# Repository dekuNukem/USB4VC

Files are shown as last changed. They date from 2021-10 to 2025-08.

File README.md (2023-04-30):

# USB4VC: USB Inputs on Retro Computers!

[Get USB4VC!](https://www.tindie.com/products/dekuNukem/usb4vc-usb-inputs-on-retro-computers/) | [Official Discord](https://discord.gg/HAuuh3pAmB) | [Getting Started](getting_started.md) | [Table of Contents](#table-of-contents)

-----

USB4VC is an **active protocol converter** that let you use **USB keyboard, mouse, and gamepads** on many different retro computers.



With a **modular design**, different platforms are supported by swapping out **Protocol Cards**:



USB4VC is [now available on Tindie](https://www.tindie.com/products/dekuNukem/usb4vc-usb-inputs-on-retro-computers/), with two Protocol Cards:

#### IBM PC Compatible

* PS/2 Keyboard (Scancode set 1, 2 and 3)
* PS/2 Mouse
* AT Keyboard
* XT Keyboard
* Microsoft Serial Mouse
* Mouse Systems Serial Mouse
* 15-pin Gameport Gamepad
* Mapping USB Gamepad to PC Mouse/Keyboard

From the very first IBM PC in 1981 until the end of PS/2 ports in early 2000s, this Protocol Card covers it all!

#### Apple Lisa, Early Macintosh, and Apple Desktop Bus (ADB)

* Apple Lisa Keyboard (A6MB101)
* Apple Lisa Mouse (A9M0050)
* Macintosh Keyboard (M0110A)
* Macintosh Mouse (M0100)
* ADB Keyboard
* ADB Mouse
* Mapping USB gamepad to all above

From Apple Lisa in 1983 to PowerMac G3 in 1999, and everything in-between!

#### More to Come!

Of course, more Protocol Cards are planned, and you can try [make your own](technical_notes.md) too!

## I Want One! / Get in Touch

USB4VC is now available [on my Tindie store](https://www.tindie.com/products/dekuNukem/usb4vc-usb-inputs-on-retro-computers/) after being successfully funded [on Kickstarter!](https://www.kickstarter.com/projects/dekunukem/usb4vc-usb-inputs-on-retro-computers)!

**Questions or comments?** Ask in [official Discord](https://discord.gg/HAuuh3pAmB), raise a [Github issue](https://github.com/dekuNukem/USB4VC/issues), [Twitter DM](https://twitter.com/dekuNukem_), or email `dekunukem` `gmail.com`!

## Videos

* [LGR Review](https://www.youtube.com/watch?v=tbHr7ULpusM)

* [Michael MJD Review](https://www.youtube.com/watch?v=Hv4A9p7Cn2s)

* [1Bit Fever Dreams review of Lisa/Mac/ADB card](https://youtu.be/ALm5LWS0fqU)

## Highlights

* USB Keyboard/Mouse/Gamepads on Vintage Computers!

* Modular & Swappable Protocol Cards

* Wireless / Bluetooth

* Ultra Low Latency (0.5ms)

* Fully Open-source

* Make-your-own Protocol Card [Instruction Provided](technical_notes.md)

## How it Works

USB4VC consists of two halves: **Baseboard** and swappable **Protocol Cards**.

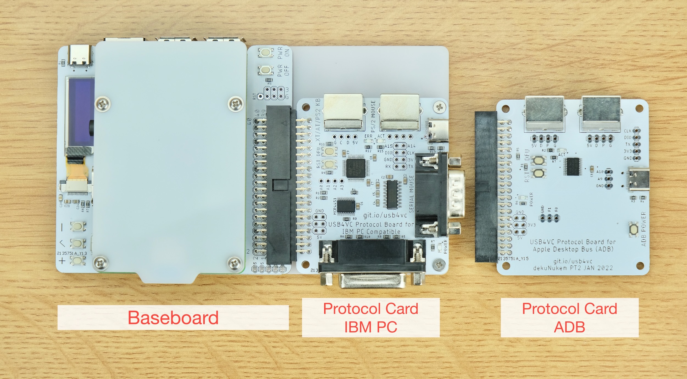
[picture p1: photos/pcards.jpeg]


Baseboard contains user buttons, OLED screen, and a Raspberry Pi. It processes USB input events, which are sent to Protocol Card.

Each Protocol Card has a dedicated microcontroller and connectors for a specific platform.

By splitting duties, RPi can focus on input parsing, and Protocol Card handles timing critical signal generation, resulting in a flexible architecture and reliable performance.

USB peripherals can be connected via cables, wireless dongles, or Bluetooth.

## Getting Started

[Click me](getting_started.md)

## Technical Details / Make Your Own Protocol Cards

[Click me](technical_notes.md)

## Why / Project Goals

Before the homogeneity of USB peripherals today, computer input devices were a wild west of proprietary peripherals, as different platforms used their own connectors and protocols for keyboards, mice, and gamepads.

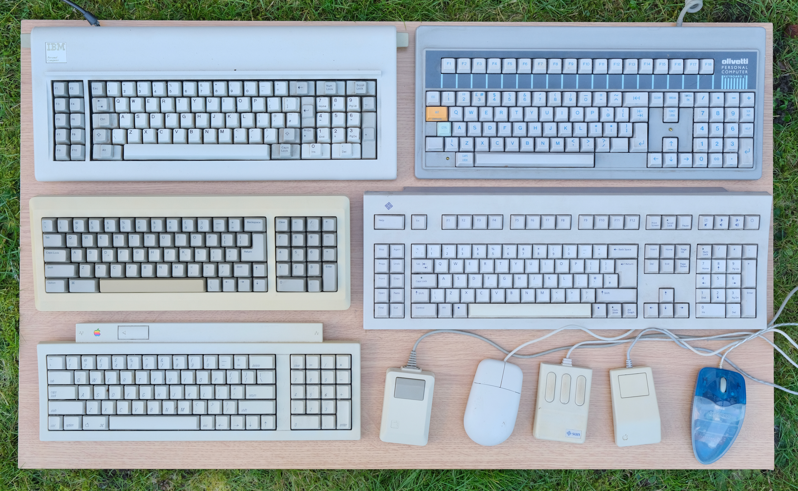
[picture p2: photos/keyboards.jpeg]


With the popularity of retro computing today, it poses several issues:

* Many of those peripherals are simply **hard to find**, commanding a premium on online marketplaces. They are only getting rarer, and without them, the computer itself is useless.

* After decades of service, many can be **degraded and unreliable** (e.g. foam & foil keyboards), requiring extensive restoration.

* Many early peripherals simply **does not feel that great**. Mushy membrane keyboards, sticky ball mice, plasticky gamepads, etc. And of course, the good ones gets [*very expensive*](https://www.ebay.com/sch/i.html?_nkw=ibm+model+f&_sacat=0&rt=nc&LH_Sold=1&LH_Complete=1).

* On the other hand, good quality USB peripherals can be had for a very reasonable price today with vastly **superior tactility, precision, and ergonomics**.

* Thus, this project aims to make retro computers simply **more enjoyable to use**.

* I also hope it can **lower the barrier of entry** for certain machines, put more computers **back in action**, help **preserving** existing peripherals, and generally **help more people** get into this hobby!

But of course, one can argue that using period-correct peripherals is simply part of the hobby, but just like HDMI upscalers or floppy emus, it's nice to have the option to enhance the experience.

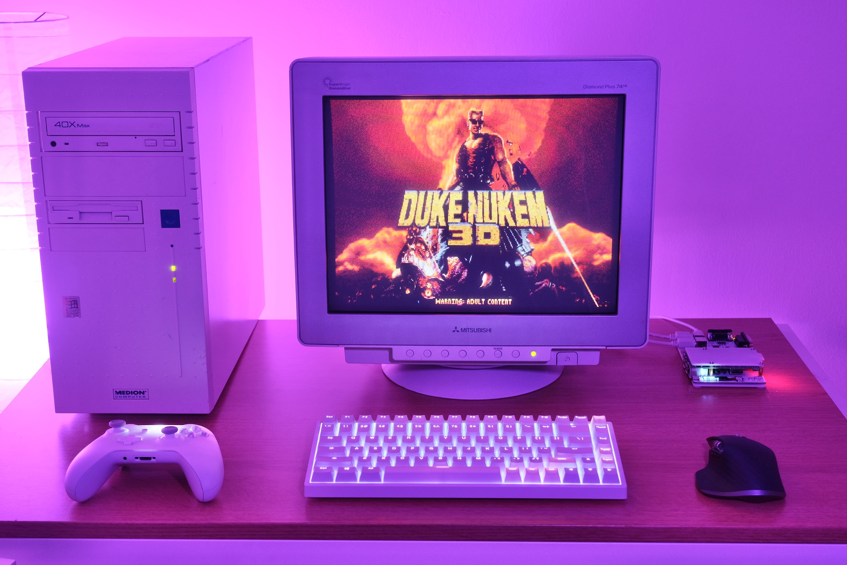
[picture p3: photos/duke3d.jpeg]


## Q&A

### Where can I get one?

This project have been successly funded [via Kickstarter!](https://www.kickstarter.com/projects/dekunukem/usb4vc-usb-inputs-on-retro-computers), now it is available [on my Tindie store!](https://www.tindie.com/products/dekuNukem/usb4vc-usb-inputs-on-retro-computers/)

### Which Raspberry Pi can I use?

Any RPi with a **40-pin header** *should* work, although **Model B/B+** is preferred. See [this table](https://en.wikipedia.org/wiki/Raspberry_Pi#Model_comparison) for details, sort by **GPIO** column.

USB4VC has been officially tested on **Raspberry Pi 2/3/4 Model B**.

Raspberry Pi Zeros should work too, but would need a USB hub.

No need to get the latest and greatest. An older RPi is plenty fast enough!

### What about latency?

0.5ms to 1ms depending on the Raspberry Pi generation.

1ms is *one thousandth* of a second. [More info here](technical_notes.md#latency-information).

### Can you develop a Protocol Card for ___ ?

I'd love to! But I would need a working machine with working peripherals.

So if you're in UK and is happy to lend me one for a while, [let me know!](#i-want-one--get-in-touch)

Also, as I can only work on so many at once, I'll probably focus on the more popular machines at first, but still, do let me know!

### Can I make my own Protocol Cards?

Of course! See [this document](technical_notes.md).

### What does USB4VC stand for?

USB for Vintage Computers. Although come to think of it, it's perfect for vintage consoles too! 🤔

## Questions or Comments?

Feel free to ask in official [Discord Chatroom](https://discord.gg/HAuuh3pAmB), raise a [Github issue](https://github.com/dekuNukem/USB4VC/issues), [DM on Twitter](https://twitter.com/dekuNukem_), or email `dekunukem` `gmail.com`!

## Table of Contents

[Main page](README.md)

[(Youtube Video) USB4VC in Action](https://www.youtube.com/watch?v=54sdPELuu4g)

[Getting Started Guide](getting_started.md)

[Kit Assembly Guide](kit_assembly.md)

[Tinkering Guide / Make Your Own Protocol Card / Technical Notes](technical_notes.md)

[Kickstarter Acknowledgements](kickstarter_info.md)

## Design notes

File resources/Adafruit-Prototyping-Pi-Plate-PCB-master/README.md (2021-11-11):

# Adafruit Prototyping Pi Plate

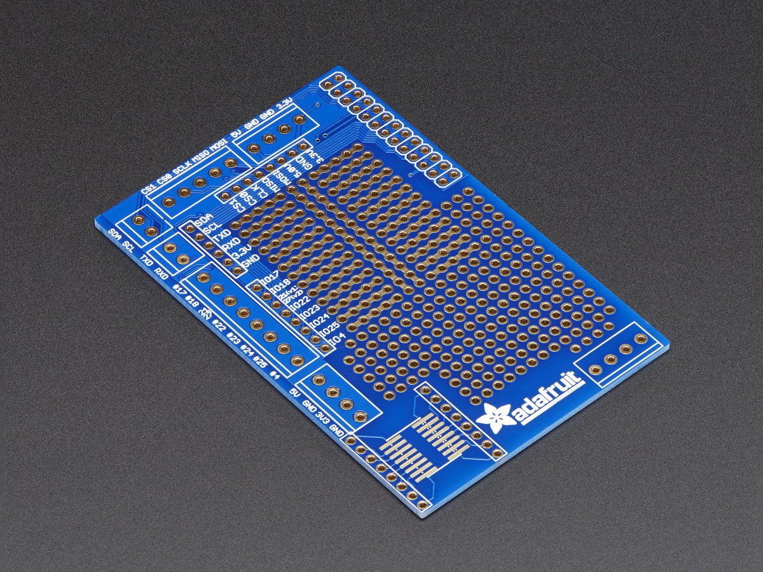
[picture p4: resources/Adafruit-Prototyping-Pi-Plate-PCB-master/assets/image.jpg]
<a href="http://www.adafruit.com/products/801"><br/>Click here to purchase one from the Adafruit shop</a>

These are the Eagle CAD files for the Adafruit Prototyping Pi Plate.

Now that you've finally got your hands on a [Raspberry Pi®](http://www.raspberrypi.org/) , you're probably itching to make some fun embedded computer projects with it. What you need is an add on prototyping Pi Plate from Adafruit, which can snap onto the Pi PCB (and is removable later if you wish) and gives you all sorts of prototyping goodness to make building on top of the Pi super easy.

__Note: This kit is best used for the Raspberry Pi Model A or Model B.__ You can use it with any "2x20 GPIO type" Pi  (A+, B+, Zero, Pi 2, Pi 3) but only the 'top 26 pins' will be broken out for use

We added lots of basic but essential goodies. First up, there's a big prototyping area, half of which is 'breadboard' style and half of which is 'perfboard' style so you can wire up DIP chips, sensors, and the like. Along the edges of the proto area, all the GPIO/I2C/SPI and power pins are broken out to 0.1" stips so you can easily connect to them. On the edges of the prototyping area, (almost all of) the breakout pins are also connected to labeled 3.5mm screw-terminal blocks. This makes it easy to semi-permanently wire in sensors, LEDs, etc. There's also a 4-block terminal block broken out to 0.1" pads for general non-GPIO wiring. Finally, we had a little space remaining over the metal connectors so we put in an SOIC surface mount chip breakout area, for those chips that dont come in DIP format.

__This kit comes as a set of parts, a little soldering is required to put it together but its really easy, even a beginner can do it in 15-20 minutes or so.__ The Pi (and our kits) are meant to help us all learn skills, soldering is fun! [Check out our tutorial for how to assemble](http://learn.adafruit.com/adafruit-prototyping-pi-plate).

The nice thing about this plate is we're getting custom header breakouts that are taller than usual, so that the proto plate sits above the metal connectors, out of the way and allows for plenty of workspace. It fits in our Pi Box enclosure with access to the terminal blocks so you can keep the Pi safe while prototyping. We'll have stackable header kits as well for those who want to put multiple plates on top.

For more information, including some usage ideas [check out our Proto Pi Plate tutorial](http://learn.adafruit.com/adafruit-prototyping-pi-plate).

Note: The terminal blocks included with your product may be blue or black.

### License

Adafruit invests time and resources providing this open source design, please support Adafruit and open-source hardware by purchasing products from Adafruit!

Designed by Limor Fried/Ladyada for Adafruit Industries.
CERN OPEN HARDWARE LICENSE v1.1 
http://www.ohwr.org/

All text above must be included in any redistribution

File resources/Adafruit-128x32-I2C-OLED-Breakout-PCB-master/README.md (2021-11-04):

# PCB for the Adafruit 128x32 I2C OLED breakout board

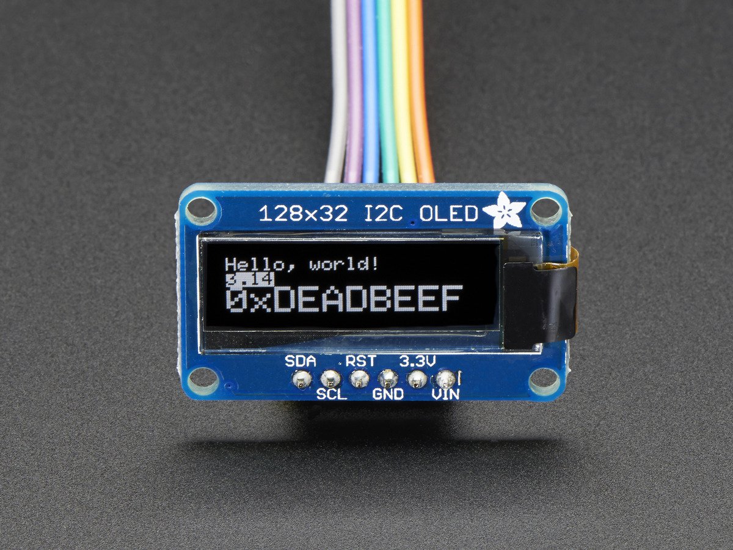
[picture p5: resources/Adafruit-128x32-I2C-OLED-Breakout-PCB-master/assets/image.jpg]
<a href="http://www.adafruit.com/products/931"><br/>Click here to purchase one from the Adafruit shop</a>

__Format is EagleCAD schematic and board layout__

These displays are small, only about 1" diagonal, but very readable due to the high contrast of an OLED display. This display is made of 128x32 individual white OLED pixels, each one is turned on or off by the controller chip. Because the display makes its own light, no backlight is required. This reduces the power required to run the OLED and is why the display has such high contrast; we really like this miniature display for its crispness!

The driver chip SSD1306, __communicates via I2C only.__ 3 pins are required to communicate with the chip in the OLED display, two of which are I2C data/clock pins.

The OLED and driver require a 3.3V power supply and 3.3V logic levels for communication. To make it easier for our customers to use, we've added a 3.3v regulator and level shifter on board! This makes it compatible with any 5V microcontroller, such as the Arduino.

The power requirements depend a little on how much of the display is lit but on average the display uses about 20mA from the 3.3V supply. Built into the OLED driver is a simple switch-cap charge pump that turns 3.3v-5v into a high voltage drive for the OLEDs, making it one of the easiest ways to get an OLED into your project!

Of course, we wouldn't leave you with a datasheet and a "good luck": [We have a detailed tutorial](http://learn.adafruit.com/monochrome-oled-breakouts) and [example code in the form of an Arduino library](https://github.com/adafruit/Adafruit_SSD1306) for text and graphics. You'll need a microcontroller with more than 512 bytes of RAM since the display must be buffered.

You can download our SSD1306 OLED display Arduino library from github which comes with example code. The library can print text, bitmaps, pixels, rectangles, circles and lines. It uses 512 bytes of RAM since it needs to buffer the entire display but its very fast! The code is simple to adapt to any other microcontroller.

## License
Adafruit invests time and resources providing this open source design,
please support Adafruit and open-source hardware by purchasing
products from Adafruit!

Designed by Limor Fried/Ladyada for Adafruit Industries.
Creative Commons Attribution, Share-Alike license, check license.txt for more information
All text above must be included in any redistribution

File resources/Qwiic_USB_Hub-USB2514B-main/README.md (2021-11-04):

SparkFun Qwiic USB Hub - USB2514B
========================================

SparkX USB Hub - USB2514B (Qwiic) (https://www.sparkfun.com/products/18014)

[*SparkX USB Hub - USB2514B (Qwiic) (SPX-18014)*](https://www.sparkfun.com/products/18014)

There are times when you have multiple USB devices in your prototype or device and you just want to plug in one cable. You need a built in USB hub! 

The [Qwiic USB Hub](https://www.sparkfun.com/products/18014) is a simple breakout board for the USB2514B USB hub IC. What gives it extra flair is the ability to configure the device over I2C. Out of the box, the board will appear as a standard USB 2.0 Hub; no configuration necessary. Closing the I2C jumper will put the device into configuration mode. We've got an Arduino Library to help you set the various parameters of the hub including VID/PID, downstream max current, even language ID and product names. 

Note: Once the configuration bytes are set and the USB2514B is told to 'attach' it will enumerate as a HUB and the configuration cannot be changed until the IC is reset. 

The USB2514 is a 4-port 2.0 USB hub. Who cares about USB 2.0 these days? The vast majority of projects we work on have a simple USB-to-Serial IC on it that do not require gigabit datarates. The USB251xB is a simple hub IC allowing multiple USB things to live under one USB connection; this is especially useful when prototyping a new product where you want the user to plug in just one cable.

SparkFun labored with love to create this code. Feel like supporting open source hardware? 
Buy a [board](https://www.sparkfun.com/products/18014) from SparkFun!

Repository Contents
-------------------

* **/hardware** - Eagle files
* **/documents** - Datasheets and other source documents

Documentation
--------------

* **[Arduino Library](https://github.com/sparkfun/SparkFun_USB251x_Arduino_Library)** - Main repository (including hardware files)
* **[Installing an Arduino Library Guide](https://learn.sparkfun.com/tutorials/installing-an-arduino-library)** - Basic information on how to install an Arduino library.

Products that use this Repository
--------------

* [SPX-18014](https://www.sparkfun.com/products/18014)

License Information
-------------------

This product is _**open source**_! 

Please review the LICENSE.md file for license information. 

If you have any questions or concerns on licensing, please contact technical support on our [SparkFun forums](https://forum.sparkfun.com/viewforum.php?f=152).

Distributed as-is; no warranty is given.

- Your friends at SparkFun.

_<COLLABORATION CREDIT>_

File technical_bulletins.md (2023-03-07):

# USB4VC Protocol Card Stability Upgrade

[Get USB4VC](https://www.tindie.com/products/dekuNukem/usb4vc-usb-inputs-on-retro-computers/) | [Official Discord](https://discord.gg/HAuuh3pAmB) | [Getting Started](getting_started.md) | [Table of Contents](#table-of-contents)

-----

This document covers a solution that might improve the stability of USB4VC.

## Overview

A `BUSY` signal is added, to prevent Raspberry Pi from sending data when Protocol Card is talking to the computer.

This, along with a firmware update, should improve stability and reduce stuck keys or glitches.

## Instructions

### Solder a New Wire

Solder a wire between the pins at **`F1` and `second row of right most column`**. See photo:

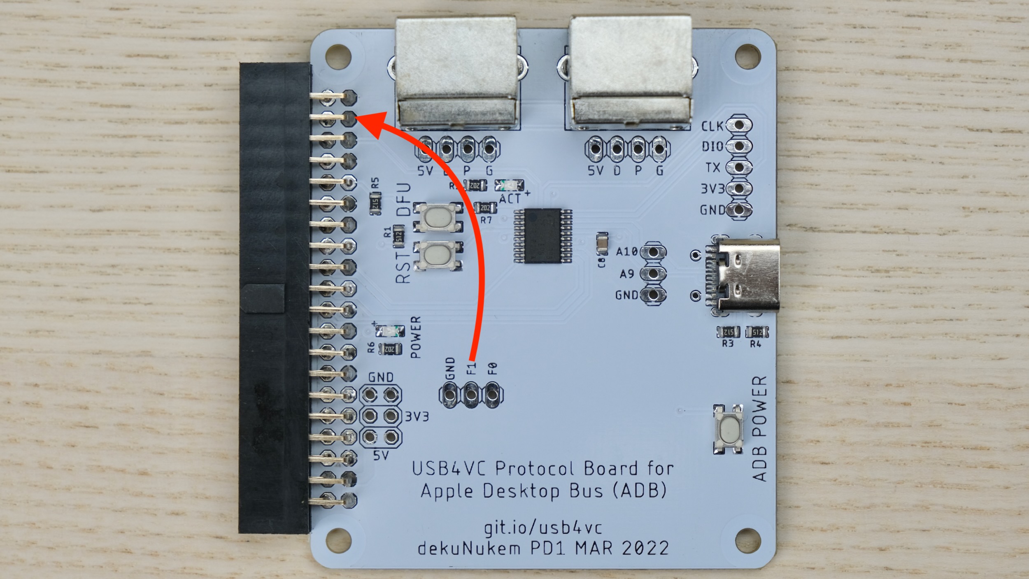
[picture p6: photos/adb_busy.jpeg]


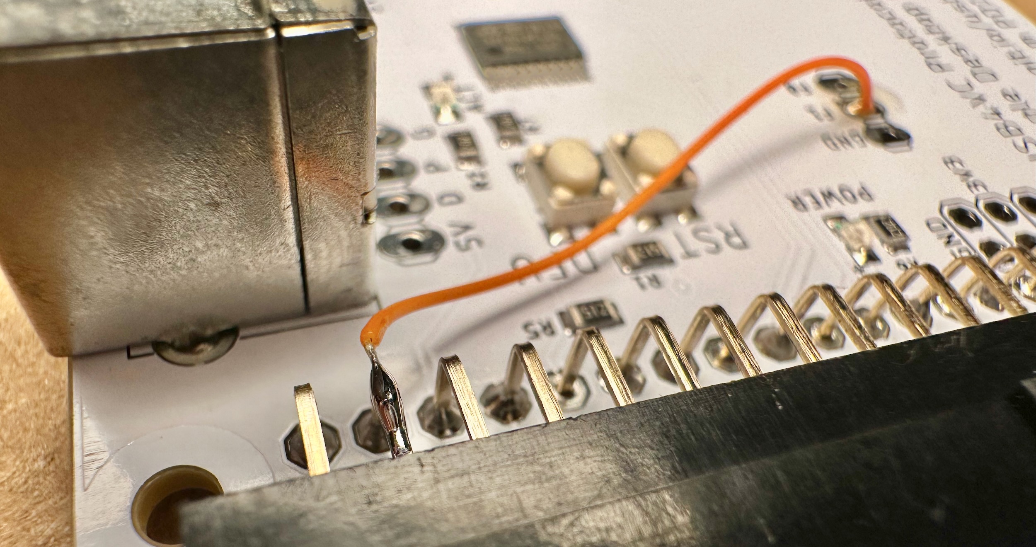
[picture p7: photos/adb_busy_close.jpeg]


Make sure **there are no short circuits**.

### Software Update

Connect RPi to internet. You can [set up WiFi](https://github.com/dekuNukem/USB4VC/blob/master/getting_started.md#optional-set-up-wifi), or plug in an Ethernet cable.

Then simply select Internet Update in main menu. It will update RPi code and P-Card firmware to latest version.

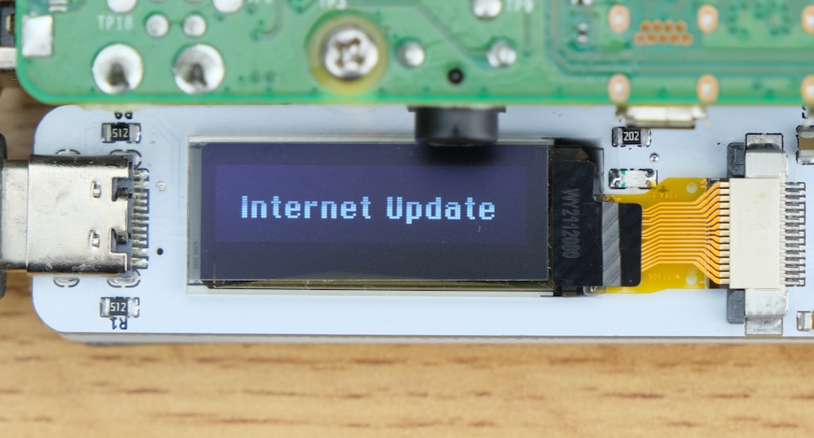
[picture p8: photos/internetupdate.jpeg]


Confirm on the second screen that both PB and RPi version are **above 0.3.0**.

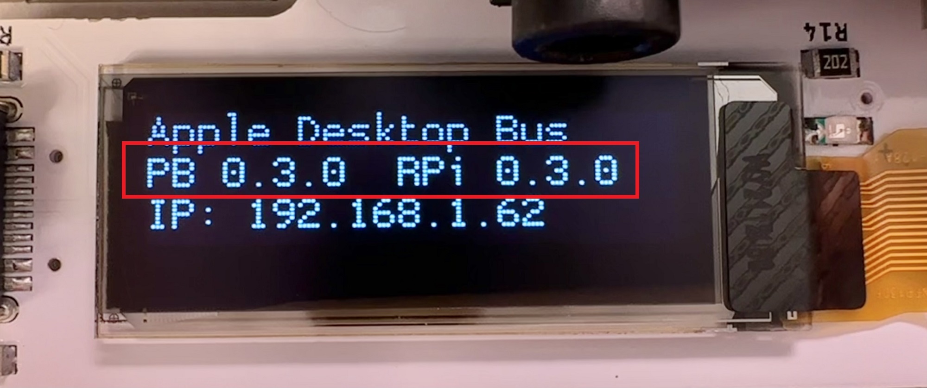
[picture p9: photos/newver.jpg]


### Try it Out!

Let me know how it goes!

## Questions or Comments?

Feel free to ask in official [Discord Chatroom](https://discord.gg/HAuuh3pAmB), raise a [Github issue](https://github.com/dekuNukem/USB4VC/issues), [DM on Twitter](https://twitter.com/dekuNukem_), or email `dekunukem` `gmail.com`!

## Table of Contents

[Main page](README.md)

[(Youtube Video) USB4VC in Action](https://www.youtube.com/watch?v=54sdPELuu4g)

[Getting Started Guide](getting_started.md)

[Kit Assembly Guide](kit_assembly.md)

[Tinkering Guide / Make Your Own Protocol Card / Technical Notes](technical_notes.md)

[Kickstarter Acknowledgements](kickstarter_info.md)

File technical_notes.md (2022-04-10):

# USB4VC Technical Notes / Make Your Own Protocol Card / Tinkering Guide

[Get USB4VC](https://www.tindie.com/products/dekuNukem/usb4vc-usb-inputs-on-retro-computers/) | [Official Discord](https://discord.gg/HAuuh3pAmB) | [Getting Started](getting_started.md) | [Table of Contents](#table-of-contents)

-----

This document contains technical information about how USB4VC works. Please **read the whole article** if you're planning to make your own Protocol Cards.

## Tinkering Guide

Working on USB4VC is very straightforward. It's just some python scripts running on official RaspberryPi OS Lite.

To SSH into it, [set up WiFi](getting_started.md#optional-set-up-wifi) or plug in an Ethernet cable. The IP address should show up on the second page of main menu:

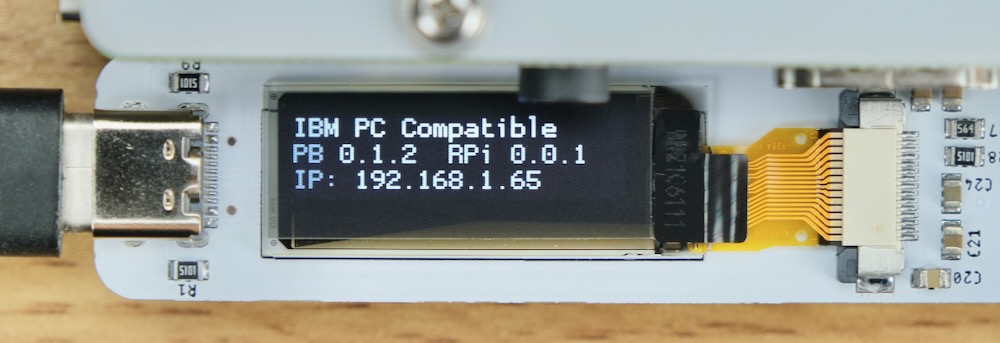
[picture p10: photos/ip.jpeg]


Simply do (change the IP to your own) `ssh pi@192.168.1.65`.

Username and password is `pi` and `usb4vc`, all lower case. 

All files are inside `~/usb4vc`.

## Linux Input Event Codes

Now, how does USB4VC read from USB inputs in the first place?

The answer is Linux **Input Event Codes**. Here's a very simplified description:

* Input devices show up in `/dev/input` as files:

```
$ ls /dev/input/
event0  event1  event2  mice  mouse0  mouse1
```

* Reading from one of those files returns input events. Try `cat /dev/input/mice`!

* On RPi, **16 Bytes** are returned each time there is an event. They are arranged as follows:

| Byte  | Name |
|---|---|
| 0-7 | Timestamp |
| 8-9 | Event Type  |
| 10-11 | Event Code  |
| 12-15 | Event Value |

* A list of all Event Type, Code and Values [can be found here](https://github.com/torvalds/linux/blob/master/include/uapi/linux/input-event-codes.h), set a bookmark if you're making your own P-Card!

* Keyboard keys and mouse/gamepad buttons are **EV_KEY** type, mouse movements are **EV_REL** (relative) type, and joystick movements are **EV_ABS** (absolute) type.

* Once you know the Event Type, you can look up Event Code to see which key/button/axes is being updated.

* Event Value will be 1 (pressed) or 0 (released) for buttons, and a signed value for relative or absolute axes.

* [Here's a good article](https://thehackerdiary.wordpress.com/2017/04/21/exploring-devinput-1/) that goes into a bit more details.

* USB4VC reads those events from all input devices, processes them, and send them out to the Protocol Card.

* To see it in action, you can select `Show Event Codes` from the main menu:

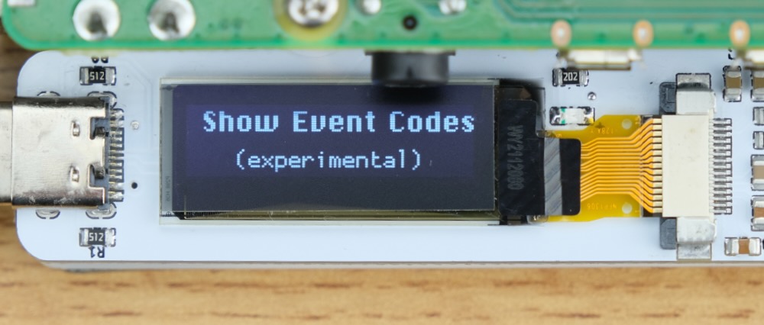
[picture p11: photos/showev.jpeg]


* It will show a summary of latest input events, including device name, USB vendor and product ID, and event code name and value.

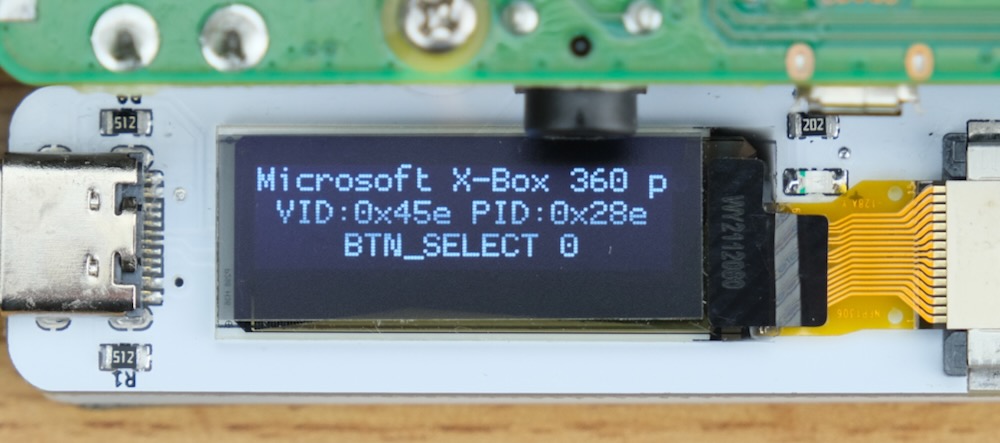
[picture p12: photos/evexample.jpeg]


* To exit, **HOLD DOWN** `+` button during an input event.

* You can also `ssh` into it and use `evtest` to see more detailed reports.

## Hardware Pinout

The Protocol Card connector directly maps to the Raspberry Pi Header, although the pins are flipped around.

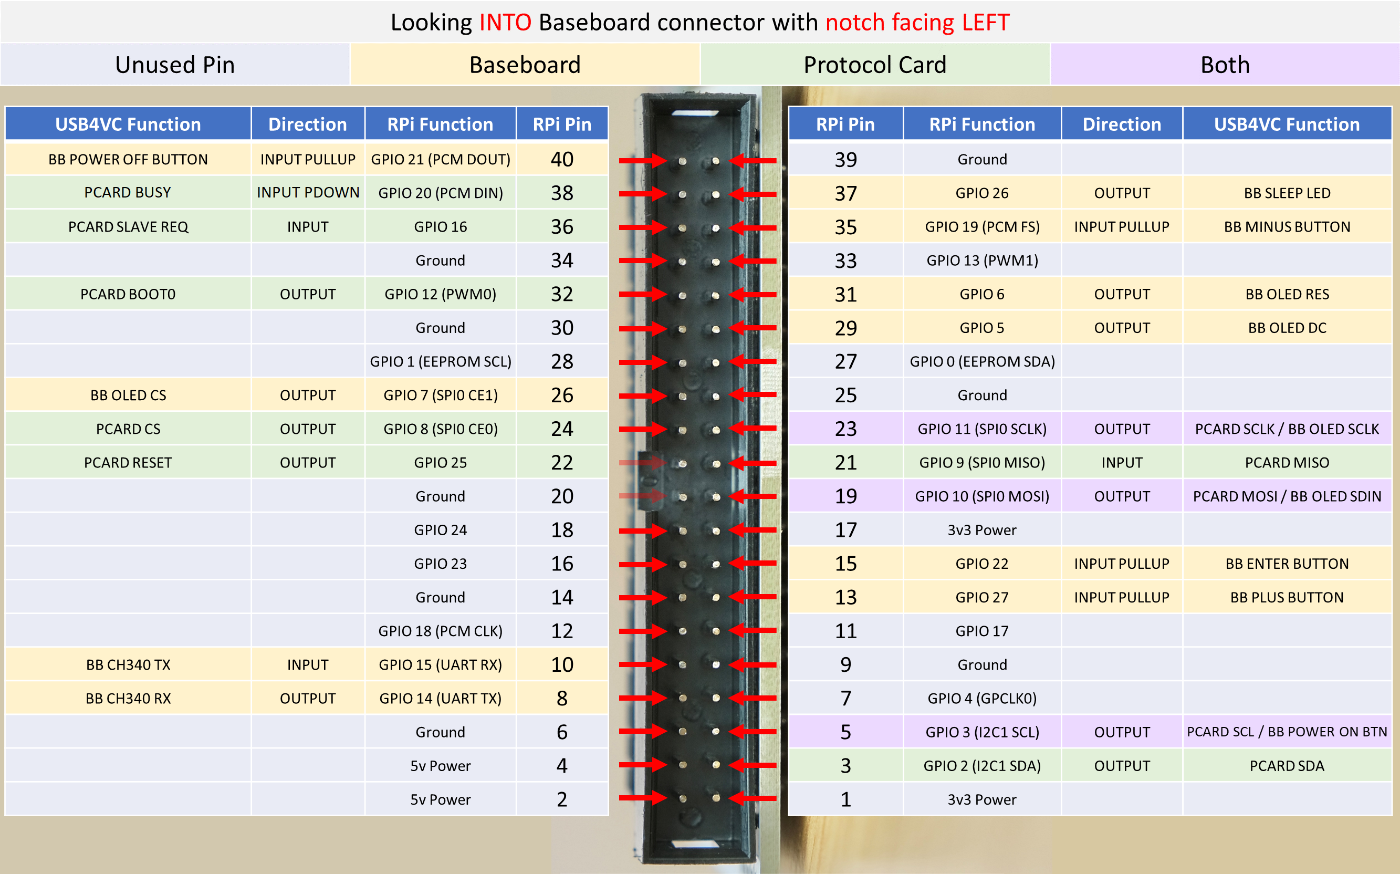
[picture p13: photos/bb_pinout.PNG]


* Protocol Card and OLED screen shares the same SPI bus, with different CS of course.

* Pin 22 is used to reset the P-Card, pin 32 for putting the microcontroller in bootloader mode for firmware updates.

* Pin 3 and 5 are connected to microcontroller I2C lines for firmware updates.

* A CH340 TTL-Serial-to-USB chip converts RPi serial (Pin 8 and 10) to USB-C on the Baseboard, currently unused.

* Pin 36 is PCard-to-Baseboard interrupt pin, details in next section.

* 5V current should not exceed 2A.

* 3.3V current should not exceed 600mA.

## SPI Communication Protocol

Raspberri Pi communicates with Protocol Card through SPI. [Here's a quick introduction](https://www.circuitbasics.com/basics-of-the-spi-communication-protocol/) if you're unfamiliar.

RPi is master, P-card is slave. **SCLK is 2MHz**.

**Mode 0** is used. CPOL=0 (CLK idle low), CPHA=0 (data valid on CLK rising edge).

RPi and P-Card communicates via **fixed-length 32-byte packets**.

Detailed description of messaging protocol [can be found in this document](https://docs.google.com/spreadsheets/d/e/2PACX-1vTDylIwis3GZrhakGK0uXJGc_SAZ_QwySmlMfZXpSdFDH6zoIXs1kHX7-4wUTeShZth_n6tJH8l3dJ3/pubhtml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), note that there are **multiple pages**.

Here is a sample capture of pressing `U` on the keyboard:

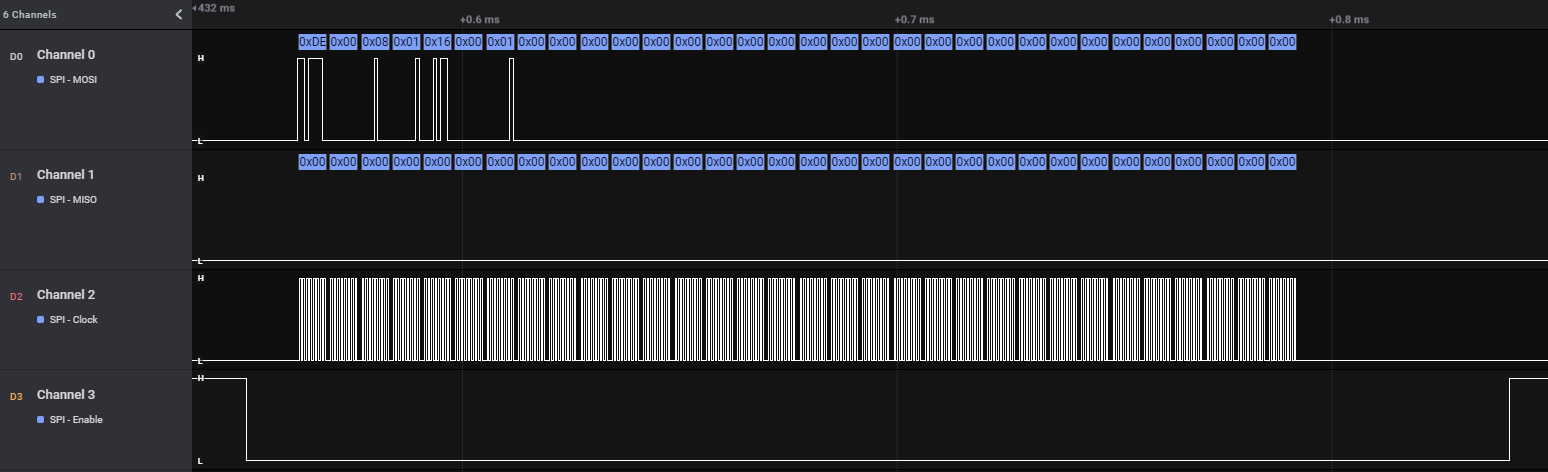
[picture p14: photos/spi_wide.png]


* 32 Bytes are sent in a single CS activation.

* SCLK is 2MHz, the entire transmission take around 290uS.

Here is a close-up of the first few bytes:

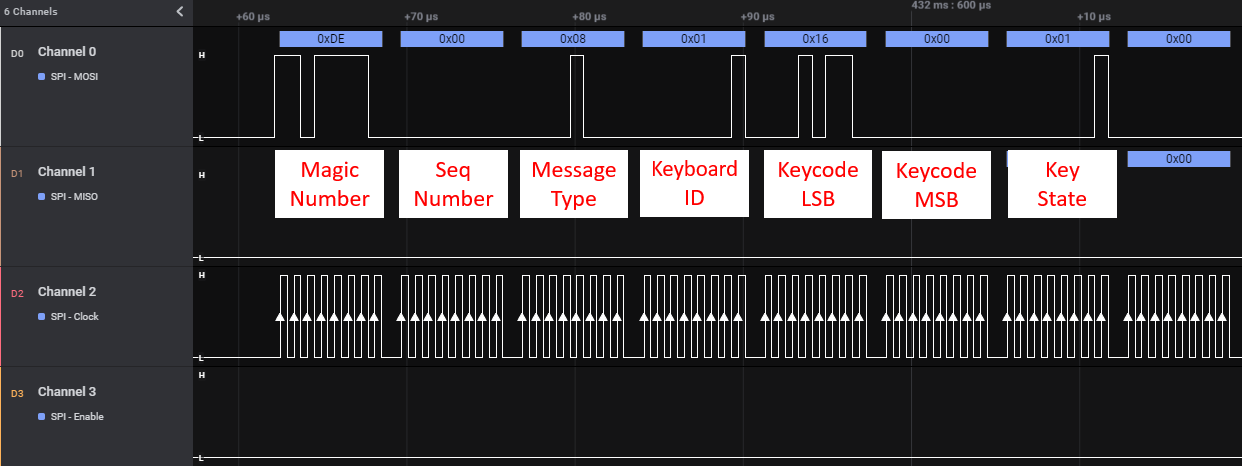
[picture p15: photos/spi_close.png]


Compare to the [keyboard tab in the document](https://docs.google.com/spreadsheets/d/e/2PACX-1vTDylIwis3GZrhakGK0uXJGc_SAZ_QwySmlMfZXpSdFDH6zoIXs1kHX7-4wUTeShZth_n6tJH8l3dJ3/pubhtml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):

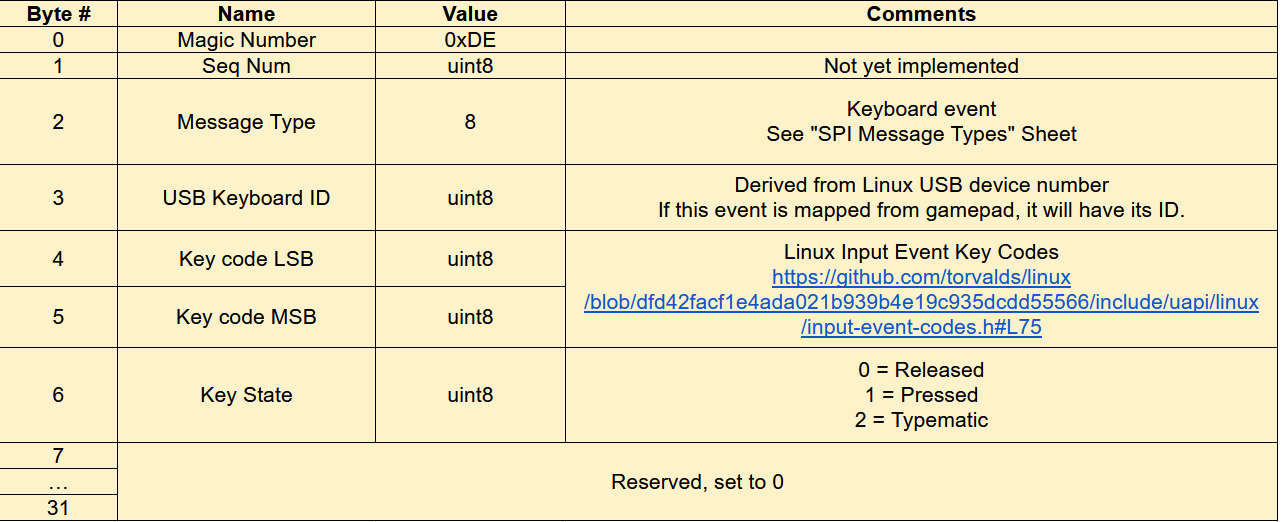
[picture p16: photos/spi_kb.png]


## P-Card Interrupt Handling

When Protocol Card has data for RPi, it should prepare the SPI buffer, and switch its interrupt pin to HIGH ([Pin 36](#hardware-pinout)).

Upon detecting this change, RPi will send out an ACK message. Upon receiving, the P-Card switches the interrupt pin to LOW.

RPi will then send out another ACK (or NOP) message to shift the data from P-Card to itself.

Here is a sample capture:

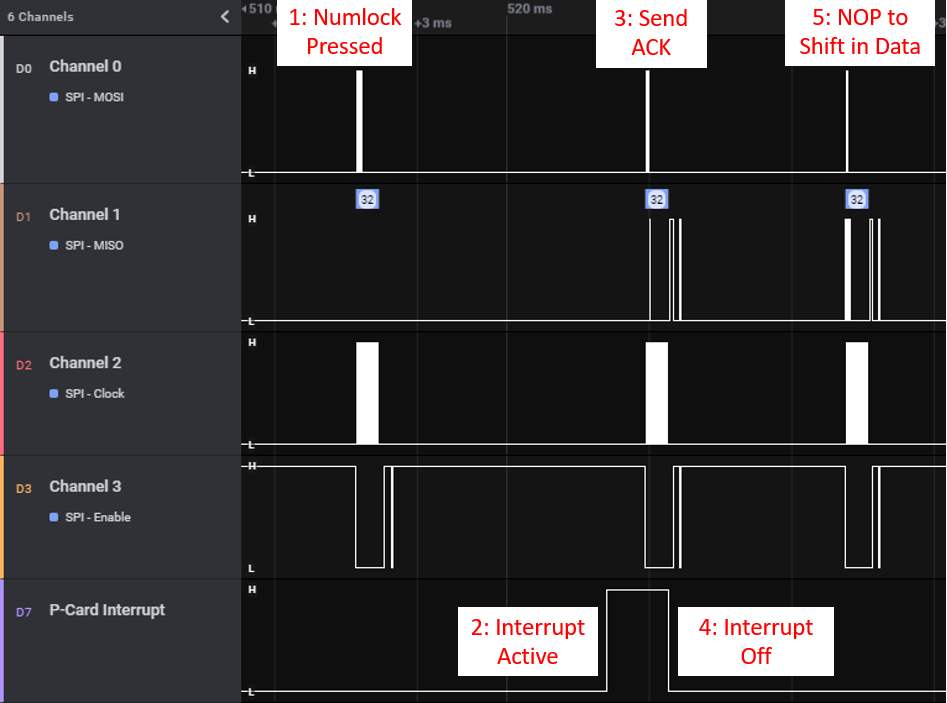
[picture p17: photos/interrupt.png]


Currently this feature is only used for changing keyboard LEDs.

## Sample SPI Message Captures

More **sample captures** [can be found here](https://github.com/dekuNukem/USB4VC/tree/master/captures/diy_samples).

Click one and press `Download`.

Open with [Saleae Logic app](https://www.saleae.com/downloads/).

## Latency Information

Input latency can be introduced during all stages of input chain. Using keyboard as example, we have:

* Step 1: Switch physically depressed

* Step 2: Keyboard sends out event on USB/Bluetooth

* Step 3: Raspberry Pi processes the event and informs Protocol Card

* Step 4: Protocol Card sends out the keystroke to retro computer

* Step 5: Retro computer responds to the keystroke.

The part we're interested in is **Step 3 and 4**, as any time spent here is the additional delay from USB4VC.

To accurately measure the delay, I used a logic analyzer connecting to keyboard USB lines and PS/2 output on the IBM PC Protocol Card. Here is the delay in action:

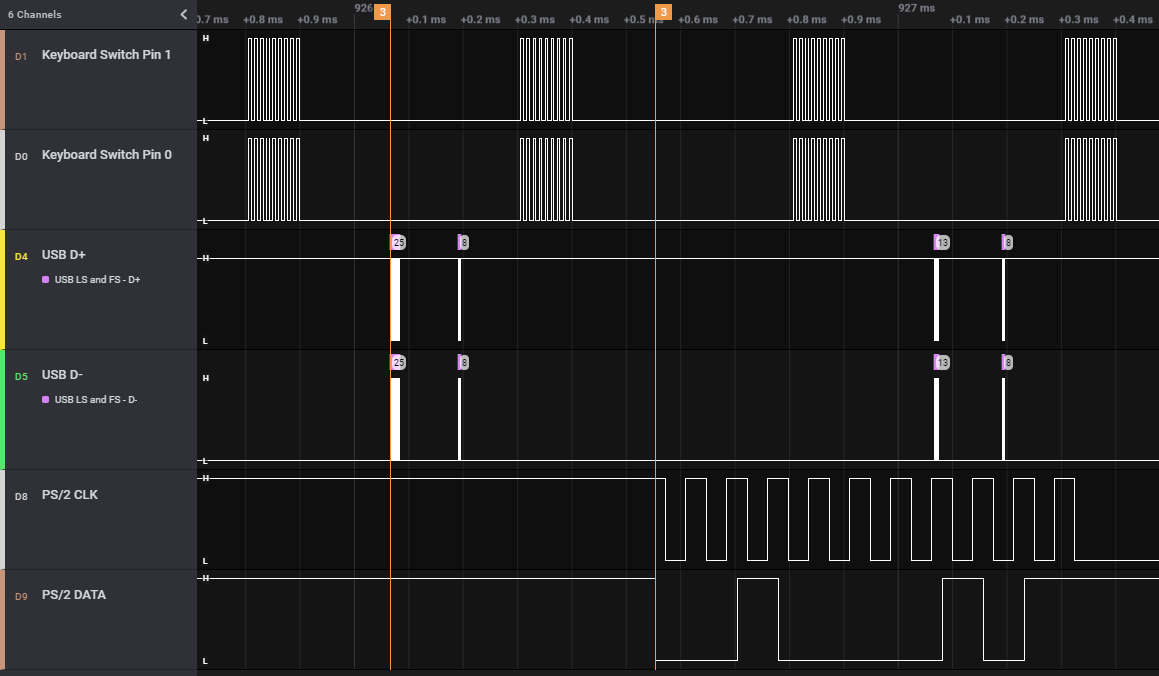
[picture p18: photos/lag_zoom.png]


From the keystroke appearing on USB, to keystroke appearing on PS/2, it took 487 *microseconds*.

Zoomed out capture with multiple keypresses:

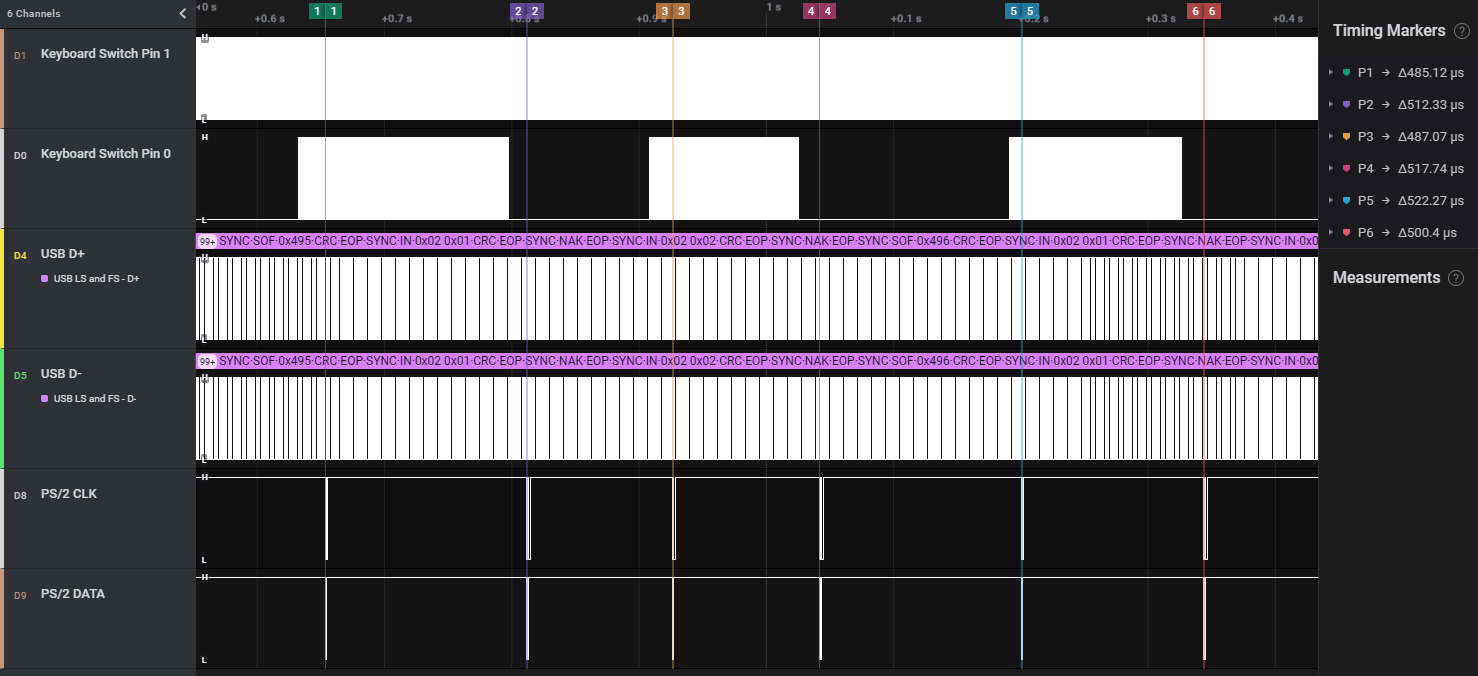
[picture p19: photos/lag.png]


I tested out different generations of Raspberry Pis, and here is the result:

| RPi Generation | Avg. Latency |
|---|---|
| 2 | 1ms |
| 3 | 0.63ms  |
| 4 | 0.5ms |

You can find the [capture files here](captures/latency), open with [saleae app](https://www.saleae.com/downloads/), search `PID ACK` for USB input events, more info [in this video](https://www.youtube.com/watch?v=wdgULBpRoXk)

## Making your own Protocol Card

By now you should have a general idea of how USB4VC works on a hardware level. So here are more information on how to get started on making your own Protocol Card!

### Any Restrictions?

Not really! USB4VC is under MIT license, so basically anything goes apart from liability and warranty.

Feel free to develop your own Protocol Cards, write about them, sell them, anything you want really.

[Do let me know](https://github.com/dekuNukem/USB4VC/blob/master/technical_notes.md#questions-or-comments) if you make one though! I'd be interested in checking it out!

### Recommended Equipment

* A **Logic Analyzer** is strongly recommended. You can use it to capture and decode digital signals, making troubleshooting much easier.

* I use a [Saleae Logic Pro 16](https://www.saleae.com/), it's a bit pricey but works very well. There are also cheaper ones available at the usual online marketplaces.

* An oscilloscope would work too, but the user interface might be more convoluted.

### Microcontroller Selection

The heart of a Protocol Card is the microcontroller. Picking one requires some considerations:

* It has to be **fast enough** to reliably read the 32-byte message at 2MHz SCLK **as SPI slave**, **AND** generate timing-critical signal to the retro computer.

* Able to tolerate 5V inputs, as is common for many retro computers.

* Economical and available for the quantity you're planning to make.

Here is a quick run-down of a few popular microcontrollers:

### Arduino, 8-bit ATmega-based. (UNO, Nano, Micro, Leonardo, etc)

#### PROs

* The obvious choice

* Lots of tutorials

* Cheap & available

* 5V tolerant

#### CONs

* Most runs at 16MHz, not sure if fast enough for 2MHz SPI signals.

* Not many resources on how to use them as SPI slaves. You might need to get cozy with configuration registers.

* Limited peripherals (timers, external interrupts, etc) and RAM and Flash memory.

* Overall just a bit underpowered, but I'm sure Atmel wizards can squeeze every bit of juice out of it :)

### ARM-Based Development Boards (Teensy, ESP32, RP2040, etc)

#### PROs

* Can be very fast (hundreds of MHz), and you can probably just brute force through any timing issues.

* Very popular too, so many resources are available.

#### CONs

* Can be expensive, especially for volume production.

* Might not be 5V tolerant

* Availability concerns

### Bare ARM Chip (STM32, NXP LPC, etc)

Finally, you can just program a bare 32-bit ARM microcontroller yourself.

#### PROs

* Complete control and flexibility in programming.

* Able to integrate into your own Protocol Card on a single PCB.

* Lowest cost, many parts to choose from at different price points and performance levels.

#### CONs

* Learning curve

* Not as many resources online

---

In conclusion, my suggestion would be:

* For **one-off designs**: A well-supported **high-powered ARM dev board** such as [Teensy](https://www.pjrc.com/store/). Lots of resources online to get you started, and the fast speed gives you more wiggle room for timing sensitive situations. 

* For **volume production**: Bare **ARM MCUs** such as STM32. Prototype with a cheap board such as [blue/black pill](https://hackaday.com/2021/01/20/blue-pill-vs-black-pill-transitioning-from-stm32f103-to-stm32f411/), and design your own circuit board.

* I have written a [tutorial on STM32 development](https://github.com/dekuNukem/STM32_tutorials), which should be helpful.

### Typical Development Steps

With your microcontroller chosen, here is how I would approach making a new Protocol Card:

#### Research the protocol!

First of all, look up the protocol and get as much details as you can!

* Can your MCU handle the **voltage level**? (5V/12V?)

* Does it involve a particular MCU peripheral? (UART, timers, external interrupts, etc)

* Does it need a **special driver**? (RS232, RS485?)

* How tight is the **timing**?

* Does the host poll at regular interval (ADB) or can you send an event at any time (PS/2)?

#### Reference waveform

If possible, use a logic analyzer or oscilloscope to **capture a sample waveform** with a **real retro peripheral**.

You might need to make a pass-through cable that exposes the signal lines.

No matter how good the documentation, nothing beats a reference capture from the real deal. This way you can verify the documentation is correct, and have something to compare to down the line.

#### SPI wire-up

Baseboard will send Keyboard/Mouse/Gamepad events over SPI even if nothing is connected, so no need to worry about that.

Take a look at the [pinout section](#hardware-pinout), connect your dev board to appropriate power, ground, and SPI pins.

SPI pins are 23, 21, 19, and 24. Also make sure everything is on the same ground.

#### Get SPI working

Use your logic analyzer or oscilloscope to confirm the SPI waveform is correct, and making sure the MCU can reliably receive SPI messages without data corruption and dropouts. See [SPI protocol section](#spi-communication-protocol) for details.

This is important as any SPI message corruption might result in missed inputs or wrong inputs being sent to retro computer.

Try start simple and sending single keyboard key strokes. Print the received message out, and compare with [this document](https://docs.google.com/spreadsheets/d/e/2PACX-1vTDylIwis3GZrhakGK0uXJGc_SAZ_QwySmlMfZXpSdFDH6zoIXs1kHX7-4wUTeShZth_n6tJH8l3dJ3/pubhtml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).

----

For ARM-based MCUs, you can usually receive messages as SPI slave in interrupt mode. Tell it you want 32 Bytes, and an interrupt callback will fire once the message has been received. [See my tutorial](https://github.com/dekuNukem/STM32_tutorials) for more information, see also the [code for existing P-Cards](https://github.com/dekuNukem/USB4VC/blob/master/firmware/ibmpc/Src/main.c).

For STM32, set up SPI as follows:

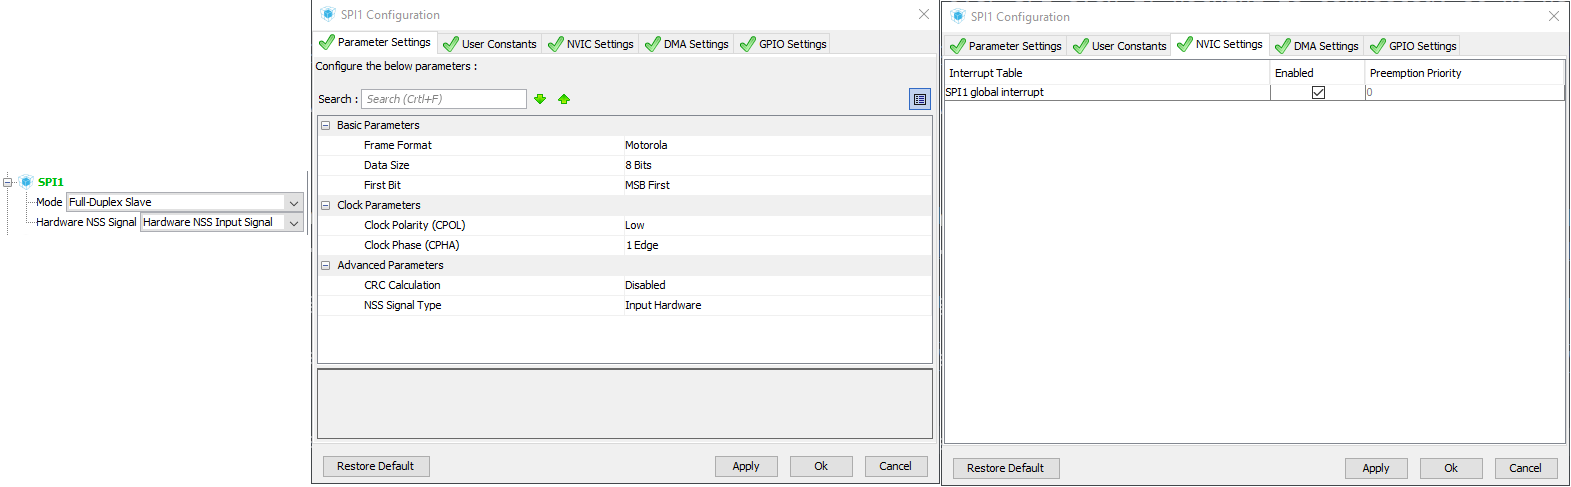
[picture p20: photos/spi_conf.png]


Then use `HAL_SPI_TransmitReceive_IT()` to start listening, and `HAL_SPI_TxRxCpltCallback()` will fire when message is received.

#### Work on protocols

Once SPI is working, you can move on to implementing the protocol itself. A few general tips:

* Popular protocols tends to have Arduino libraries already written, and you can modify/convert them to suit your needs. Double check the license though!

* Use the logic analyzer or oscilloscope to compare your output with the reference and make sure the timing is spot-on.

* Once working, try rapid inputs (mashing keyboard, moving mouse fast), simultaneous inputs (mashing keyboard/mouse/gamepad at same time) and see if any issue arises. And use it for a few hours to verify stability.

#### Tips and tricks

* If using interrupts to read SPI messages, keep the ISR short! 

* For example just copy everything into a buffer in ISR, and process it in the main loop.

* If designing your own PCB, you can refer to a lot of open-source vendors such as Sparkfun and Adafruit.

* Just find a relevant product and download the schematics and PCB files, they are often production tested, so a great starting point to make your own!

### Protocol Card PCB Design Notes

If you want to design a Protocol Card for volume production, here are some helpful information.

* Protocol Cards has the same dimension as a Raspberry Pi Model A:

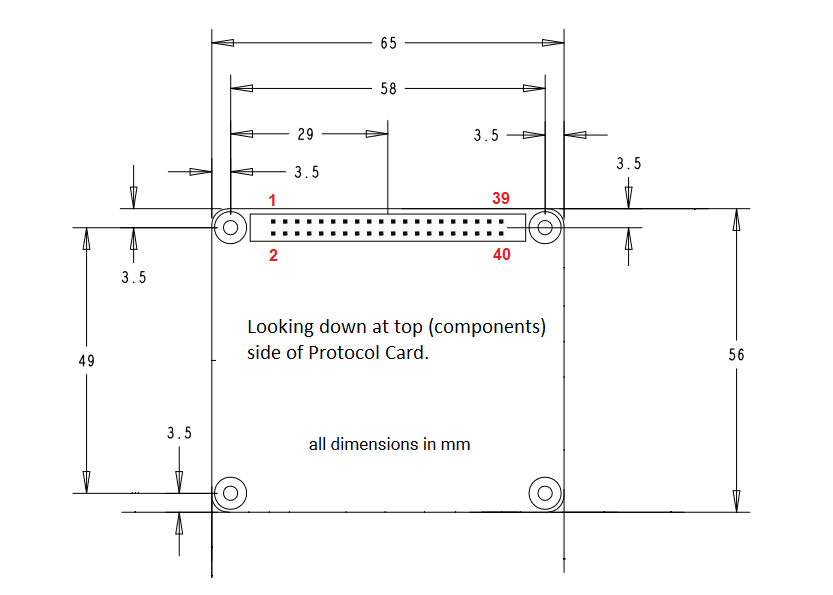
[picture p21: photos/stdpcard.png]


* Protocol Card pins are mapped to Raspberry Pi headers. See the red number for RPi pin number, and [click me for pinout details](#hardware-pinout).

* Connectors can come out from all 3 sides.

* Make sure to have a way for user to **update the firmware!** You can put a USB connector for manual updates, or hook up reset and DFU lines to do it from Raspberry Pi.

* No need to have a 5V to 3.3V regulator on the P-Card, it is provided by the Baseboard.

### Unique Protocol Card ID

Once your own P-Card has been tried and tested, it can be given a unique ID so the Baseboard can properly recognise it and display its protocol in the menus.

I'm still fleshing out how this will work, expect an update soon!

## Questions or Comments?

Feel free to ask in official [Discord Chatroom](https://discord.gg/HAuuh3pAmB), raise a [Github issue](https://github.com/dekuNukem/USB4VC/issues), [DM on Twitter](https://twitter.com/dekuNukem_), or email `dekunukem` `gmail.com`!

## Table of Contents

[Main page](README.md)

[(Youtube Video) USB4VC in Action](https://www.youtube.com/watch?v=54sdPELuu4g)

[Getting Started Guide](getting_started.md)

[Kit Assembly Guide](kit_assembly.md)

[Tinkering Guide / Make Your Own Protocol Card / Technical Notes](technical_notes.md)

[Kickstarter Acknowledgements](kickstarter_info.md)

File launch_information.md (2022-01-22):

## Launch Timeline

Current launch timeline is:

#### Feb - March 2022

* Public Beta Testing

* Gather Feedback, Fix Bugs, Finishing Touches.

#### March - April 2022

* Kickstarter

* Arrange Production Run

#### April 2022 Onwards

* Public Release

* Work on Improvements, More Protocols and Protocol Cards

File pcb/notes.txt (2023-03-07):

Protocol card checklist:

100 ohm resistor on power detect line
hook up BUSY signal
VDDA needs connection even if no analog is used

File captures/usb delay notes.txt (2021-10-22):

very useful video:
https://youtu.be/wdgULBpRoXk

search for PID ACK for data packet

from keypress to PID ACK on USB line: 10 to 20ms

catting /dev/input/event0 in bash: 490us
printing via python3: 1ms

script below:

fff = open("/dev/input/event0", "rb" )
while 1:
  data = fff.read(24)
  print(data)

using queue to despatch SPI on raspberry 3: 700 to 800us
on lichee 3.5ms 

hand parse raw dev/input: 470us on pi3, 1ms on lichee

32 byte fixed

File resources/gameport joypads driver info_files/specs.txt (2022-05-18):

  Intorduction
  ~~~~~~~~~~~~
  This file contains various interesting bits of information I have
  gathered in time, as a reference for writing the linux joystick driver.
  You may find it useful, or not ...

  Game port pinout
  ~~~~~~~~~~~~~~~~

		  .------------------------.
		  \ 8  7  6  5  4  3  2  1 /
		   \ 15 14 13 12 11 10  9 /
		     ~~~~~~~~~~~~~~~~~~~~

	  Pin	Function	Pin	Function
	   1	+5V (A0+A1)	 9	+5V (A2+A3)/MIDI
	   2	Button 0	10	Button 2
	   3	Axis 0		11	Axis 2
	   4	Gnd (B0)	12	Gnd (B2+B3)/MIDI TX
	   5	Gnd (B1)	13	Axis 3
	   6	Axis 1		14	Button 3
	   7	Button 1	15	+5V (A3)/NC/MIDI RX
	   8	+5V (A1)/NC

  Each button grounds the respective pin. Axes are wired via variable
  resistors to +5V. Switches connect to GND.

  Special game ports
  ~~~~~~~~~~~~~~~~~~
  TecnoPlus:	PowerCard TP-164
  Gravis:	UltraSound		- SW setup
		Eliminator
  ThrustMaster:	ACM			- HW setup
		ACM Pro
  CH Products:	GameCard 3 Automatic	- SW setup
  QuickShot:	QS-163 Smart		- SW setup
  PDPI:		L4			- full DAC
  Aureal:	Vortex AU8820, Vortex2	- full DAC, PCI
  S3:		SonicVibes		- PCI
  Ensoniq:	ES1370, ES1371		- PCI
  nVidia:	NV1			- Sega port

  nVidia NV1 comments
  ~~~~~~~~~~~~~~~~~~~
  On the Diamond Edge 3D videocard with the NV1 chipset, there
  seems to be a special Sega gameport used in games distributed
  with the videocard.

  Aureal Vortex comments
  ~~~~~~~~~~~~~~~~~~~~~~
  PCI audio chip used in
	Turtle Beach Montego A3DXstream
	Diamond Monster Sound MX200
	Aztech PCI 338-A3D
  Contains full joystick DACs - no need for timing
  Contact: info@aureal.com, webmaster@aureal.com

  Gravis UltraSound gameport setup
  ~~~~~~~~~~~~~~~~~~~~~~~~~~~~~~~~
  Outb to 0x103+GUS base, value 0x4b  - joystick register index
  Outb to 0x105+GUS base, value 0..31 - joystick output voltage
					(0.59V-4.52V or 0.389V-2.98V)

  QuickShot QS-163 setup
  ~~~~~~~~~~~~~~~~~~~~~~
  Outb to 0x200, speed 0..15

	Bits		Meaning
	7654....	Unknown - 0
	....3210	Gameport speed (negated & M/LSB reversed)

  CH GC 3 Automatic setup
  ~~~~~~~~~~~~~~~~~~~~~~~
  Outb to 0x200, speed 0..31

	Bits		Meaning
	76......	Unknown - 0
	..54321.	Gameport speed
	.......0	Gameport enable (1 enabled, 0 disabled)

  The MCA version uses 0x202 instead.

  TecnoPlus Power Card TP-164
  ~~~~~~~~~~~~~~~~~~~~~~~~~~~
  Though the manual says it autodetects speed of the machine, it does not.
  Though the manual says it supports two 4-axis joysticks it supports only
  one. It's a simple, one-port at 0x201, unconfigurable card, except for that
  it is about twice faster than standard, making it incompatible with most
  digitally communicating joysticks.

  ThtustMaster ACM
  ~~~~~~~~~~~~~~~~
  Normal one-port gamecard, configurable at 0x201, 0x203, 0x207, 0x209, 0x20B.
  Speed can be tuned by a knob connected to the card.

  Yamaha OPL3-SA2
  ~~~~~~~~~~~~~~~
  A PnP Soundcard. The gameport is simple one-port, and can be configured via
  ISAPnP to 0x201, 0x202, 0x203 and 0x204.

  Standard game port
  ~~~~~~~~~~~~~~~~~~
  Outb to 0x201 to start axis timing
  Read 0x201 to get info

  Bits		Meaning
  ....3210	Axes 3, 2, 1, 0
  3210....	Buttons 3, 2, 1, 0

  Button bits are inverted - 1 means released, 0 pressed
  Axis bits - 0 means timing finished, 1 - timing in progress

  Time to change from 1 to 0 from the trigger is linear to axis resistance.
  Standard joysticks use resistance 0-100 kOhm (some up to 200 kOhm), and for
  standard gameports the time is approximately 10 us/kOhm.

  To detect, out to 0x201, then read, expecting 0xff. Then wait, then
  read again, expecting 0xfx ...

  Joystick extensions
  ~~~~~~~~~~~~~~~~~~~

  Additional buttons and hats ala CH Flightstick Pro
  ~~~~~~~~~~~~~~~~~~~~~~~~~~~~~~~~~~~~~~~~~~~~~~~~~~
  Button state	Meaning
	 0	Nothing pressed
	 1	Button 1
	 2	Button 2
	 3	Hat 1 left
	 4	Button 3
	 5	Button 5
	 6	Hat 2 down
	 7	Hat 1 down
	 8	Button 4
	 9	Button 6
	10	Hat 2 right
	11	Hat 1 right
	12	Hat 2 left
	13	Undefined
	14	Hat 2 up
	15	Hat 1 up

  If more than one button is pressed they are either ORed together, or the
  lowest one is signalled, depending on joystick model.

  Hat switch ala TM FCS
  ~~~~~~~~~~~~~~~~~~~~~
    Axis 3 resistance	Meaning
	 0.2 kOhm	Up
	20.0 kOhm	Left
	40.0 kOhm	Down
	60.0 kOhm	Right
	82.0 kOhm	Center

  Digital mode of MS SideWinder joysticks
  ~~~~~~~~~~~~~~~~~~~~~~~~~~~~~~~~~~~~~~~
  SideWinders send data through buttons. The transmission starts on a normal
  measure trigger (out to port 0x201).  Button 0 is used as clock (100 kHz),
  other three buttons carry data. Data is valid at clock 0->1 transition,
  LSB is transmitted first.

  SideWinder 3D Pro packet
  ~~~~~~~~~~~~~~~~~~~~~~~~
  The SW 3DP sends three packets, each 22 triplets long (64 + 2 bits). The
  packets have all the same contents. The packet layout seems to originate
  from the Mac version of SW3DP. Transmit speed is 300 kbit/sec, first packet
  takes 320 us to transmit, all three take 760 us.

  Byte 0:
	7....... - Always 1
	.6...... - Hat bit 3
	..543... - Axis 0 (X) bits 7-9
	.....210 - Axis 1 (Y) bits 7-9

  Byte 1:
	7....... - Always 0
	.6543210 - Buttons bits 0-6

  Byte 2:
	7....... - Always 0
	.6543210 - Axis 0 (X) bits 0-6

  Byte 3:
	7....... - Always 0
	.6543210 - Axis 1 (Y) bits 0-6

  Byte 4:
	7....... - Always 0
	.6...... - Buttons bit 7
	..5..... - CHF (0) / TM (1) switch
	...43... - Axis 2 (Twist) bits 7-8
	.....210 - Axis 3 (Throttle) bits 7-9

  Byte 5:
	7....... - Always 0
	.6543210 - Axis 2 (Twist) bits 0-6

  Byte 6:
	7....... - Always 0
	.6543210 - Axis 3 (Throttle) bits 0-6

  Byte 7:
	7....... - Always 0
	.654.... - Hat bits 0-2
	....3210 - Checksum bits 0-3

  The last two bits are zeroes.

  Sidewinder Force Feedback Pro packet
  ~~~~~~~~~~~~~~~~~~~~~~~~~~~~~~~~~~~~
  SW FFP sends 16 triplets (48 bits).

	  Bits     Meaning

	 0 ..  8 - Buttons		( 9 bits)
	 9 .. 18 - Axis 0 (X)		(10 bits)
	19 .. 28 - Axis 1 (Y)		(10 bits)
	29 .. 35 - Axis 2 (Twist)	( 7 bits)
	36 .. 41 - Axis 3 (Throttle)	( 6 bits)
	42 .. 45 - Hat			( 4 bits)
	      46 - Always 1
	      47 - Parity

  Sidewinder Precision Pro packet
  ~~~~~~~~~~~~~~~~~~~~~~~~~~~~~~~
  SW PP probably sends the same packet layout as the FFP version. This wasn't
  tested yet, though.

  Sidewinder hat data (for SW 3DP, FFP and PP)
  ~~~~~~~~~~~~~~~~~~~~~~~~~~~~~~~~~~~~~~~~~~~~
      Value	Direction
	0	Center
	1	Up
	2	Up-Left
	3	Left
	4	Down-Left
	5	Down
	6	Down-Right
	7	Right
	8	Up-Right

  Sidewinder GamePad packet
  ~~~~~~~~~~~~~~~~~~~~~~~~~
	Bit    Button
	 0	Axis 1 Up	(y)
	 1	Axis 1 Down	(y)
	 2	Axis 0 Right	(x)
	 3	Axis 0 Left	(x)
	 4	Button 0	(A)
	 5	Button 1	(B)
	 6	Button 2	(C)
	 7	Button 3	(X)
	 8	Button 4	(Y)
	 9	Button 5	(Z)
	10	Button 6	(L1)
	11	Button 7	(R1)
	12	Button 8	(Start)
	13	Button 9	(M)
	14	Parity

  Can be either organized as 15 triplets carrying data in bit 0 only, or can
  be five triplets (15 bits) using all three bits. The type of packet the SW
  GP sends seems to be random? Because there can be more than one SW GP
  chained, the data stream can be 15*n or 5*n bits long.  The 15-triplet mode
  allows connecting the SW GP only to a half of the joystick port.
  Transmission speed is 100 or 300 kbit/sec, packet takes 250 us or 150 us
  to transmit, depending on mode.

  Digital mode of Gravis GamePad Pro
  ~~~~~~~~~~~~~~~~~~~~~~~~~~~~~~~~~~
  As well as SW joysticks the Gravis GPP uses digital transfer through
  buttons, which is very similar to the Mode A of SW GP pad. Button 0 is used
  for timing, button 1 for data. LSB goes first.

  Gravis GamePad Pro packet
  ~~~~~~~~~~~~~~~~~~~~~~~~~
	Bit    Button
	 0	0
	 1	1
	 2	1
	 3	1
	 4	1
	 5	1
	 6	0
	 7	Button 0	(Select)
	 8	Button 1	(Start)
	 9	Button 2	(R2)
	10	Button 3	(Blue)
	11	0
	12	Button 4	(L2)
	13	Button 5	(Green)
	14	Button 6	(Yellow)
	15	Button 7	(Red)
	16	0
	17	Button 8	(L1)
	18	Button 9	(R1)
	19	Axis 1 Down	(Y)
	20	Axis 1 Up	(Y)
	21	0
	22	Axis 0 Left	(X)
	23	Axis 0 Right	(X)

  The GPP doesn't use axis trigger as a start of packet, but provides the
  five consecutive 1's for synchronization, while the packet is repeated all
  the time. The clock is 20 kHz, data is valid on 1->0 clock transition.
  Transmission speed is 20 kbit/sec, packet takes 1.2 ms to transmit.

  Digital mode of Gravis GrIP MultiPort, Gravis Xterminator
  ~~~~~~~~~~~~~~~~~~~~~~~~~~~~~~~~~~~~~~~~~~~~~~~~~~~~~~~~~
  These devices probably use the same digital protocol as the GPP, but the
  packet layout is still unknown to me.

  Digital mode of Logitech WingMan Extreme Digital
  ~~~~~~~~~~~~~~~~~~~~~~~~~~~~~~~~~~~~~~~~~~~~~~~~
  The LTWMED uses an interesting technique for timing the data stream. It
  doesn't use a clock bit, but rather uses two bits per data 'channel'.
  Because there are four buttons available, there are two data channels.
  Buttons 0 and 1 carry the upper 21 bits of the data packet, buttons 2 and 3
  carry the lower 21 bits, making it 42 bits total. It seems that Logitech
  joysticks are capable of switching into a mode where they only use two
  of the four buttons.
  Unlike the other joysticks, LTWMED sends the packet MSB first, except for
  the buttons, which are sent LSB first ...
  The two bits are used as follows: When 1 is transmitted, the upper bit
  changes state, and when 0 is transmitted, the lower bit changes state.
  Transmission speed is 100 kHz (200 kbit/sec), packet takes 320 us to
  transmit.

  Logitech WingMan Extreme Digital packet
  ~~~~~~~~~~~~~~~~~~~~~~~~~~~~~~~~~~~~~~~

	  Bits     Meaning
	 0 ..  3 - Hat			(4 bits)
	 4 ..  9 - Buttons		(6 bits)
	10 .. 17 - Axis 2 (Twist)	(8 bits)
	18 .. 25 - Axis 1 (Y)		(8 bits)
	26 .. 33 - Axis 0 (X)		(8 bits)
	34 .. 41 - 0x00			(8 bits)

  Digital mode of Logitech CyberMan2
  ~~~~~~~~~~~~~~~~~~~~~~~~~~~~~~~~~~
  The LTCM2 uses the same protocol as LTMWED, except that the packet has 64
  bits.

  Logitech CyberMan2 packet
  ~~~~~~~~~~~~~~~~~~~~~~~~~

       Byte Meaning
	0 - Buttons
	1 - Axis 5 (Roll)
	2 - Axis 4 (Pitch)
	3 - Axis 3 (Yaw)
	4 - Axis 2 (Z)
	5 - Axis 1 (Y)
	6 - Axis 0 (X)
	7 - 0x30

  Digital mode of Logitech ThunderPad Digital
  ~~~~~~~~~~~~~~~~~~~~~~~~~~~~~~~~~~~~~~~~~~~
  The LTTPD uses the same protocol as LTMWED, except that the packet has 20
  bits.

  Logitech ThunderPad Digital packet
  ~~~~~~~~~~~~~~~~~~~~~~~~~~~~~~~~~~

	Bits	   Meaning
	 0       - Button 7	(:)
	 1	 - Button 6	(.)
	 2	 - Button 5	(R)
	 3	 - Button 4	(L)
	 4	 - Axis 0 Left	(X)
	 5	 - Axis 1 Down	(Y)
	 6	 - Axis 0 Right	(X)
	 7	 - Axis 1 Up	(Y)
	 8	 - Button 3	(D)
	 9	 - Button 2	(C)
	10	 - Button 1	(B)
	11	 - Button 0	(A)
	12 .. 20 - 0x10		(8 bits)

This file (c) 1998 Vojtech Pavlik

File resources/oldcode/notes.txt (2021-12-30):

very useful video:
https://youtu.be/wdgULBpRoXk

search for PID ACK for data packet

from keypress to PID ACK on USB line: 10 to 20ms

catting /dev/input/event0 in bash: 490us
printing via python3: 1ms

script below:

fff = open("/dev/input/event0", "rb" )
while 1:
  data = fff.read(24)
  print(data)

using queue to despatch SPI on raspberry 3: 700 to 800us
on lichee 3.5ms 

libevdev is SUPER SLOW! 20ms delay in parsing keyboard events. might write about it or do some more testing.

hand parse raw dev/input: 470us on pi3, 1ms on lichee

black PS2 extension cable both male:

purple clk
black data
brown GND

ps2 driver based on https://github.com/Harvie/ps2dev
no parity check for speed

raspberry pi gpio linux pin numbers is BCM pin number, check use `gpio readall`

in allwinner chips, linux gpio number = (position of letter in alphabet - 1) * 32 + pin number

PA3 = (1-1) * 32 + 3 = gpio3

PE3 = (5-1) * 32 + 3 = 128+3 = gpio131

echo 131 > /sys/class/gpio/export

echo in > /sys/class/gpio/gpio131/direction

cat /sys/class/gpio/gpio131/value

to see list of all interrupts
cat /proc/interrupts

change keyboard LED
sudo bash -c 'echo 1 > /sys/class/leds/input5\:\:capslock/brightness'

run script on launch:

https://raspberrypi-guide.github.io/programming/run-script-on-boot

sudo nano /etc/rc.local

cd /home/pi/usb4vc; sudo python3 usb4vc_main.py &

kill -SIGINT pid

ps2 mouse todo:

add remote mode data report
add scale/resolution change
test remote/wrap mode

supported protocols:

PS/2 Keyboard:
Scancode set 2

PS/2 Mouse:
generic id0
MS intellimouse id3

Serial Mouse:
Microsoft serial mouse (3 byte 1200bps 7n1)

rfkill returns nothing with no bluetooth on rpi 2

bluetoothctrl gets stuck if no bluetooth

check rfkill first, then put a timeout on first btctl command

bluetoothctl --agent NoInputNoOutput
scan on
trust <MAC-Address>
connect <MAC-Address>

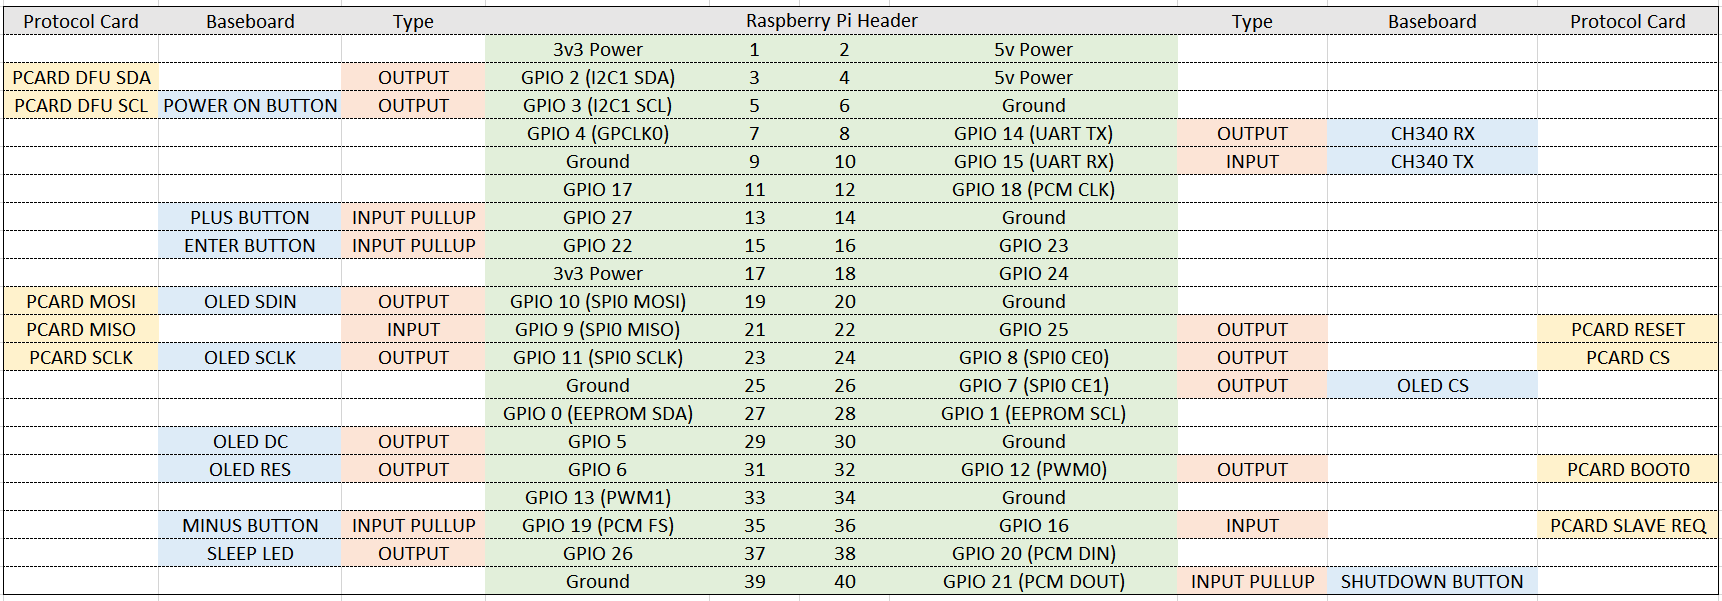
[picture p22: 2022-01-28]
photos/rpi_pinout.png

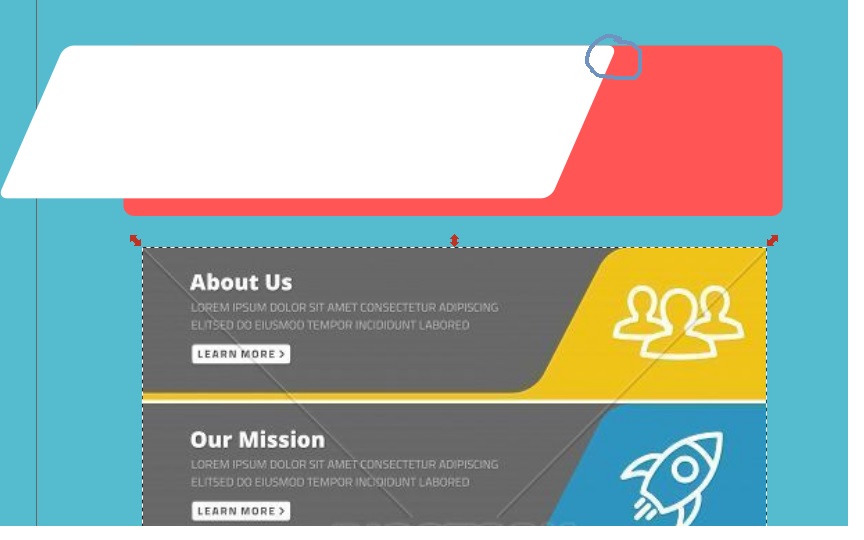
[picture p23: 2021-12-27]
resources/bezier curve - Inverse round corners with Inkscape - Graphic Design Stack Exchange_files/skP27.jpg

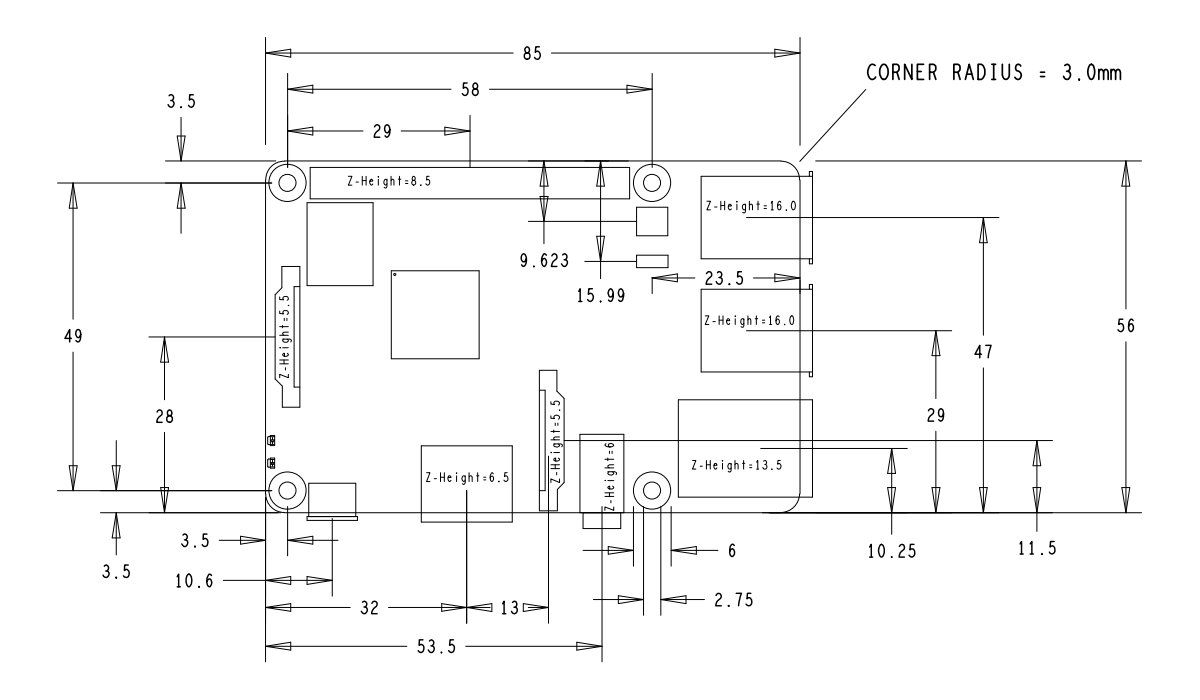
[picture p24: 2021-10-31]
resources/raspberry_pi_3_b_plus_mechanical.png

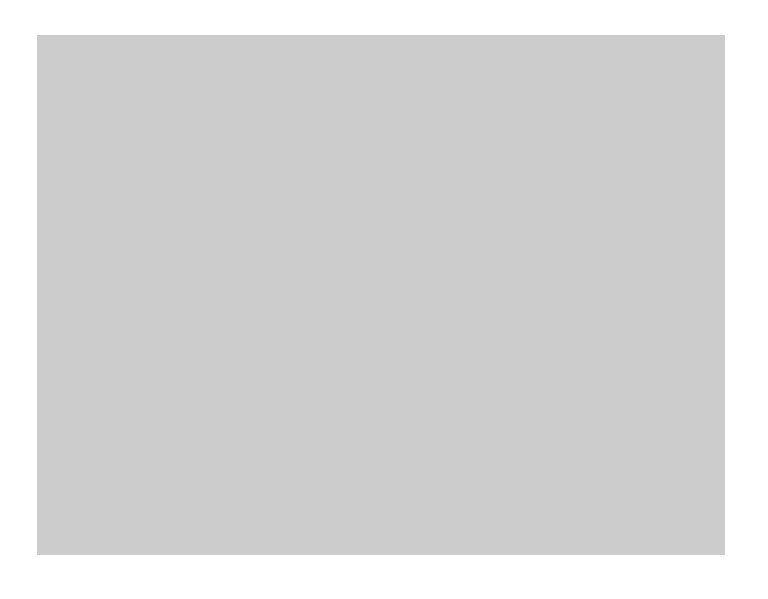
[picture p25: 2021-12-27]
resources/bezier curve - Inverse round corners with Inkscape - Graphic Design Stack Exchange_files/IgYdP.gif

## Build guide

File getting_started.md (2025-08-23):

# Getting Started with USB4VC

[Get USB4VC](https://www.tindie.com/products/dekuNukem/usb4vc-usb-inputs-on-retro-computers/) | [Official Discord](https://discord.gg/HAuuh3pAmB) | [Table of Contents](#table-of-contents)

------

Thank you very much for getting USB4VC! Here is a short guide on getting started.

## Pick a Raspberry Pi

* USB4VC is designed for **Raspberry Pi 1/2/3/4 Model B**.

* Any RPi with a **40-pin header** *should* work, although **Model B/B+** is preferred.

* No need to get the latest model, even the earliest RPi B+ is plenty fast enough.

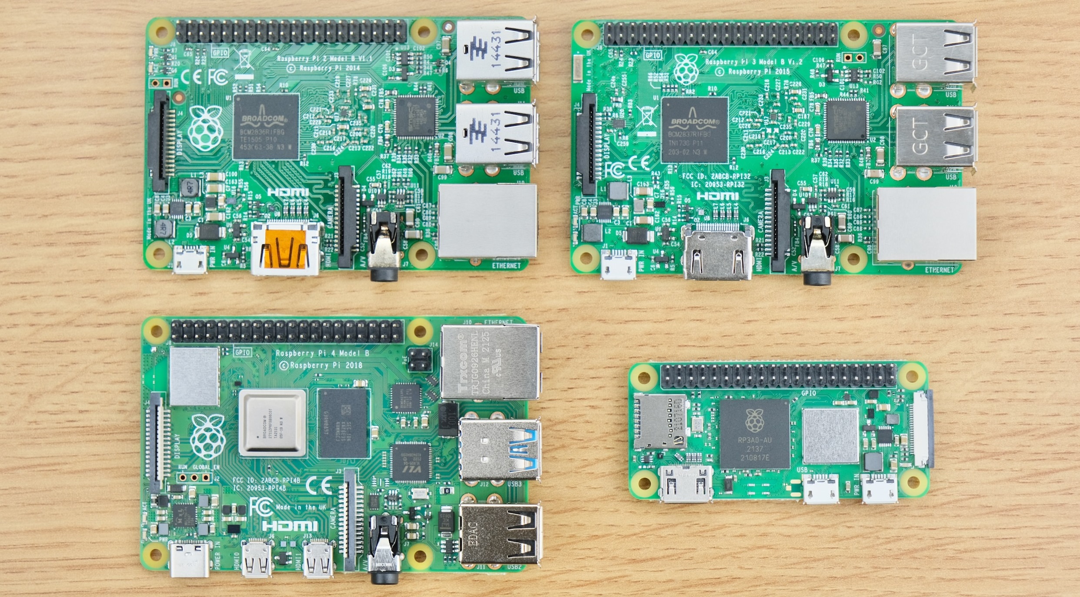
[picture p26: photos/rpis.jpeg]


## Prepare SD card

You need a Micro SD card **at least 4GB** in size. A fast card will reduce boot time.

[Download the latest boot image here](https://github.com/dekuNukem/USB4VC/releases/latest), use [7zip](https://www.7-zip.org/) to unzip.

Burn the image to your SD card. I use [Rufus](https://rufus.ie/en/), which is free and open-source. [Etcher](https://www.balena.io/etcher/) is another cross-platform option.

Select your SD card, then the image file, then press `START` to begin writing.

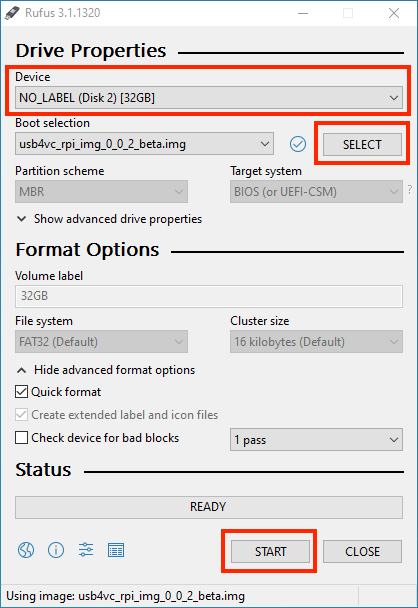
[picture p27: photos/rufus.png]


## (Optional) Set up WiFi

After burning the SD card, go to the drive named `boot`, and open up `wpa_supplicant.conf` with a **proper text editor**:

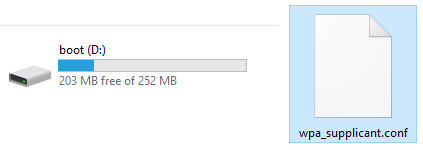
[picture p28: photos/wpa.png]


If the file doesn't exist, [download a new one](https://github.com/dekuNukem/USB4VC/raw/master/resources/wpa_supplicant.zip), unzip, put it under `boot`, and continue.

Edit the file with your WiFi information. You can find your [WiFi country code here.](https://www.arubanetworks.com/techdocs/InstantWenger_Mobile/Advanced/Content/Instant%20User%20Guide%20-%20volumes/Country_Codes_List.htm)

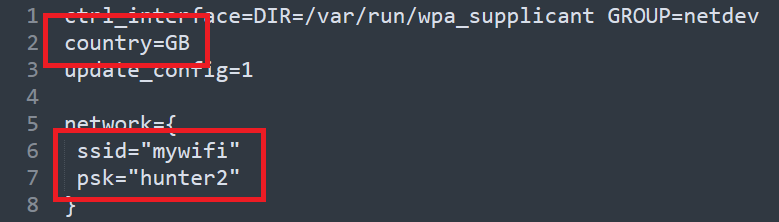
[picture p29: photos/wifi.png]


## Kit Assembly

Insert the SD card in your Raspberry Pi. Then [See this guide](/kit_assembly.md) to put everything together.

## Power Considerations

A **high-quality power supply** is very important! It should provide **5 Volts** and at least **2 amps** of current.

An inadequate supply can result in failure to boot, unstable operation, glitches, and SD card corruption.

Check the cable too! Cheap ones tends to have unreliable connections and large voltage drops.

## Protocol Card Overview: IBM PC

Let's take a quick look:

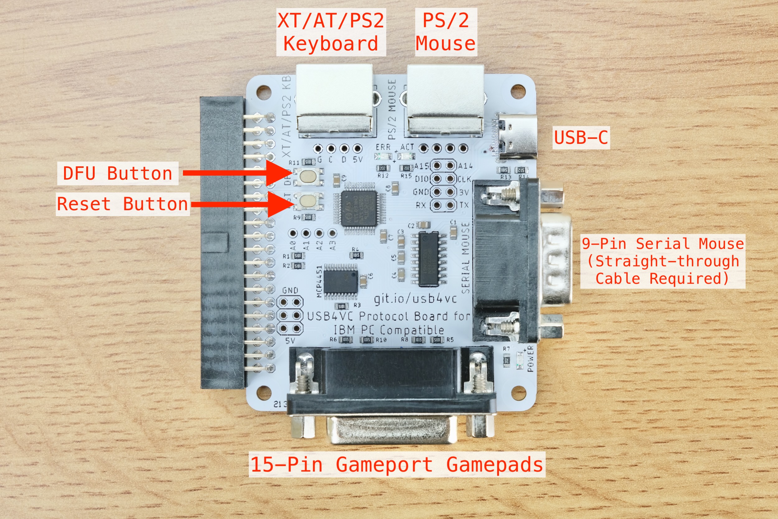
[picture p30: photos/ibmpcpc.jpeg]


* Cables can be purchased in [my Tindie store](https://www.tindie.com/products/dekuNukem/usb4vc-usb-inputs-on-retro-computers/) (and of course other places).

* PS/2 keyboard and mouse need a **male to male** PS/2 cable.

* XT and AT keyboards need a **PS/2 female to AT male** adapter.

* The 9-Pin serial mouse requires a **female-to-female straight-through** cable.

* The 15-Pin gameport requires a **male-to-male** cable.

* DFU button is used for firmware updates.

## Protocol Card Overview: Apple Lisa, Early Mac, and ADB

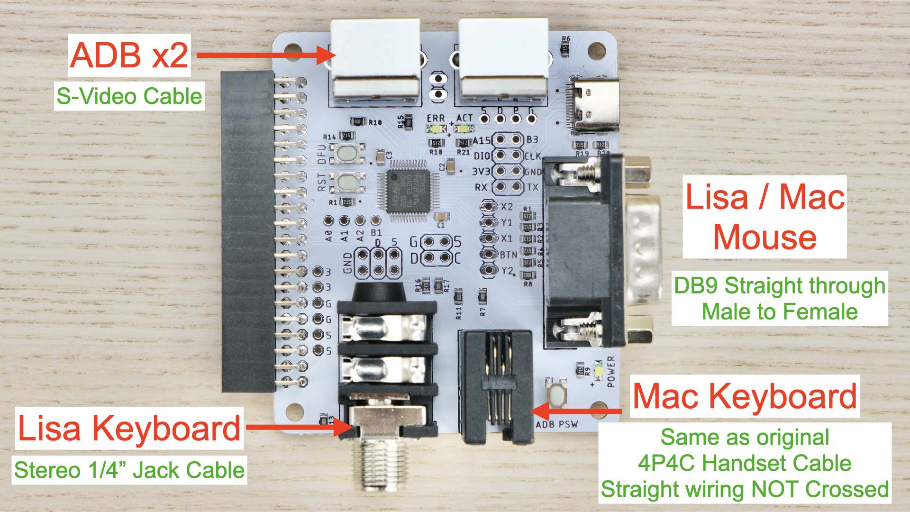
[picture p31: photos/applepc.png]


## Cable Connection

**Keep everything OFF for now!**

Using the appropriate cable, connect the desired port from Protocol Card to your computer.

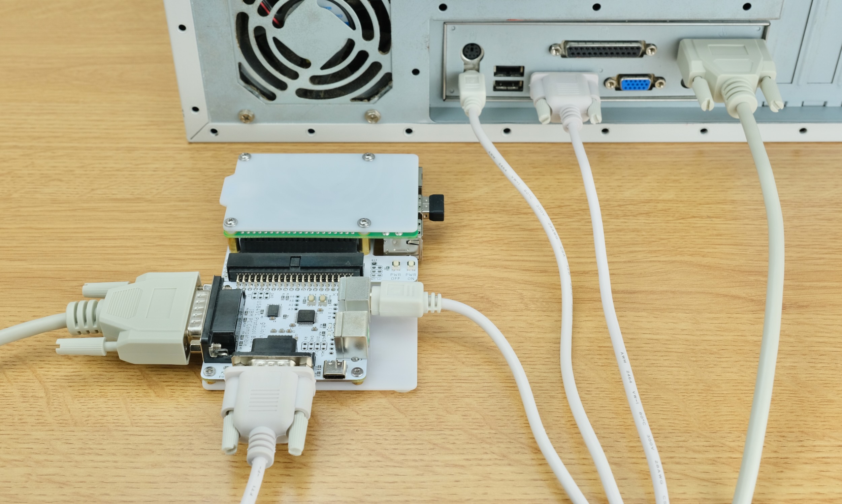
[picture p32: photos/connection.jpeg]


Most retro peripherals are **NOT hot pluggable**, so make sure **all cables are connected before using!**

Also plug in any USB Keyboard, Mouse, and Gamepad into the Raspberry Pi.

If using Bluetooth, we can pair it later.

## Powering On

With cables connected, power up USB4VC with a USB-C cable.

You can do it from Baseboard, Protocol Card, or even RPi itself. All will work!

**Always turn on USB4VC BEFORE the computer!**

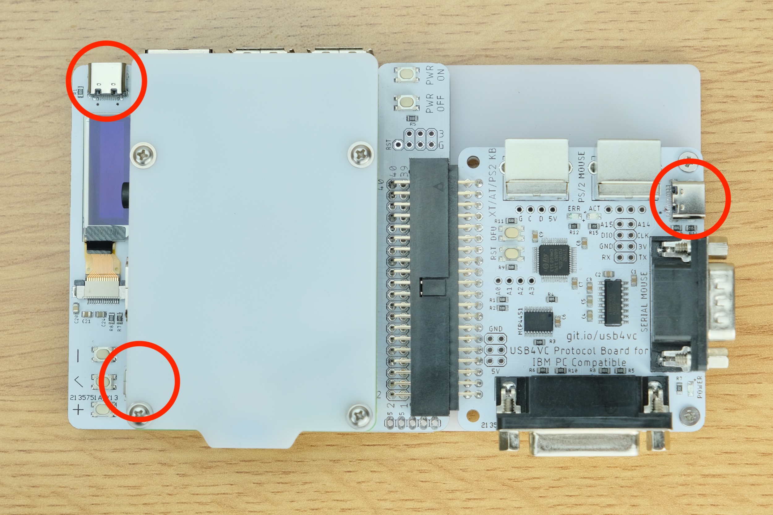
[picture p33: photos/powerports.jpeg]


Protocol card will power up instantly and start talking with the retro computer, while Raspberry Pi takes a few seconds to boot up.

After a little while, the OLED screen should light up, showing **home screen**:

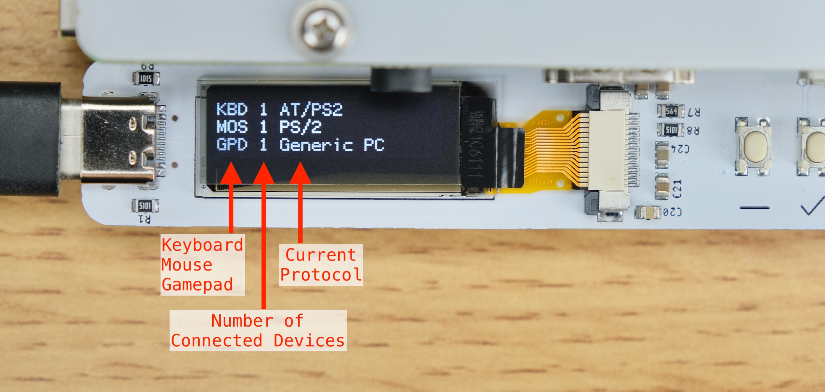
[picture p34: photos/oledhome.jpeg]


Press `+` or `-` to switch pages, and `enter` button to enter the submenu.

## Protocol Setup

Looking at home screen, if displayed protocol is what you want, you're good to go!

Otherwise, press `Enter` button to go to the submenu, and use `Enter` button to adjust protocols, mouse sensitivity, and gamepad linearity.

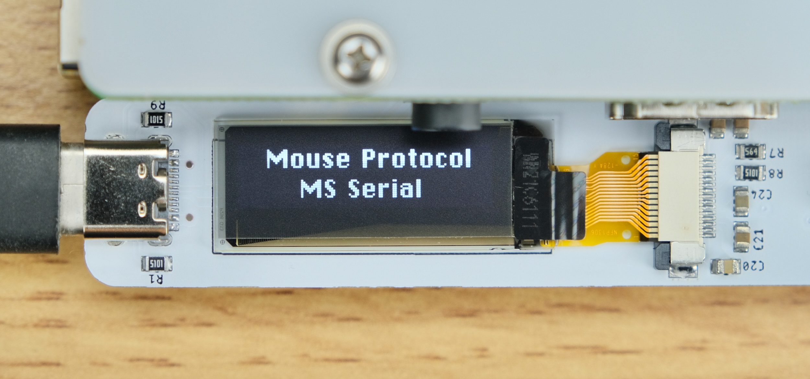
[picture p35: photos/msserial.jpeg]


It is recommended to leave the sensitivity adjustments at default, and change them inside the OS or game first. Only do it on USB4VC if that's not possible.

## (Optional) Software Updates

Select `Internet Update` in main menu. It will update source code and P-Card firmware to latest version.

## Pair Bluetooth

Select "Pair Bluetooth":

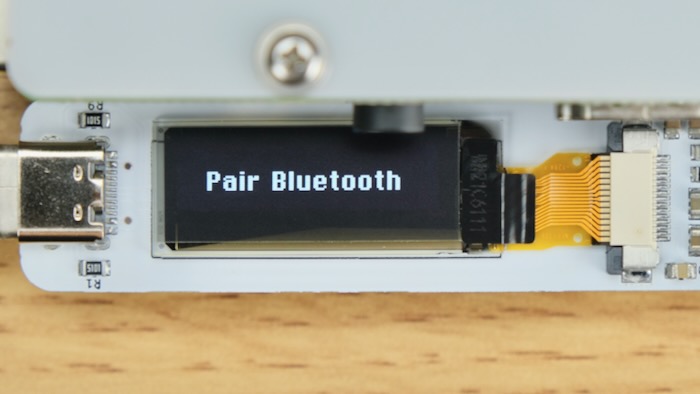
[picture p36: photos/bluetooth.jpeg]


Put your device in Pairing mode, and press enter to start scanning.

After a while, a list of found devices is shown. If your device does not appear, try scanning again.

Use `+` / `-` to select one, and `enter` button to pair.

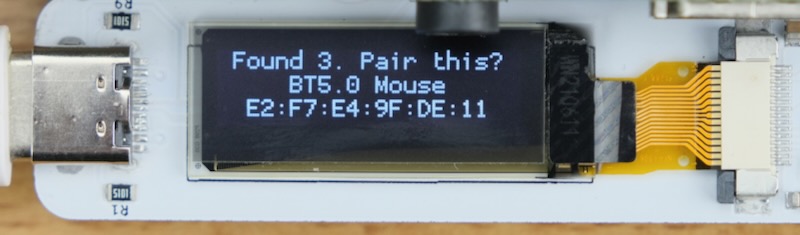
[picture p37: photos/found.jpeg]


Pairing result will be shown. From my experience Bluetooth Mouse/Keyboards are usually fine, but Bluetooth gamepads can be a bit temperamental sometimes. If error occurs, try rebooting the BT device and/or USB4VC.

## Try it out!

With protocol selected, and everything connected, time to power on the computer!

If everything goes well, you should be able to use it as normal, now with USB inputs!

Please **do keep reading** for more information though 😅!



## Using Gamepads

Currently, USB4VC officially supports the following controllers:

* Xbox 360 / Xbox One / Xbox Series X

* PlayStation 4 / PlayStation 5

In my testing, gamepad compatibility seems to depends on the RPi models:

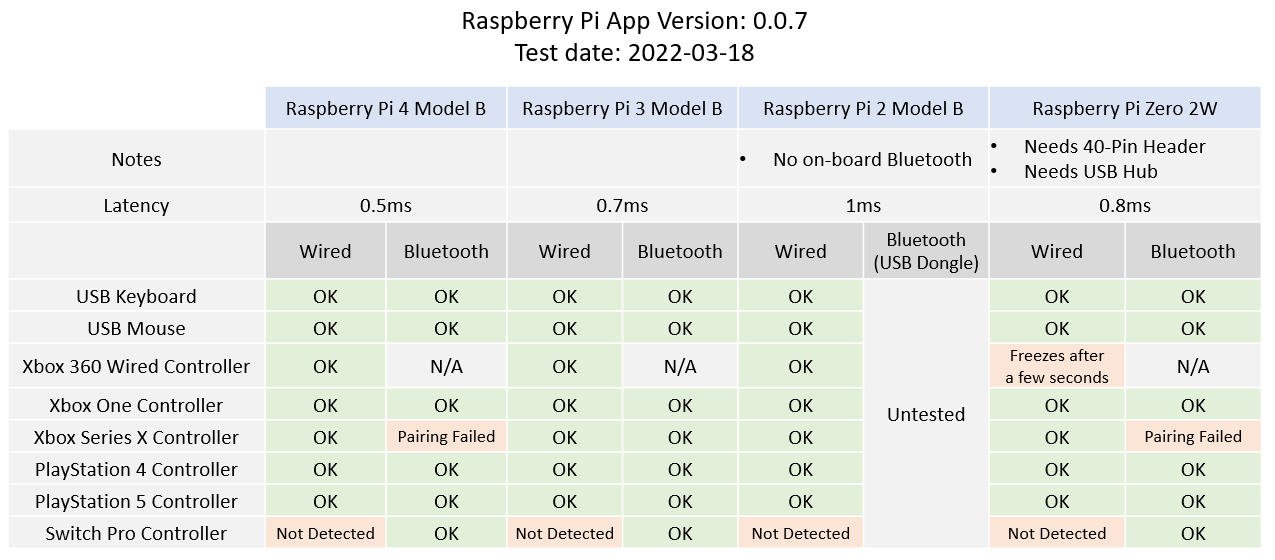
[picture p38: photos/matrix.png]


* **Raspberry Pi 3 Model B** seems to be the most compatible.

* If pairing fails, remove the BT device in the menu, reboot USB4VC, and try again.

* Multiple controllers should work, although analog stick might compete with each other.

-----

Once connected, you can enable `15-Pin Gamepad` Protocol on IBM PC Card, and it should behave like a generic gamepad with **4 buttons and 4 analog axes**.

With **officially supported controllers**, the mapping is:

* 4 face buttons to 4 gameport buttons

* Left and right shoulder button to gameport button 3 & 4.

* Left Stick to gameport Joystick 1.

* Right Stick to gameport Joystick 2.

* Left & Right Analog Triggers to Joystick 2 Y-Axis.

Unsupported USB controllers should still work, although you might need to make your own mapping (see below).

## Custom Gamepad Mapping

You can also create your own USB Gamepad mapping or have it **control mouse and keyboard**, in order to play games that did not have native gamepad support!

[Download the configurator](https://github.com/dekuNukem/usb4vc-configurator/blob/master/README.md) and follow the instruction to set it up.

## Joycheck DOS Program

You can [download this DOS program](https://github.com/dekuNukem/USB4VC/raw/master/resources/joytest.zip) to visualize what the gamepad is doing, great for troubleshooting! Found on this [vogons thread](https://www.vogons.org/viewtopic.php?p=187168#p187168).

* It's OK if the values are slightly off. Games will calibrate before starting anyway.

* Careful with pressing keyboard keys, it might mess up the display.

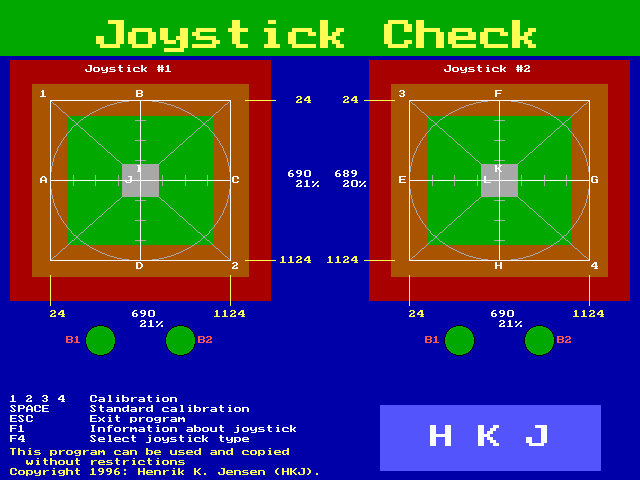
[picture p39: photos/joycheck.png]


## Software Update

Connect RPi to internet. You can [set up WiFi](#optional-set-up-wifi), or plug in an Ethernet cable.

Then simply select `Internet Update` in main menu. It will update source code and P-Card firmware to latest version.

## Tinkering Guide / Making Your Own Protocol Card / Technical Details

[Click me!](technical_notes.md)

## Powering Off/On

You can turn off/reboot the Raspberry Pi by pressing the `POWER OFF` button.

When the RPi is off, you can press `POWER ON` button to turn it back on.

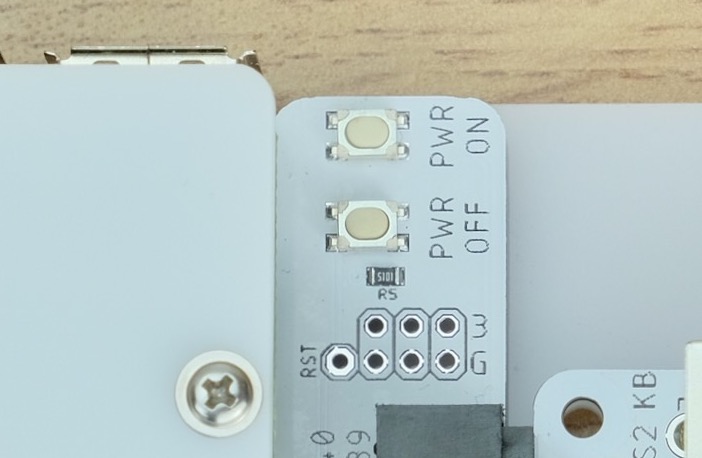
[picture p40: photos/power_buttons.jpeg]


## Plate Dimensions

Want to design a custom case? [Click me](pcb/plates) for dimension drawings.

## Known Issues

Here are a couple of bugs and issues that I am aware of, and the corresponding comments and remedies.

#### Boot Time

* Currently it takes about 17 seconds to boot with a decent SD card.

* Would be great if it's faster.

* Might look into disabling some services to speed it up.

* [Let me know](#questions-or-comments) if you'd like to help!

#### 15-Pin Gameport Power Backfeeding

* If USB4VC is unpowered, turning on the PC seems to back-feed power through the 15-pin gameport via the digital potentiometer.

* I haven't noticed any apparent damage, but it's probably not a good idea.

* Make sure to power on USB4VC **BEFORE** the computer. (this is what you should do anyway)

#### ADB Collision Resolution

* ADB collision resolution has not been fully implemented yet.

* Issues might arise **ONLY IF** you daisy-chain additional ADB devices **of the same type** **AND** use them **at the same time**.

* Not a high-priority bug, might work on it when I have time.

## Questions or Comments?

Feel free to ask in official [Discord Chatroom](https://discord.gg/HAuuh3pAmB), raise a [Github issue](https://github.com/dekuNukem/USB4VC/issues), [DM on Twitter](https://twitter.com/dekuNukem_), or email `dekunukem` `gmail.com`!

## Table of Contents

[Main page](README.md)

[(Youtube Video) USB4VC in Action](https://www.youtube.com/watch?v=54sdPELuu4g)

[Getting Started Guide](getting_started.md)

[Kit Assembly Guide](kit_assembly.md)

[Tinkering Guide / Make Your Own Protocol Card / Technical Notes](technical_notes.md)

[Kickstarter Acknowledgements](kickstarter_info.md)

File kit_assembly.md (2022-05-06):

# USB4VC Kit Assembly

[Get USB4VC](https://www.tindie.com/products/dekuNukem/usb4vc-usb-inputs-on-retro-computers/) | [Official Discord](https://discord.gg/HAuuh3pAmB) | [Getting Started](getting_started.md) | [Table of Contents](#table-of-contents)

----

Thanks for getting USB4VC! Here is a quick guide on how to put everything together.

## Recommended Tools

A small Phillips-head screwdriver (`+`shape) should be included in the package.

A pair of pliers would make tightening the fasteners easier, but not required.

## Handling Bare Circuit Boards

To reduce the risk of damage from static discharge:

* Wash your hands first

* Always hold the circuit board by its edge

* Don't touch the components

## Assembly Steps

By now, you should have:

* USB4VC Baseboard

* USB4VC Protocol Card(s)

* Raspberry Pi 1/2/3/4 Model B

* Acrylic Plates

* Mini Screwdriver

* Fasteners

* Anti-slip feet

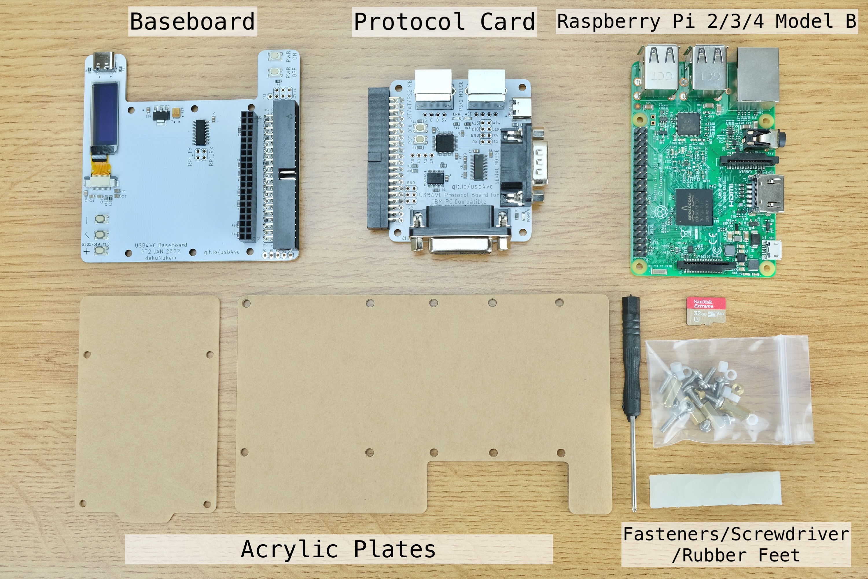
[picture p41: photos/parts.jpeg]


You should have the following fasteners, take note of what they look like :)

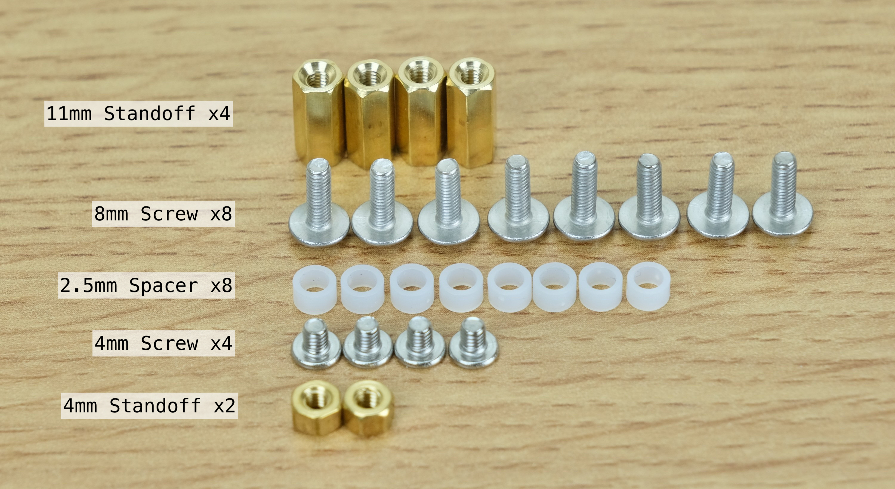
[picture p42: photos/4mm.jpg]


Start by peeling off the protective layer on acrylic plates:

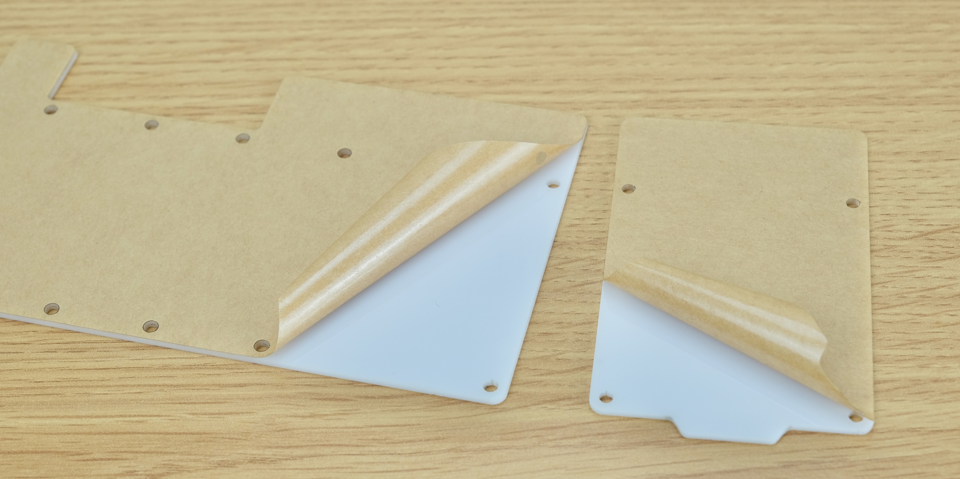
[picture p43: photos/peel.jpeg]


Orient plate the plate as shown, insert four `8mm Screws` into the marked holes:

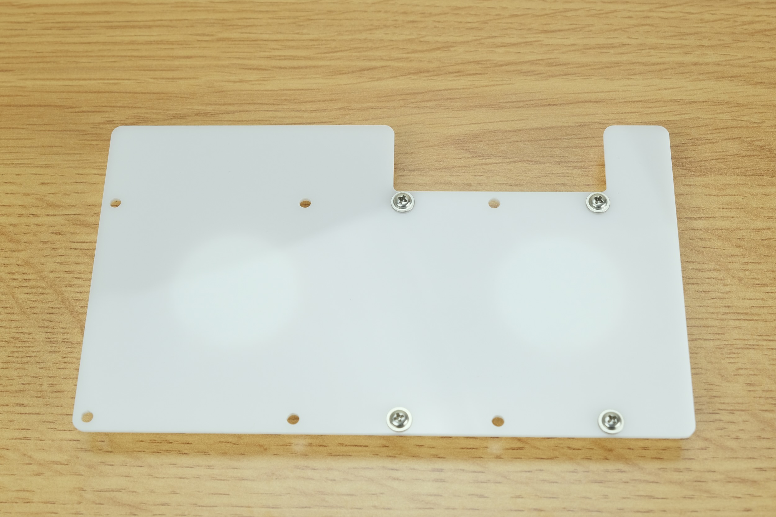
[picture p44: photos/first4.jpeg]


Put something rigid (cardboard, etc) over the screws, and flip the whole thing over.

The screws should stay in place, insert four `2.5mm Spacers` over the screws:

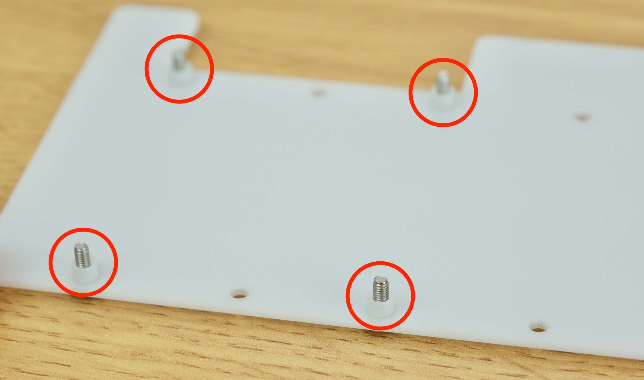
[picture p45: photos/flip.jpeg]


Put the Baseboard over the screws, and install four `11mm Standoffs`, moderately tighten.

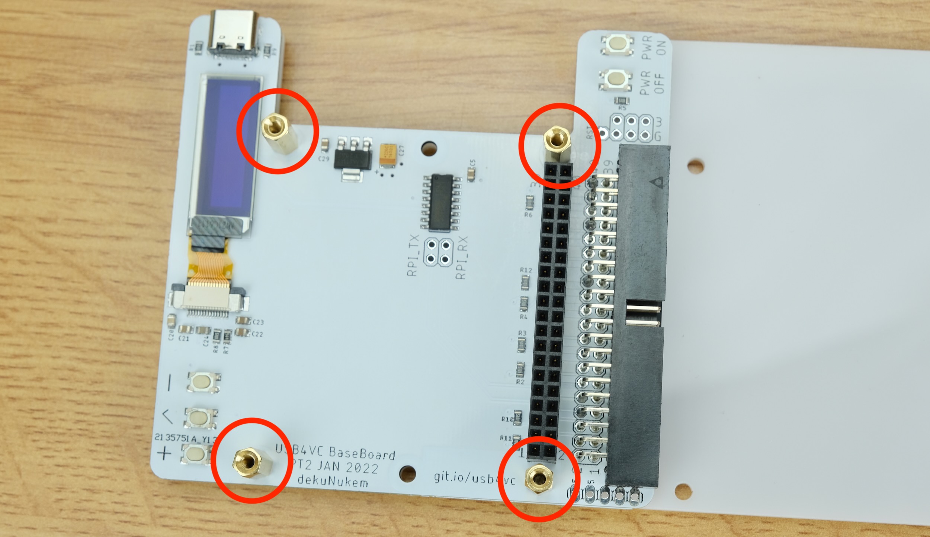
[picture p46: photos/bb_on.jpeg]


Plug your Raspberry Pi into the pin headers, push down gently until fully inserted, make sure everything is lined up.

Put four `2.5mm Spacers` over the holes.

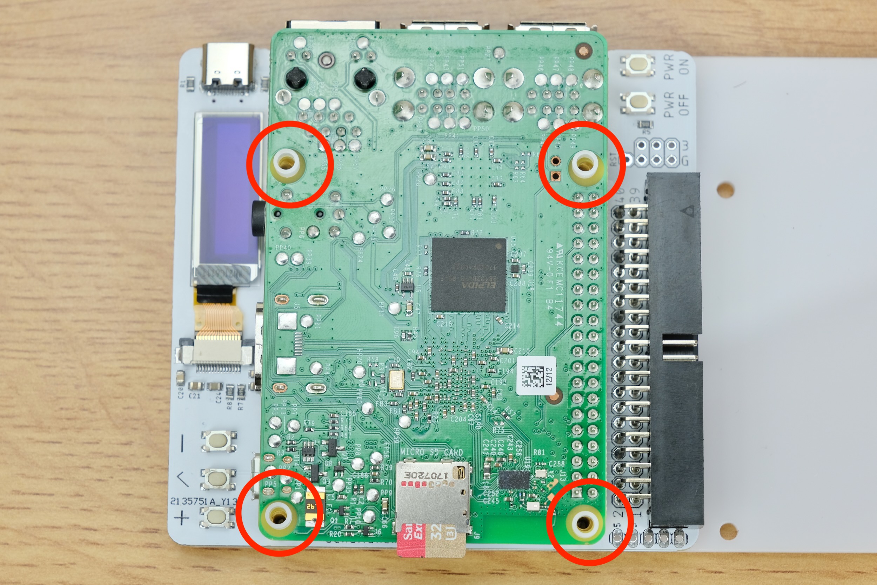
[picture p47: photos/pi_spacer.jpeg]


Position the top plate over the holes, make sure the plastic standoffs are not displaced. 

Screw the four `8mm Screws` into the metal standoffs underneath.

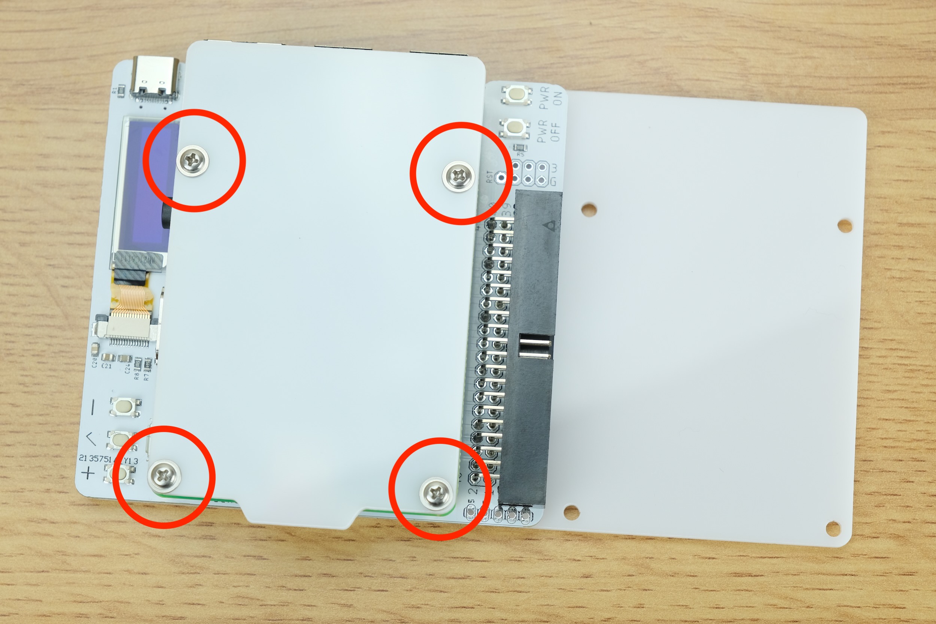
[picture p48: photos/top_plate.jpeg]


Insert two `4mm Screws` from the underside.

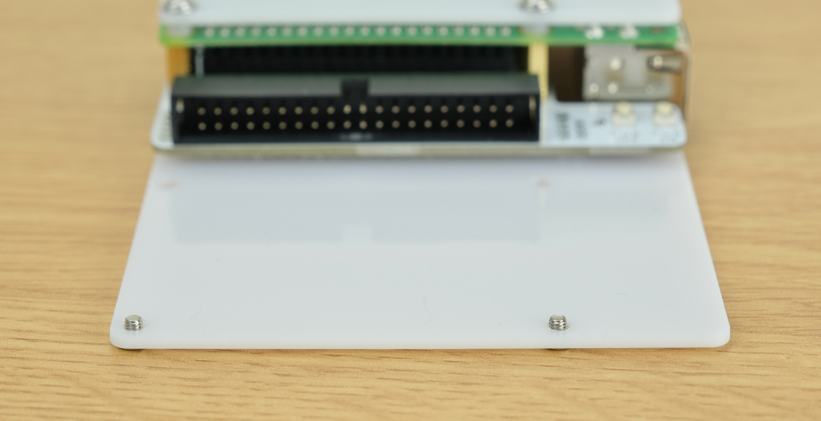
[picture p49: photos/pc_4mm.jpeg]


Install two `4mm Standoffs` from top. **DO NOT OVER-TIGHTEN!** Otherwise you might crack the acrylic. Finger-tight is OK.

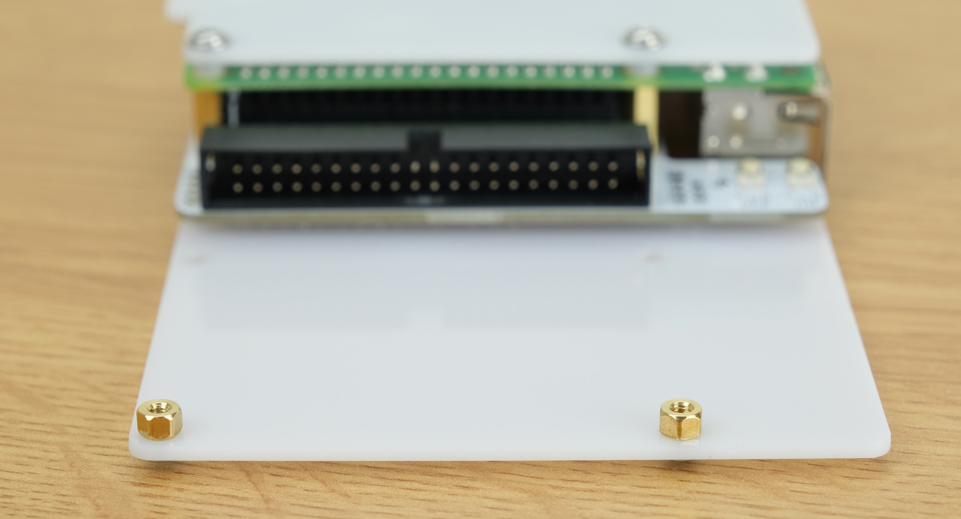
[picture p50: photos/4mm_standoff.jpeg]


Insert the Protocol Card into the connector, and secure it with two `4mm Screws`.

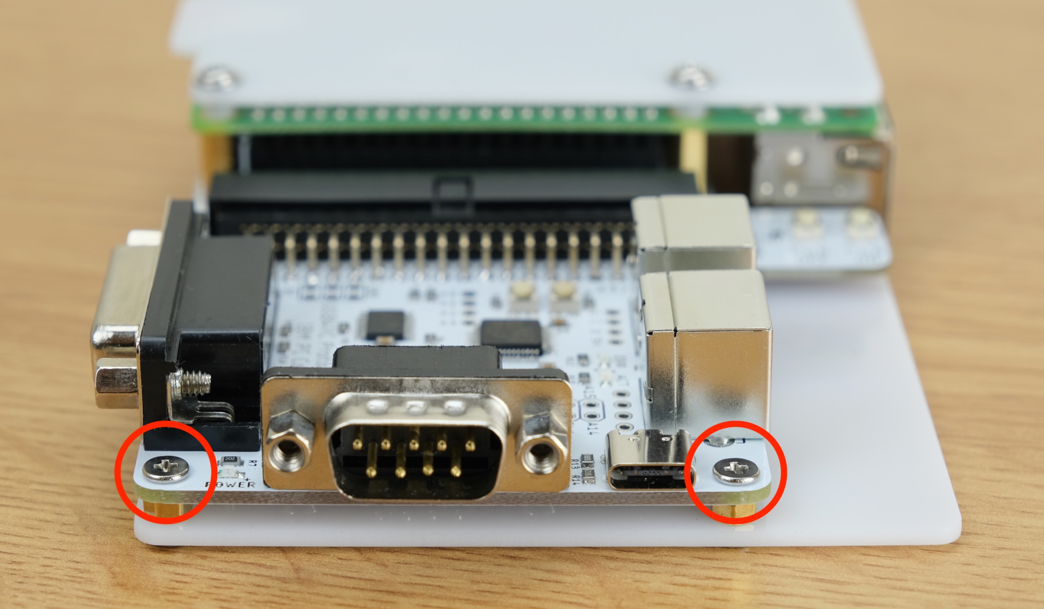
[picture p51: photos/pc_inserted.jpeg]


Flip it over, clean the area if dirty, and stick on the anti-slip feet on the corners:

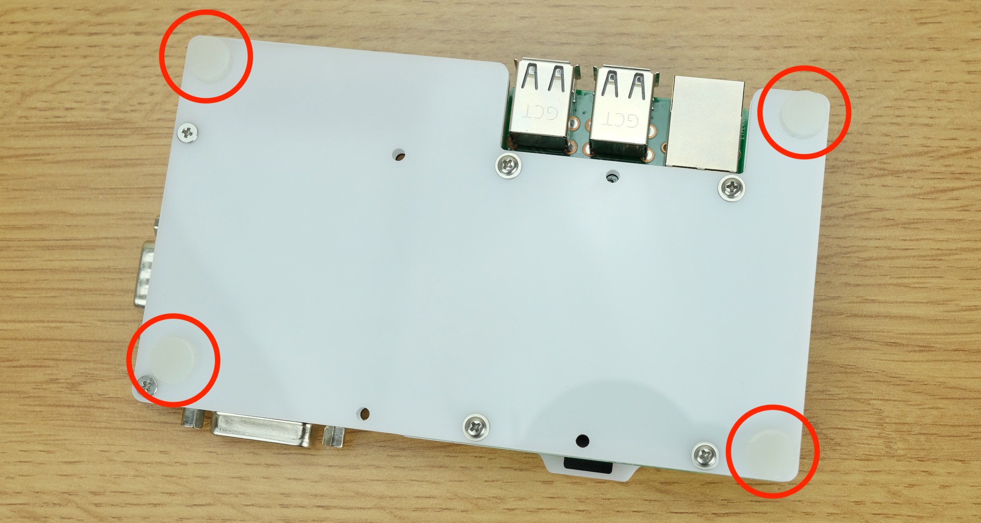
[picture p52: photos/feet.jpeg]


If your package came with labels, attach them like so:

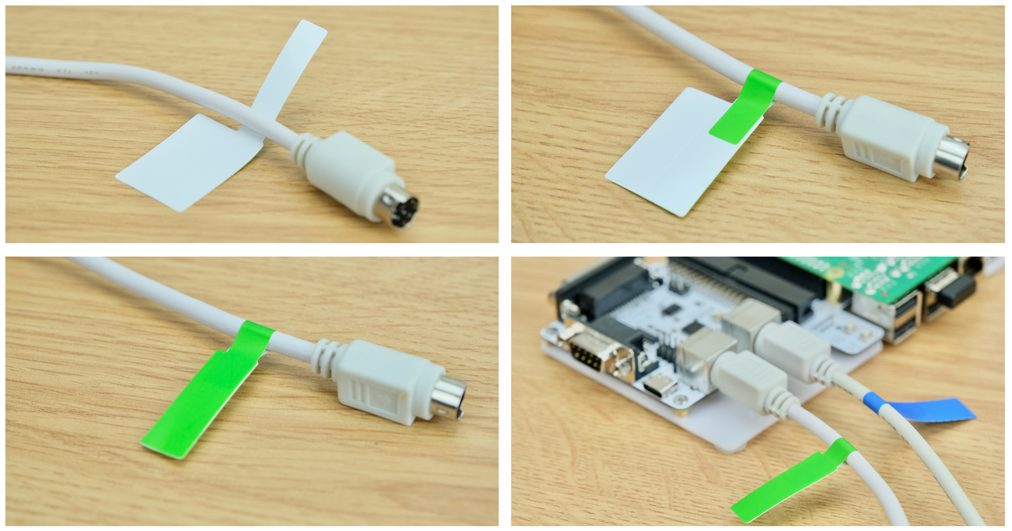
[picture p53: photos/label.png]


And you're done! Congratulations!

Head back to the [Getting Started Guide](getting_started.md#kit-assembly) to see how to use it.

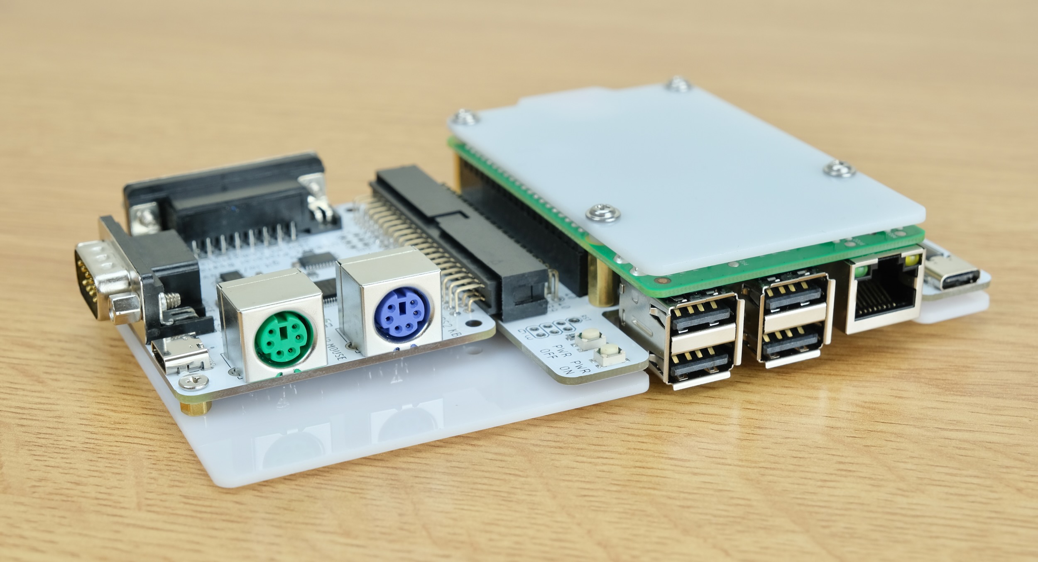
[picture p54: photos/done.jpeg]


## Questions or Comments?

Feel free to ask in [official Discord](https://discord.gg/HAuuh3pAmB), raise a [Github issue](https://github.com/dekuNukem/USB4VC/issues), [DM on Twitter](https://twitter.com/dekuNukem_), or email `dekunukem` `gmail.com`!

## Table of Contents

[Main page](README.md)

[(Youtube Video) USB4VC in Action](https://www.youtube.com/watch?v=54sdPELuu4g)

[Getting Started Guide](getting_started.md)

[Kit Assembly Guide](kit_assembly.md)

[Tinkering Guide / Make Your Own Protocol Card / Technical Notes](technical_notes.md)

[Kickstarter Acknowledgements](kickstarter_info.md)

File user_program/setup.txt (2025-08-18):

-----------
Preparing SD card image for public release:

double check wpa_supplicant in /etc DOES NOT contain my own WiFi password
Put BLANK wpa_supplicant.conf in /boot
use the same base image for the same minor version, manually copy over the files, dont just dump the developement SD card.

-----------
Fresh install setup

raspbi-config
enable SPI, I2C, Serial (NO LOGIN SHELL)

sudo apt install git

set up ssh:
ssh-keygen
copy PC pub key to rpi ~/.ssh/authorized_keys

------------

IMPORTANT !!!!!!!!!!!!!!!!!!

sudo apt update
sudo apt upgrade

-------------
# use sudo -E to preserve environmental variables for python3
sudo apt-get update

sudo apt-get install i2c-tools
sudo apt install stm32flash

stm32flash -r PBFW_IBMPC_PBID1_V0_2_0.dfu -a 0x3b /dev/i2c-1

sudo apt install dfu-util
sudo dfu-util --device ,0483:df11 -a 0 -D ~/usb4vc/firmware/PBFW_ADB_PBID2_V0_1_1.dfu

-----
sudo apt install evtest
pip3 install evdev

sudo apt install python3-pip

raspberry pi 5 uses a different GPIO chip, this is a compatibility package

// no need
sudo apt remove python3-rpi.gpio
// no need?
sudo pip3 install --break-system-packages rpi-lgpio

cd ~;git clone https://github.com/atar-axis/xpadneo.git
sudo apt-get install dkms raspberrypi-kernel-headers 

https://github.com/atar-axis/xpadneo
--------------

sudo mv /usr/lib/python3.11/EXTERNALLY-MANAGED /usr/lib/python3.11/EXTERNALLY-MANAGED.old
-----

Luma OLED driver

https://luma-oled.readthedocs.io/en/latest/software.html
sudo apt-get update
sudo apt-get install python3 python3-pip python3-pil libjpeg-dev zlib1g-dev libfreetype6-dev liblcms2-dev libopenjp2-7 -y
sudo -H pip3 install luma.oled

-------------------
remove CTRL+ALT+DELETE reboot

sudo rm /lib/systemd/system/ctrl-alt-del.target
sudo ln -s /dev/null /lib/systemd/system/ctrl-alt-del.target
sudo systemctl daemon-reload
-------------------

run script on launch:

MAKE SURE SERIAL LOGIN SHELL IS TURNED OFF

https://raspberrypi-guide.github.io/programming/run-script-on-boot

sudo su

sudo nano /etc/rc.local

echo 1 > /sys/module/bluetooth/parameters/disable_ertm
cd /home/pi/usb4vc/rpi_app; python3 keep_alive.py 2>&1 | tee -a /home/pi/usb4vc/usb4vc_debug_log.txt &

kill -SIGINT pid

-----------
xbox one bluetooth driver

https://github.com/atar-axis/xpadneo

echo 'options bluetooth disable_ertm=Y' | sudo tee -a /etc/modprobe.d/bluetooth.conf

------------
boot speedup:

sudo nano /boot/firmware/config.txt
disable_splash=1
boot_delay=0

sudo nano /boot/firmware/cmdline.txt

Add quiet after rootwait

-------------

usb auto mount:

sudo apt install usbmount

sudo nano /lib/systemd/system/systemd-udevd.service

change to PrivateMounts=no

-----------

zero out free space to compress better:

cat /dev/zero > ./zero.file
wait until it exits
sync
rm zero.file

-----------

usb folder format:

usb root:

usb4vc_data
	rpi_app
		source code of raspberry pi application
	firmware
		dfu file for protocol boards
		naming format: PBFW_IBMPC_PBID1_V0_1_0.dfu
	config
		config and mapping files

--------------

Raspberry Pi 5 Controller test:

WIRED

Xbox 360 wired: cant find the controller
Xbox One: OK
Xbox Series X: OK
PS4: ok
PS5: ok
Swich Pro: OK

BLUETOOTH

Xbox One: NO
Xbox Series X: NO
PS4: OK
PS5: 
Swich Pro: 

xxxxxxxxxxxxxxxxxxxxxxxxxxxxxxx NO LONGER NEEDED xxxxxxxxxxxxxxxxxxxxxxxxxxxxxxxxxxx

raspberry pi 3
before speedup:

19.16
18.07
19.11
18.37

after speedup:

16.95
16.45
--------------
Nintendo Pro controller
https://retropie.org.uk/docs/Nintendo-Switch-Controllers/

sudo apt install git
sudo apt install dkms
sudo apt-get install libudev-dev
sudo apt-get install libevdev-dev

git clone https://github.com/nicman23/dkms-hid-nintendo
cd dkms-hid-nintendo
sudo dkms add .
sudo dkms build nintendo -v 3.2
sudo dkms install nintendo -v 3.2

git clone https://github.com/DanielOgorchock/joycond.git
cd joycond
cmake .
sudo make install
sudo systemctl enable --now joycond

----------------------

Serial setup:

serial clock is tied to GPU clock, need to fix it for it to be stable

sudo nano /boot/config.txt, add:
gpu_freq=250
gpu_freq_min=250

also, use /dev/serial0 to maintain compatibility for all models of pi

--------------

relaunch if exits:

while true; do echo think; sleep 1; done

---------

serial format:

U4 CMD_TYPE PAYLOAD

U4 header, any command not beginning with U4 is ignored

CMD TYPE:
SC: Shell Command, execute whatever follows in shell
RF: Read File
WF: Write File
GG: get gamepad file
QUIT: quit program

U4 RF /home/pi/usb4vc_data/config.json
U4 WF /home/pi/usb4vc_data/test.txt c3NoIHBpQDE5Mi4xNjguMS41Ng==

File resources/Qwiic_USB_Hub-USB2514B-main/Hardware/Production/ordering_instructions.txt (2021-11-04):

panel size, 183x177mm
PCB thickness, 1.6mm
number of layers, 2
soldermask color, Black
silkscreen color, White
oz copper, 1oz
finish, HASL lead free
stencils, none
pcs per panel, 6
min trace width, 0.1778mm / 0.0070in
min drill size, 0.3048mm / 0.0120in

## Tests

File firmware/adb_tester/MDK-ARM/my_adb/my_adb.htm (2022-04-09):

# Static Call Graph for image my_adb\my_adb.axf

#<CALLGRAPH># ARM Linker, 5060750: Last Updated: Sat Apr 09 21:33:49 2022

### Maximum Stack Usage = 164 bytes + Unknown(Cycles, Untraceable Function Pointers)

### Call chain for Maximum Stack Depth:

main ⇒ SystemClock_Config ⇒ HAL_RCC_ClockConfig ⇒ HAL_RCC_GetSysClockFreq ⇒ __aeabi_uidivmod

### Mutually Recursive functions

- ADC1_IRQHandler ⇒ ADC1_IRQHandler
- HardFault_Handler ⇒ HardFault_Handler

### Function Pointers

- ADC1_IRQHandler from startup_stm32f042x6.o(.text) referenced from startup_stm32f042x6.o(RESET)
- CEC_CAN_IRQHandler from startup_stm32f042x6.o(.text) referenced from startup_stm32f042x6.o(RESET)
- DMA1_Channel1_IRQHandler from startup_stm32f042x6.o(.text) referenced from startup_stm32f042x6.o(RESET)
- DMA1_Channel2_3_IRQHandler from startup_stm32f042x6.o(.text) referenced from startup_stm32f042x6.o(RESET)
- DMA1_Channel4_5_IRQHandler from startup_stm32f042x6.o(.text) referenced from startup_stm32f042x6.o(RESET)
- EXTI0_1_IRQHandler from startup_stm32f042x6.o(.text) referenced from startup_stm32f042x6.o(RESET)
- EXTI2_3_IRQHandler from startup_stm32f042x6.o(.text) referenced from startup_stm32f042x6.o(RESET)
- EXTI4_15_IRQHandler from startup_stm32f042x6.o(.text) referenced from startup_stm32f042x6.o(RESET)
- FLASH_IRQHandler from startup_stm32f042x6.o(.text) referenced from startup_stm32f042x6.o(RESET)
- HardFault_Handler from stm32f0xx_it.o(i.HardFault_Handler) referenced from startup_stm32f042x6.o(RESET)
- I2C1_IRQHandler from startup_stm32f042x6.o(.text) referenced from startup_stm32f042x6.o(RESET)
- NMI_Handler from stm32f0xx_it.o(i.NMI_Handler) referenced from startup_stm32f042x6.o(RESET)
- PVD_VDDIO2_IRQHandler from startup_stm32f042x6.o(.text) referenced from startup_stm32f042x6.o(RESET)
- PendSV_Handler from stm32f0xx_it.o(i.PendSV_Handler) referenced from startup_stm32f042x6.o(RESET)
- RCC_CRS_IRQHandler from startup_stm32f042x6.o(.text) referenced from startup_stm32f042x6.o(RESET)
- RTC_IRQHandler from startup_stm32f042x6.o(.text) referenced from startup_stm32f042x6.o(RESET)
- Reset_Handler from startup_stm32f042x6.o(.text) referenced from startup_stm32f042x6.o(RESET)
- SPI1_IRQHandler from startup_stm32f042x6.o(.text) referenced from startup_stm32f042x6.o(RESET)
- SPI2_IRQHandler from startup_stm32f042x6.o(.text) referenced from startup_stm32f042x6.o(RESET)
- SVC_Handler from stm32f0xx_it.o(i.SVC_Handler) referenced from startup_stm32f042x6.o(RESET)
- SysTick_Handler from stm32f0xx_it.o(i.SysTick_Handler) referenced from startup_stm32f042x6.o(RESET)
- SystemInit from system_stm32f0xx.o(i.SystemInit) referenced from startup_stm32f042x6.o(.text)
- TIM14_IRQHandler from startup_stm32f042x6.o(.text) referenced from startup_stm32f042x6.o(RESET)
- TIM16_IRQHandler from startup_stm32f042x6.o(.text) referenced from startup_stm32f042x6.o(RESET)
- TIM17_IRQHandler from startup_stm32f042x6.o(.text) referenced from startup_stm32f042x6.o(RESET)
- TIM1_BRK_UP_TRG_COM_IRQHandler from startup_stm32f042x6.o(.text) referenced from startup_stm32f042x6.o(RESET)
- TIM1_CC_IRQHandler from startup_stm32f042x6.o(.text) referenced from startup_stm32f042x6.o(RESET)
- TIM2_IRQHandler from startup_stm32f042x6.o(.text) referenced from startup_stm32f042x6.o(RESET)
- TIM3_IRQHandler from startup_stm32f042x6.o(.text) referenced from startup_stm32f042x6.o(RESET)
- TSC_IRQHandler from startup_stm32f042x6.o(.text) referenced from startup_stm32f042x6.o(RESET)
- USART1_IRQHandler from startup_stm32f042x6.o(.text) referenced from startup_stm32f042x6.o(RESET)
- USART2_IRQHandler from startup_stm32f042x6.o(.text) referenced from startup_stm32f042x6.o(RESET)
- USB_IRQHandler from startup_stm32f042x6.o(.text) referenced from startup_stm32f042x6.o(RESET)
- WWDG_IRQHandler from startup_stm32f042x6.o(.text) referenced from startup_stm32f042x6.o(RESET)
- __main from entry.o(.ARM.Collect$$$$00000000) referenced from startup_stm32f042x6.o(.text)
- main from main.o(i.main) referenced from entry9a.o(.ARM.Collect$$$$0000000B)

### Global Symbols

__main (Thumb, 0 bytes, Stack size unknown bytes, entry.o(.ARM.Collect$$$$00000000))
[Address Reference Count : 1]

- startup_stm32f042x6.o(.text)

_main_stk (Thumb, 0 bytes, Stack size unknown bytes, entry2.o(.ARM.Collect$$$$00000001))

_main_scatterload (Thumb, 0 bytes, Stack size unknown bytes, entry5.o(.ARM.Collect$$$$00000004))

[Calls]

- >> __scatterload

__main_after_scatterload (Thumb, 0 bytes, Stack size unknown bytes, entry5.o(.ARM.Collect$$$$00000004))

[Called By]

- >> __scatterload

_main_clock (Thumb, 0 bytes, Stack size unknown bytes, entry7b.o(.ARM.Collect$$$$00000008))

_main_cpp_init (Thumb, 0 bytes, Stack size unknown bytes, entry8b.o(.ARM.Collect$$$$0000000A))

_main_init (Thumb, 0 bytes, Stack size unknown bytes, entry9a.o(.ARM.Collect$$$$0000000B))

__rt_final_cpp (Thumb, 0 bytes, Stack size unknown bytes, entry10a.o(.ARM.Collect$$$$0000000D))

__rt_final_exit (Thumb, 0 bytes, Stack size unknown bytes, entry11a.o(.ARM.Collect$$$$0000000F))

Reset_Handler (Thumb, 38 bytes, Stack size 0 bytes, startup_stm32f042x6.o(.text))
[Address Reference Count : 1]

- startup_stm32f042x6.o(RESET)

ADC1_IRQHandler (Thumb, 0 bytes, Stack size 0 bytes, startup_stm32f042x6.o(.text))

[Calls]

- >> ADC1_IRQHandler

[Called By]

- >> ADC1_IRQHandler

[Address Reference Count : 1]

- startup_stm32f042x6.o(RESET)

CEC_CAN_IRQHandler (Thumb, 0 bytes, Stack size 0 bytes, startup_stm32f042x6.o(.text))
[Address Reference Count : 1]

- startup_stm32f042x6.o(RESET)

DMA1_Channel1_IRQHandler (Thumb, 0 bytes, Stack size 0 bytes, startup_stm32f042x6.o(.text))
[Address Reference Count : 1]

- startup_stm32f042x6.o(RESET)

DMA1_Channel2_3_IRQHandler (Thumb, 0 bytes, Stack size 0 bytes, startup_stm32f042x6.o(.text))
[Address Reference Count : 1]

- startup_stm32f042x6.o(RESET)

DMA1_Channel4_5_IRQHandler (Thumb, 0 bytes, Stack size 0 bytes, startup_stm32f042x6.o(.text))
[Address Reference Count : 1]

- startup_stm32f042x6.o(RESET)

EXTI0_1_IRQHandler (Thumb, 0 bytes, Stack size 0 bytes, startup_stm32f042x6.o(.text))
[Address Reference Count : 1]

- startup_stm32f042x6.o(RESET)

EXTI2_3_IRQHandler (Thumb, 0 bytes, Stack size 0 bytes, startup_stm32f042x6.o(.text))
[Address Reference Count : 1]

- startup_stm32f042x6.o(RESET)

EXTI4_15_IRQHandler (Thumb, 0 bytes, Stack size 0 bytes, startup_stm32f042x6.o(.text))
[Address Reference Count : 1]

- startup_stm32f042x6.o(RESET)

FLASH_IRQHandler (Thumb, 0 bytes, Stack size 0 bytes, startup_stm32f042x6.o(.text))
[Address Reference Count : 1]

- startup_stm32f042x6.o(RESET)

I2C1_IRQHandler (Thumb, 0 bytes, Stack size 0 bytes, startup_stm32f042x6.o(.text))
[Address Reference Count : 1]

- startup_stm32f042x6.o(RESET)

PVD_VDDIO2_IRQHandler (Thumb, 0 bytes, Stack size 0 bytes, startup_stm32f042x6.o(.text))
[Address Reference Count : 1]

- startup_stm32f042x6.o(RESET)

RCC_CRS_IRQHandler (Thumb, 0 bytes, Stack size 0 bytes, startup_stm32f042x6.o(.text))
[Address Reference Count : 1]

- startup_stm32f042x6.o(RESET)

RTC_IRQHandler (Thumb, 0 bytes, Stack size 0 bytes, startup_stm32f042x6.o(.text))
[Address Reference Count : 1]

- startup_stm32f042x6.o(RESET)

SPI1_IRQHandler (Thumb, 0 bytes, Stack size 0 bytes, startup_stm32f042x6.o(.text))
[Address Reference Count : 1]

- startup_stm32f042x6.o(RESET)

SPI2_IRQHandler (Thumb, 0 bytes, Stack size 0 bytes, startup_stm32f042x6.o(.text))
[Address Reference Count : 1]

- startup_stm32f042x6.o(RESET)

TIM14_IRQHandler (Thumb, 0 bytes, Stack size 0 bytes, startup_stm32f042x6.o(.text))
[Address Reference Count : 1]

- startup_stm32f042x6.o(RESET)

TIM16_IRQHandler (Thumb, 0 bytes, Stack size 0 bytes, startup_stm32f042x6.o(.text))
[Address Reference Count : 1]

- startup_stm32f042x6.o(RESET)

TIM17_IRQHandler (Thumb, 0 bytes, Stack size 0 bytes, startup_stm32f042x6.o(.text))
[Address Reference Count : 1]

- startup_stm32f042x6.o(RESET)

TIM1_BRK_UP_TRG_COM_IRQHandler (Thumb, 0 bytes, Stack size 0 bytes, startup_stm32f042x6.o(.text))
[Address Reference Count : 1]

- startup_stm32f042x6.o(RESET)

TIM1_CC_IRQHandler (Thumb, 0 bytes, Stack size 0 bytes, startup_stm32f042x6.o(.text))
[Address Reference Count : 1]

- startup_stm32f042x6.o(RESET)

TIM2_IRQHandler (Thumb, 0 bytes, Stack size 0 bytes, startup_stm32f042x6.o(.text))
[Address Reference Count : 1]

- startup_stm32f042x6.o(RESET)

TIM3_IRQHandler (Thumb, 0 bytes, Stack size 0 bytes, startup_stm32f042x6.o(.text))
[Address Reference Count : 1]

- startup_stm32f042x6.o(RESET)

TSC_IRQHandler (Thumb, 0 bytes, Stack size 0 bytes, startup_stm32f042x6.o(.text))
[Address Reference Count : 1]

- startup_stm32f042x6.o(RESET)

USART1_IRQHandler (Thumb, 0 bytes, Stack size 0 bytes, startup_stm32f042x6.o(.text))
[Address Reference Count : 1]

- startup_stm32f042x6.o(RESET)

USART2_IRQHandler (Thumb, 0 bytes, Stack size 0 bytes, startup_stm32f042x6.o(.text))
[Address Reference Count : 1]

- startup_stm32f042x6.o(RESET)

USB_IRQHandler (Thumb, 0 bytes, Stack size 0 bytes, startup_stm32f042x6.o(.text))
[Address Reference Count : 1]

- startup_stm32f042x6.o(RESET)

WWDG_IRQHandler (Thumb, 0 bytes, Stack size 0 bytes, startup_stm32f042x6.o(.text))
[Address Reference Count : 1]

- startup_stm32f042x6.o(RESET)

__aeabi_uidiv (Thumb, 0 bytes, Stack size 12 bytes, uidiv.o(.text), UNUSED)

__aeabi_uidivmod (Thumb, 44 bytes, Stack size 12 bytes, uidiv.o(.text))

[Stack]

- Max Depth = 12
- Call Chain = __aeabi_uidivmod

[Called By]

- >> SystemClock_Config
- >> HAL_InitTick
- >> HAL_RCC_GetSysClockFreq
- >> UART_SetConfig

__scatterload (Thumb, 28 bytes, Stack size 0 bytes, init.o(.text))

[Calls]

- >> __main_after_scatterload

[Called By]

- >> _main_scatterload

__scatterload_rt2 (Thumb, 0 bytes, Stack size 0 bytes, init.o(.text), UNUSED)

HAL_Delay (Thumb, 28 bytes, Stack size 16 bytes, stm32f0xx_hal.o(i.HAL_Delay))

[Stack]

- Max Depth = 16
- Call Chain = HAL_Delay

[Calls]

- >> HAL_GetTick

[Called By]

- >> main

HAL_GPIO_Init (Thumb, 294 bytes, Stack size 24 bytes, stm32f0xx_hal_gpio.o(i.HAL_GPIO_Init))

[Stack]

- Max Depth = 24
- Call Chain = HAL_GPIO_Init

[Called By]

- >> HAL_UART_MspInit
- >> MX_GPIO_Init

HAL_GPIO_TogglePin (Thumb, 8 bytes, Stack size 0 bytes, stm32f0xx_hal_gpio.o(i.HAL_GPIO_TogglePin))

[Called By]

- >> main

HAL_GPIO_WritePin (Thumb, 12 bytes, Stack size 0 bytes, stm32f0xx_hal_gpio.o(i.HAL_GPIO_WritePin))

[Called By]

- >> MX_GPIO_Init

HAL_GetTick (Thumb, 6 bytes, Stack size 0 bytes, stm32f0xx_hal.o(i.HAL_GetTick))

[Called By]

- >> HAL_RCC_OscConfig
- >> HAL_RCC_ClockConfig
- >> HAL_Delay
- >> UART_WaitOnFlagUntilTimeout
- >> UART_CheckIdleState

HAL_HalfDuplex_Init (Thumb, 118 bytes, Stack size 16 bytes, stm32f0xx_hal_uart.o(i.HAL_HalfDuplex_Init))

[Stack]

- Max Depth = 100
- Call Chain = HAL_HalfDuplex_Init ⇒ UART_SetConfig ⇒ HAL_RCC_GetSysClockFreq ⇒ __aeabi_uidivmod

[Calls]

- >> HAL_UART_MspInit
- >> UART_SetConfig
- >> UART_CheckIdleState
- >> UART_AdvFeatureConfig

[Called By]

- >> MX_USART2_UART_Init

HAL_IncTick (Thumb, 10 bytes, Stack size 0 bytes, stm32f0xx_hal.o(i.HAL_IncTick))

[Called By]

- >> SysTick_Handler

HAL_Init (Thumb, 26 bytes, Stack size 8 bytes, stm32f0xx_hal.o(i.HAL_Init))

[Stack]

- Max Depth = 28
- Call Chain = HAL_Init ⇒ HAL_InitTick ⇒ __aeabi_uidivmod

[Calls]

- >> HAL_MspInit
- >> HAL_InitTick

[Called By]

- >> main

HAL_InitTick (Thumb, 34 bytes, Stack size 8 bytes, stm32f0xx_hal.o(i.HAL_InitTick))

[Stack]

- Max Depth = 20
- Call Chain = HAL_InitTick ⇒ __aeabi_uidivmod

[Calls]

- >> HAL_SYSTICK_Config
- >> HAL_RCC_GetHCLKFreq
- >> HAL_NVIC_SetPriority
- >> __aeabi_uidivmod

[Called By]

- >> HAL_RCC_ClockConfig
- >> HAL_Init

HAL_MspInit (Thumb, 74 bytes, Stack size 8 bytes, stm32f0xx_hal_msp.o(i.HAL_MspInit))

[Stack]

- Max Depth = 16
- Call Chain = HAL_MspInit ⇒ HAL_NVIC_SetPriority

[Calls]

- >> HAL_NVIC_SetPriority

[Called By]

- >> HAL_Init

HAL_NVIC_SetPriority (Thumb, 8 bytes, Stack size 8 bytes, stm32f0xx_hal_cortex.o(i.HAL_NVIC_SetPriority))

[Stack]

- Max Depth = 8
- Call Chain = HAL_NVIC_SetPriority

[Calls]

- >> NVIC_SetPriority

[Called By]

- >> HAL_MspInit
- >> SystemClock_Config
- >> HAL_InitTick

HAL_RCC_ClockConfig (Thumb, 320 bytes, Stack size 24 bytes, stm32f0xx_hal_rcc.o(i.HAL_RCC_ClockConfig))

[Stack]

- Max Depth = 84
- Call Chain = HAL_RCC_ClockConfig ⇒ HAL_RCC_GetSysClockFreq ⇒ __aeabi_uidivmod

[Calls]

- >> HAL_InitTick
- >> HAL_RCC_GetSysClockFreq
- >> HAL_GetTick

[Called By]

- >> SystemClock_Config

HAL_RCC_GetHCLKFreq (Thumb, 6 bytes, Stack size 0 bytes, stm32f0xx_hal_rcc.o(i.HAL_RCC_GetHCLKFreq))

[Called By]

- >> SystemClock_Config
- >> HAL_InitTick

HAL_RCC_GetPCLK1Freq (Thumb, 20 bytes, Stack size 0 bytes, stm32f0xx_hal_rcc.o(i.HAL_RCC_GetPCLK1Freq))

[Called By]

- >> UART_SetConfig

HAL_RCC_GetSysClockFreq (Thumb, 90 bytes, Stack size 48 bytes, stm32f0xx_hal_rcc.o(i.HAL_RCC_GetSysClockFreq))

[Stack]

- Max Depth = 60
- Call Chain = HAL_RCC_GetSysClockFreq ⇒ __aeabi_uidivmod

[Calls]

- >> __aeabi_uidivmod

[Called By]

- >> HAL_RCC_ClockConfig
- >> UART_SetConfig

HAL_RCC_OscConfig (Thumb, 966 bytes, Stack size 32 bytes, stm32f0xx_hal_rcc.o(i.HAL_RCC_OscConfig))

[Stack]

- Max Depth = 32
- Call Chain = HAL_RCC_OscConfig

[Calls]

- >> HAL_GetTick

[Called By]

- >> SystemClock_Config

HAL_SYSTICK_CLKSourceConfig (Thumb, 20 bytes, Stack size 0 bytes, stm32f0xx_hal_cortex.o(i.HAL_SYSTICK_CLKSourceConfig))

[Called By]

- >> SystemClock_Config

HAL_SYSTICK_Callback (Thumb, 2 bytes, Stack size 0 bytes, stm32f0xx_hal_cortex.o(i.HAL_SYSTICK_Callback))

[Called By]

- >> HAL_SYSTICK_IRQHandler

HAL_SYSTICK_Config (Thumb, 38 bytes, Stack size 8 bytes, stm32f0xx_hal_cortex.o(i.HAL_SYSTICK_Config))

[Stack]

- Max Depth = 8
- Call Chain = HAL_SYSTICK_Config

[Calls]

- >> NVIC_SetPriority

[Called By]

- >> SystemClock_Config
- >> HAL_InitTick

HAL_SYSTICK_IRQHandler (Thumb, 8 bytes, Stack size 8 bytes, stm32f0xx_hal_cortex.o(i.HAL_SYSTICK_IRQHandler))

[Stack]

- Max Depth = 8
- Call Chain = HAL_SYSTICK_IRQHandler

[Calls]

- >> HAL_SYSTICK_Callback

[Called By]

- >> SysTick_Handler

HAL_TIMEx_MasterConfigSynchronization (Thumb, 72 bytes, Stack size 16 bytes, stm32f0xx_hal_tim_ex.o(i.HAL_TIMEx_MasterConfigSynchronization))

[Stack]

- Max Depth = 16
- Call Chain = HAL_TIMEx_MasterConfigSynchronization

[Called By]

- >> MX_TIM2_Init

HAL_TIM_Base_Init (Thumb, 52 bytes, Stack size 16 bytes, stm32f0xx_hal_tim.o(i.HAL_TIM_Base_Init))

[Stack]

- Max Depth = 36
- Call Chain = HAL_TIM_Base_Init ⇒ TIM_Base_SetConfig

[Calls]

- >> HAL_TIM_Base_MspInit
- >> TIM_Base_SetConfig

[Called By]

- >> MX_TIM2_Init

HAL_TIM_Base_MspInit (Thumb, 30 bytes, Stack size 8 bytes, stm32f0xx_hal_msp.o(i.HAL_TIM_Base_MspInit))

[Stack]

- Max Depth = 8
- Call Chain = HAL_TIM_Base_MspInit

[Called By]

- >> HAL_TIM_Base_Init

HAL_TIM_ConfigClockSource (Thumb, 238 bytes, Stack size 24 bytes, stm32f0xx_hal_tim.o(i.HAL_TIM_ConfigClockSource))

[Stack]

- Max Depth = 36
- Call Chain = HAL_TIM_ConfigClockSource ⇒ TIM_TI2_ConfigInputStage

[Calls]

- >> TIM_TI2_ConfigInputStage
- >> TIM_TI1_ConfigInputStage
- >> TIM_ITRx_SetConfig
- >> TIM_ETR_SetConfig

[Called By]

- >> MX_TIM2_Init

HAL_UART_MspInit (Thumb, 62 bytes, Stack size 32 bytes, stm32f0xx_hal_msp.o(i.HAL_UART_MspInit))

[Stack]

- Max Depth = 56
- Call Chain = HAL_UART_MspInit ⇒ HAL_GPIO_Init

[Calls]

- >> HAL_GPIO_Init

[Called By]

- >> HAL_HalfDuplex_Init

HardFault_Handler (Thumb, 2 bytes, Stack size 0 bytes, stm32f0xx_it.o(i.HardFault_Handler))

[Calls]

- >> HardFault_Handler

[Called By]

- >> HardFault_Handler

[Address Reference Count : 1]

- startup_stm32f042x6.o(RESET)

NMI_Handler (Thumb, 2 bytes, Stack size 0 bytes, stm32f0xx_it.o(i.NMI_Handler))
[Address Reference Count : 1]

- startup_stm32f042x6.o(RESET)

PendSV_Handler (Thumb, 2 bytes, Stack size 0 bytes, stm32f0xx_it.o(i.PendSV_Handler))
[Address Reference Count : 1]

- startup_stm32f042x6.o(RESET)

SVC_Handler (Thumb, 2 bytes, Stack size 0 bytes, stm32f0xx_it.o(i.SVC_Handler))
[Address Reference Count : 1]

- startup_stm32f042x6.o(RESET)

SysTick_Handler (Thumb, 12 bytes, Stack size 8 bytes, stm32f0xx_it.o(i.SysTick_Handler))

[Stack]

- Max Depth = 16
- Call Chain = SysTick_Handler ⇒ HAL_SYSTICK_IRQHandler

[Calls]

- >> HAL_SYSTICK_IRQHandler
- >> HAL_IncTick

[Address Reference Count : 1]

- startup_stm32f042x6.o(RESET)

SystemClock_Config (Thumb, 90 bytes, Stack size 80 bytes, main.o(i.SystemClock_Config))

[Stack]

- Max Depth = 164
- Call Chain = SystemClock_Config ⇒ HAL_RCC_ClockConfig ⇒ HAL_RCC_GetSysClockFreq ⇒ __aeabi_uidivmod

[Calls]

- >> HAL_SYSTICK_Config
- >> HAL_SYSTICK_CLKSourceConfig
- >> HAL_RCC_OscConfig
- >> HAL_RCC_GetHCLKFreq
- >> HAL_RCC_ClockConfig
- >> HAL_NVIC_SetPriority
- >> __aeabi_uidivmod

[Called By]

- >> main

SystemInit (Thumb, 78 bytes, Stack size 0 bytes, system_stm32f0xx.o(i.SystemInit))
[Address Reference Count : 1]

- startup_stm32f042x6.o(.text)

TIM_Base_SetConfig (Thumb, 112 bytes, Stack size 20 bytes, stm32f0xx_hal_tim.o(i.TIM_Base_SetConfig))

[Stack]

- Max Depth = 20
- Call Chain = TIM_Base_SetConfig

[Called By]

- >> HAL_TIM_Base_Init

TIM_ETR_SetConfig (Thumb, 22 bytes, Stack size 12 bytes, stm32f0xx_hal_tim.o(i.TIM_ETR_SetConfig))

[Stack]

- Max Depth = 12
- Call Chain = TIM_ETR_SetConfig

[Called By]

- >> HAL_TIM_ConfigClockSource

UART_AdvFeatureConfig (Thumb, 202 bytes, Stack size 8 bytes, stm32f0xx_hal_uart.o(i.UART_AdvFeatureConfig))

[Stack]

- Max Depth = 8
- Call Chain = UART_AdvFeatureConfig

[Called By]

- >> HAL_HalfDuplex_Init

UART_CheckIdleState (Thumb, 96 bytes, Stack size 24 bytes, stm32f0xx_hal_uart.o(i.UART_CheckIdleState))

[Stack]

- Max Depth = 64
- Call Chain = UART_CheckIdleState ⇒ UART_WaitOnFlagUntilTimeout

[Calls]

- >> HAL_GetTick
- >> UART_WaitOnFlagUntilTimeout

[Called By]

- >> HAL_HalfDuplex_Init

UART_SetConfig (Thumb, 280 bytes, Stack size 24 bytes, stm32f0xx_hal_uart.o(i.UART_SetConfig))

[Stack]

- Max Depth = 84
- Call Chain = UART_SetConfig ⇒ HAL_RCC_GetSysClockFreq ⇒ __aeabi_uidivmod

[Calls]

- >> HAL_RCC_GetSysClockFreq
- >> HAL_RCC_GetPCLK1Freq
- >> __aeabi_uidivmod

[Called By]

- >> HAL_HalfDuplex_Init

UART_WaitOnFlagUntilTimeout (Thumb, 98 bytes, Stack size 40 bytes, stm32f0xx_hal_uart.o(i.UART_WaitOnFlagUntilTimeout))

[Stack]

- Max Depth = 40
- Call Chain = UART_WaitOnFlagUntilTimeout

[Calls]

- >> HAL_GetTick

[Called By]

- >> UART_CheckIdleState

__scatterload_copy (Thumb, 14 bytes, Stack size unknown bytes, handlers.o(i.__scatterload_copy), UNUSED)

__scatterload_null (Thumb, 2 bytes, Stack size unknown bytes, handlers.o(i.__scatterload_null), UNUSED)

__scatterload_zeroinit (Thumb, 14 bytes, Stack size unknown bytes, handlers.o(i.__scatterload_zeroinit), UNUSED)

main (Thumb, 78 bytes, Stack size 0 bytes, main.o(i.main))

[Stack]

- Max Depth = 164
- Call Chain = main ⇒ SystemClock_Config ⇒ HAL_RCC_ClockConfig ⇒ HAL_RCC_GetSysClockFreq ⇒ __aeabi_uidivmod

[Calls]

- >> HAL_Init
- >> HAL_GPIO_TogglePin
- >> HAL_Delay
- >> SystemClock_Config
- >> MX_USART2_UART_Init
- >> MX_TIM2_Init
- >> MX_GPIO_Init

[Address Reference Count : 1]

- entry9a.o(.ARM.Collect$$$$0000000B)

### Local Symbols

MX_GPIO_Init (Thumb, 126 bytes, Stack size 48 bytes, main.o(i.MX_GPIO_Init))

[Stack]

- Max Depth = 72
- Call Chain = MX_GPIO_Init ⇒ HAL_GPIO_Init

[Calls]

- >> HAL_GPIO_WritePin
- >> HAL_GPIO_Init

[Called By]

- >> main

MX_TIM2_Init (Thumb, 80 bytes, Stack size 32 bytes, main.o(i.MX_TIM2_Init))

[Stack]

- Max Depth = 68
- Call Chain = MX_TIM2_Init ⇒ HAL_TIM_ConfigClockSource ⇒ TIM_TI2_ConfigInputStage

[Calls]

- >> HAL_TIM_ConfigClockSource
- >> HAL_TIM_Base_Init
- >> HAL_TIMEx_MasterConfigSynchronization

[Called By]

- >> main

MX_USART2_UART_Init (Thumb, 46 bytes, Stack size 8 bytes, main.o(i.MX_USART2_UART_Init))

[Stack]

- Max Depth = 108
- Call Chain = MX_USART2_UART_Init ⇒ HAL_HalfDuplex_Init ⇒ UART_SetConfig ⇒ HAL_RCC_GetSysClockFreq ⇒ __aeabi_uidivmod

[Calls]

- >> HAL_HalfDuplex_Init

[Called By]

- >> main

TIM_ITRx_SetConfig (Thumb, 16 bytes, Stack size 0 bytes, stm32f0xx_hal_tim.o(i.TIM_ITRx_SetConfig))

[Called By]

- >> HAL_TIM_ConfigClockSource

TIM_TI1_ConfigInputStage (Thumb, 34 bytes, Stack size 12 bytes, stm32f0xx_hal_tim.o(i.TIM_TI1_ConfigInputStage))

[Stack]

- Max Depth = 12
- Call Chain = TIM_TI1_ConfigInputStage

[Called By]

- >> HAL_TIM_ConfigClockSource

TIM_TI2_ConfigInputStage (Thumb, 38 bytes, Stack size 12 bytes, stm32f0xx_hal_tim.o(i.TIM_TI2_ConfigInputStage))

[Stack]

- Max Depth = 12
- Call Chain = TIM_TI2_ConfigInputStage

[Called By]

- >> HAL_TIM_ConfigClockSource

NVIC_SetPriority (Thumb, 60 bytes, Stack size 0 bytes, stm32f0xx_hal_cortex.o(i.NVIC_SetPriority))

[Called By]

- >> HAL_SYSTICK_Config
- >> HAL_NVIC_SetPriority

### Undefined Global Symbols

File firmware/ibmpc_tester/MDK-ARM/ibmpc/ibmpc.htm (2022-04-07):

# Static Call Graph for image ibmpc\ibmpc.axf

#<CALLGRAPH># ARM Linker, 5060750: Last Updated: Thu Apr 07 02:15:20 2022

### Maximum Stack Usage = 196 bytes + Unknown(Cycles, Untraceable Function Pointers)

### Call chain for Maximum Stack Depth:

main ⇒ SystemClock_Config ⇒ HAL_RCC_ClockConfig ⇒ HAL_RCC_GetSysClockFreq ⇒ __aeabi_uidivmod

### Mutually Recursive functions

- ADC1_COMP_IRQHandler ⇒ ADC1_COMP_IRQHandler
- HardFault_Handler ⇒ HardFault_Handler

### Function Pointers

- ADC1_COMP_IRQHandler from startup_stm32f072xb.o(.text) referenced from startup_stm32f072xb.o(RESET)
- CEC_CAN_IRQHandler from startup_stm32f072xb.o(.text) referenced from startup_stm32f072xb.o(RESET)
- DMA1_Channel1_IRQHandler from startup_stm32f072xb.o(.text) referenced from startup_stm32f072xb.o(RESET)
- DMA1_Channel2_3_IRQHandler from startup_stm32f072xb.o(.text) referenced from startup_stm32f072xb.o(RESET)
- DMA1_Channel4_5_6_7_IRQHandler from startup_stm32f072xb.o(.text) referenced from startup_stm32f072xb.o(RESET)
- EXTI0_1_IRQHandler from startup_stm32f072xb.o(.text) referenced from startup_stm32f072xb.o(RESET)
- EXTI2_3_IRQHandler from startup_stm32f072xb.o(.text) referenced from startup_stm32f072xb.o(RESET)
- EXTI4_15_IRQHandler from startup_stm32f072xb.o(.text) referenced from startup_stm32f072xb.o(RESET)
- FLASH_IRQHandler from startup_stm32f072xb.o(.text) referenced from startup_stm32f072xb.o(RESET)
- HardFault_Handler from stm32f0xx_it.o(i.HardFault_Handler) referenced from startup_stm32f072xb.o(RESET)
- I2C1_IRQHandler from startup_stm32f072xb.o(.text) referenced from startup_stm32f072xb.o(RESET)
- I2C2_IRQHandler from startup_stm32f072xb.o(.text) referenced from startup_stm32f072xb.o(RESET)
- NMI_Handler from stm32f0xx_it.o(i.NMI_Handler) referenced from startup_stm32f072xb.o(RESET)
- PVD_VDDIO2_IRQHandler from startup_stm32f072xb.o(.text) referenced from startup_stm32f072xb.o(RESET)
- PendSV_Handler from stm32f0xx_it.o(i.PendSV_Handler) referenced from startup_stm32f072xb.o(RESET)
- RCC_CRS_IRQHandler from startup_stm32f072xb.o(.text) referenced from startup_stm32f072xb.o(RESET)
- RTC_IRQHandler from startup_stm32f072xb.o(.text) referenced from startup_stm32f072xb.o(RESET)
- Reset_Handler from startup_stm32f072xb.o(.text) referenced from startup_stm32f072xb.o(RESET)
- SPI1_IRQHandler from startup_stm32f072xb.o(.text) referenced from startup_stm32f072xb.o(RESET)
- SPI2_IRQHandler from startup_stm32f072xb.o(.text) referenced from startup_stm32f072xb.o(RESET)
- SVC_Handler from stm32f0xx_it.o(i.SVC_Handler) referenced from startup_stm32f072xb.o(RESET)
- SysTick_Handler from stm32f0xx_it.o(i.SysTick_Handler) referenced from startup_stm32f072xb.o(RESET)
- SystemInit from system_stm32f0xx.o(i.SystemInit) referenced from startup_stm32f072xb.o(.text)
- TIM14_IRQHandler from startup_stm32f072xb.o(.text) referenced from startup_stm32f072xb.o(RESET)
- TIM15_IRQHandler from startup_stm32f072xb.o(.text) referenced from startup_stm32f072xb.o(RESET)
- TIM16_IRQHandler from startup_stm32f072xb.o(.text) referenced from startup_stm32f072xb.o(RESET)
- TIM17_IRQHandler from startup_stm32f072xb.o(.text) referenced from startup_stm32f072xb.o(RESET)
- TIM1_BRK_UP_TRG_COM_IRQHandler from startup_stm32f072xb.o(.text) referenced from startup_stm32f072xb.o(RESET)
- TIM1_CC_IRQHandler from startup_stm32f072xb.o(.text) referenced from startup_stm32f072xb.o(RESET)
- TIM2_IRQHandler from startup_stm32f072xb.o(.text) referenced from startup_stm32f072xb.o(RESET)
- TIM3_IRQHandler from startup_stm32f072xb.o(.text) referenced from startup_stm32f072xb.o(RESET)
- TIM6_DAC_IRQHandler from startup_stm32f072xb.o(.text) referenced from startup_stm32f072xb.o(RESET)
- TIM7_IRQHandler from startup_stm32f072xb.o(.text) referenced from startup_stm32f072xb.o(RESET)
- TSC_IRQHandler from startup_stm32f072xb.o(.text) referenced from startup_stm32f072xb.o(RESET)
- USART1_IRQHandler from startup_stm32f072xb.o(.text) referenced from startup_stm32f072xb.o(RESET)
- USART2_IRQHandler from startup_stm32f072xb.o(.text) referenced from startup_stm32f072xb.o(RESET)
- USART3_4_IRQHandler from startup_stm32f072xb.o(.text) referenced from startup_stm32f072xb.o(RESET)
- USB_IRQHandler from startup_stm32f072xb.o(.text) referenced from startup_stm32f072xb.o(RESET)
- WWDG_IRQHandler from startup_stm32f072xb.o(.text) referenced from startup_stm32f072xb.o(RESET)
- __main from entry.o(.ARM.Collect$$$$00000000) referenced from startup_stm32f072xb.o(.text)
- fputc from main.o(i.fputc) referenced from printfb.o(i.__0printf$bare)
- main from main.o(i.main) referenced from entry9a.o(.ARM.Collect$$$$0000000B)

### Global Symbols

__main (Thumb, 0 bytes, Stack size unknown bytes, entry.o(.ARM.Collect$$$$00000000))
[Address Reference Count : 1]

- startup_stm32f072xb.o(.text)

_main_stk (Thumb, 0 bytes, Stack size unknown bytes, entry2.o(.ARM.Collect$$$$00000001))

_main_scatterload (Thumb, 0 bytes, Stack size unknown bytes, entry5.o(.ARM.Collect$$$$00000004))

[Calls]

- >> __scatterload

__main_after_scatterload (Thumb, 0 bytes, Stack size unknown bytes, entry5.o(.ARM.Collect$$$$00000004))

[Called By]

- >> __scatterload

_main_clock (Thumb, 0 bytes, Stack size unknown bytes, entry7b.o(.ARM.Collect$$$$00000008))

_main_cpp_init (Thumb, 0 bytes, Stack size unknown bytes, entry8b.o(.ARM.Collect$$$$0000000A))

_main_init (Thumb, 0 bytes, Stack size unknown bytes, entry9a.o(.ARM.Collect$$$$0000000B))

__rt_final_cpp (Thumb, 0 bytes, Stack size unknown bytes, entry10a.o(.ARM.Collect$$$$0000000D))

__rt_final_exit (Thumb, 0 bytes, Stack size unknown bytes, entry11a.o(.ARM.Collect$$$$0000000F))

Reset_Handler (Thumb, 8 bytes, Stack size 0 bytes, startup_stm32f072xb.o(.text))
[Address Reference Count : 1]

- startup_stm32f072xb.o(RESET)

ADC1_COMP_IRQHandler (Thumb, 0 bytes, Stack size 0 bytes, startup_stm32f072xb.o(.text))

[Calls]

- >> ADC1_COMP_IRQHandler

[Called By]

- >> ADC1_COMP_IRQHandler

[Address Reference Count : 1]

- startup_stm32f072xb.o(RESET)

CEC_CAN_IRQHandler (Thumb, 0 bytes, Stack size 0 bytes, startup_stm32f072xb.o(.text))
[Address Reference Count : 1]

- startup_stm32f072xb.o(RESET)

DMA1_Channel1_IRQHandler (Thumb, 0 bytes, Stack size 0 bytes, startup_stm32f072xb.o(.text))
[Address Reference Count : 1]

- startup_stm32f072xb.o(RESET)

DMA1_Channel2_3_IRQHandler (Thumb, 0 bytes, Stack size 0 bytes, startup_stm32f072xb.o(.text))
[Address Reference Count : 1]

- startup_stm32f072xb.o(RESET)

DMA1_Channel4_5_6_7_IRQHandler (Thumb, 0 bytes, Stack size 0 bytes, startup_stm32f072xb.o(.text))
[Address Reference Count : 1]

- startup_stm32f072xb.o(RESET)

EXTI0_1_IRQHandler (Thumb, 0 bytes, Stack size 0 bytes, startup_stm32f072xb.o(.text))
[Address Reference Count : 1]

- startup_stm32f072xb.o(RESET)

EXTI2_3_IRQHandler (Thumb, 0 bytes, Stack size 0 bytes, startup_stm32f072xb.o(.text))
[Address Reference Count : 1]

- startup_stm32f072xb.o(RESET)

EXTI4_15_IRQHandler (Thumb, 0 bytes, Stack size 0 bytes, startup_stm32f072xb.o(.text))
[Address Reference Count : 1]

- startup_stm32f072xb.o(RESET)

FLASH_IRQHandler (Thumb, 0 bytes, Stack size 0 bytes, startup_stm32f072xb.o(.text))
[Address Reference Count : 1]

- startup_stm32f072xb.o(RESET)

I2C1_IRQHandler (Thumb, 0 bytes, Stack size 0 bytes, startup_stm32f072xb.o(.text))
[Address Reference Count : 1]

- startup_stm32f072xb.o(RESET)

I2C2_IRQHandler (Thumb, 0 bytes, Stack size 0 bytes, startup_stm32f072xb.o(.text))
[Address Reference Count : 1]

- startup_stm32f072xb.o(RESET)

PVD_VDDIO2_IRQHandler (Thumb, 0 bytes, Stack size 0 bytes, startup_stm32f072xb.o(.text))
[Address Reference Count : 1]

- startup_stm32f072xb.o(RESET)

RCC_CRS_IRQHandler (Thumb, 0 bytes, Stack size 0 bytes, startup_stm32f072xb.o(.text))
[Address Reference Count : 1]

- startup_stm32f072xb.o(RESET)

RTC_IRQHandler (Thumb, 0 bytes, Stack size 0 bytes, startup_stm32f072xb.o(.text))
[Address Reference Count : 1]

- startup_stm32f072xb.o(RESET)

SPI1_IRQHandler (Thumb, 0 bytes, Stack size 0 bytes, startup_stm32f072xb.o(.text))
[Address Reference Count : 1]

- startup_stm32f072xb.o(RESET)

SPI2_IRQHandler (Thumb, 0 bytes, Stack size 0 bytes, startup_stm32f072xb.o(.text))
[Address Reference Count : 1]

- startup_stm32f072xb.o(RESET)

TIM14_IRQHandler (Thumb, 0 bytes, Stack size 0 bytes, startup_stm32f072xb.o(.text))
[Address Reference Count : 1]

- startup_stm32f072xb.o(RESET)

TIM15_IRQHandler (Thumb, 0 bytes, Stack size 0 bytes, startup_stm32f072xb.o(.text))
[Address Reference Count : 1]

- startup_stm32f072xb.o(RESET)

TIM16_IRQHandler (Thumb, 0 bytes, Stack size 0 bytes, startup_stm32f072xb.o(.text))
[Address Reference Count : 1]

- startup_stm32f072xb.o(RESET)

TIM17_IRQHandler (Thumb, 0 bytes, Stack size 0 bytes, startup_stm32f072xb.o(.text))
[Address Reference Count : 1]

- startup_stm32f072xb.o(RESET)

TIM1_BRK_UP_TRG_COM_IRQHandler (Thumb, 0 bytes, Stack size 0 bytes, startup_stm32f072xb.o(.text))
[Address Reference Count : 1]

- startup_stm32f072xb.o(RESET)

TIM1_CC_IRQHandler (Thumb, 0 bytes, Stack size 0 bytes, startup_stm32f072xb.o(.text))
[Address Reference Count : 1]

- startup_stm32f072xb.o(RESET)

TIM2_IRQHandler (Thumb, 0 bytes, Stack size 0 bytes, startup_stm32f072xb.o(.text))
[Address Reference Count : 1]

- startup_stm32f072xb.o(RESET)

TIM3_IRQHandler (Thumb, 0 bytes, Stack size 0 bytes, startup_stm32f072xb.o(.text))
[Address Reference Count : 1]

- startup_stm32f072xb.o(RESET)

TIM6_DAC_IRQHandler (Thumb, 0 bytes, Stack size 0 bytes, startup_stm32f072xb.o(.text))
[Address Reference Count : 1]

- startup_stm32f072xb.o(RESET)

TIM7_IRQHandler (Thumb, 0 bytes, Stack size 0 bytes, startup_stm32f072xb.o(.text))
[Address Reference Count : 1]

- startup_stm32f072xb.o(RESET)

TSC_IRQHandler (Thumb, 0 bytes, Stack size 0 bytes, startup_stm32f072xb.o(.text))
[Address Reference Count : 1]

- startup_stm32f072xb.o(RESET)

USART1_IRQHandler (Thumb, 0 bytes, Stack size 0 bytes, startup_stm32f072xb.o(.text))
[Address Reference Count : 1]

- startup_stm32f072xb.o(RESET)

USART2_IRQHandler (Thumb, 0 bytes, Stack size 0 bytes, startup_stm32f072xb.o(.text))
[Address Reference Count : 1]

- startup_stm32f072xb.o(RESET)

USART3_4_IRQHandler (Thumb, 0 bytes, Stack size 0 bytes, startup_stm32f072xb.o(.text))
[Address Reference Count : 1]

- startup_stm32f072xb.o(RESET)

USB_IRQHandler (Thumb, 0 bytes, Stack size 0 bytes, startup_stm32f072xb.o(.text))
[Address Reference Count : 1]

- startup_stm32f072xb.o(RESET)

WWDG_IRQHandler (Thumb, 0 bytes, Stack size 0 bytes, startup_stm32f072xb.o(.text))
[Address Reference Count : 1]

- startup_stm32f072xb.o(RESET)

__aeabi_uidiv (Thumb, 0 bytes, Stack size 12 bytes, uidiv.o(.text), UNUSED)

__aeabi_uidivmod (Thumb, 44 bytes, Stack size 12 bytes, uidiv.o(.text))

[Stack]

- Max Depth = 12
- Call Chain = __aeabi_uidivmod

[Called By]

- >> SystemClock_Config
- >> HAL_InitTick
- >> HAL_RCC_GetSysClockFreq
- >> UART_SetConfig

__scatterload (Thumb, 28 bytes, Stack size 0 bytes, init.o(.text))

[Calls]

- >> __main_after_scatterload

[Called By]

- >> _main_scatterload

__scatterload_rt2 (Thumb, 0 bytes, Stack size 0 bytes, init.o(.text), UNUSED)

HAL_Delay (Thumb, 28 bytes, Stack size 16 bytes, stm32f0xx_hal.o(i.HAL_Delay))

[Stack]

- Max Depth = 16
- Call Chain = HAL_Delay

[Calls]

- >> HAL_GetTick

[Called By]

- >> main
- >> check_i2c_error
- >> mcp4451_reset

HAL_GPIO_Init (Thumb, 314 bytes, Stack size 24 bytes, stm32f0xx_hal_gpio.o(i.HAL_GPIO_Init))

[Stack]

- Max Depth = 24
- Call Chain = HAL_GPIO_Init

[Called By]

- >> HAL_UART_MspInit
- >> HAL_I2C_MspInit
- >> MX_GPIO_Init

HAL_GPIO_TogglePin (Thumb, 8 bytes, Stack size 0 bytes, stm32f0xx_hal_gpio.o(i.HAL_GPIO_TogglePin))

[Called By]

- >> main
- >> check_i2c_error

HAL_GPIO_WritePin (Thumb, 12 bytes, Stack size 0 bytes, stm32f0xx_hal_gpio.o(i.HAL_GPIO_WritePin))

[Called By]

- >> MX_GPIO_Init
- >> mcp4451_reset

HAL_GetTick (Thumb, 6 bytes, Stack size 0 bytes, stm32f0xx_hal.o(i.HAL_GetTick))

[Called By]

- >> I2C_WaitOnTXISFlagUntilTimeout
- >> I2C_WaitOnSTOPFlagUntilTimeout
- >> I2C_WaitOnFlagUntilTimeout
- >> I2C_IsAcknowledgeFailed
- >> HAL_UART_Transmit
- >> HAL_RCC_OscConfig
- >> HAL_RCC_ClockConfig
- >> HAL_RCCEx_PeriphCLKConfig
- >> HAL_I2C_Mem_Write
- >> HAL_I2C_IsDeviceReady
- >> HAL_Delay
- >> UART_WaitOnFlagUntilTimeout
- >> UART_CheckIdleState

HAL_I2CEx_ConfigAnalogFilter (Thumb, 74 bytes, Stack size 16 bytes, stm32f0xx_hal_i2c_ex.o(i.HAL_I2CEx_ConfigAnalogFilter))

[Stack]

- Max Depth = 16
- Call Chain = HAL_I2CEx_ConfigAnalogFilter

[Called By]

- >> MX_I2C2_Init

HAL_I2CEx_ConfigDigitalFilter (Thumb, 72 bytes, Stack size 16 bytes, stm32f0xx_hal_i2c_ex.o(i.HAL_I2CEx_ConfigDigitalFilter))

[Stack]

- Max Depth = 16
- Call Chain = HAL_I2CEx_ConfigDigitalFilter

[Called By]

- >> MX_I2C2_Init

HAL_I2C_Init (Thumb, 176 bytes, Stack size 16 bytes, stm32f0xx_hal_i2c.o(i.HAL_I2C_Init))

[Stack]

- Max Depth = 72
- Call Chain = HAL_I2C_Init ⇒ HAL_I2C_MspInit ⇒ HAL_GPIO_Init

[Calls]

- >> HAL_I2C_MspInit

[Called By]

- >> MX_I2C2_Init

HAL_I2C_IsDeviceReady (Thumb, 280 bytes, Stack size 48 bytes, stm32f0xx_hal_i2c.o(i.HAL_I2C_IsDeviceReady))

[Stack]

- Max Depth = 72
- Call Chain = HAL_I2C_IsDeviceReady ⇒ I2C_WaitOnFlagUntilTimeout

[Calls]

- >> HAL_GetTick
- >> I2C_WaitOnFlagUntilTimeout

[Called By]

- >> mcp4451_is_available

HAL_I2C_Mem_Write (Thumb, 334 bytes, Stack size 48 bytes, stm32f0xx_hal_i2c.o(i.HAL_I2C_Mem_Write))

[Stack]

- Max Depth = 120
- Call Chain = HAL_I2C_Mem_Write ⇒ I2C_RequestMemoryWrite ⇒ I2C_WaitOnTXISFlagUntilTimeout ⇒ I2C_IsAcknowledgeFailed

[Calls]

- >> HAL_GetTick
- >> I2C_WaitOnTXISFlagUntilTimeout
- >> I2C_WaitOnSTOPFlagUntilTimeout
- >> I2C_WaitOnFlagUntilTimeout
- >> I2C_TransferConfig
- >> I2C_RequestMemoryWrite

[Called By]

- >> mcp4451_write_wiper

HAL_I2C_MspInit (Thumb, 64 bytes, Stack size 32 bytes, stm32f0xx_hal_msp.o(i.HAL_I2C_MspInit))

[Stack]

- Max Depth = 56
- Call Chain = HAL_I2C_MspInit ⇒ HAL_GPIO_Init

[Calls]

- >> HAL_GPIO_Init

[Called By]

- >> HAL_I2C_Init

HAL_IncTick (Thumb, 10 bytes, Stack size 0 bytes, stm32f0xx_hal.o(i.HAL_IncTick))

[Called By]

- >> SysTick_Handler

HAL_Init (Thumb, 26 bytes, Stack size 8 bytes, stm32f0xx_hal.o(i.HAL_Init))

[Stack]

- Max Depth = 28
- Call Chain = HAL_Init ⇒ HAL_InitTick ⇒ __aeabi_uidivmod

[Calls]

- >> HAL_MspInit
- >> HAL_InitTick

[Called By]

- >> main

HAL_InitTick (Thumb, 34 bytes, Stack size 8 bytes, stm32f0xx_hal.o(i.HAL_InitTick))

[Stack]

- Max Depth = 20
- Call Chain = HAL_InitTick ⇒ __aeabi_uidivmod

[Calls]

- >> HAL_SYSTICK_Config
- >> HAL_RCC_GetHCLKFreq
- >> HAL_NVIC_SetPriority
- >> __aeabi_uidivmod

[Called By]

- >> HAL_RCC_ClockConfig
- >> HAL_Init

HAL_MspInit (Thumb, 64 bytes, Stack size 8 bytes, stm32f0xx_hal_msp.o(i.HAL_MspInit))

[Stack]

- Max Depth = 16
- Call Chain = HAL_MspInit ⇒ HAL_NVIC_SetPriority

[Calls]

- >> HAL_NVIC_SetPriority

[Called By]

- >> HAL_Init

HAL_NVIC_SetPriority (Thumb, 8 bytes, Stack size 8 bytes, stm32f0xx_hal_cortex.o(i.HAL_NVIC_SetPriority))

[Stack]

- Max Depth = 8
- Call Chain = HAL_NVIC_SetPriority

[Calls]

- >> NVIC_SetPriority

[Called By]

- >> HAL_MspInit
- >> SystemClock_Config
- >> HAL_InitTick

HAL_RCCEx_PeriphCLKConfig (Thumb, 274 bytes, Stack size 24 bytes, stm32f0xx_hal_rcc_ex.o(i.HAL_RCCEx_PeriphCLKConfig))

[Stack]

- Max Depth = 24
- Call Chain = HAL_RCCEx_PeriphCLKConfig

[Calls]

- >> HAL_GetTick

[Called By]

- >> SystemClock_Config

HAL_RCC_ClockConfig (Thumb, 320 bytes, Stack size 24 bytes, stm32f0xx_hal_rcc.o(i.HAL_RCC_ClockConfig))

[Stack]

- Max Depth = 84
- Call Chain = HAL_RCC_ClockConfig ⇒ HAL_RCC_GetSysClockFreq ⇒ __aeabi_uidivmod

[Calls]

- >> HAL_GetTick
- >> HAL_InitTick
- >> HAL_RCC_GetSysClockFreq

[Called By]

- >> SystemClock_Config

HAL_RCC_GetHCLKFreq (Thumb, 6 bytes, Stack size 0 bytes, stm32f0xx_hal_rcc.o(i.HAL_RCC_GetHCLKFreq))

[Called By]

- >> SystemClock_Config
- >> HAL_InitTick

HAL_RCC_GetPCLK1Freq (Thumb, 20 bytes, Stack size 0 bytes, stm32f0xx_hal_rcc.o(i.HAL_RCC_GetPCLK1Freq))

[Called By]

- >> UART_SetConfig

HAL_RCC_GetSysClockFreq (Thumb, 90 bytes, Stack size 48 bytes, stm32f0xx_hal_rcc.o(i.HAL_RCC_GetSysClockFreq))

[Stack]

- Max Depth = 60
- Call Chain = HAL_RCC_GetSysClockFreq ⇒ __aeabi_uidivmod

[Calls]

- >> __aeabi_uidivmod

[Called By]

- >> HAL_RCC_ClockConfig
- >> UART_SetConfig

HAL_RCC_OscConfig (Thumb, 966 bytes, Stack size 32 bytes, stm32f0xx_hal_rcc.o(i.HAL_RCC_OscConfig))

[Stack]

- Max Depth = 32
- Call Chain = HAL_RCC_OscConfig

[Calls]

- >> HAL_GetTick

[Called By]

- >> SystemClock_Config

HAL_SYSTICK_CLKSourceConfig (Thumb, 20 bytes, Stack size 0 bytes, stm32f0xx_hal_cortex.o(i.HAL_SYSTICK_CLKSourceConfig))

[Called By]

- >> SystemClock_Config

HAL_SYSTICK_Callback (Thumb, 2 bytes, Stack size 0 bytes, stm32f0xx_hal_cortex.o(i.HAL_SYSTICK_Callback))

[Called By]

- >> HAL_SYSTICK_IRQHandler

HAL_SYSTICK_Config (Thumb, 38 bytes, Stack size 8 bytes, stm32f0xx_hal_cortex.o(i.HAL_SYSTICK_Config))

[Stack]

- Max Depth = 8
- Call Chain = HAL_SYSTICK_Config

[Calls]

- >> NVIC_SetPriority

[Called By]

- >> SystemClock_Config
- >> HAL_InitTick

HAL_SYSTICK_IRQHandler (Thumb, 8 bytes, Stack size 8 bytes, stm32f0xx_hal_cortex.o(i.HAL_SYSTICK_IRQHandler))

[Stack]

- Max Depth = 8
- Call Chain = HAL_SYSTICK_IRQHandler

[Calls]

- >> HAL_SYSTICK_Callback

[Called By]

- >> SysTick_Handler

HAL_UART_Init (Thumb, 108 bytes, Stack size 16 bytes, stm32f0xx_hal_uart.o(i.HAL_UART_Init))

[Stack]

- Max Depth = 100
- Call Chain = HAL_UART_Init ⇒ UART_SetConfig ⇒ HAL_RCC_GetSysClockFreq ⇒ __aeabi_uidivmod

[Calls]

- >> HAL_UART_MspInit
- >> UART_SetConfig
- >> UART_CheckIdleState
- >> UART_AdvFeatureConfig

[Called By]

- >> MX_USART1_UART_Init

HAL_UART_MspInit (Thumb, 66 bytes, Stack size 32 bytes, stm32f0xx_hal_msp.o(i.HAL_UART_MspInit))

[Stack]

- Max Depth = 56
- Call Chain = HAL_UART_MspInit ⇒ HAL_GPIO_Init

[Calls]

- >> HAL_GPIO_Init

[Called By]

- >> HAL_UART_Init

HAL_UART_Transmit (Thumb, 200 bytes, Stack size 48 bytes, stm32f0xx_hal_uart.o(i.HAL_UART_Transmit))

[Stack]

- Max Depth = 88
- Call Chain = HAL_UART_Transmit ⇒ UART_WaitOnFlagUntilTimeout

[Calls]

- >> HAL_GetTick
- >> UART_WaitOnFlagUntilTimeout

[Called By]

- >> fputc

HardFault_Handler (Thumb, 2 bytes, Stack size 0 bytes, stm32f0xx_it.o(i.HardFault_Handler))

[Calls]

- >> HardFault_Handler

[Called By]

- >> HardFault_Handler

[Address Reference Count : 1]

- startup_stm32f072xb.o(RESET)

NMI_Handler (Thumb, 2 bytes, Stack size 0 bytes, stm32f0xx_it.o(i.NMI_Handler))
[Address Reference Count : 1]

- startup_stm32f072xb.o(RESET)

PendSV_Handler (Thumb, 2 bytes, Stack size 0 bytes, stm32f0xx_it.o(i.PendSV_Handler))
[Address Reference Count : 1]

- startup_stm32f072xb.o(RESET)

SVC_Handler (Thumb, 2 bytes, Stack size 0 bytes, stm32f0xx_it.o(i.SVC_Handler))
[Address Reference Count : 1]

- startup_stm32f072xb.o(RESET)

SysTick_Handler (Thumb, 12 bytes, Stack size 8 bytes, stm32f0xx_it.o(i.SysTick_Handler))

[Stack]
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

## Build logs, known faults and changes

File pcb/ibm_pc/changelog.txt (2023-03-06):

20230306

added BUSY pin to A0
added current limit resistor on digital pot to prevent backfeeding

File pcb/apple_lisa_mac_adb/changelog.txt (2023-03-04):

pt1:
initial prototype

pt2:
wired up mouse connector
single rj11 socket with autodetect
added quarter inch jack for apple lisa keyboard

pt3:
added mouse power detect
moved rj11 socket down slightly
fixed a mislabeled debug header pin
updated mouse header labels

pt4:
2022-12-18
keyboard GND now connects to GND instead of MCU
Added a jumper on ADB Power Pin to MCU
Added a pull up on ADB Power line
removed left ADB debug header

pt5:
2023-03-02
removed extra resistors
added BUSY signal on PC13

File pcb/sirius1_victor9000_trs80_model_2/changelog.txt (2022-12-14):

PT1 2022-11-03
First prototype

PT2 ????
Hooked up eithernet port properly

PT3 2022-12-14

Added and hooked up connector for TRS-80 Model II

Although worlds apart in hardware architecture, the keyboard protocol of Sirius 1 and TRS-80 Model II is surprisingly similar.

Both uses keytronics foam and foil keyboard, which is why none of them works today.

Both uses serial communication, with DATA and CLK from KB to computer, and BUSY/ACK from computer to KB.

TRS-80 Model II can't seem to distinguish keydown and keyup events, it only sends data on keydown, and the data is the ASCII code.

Sirius 1 sends on both keyup and keydown, the MSB reflects that.

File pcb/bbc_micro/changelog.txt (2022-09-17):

pt0:
initial prototype
note slave requst is PF1 instead of PC13

pt1:
added 5v pull up on CA2 and W line

pt2 2022-08-25

moved mouse middle and right button to PF0 and PA0
moved SPI CS to PA15, SPI SCK to PB3
freed up two DAC pins
moved 15pin connector down a bit
DAC connected to joystick 0, digital control connected to joystick 1

pt3

fixed floating VDDA
BBC VREF on PB0
BREAK still on PB1

TODO:

device presense detect?
remove right angle silkscreen

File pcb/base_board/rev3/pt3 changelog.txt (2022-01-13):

added sleeping LED
adjusted silkscreen
adjusted OLED box position
adjusted OLED connector position, closer to edge
adjusted 5V header marking so it won't get covered up by connector

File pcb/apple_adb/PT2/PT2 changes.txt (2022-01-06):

moved ACT LED to PB8 (BOOT0)
ADB 5V detect on PA3
Removed RX pin on debug header
added a current limiting resistor on PB8
fixed flipped ADB connector footprint
added more debug headers

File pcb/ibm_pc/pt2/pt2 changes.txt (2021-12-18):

moved digital pot VCC to 5V
moved digital pot I2C Pullups to 5V
removed I2C header pins

PB15 Mouse 5V detect
PA8 Keyboard 5V detect

todo:
adjust keyboard label
is 5V pullup on keyboard data line necessary?

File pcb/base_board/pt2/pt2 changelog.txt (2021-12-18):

adjusted opening gap for USB and ethernet connectors
moved C20 away from OLED connector
moved power on/off button to edge
removed copper fill around antenna area

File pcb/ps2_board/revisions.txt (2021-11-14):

PT1: Initial version, lots of headers, wrong leader orientation

PT2: Fixed header orientation (mirrored it)

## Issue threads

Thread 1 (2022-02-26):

USB4VC GameCube support

BorgNumberOne, 2022-02-26:
It would be great if GameCube Controller and GameCube Keyboard support could be added.
(Connecting any USB/bluetooth game controller and mapping it as a GameCube controller; connecting any kind of PC keyboard and mapping it as a GameCube keyboard.)

Some detailed information:

Identifier | Console | Device
-- | -- | --
0x0500 | N64 | Controller
0x0500 | N64 | Dancepad
0x0001 | N64 | VRU
0x0200 | N64 | Mouse
0x0002 | N64 | Randnet Keyboard
0x2004(1) | N64 | Densha de Go
0x0004 | GBA | Game Boy Advance
0x0900(1) | GC | Controller
0x8800(1) | GC | Receiver
0x8B10(1) | GC | Wavebird
0x0800(1) | GC | Steering Wheel
0x0802(1) | GC | Keyboard
0x0808(1) | GC | Dance Mat

( https://n64brew.dev/wiki/Joybus_Protocol )
_

_

ID | Device
-- | --
0x0500 | ? N64 Controller
0x0001 | ? N64 Microphone
0x0002 | ? N64 Keyboard
0x0200 | ? N64 Mouse
0x0004 | GBA
0x0800 | GBA (n/a)
0x0900 | GC Standard Controller
0xe960 | ? GC Wavebird Receiver
0xe9a0 | ? GC Wavebird
0xa800 | ? GC Wavebird
0xebb0 | ? GC Wavebird
0x0820 | GC Keyboard
0x0800 | ? GC Steering Wheel
0x0900 | DKongas (same as std Controller)
? | Resident Evil4 Chainsaw

( http://hitmen.c02.at/files/yagcd/yagcd/chap9.html )

Some more information:
Beside the public GameCube ASCII keyboard, here are some further Keyboard to Gamecube adapter/converter possibilities/variants:

**+ Mad Catz - Sharkboard**
https://www.amazon.com/-/es/dp/B0002E5OJQ
http://www.nintendoworldreport.com/news/9248/mad-catz-ships-out-sharkboard

**+ Datel/codejunkies - Powerboard**
http://us.codejunkies.com/Products/GCN-Powerboard__EF000313.aspx
(this is the first one which I have got and which is also working very well in Datel's/Codejunkies': SD media launcher and Action Replay)

**+ ebest - e-Keyboard Converter for PC/PS2/GC/XBOX ("EB0019832")**
https://www.amazon.de/PC-Multi-Keyboard-Converter-Xbox/dp/B0007P8KHS
https://retrostuff.org/2013/01/11/connecting-a-keyboard-to-a-gamecube/
(this is the second one which I have got and which is also working very well in Datel's/Codejunkies': SD media launcher and Action Replay)

**+ Mayflash - GC Keyboard & PS controller Adapter 2 in 1 ("GC020")**
https://www.insomnia.gr/classifieds/item/1824046-gc-keyboard-ps-controller-adapter-2-in-1-%CE%B3%CE%B9%CE%B1-gamecube/
https://cdn-bb-eu1.insomnia.gr/file/insomnia-s3/monthly_2021_08/64C35C85-DC9B-4932-B5CB-3DBA2CA15BAF.jpeg.f580c2da99c243b9fc0f00577b3312fa.jpeg
https://i.ebayimg.com/d/w1600/pict/254804607328_/Mayflash-Tastatur-ps2-Controller-f%C3%BCr-GameCube-Adapter.jpg
https://web.archive.org/web/20060622142906/http://www.mayflash.com/gc/gc020/GC020-1.htm
https://www.google.com/search?source=univ&tbm=isch&q=%22GC+Keyboard%22+mayflash
https://www.facebook.com/2070956029869509/posts/mayflash-gc-keyboard-controller-adapter-2in1mayflash-rare-collectoritem/2569997976631976/

**+ tototek GC KEYBOARD CONVERTER 2in1**
http://www.tototek.com/pio/main1/SUBMENU/PARTS/LINKS/GC/gckeyboard2in1us.htm

Further GameCube Keyboard controler/adapter/coverter related links:
a)
http://www.pso-world.com/forums/showthread.php?25176-Tototek-s-GC-2-in-1-keyboard-converter-REVIEW
b)
http://web.archive.org/web/20030802212927/http://www.pantsofevilgamers.com/kb/ordering.htm
http://web.archive.org/web/20030803012738/http://www.pantsofevilgamers.com/kb/pics.htm
(build your own GameCube Keyboard adapter, )

**This may be useful for realizing GameCube Keyboard support in Swiss:**
a)
http://www.blarg.ca/2021/02/15/using-a-gamecube-ascii-keyboard-controller-with-libogc/
b)
https://github.com/gered/gc-ascii-keyboard
c)
http://hitmen.c02.at/files/yagcd/yagcd/chap9.html#sec9.3
d)
https://simplecontrollers.bigcartel.com/
https://simplecontrollers.bigcartel.com/product/gamecube-controller-value-and-snapback-tester-reader
https://simplecontrollers.bigcartel.com/product/sammy-ascii-keyboard-to-usb-adapter

dekuNukem, 2022-02-26:
Great suggestion! There's nothing stopping USB4VC from working on retro consoles, so this is definitely possible. Although at launch it would focus more on computers.

I’m definitely be interested in working on a console P-Card down the line, and instructions will be provided for people to make their own protocol cards.

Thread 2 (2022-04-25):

Raspberry PI Zero

bskan, 2022-04-25:
Trying this initially on a Raspberry Pi Zero (non-W) which doesn't have bluetooth/wifi.

It's done it's initial set up but now it's stuck in a loop

"Disabling ERTM.....
ertm_status: cat: /sys/module/bluetooth/paramaters/disable_ertm: No such file or directory"

Is there a way I can turn this part of the script off by editing the sd card on another system?

dekuNukem, 2022-04-25:
Hi there! Disabling ERTM is in a seperate process, and shouldnt affect the functionality of the device. Does it not work at all?

bskan, 2022-04-25:
The green LED comes on the one board but the OLED display has no life in it. The buttons don't appear to do anything either. I've ordered myself a Pi 3b in case it's the Pi itself that's the issue.

bskan, 2022-04-29:
Pi3b works great so I'm guessing it's a hardware fault in my Pi Zero!

Closed 2022-04-29.

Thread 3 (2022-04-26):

USB4VC and KVM?

vorvek, 2022-04-26:
Hello, I'm trying to use my USB4VC+IBM board with an Aten PS\2+VGA KVM. The results are not good; in my slowest computers I can type a dozen characters before I get a beep from the PC speaker. It doesn't matter if I type them fast or slow, sometimes writing a simple command in DOS will require me to wait for a second. All the letters appear afterwards, however. In faster machines (ie, Pentium and beyond) it seems the mouse is more problematic, although some of my keyboard inputs are also eaten.

Am I correct to assume that the issue comes from having a KVM in between? I can give it a try, connecting the computers directly, but the back of my rack is somewhat inaccessible (and those PS\2 connectors love to get their pins bent when you try to plug them blind).

dekuNukem, 2022-04-26:
Hi there! Please do try it directly attached to the computer if possible, and let me know how it goes.

I did all the developments with computers and it seem to work fine, so maybe the KVM is doing something funky.

Is this the model you're using?

https://www.amazon.co.uk/Aten-CS22U-2-Port-Cable-Switch-black/dp/B002NTIZCG

vorvek, 2022-04-26:
No, it's a rack mounted KVM with 8 ports, one of these: https://www.kvm-switches-online.com/cs9138.html

I'll try connecting the stuff directly later this week and report back!

vorvek, 2022-04-27:
I've tried connecting directly to a few of the computers and this does make the USB4VC work in what I can only call flawless fashion. I've also tested the KVM I was using previously, a 4 port Aten Master View 114-A which from my understanding is a consumer version of the one I'm currently using. By this, I mean that the innards are very similar except for a lack of OSD, but it also has the PS\2 emulation aspect and power through VGA.

The results are the same as with the CS9138, stuttery mouse and keyboard and weird input handling, although I've only tested it in a couple of the computers (I run my VGA output through an OSSC, it's really a pain in the ass to unplug some of this stuff, but it's much worse to plug it later!).

While I can't part with my current 8 port for a long period of time, I can mail you the 4 port KVM. I'm also in the UK (London, thus the tiny computer room lol), I don't mind paying for the shipping, and you can use it for any tests you consider relevant. I don't have any other KVMs to test the USB4VC with, but I assume most VGA+PS\2 KVMs will be pretty much the same, particularly if they are "proper" products from the era when they were relevant.

dekuNukem, 2022-04-28:
Good to hear that it works fine on the computer itself! Really curious to see what shenanigans the KVM is doing.

Thank you very much for offering the KVM for me to test! I’m happy to cover the postage, although I might need to have it for a week or two, so hopefully you don't depend on it too much. Otherwise I might just buy one myself.

Anyway, feel free to let me know your email or [DM me on discord](https://discord.gg/HAuuh3pAmB), so we can exchange the information in private.

dekuNukem, 2022-05-14:
Hi there! Thank you very much for sending me the KVM to check it out. It helped immensely with adding and testing host inhibition, resulting in improved compatibility with different systems.

I feel that I'm pretty much done with it now, would you like to have it back? I can hold on to it if you’re not in a hurry, but otherwise I can post it back anytime you want!

vorvek, 2022-05-14:
Not in a hurry to get it back, feel free to send it back whenever you see fit. The return address was in the wrapping, so I assume you don't have it anymore, haha. Let me know in Discord when you want to post it and I'll give you the address.

queenkjuul, 2022-06-28:
Just want to chime in and say I am also having issues with a KVM - a couple in fact. Haven't had time yet to do meaningful testing.

I have a USB KB -> USB KVM -> USB4VC -> PS/2 KVM setup. Notably, the USB4VC screen indicates that it is detecting multiple keyboards attached. I was experiencing similar issues - either big lag, or key repeats, or key drops, plus completely erratic mouse behavior. Will do some testing with each KVM individually when I can. Also just got a new PS/2 KVM to try as well.

ackmangogo, 2022-08-11:
Aten KVM as I know will emulate ps/2 mouse and keyboard, maybe passive ps/2 switch will help in this use case.

Jimbo7136, 2023-11-01:
I am using an ATEN CS84U PS2/USB KVM after the USB4VC. The keyboard works but the mouse doesn't at all. Plugging the PS2 ports directly from the USB4VC to a PC works correctly.

schlangz, 2024-03-22:
I have the same problem, using DIGITUS KVM Switch DC IC-814IO, mouse is not working at all. Plugging the PS2 cable directly into the PC works. Any way to debug this?

jbbbloody, 2025-03-05:
Just noticed this and wanted to add, that I am using the USV4VC with an old rack-mountable COMPAQ 8 Port VGA & PS/2 KVM with OSD and its working like a charm. Even using it with all my modern Kit, just depends on the PS/2 to USB converters you attach, some are causing double characters, or missing input... but in general they work like a charm.

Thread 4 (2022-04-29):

No input with SGI Octane

Jenna64bit, 2022-04-29:
Hi there!

Trying this out on my Octane for PS/2 support with the IBM module. Whole set up seems happy, Octane does seem to detect that there is a keyboard, it normally gives an error if not. But, I get no input. I suspect this is because PS/2 has multiple "scan code" modes, and SGI systems are notoriously fickle and [only want a specific one (3)](https://nixdoc.net/man-pages/IRIX/man7/pckeyboard.7.html). Might there be an easy way I can add that mapping?

dekuNukem, 2022-04-29:
Makes sense! IBM PC Protocol Card currently supports Scan set 1 and 2. Set 3 is indeed very rare, and I don't have a machine that uses it, so even if I code the firmware I'll have no way to actually test it.

That said, I would love to add the support for it, so looks like I might need to start looking out for the rare scan code set 3 machines.

Jenna64bit, 2022-04-29:
Ah, fair, yeah any SGI with PS/2 will use it. That's the Indy, Octane, O2, etc. I'd also be happy to test a few times. Admittedly, that would be a lot slower than doing it yourself. Thanks for the quick reply!

dekuNukem, 2022-04-29:
I've found a IBM Infowindow data terminal for sale with the 122-key battleship model M keyboard with the RJ45 connector.

My quick research shows that it uses scan code set 3, so I might snatch it up, hopefully it works and I can work on set 3 support!

dekuNukem, 2022-05-06:
I have added experimental PS/2 scan code set 3 support in the latest update, it seems to work with my IBM terminal, but that's the only machine I have. Feel free to try it on yours!

Make sure your [Raspberry Pi is online](https://github.com/dekuNukem/USB4VC/blob/master/getting_started.md#optional-set-up-wifi), and select `Internet Update` from the main menu.

After updating, on the second page it should show `PB 0.4.0 RPi 0.1.3`

Let me know how it goes!

Jenna64bit, 2022-05-06:
Hey hey!! I'm happy to say it works. Both mouse & keyboard working now on my Octane from my Logitech unifying dongle.

dekuNukem, 2022-05-06:
Glad to hear it works! Feel free to double check the key mappings are correct, and use it for a while to see how stable it is.

Let me know if you run into any issues.

Jenna64bit, 2022-05-10:
Probably final follow up. This has been rock solid on my workstation. Good to close by me.

Jenna Whitehouse
***@***.***

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

dekuNukem, 2022-05-10:
Great! I just released a new update with even more features, make sure to check it out 😅

https://www.kickstarter.com/projects/dekunukem/usb4vc-usb-inputs-on-retro-computers/posts/3503167

Closed 2022-05-10.

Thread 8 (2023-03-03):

Sporadic / exaggerated mouse input

queenkjuul, 2023-03-03:
I have tried several mice, a very old Logitech USB mouse as well as modern Logitech Unifying mice and a Logitech gaming mouse. When using the PS/2 output to my machine, the mouse is detected, and if I move the mouse very slowly, I can move the cursor accurately, but then without warning any movement sends the mouse fully into the corners, with inputs getting jumbled - mouse clicks will move the cursor up and down or side to side.

When a PS/2 mouse is connected directly to the machine, I have no problems. PS/2 keyboard and 15-pin joystick are working perfectly with this machine. USB4VC is updated to latest firmware, and I've tried both Cutemouse 1.9 and 2.1 with the same results. Mouse sensitivity on the USB4VC is set to 0.25.

I seem to remember getting serial mouse to work with one of these USB mice, but that was over a year ago and I am not currently set up to easily test that. Event code monitor shows normal looking inputs as far as I can tell.

BonzoG, 2023-04-27:
I have the same issue. PS/2 keyboard is rock solid, but after a few moments of fast movement the mouse will latch to the corners of the screen and cause sporadic clicks whilst jumping around. Unfortunately I don't have a serial interface to test with.

dekuNukem, 2023-04-30:
hi there! can you let me know the spec of your PC that has PS/2 issues?

perhaps you can try it on a few different machines and see if it keeps happening?

BonzoG, 2023-05-06:
Hi! Thanks for looking at this.

I actually have two very similar machines with totally different behaviour. Both are Intel 440BX chipsets.

#1 Gigabyte GA-BX2000+ Motherboard, Pentium 3 1.1Ghz  - PS/2 works flawlessly.
#2 Compaq Deskpro (OEM 440BX motherboard with a PC87309 I/O controller), Pentium 2 450MHz - this is the glitchy one, same as OP on this issue.

For now I am happy using serial on the Deskpro :) but curious to know why the glitches are happening. If I can find a PS/2 mouse to test with, I will report back, but so far my issue starts the exact same way as OP. Mouse initially fine, can move it around 'gingerly' and then it just jumps to the corners of the screen, moves rapidly between them, and throws random clicks around.

Cheers

dekuNukem, 2023-05-08:
Hmm this usually happens when the PS/2 singal timing is out, very strange it happens on one motherboard but not the other. I'll need to dig out my stash of motherboards and see if I can find one that reproduces this.

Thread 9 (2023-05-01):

Few certain button assignments not responding

dg410a, 2023-05-01:
First of all, loving the USB4VC so far that I just got in the mail today. Works almost perfectly, but I've been running into a couple of issues and a certain glitch so far.

So, here's the thing. I've got a PC KVM setup consisting of four machines ranging from MS-DOS to Windows XP. Although, I'm only using the USB4VC for the game port so that I can proper joystick support, especially in pure DOS. So, here's my current setup of controllers as I write this:

Microsoft Sidewinder Force Feedback 2
Logitech MOMO Force Feedback Wheel
Logitech Rumblepad 2
Microsoft Sidewinder Freestyle Pro
Microsoft Sidewinder Dual Strike
Microsoft Sidewinder Strategic Commander

All joysticks are run through a USB KVM switch, which then would go right into the RPi on the USB4VC. Works just fine despite being unsupported and it does detect all of the buttons and axes according to the Event Log. I'm also using a custom configuration and have set these to work as USB generic devices.

Although, I've noticed with my Freestyle Pro that when pressing the sensor button to switch to digital mode from proportional mode, the USB4VC goes completely nuts (i.e. The LED on the IBM PC protocol card, which detects the axis I would assume, flashes continuously. It actually exited out the Event Log without holding + on the USB4VC and pressing a joystick button). But when I press any other button on the controller, it goes back to normal. Weird.

As soon as I started using it on my PCs via game port though, that's when I ran into issues. FIrst of all, the BTN_JOYSTICK assignment (Button 1) doesn't register with my PCs on all of my joysticks that utilize it (minus the Strategic Commander), whether I'm using a Windows 9x DOS Box or pure DOS. And on my Force Feedback 2 and Strategic Commander, the ABS_RZ axis (twisting the joystick) doesn't register with the PCs either. Strangely though, on my Rumblepad 2, the ABS_RZ axis registers just fine all around.

So, I'm not sure if it's a bug in the firmware or what. I even did a proper reset the USB4VC, but to no avail. Any input is greatly appreciated.

dg410a, 2023-05-02:
So, upon further testing, I've noticed that binding the BTN_TRIGGER to Button 1 on the Game Port does seem to work, despite the Event Log reporting BTN_JOYSTICK whenever I push Button 1 (the trigger) on my joystick. Though, I still couldn't get the rudder axis on the Force Feedback 2 to work so far.

dg410a, 2023-05-02:
Was able to get the rudder on my Force Feedback 2 joystick to work, to some degree. JS2 Positive X gives me only a limited range when turning left or right. JS2 Negative X gives me full range, but is reversed.

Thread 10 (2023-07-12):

Keyboard function keys recognized as media keys - Keychron K5 SE

Raging-Flame, 2023-07-12:
After using USB4VC with different keyboards (USB, BT, combined mouse and KB dongles) and all of them working perfectly, I just got a Keychron K5 SE keyboard, which has the following issue.

Function keys do not work and using the option "Show Event Codes" shows that they are recognized as media keys (volume controls and so on) instead of as function keys. The keyboard has an option to switch its function key behaviour between function keys and media keys but this doesn't help as the USB4VC doesn't recognize button presses at all when switching the keyboard to the other mode.

I guess, normally keyboards "hardmap" function keys as said function keys but this keyboard (an maybe others too) might hardmap them as media keys.

Is there a way to manually map the keys like it is for gamepads? If not, maybe the USB4VC Configurator app for gamepads could be expanded to also offer this functionality for keyboards.

megatog615, 2023-10-24:
Yeah... happens with Keychron C1 as well.

megatog615, 2023-11-08:
Add this to a new file called /etc/modprobe.d/hid_apple.conf :
`options hid_apple fnmode=2`

This changes the behavior of the hid_apple driver(which non-QMK Keychron boards use regardless if they're in Mac or Windows mode). I already had this fix on my Linux PC but I forgot that USB4VC is technically a Linux box 😅.

Raging-Flame, 2023-11-10:
> Add this to a new file called /etc/modprobe.d/hid_apple.conf : `options hid_apple fnmode=2`
>
> This changes the behavior of the hid_apple driver(which non-QMK Keychron boards use regardless if they're in Mac or Windows mode) so that the function keys are read as function keys first. Use FN + function keys to restore the media key behavior. I already had this fix on my Linux PC but I forgot that USB4VC is technically a Linux box 😅.

While connected to the USB4VC, the K5 SE in Windows mode causes the function keys behave as only media keys (backlight brightness for example) if FN is held down, while in Mac mode it's reversed. The problem, that the F1 to F12 keys aren't recognized as such remains, even if I add the hid_apple.conf to the boot partitions on the USB4VC microSD card. This file also doesn't change FN-key behaviour.

Also with the K5 SE in Windows mode, you can keep FN+X+L pressed for 4 seconds to change FN-key behaviour, which also works for USB4VC, but doesn't help with the issue of not getting F1 to F12 to work. Very odd that the keyboard always sends media key events to the USB4VC, while it works fine under Windows and Linux.

megatog615, 2023-11-10:
You need to add it to /etc/modprobe.d/ in the _rootfs_ partition not boot.

Raging-Flame, 2023-11-10:
> You need to add it to /etc/modprobe.d/ in the _rootfs_ partition not boot.

Just did this now and it indeed works, yay! Thanks for the solution. :D

Under Linux Mint 21.2 the keyboard worked out of the box the way it should. I wonder if they accounted for these problems with Keychron keyboards already, even though it runs kernel 5.15 and I read only 5.19 resolved (to a dregree at least) issues with Keychron keyboards.

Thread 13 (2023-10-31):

Instability from system restart

megatog615, 2023-10-31:
Sometimes when I reboot the machine(a socket 7 system), the USB4VC becomes either entirely unresponsive(no LED lighting from input) or seemingly responsive but the computer doesn't see any input.

I see there is a [technical bulletin](https://github.com/dekuNukem/USB4VC/blob/master/technical_bulletins.md) that is supposed to "improve stability" but, I don't want to go through with this modification without knowing what problem it specifically tackles(I'm not sure if it is relevant to this specific issue) and how it works.

jamescadd, 2023-12-06:
Any update @dekuNukem ?  Would be nice to have an updated release with the last few commits to make sure it's not something that's already fixed.

dekuNukem, 2023-12-06:
Hi there! can you let me know the model of the motherboard you're using? I personally haven't encountered an issue like this myself, would like to test it out.

megatog615, 2023-12-06:
[BCM-SQ594](https://theretroweb.com/motherboards/s/bcm-sq594)

megatog615, 2025-05-14:
I don't know why it took me so long but I just realized I could SSH into the thing and possibly monitor it on the command line. `dmesg` shows a bunch of `Undervoltage detected!` then `Voltage normalized` over and over again after using it for a while. My usb4vc is connected to a USB PD charger.

My Pi is a Model 3B Rev 1.2.

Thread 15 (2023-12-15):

Stuck with 2 Keyboards

sererinn, 2023-12-15:
Hey.
I have just received the hardware today.
I have just noticed that I now have nothing connected and the dispay is showing me:
KBD 2 AT/PS2
MOS 0 PS/2
GPD 0 Generic 15-Pin

The only ports I have connected on the card are the 2 PS2 ports. Even if I disconnect everything, the display will still be showing 2 Keyboards.

I have already reflashed the card from scratch and still seeing it.

I'm curious if this is the reason that my USB keyboard stopped being detected on the computer I connected the device to.

Closed 2023-12-20.

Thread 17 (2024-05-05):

MIDI question

rkurbatov, 2024-05-05:
I see unused pins on PC board. Especially I am interested in TX/RX/5V/3V/GND. Does it mean I can add MIDI compatibility, especially MIDI IN/OUT? I am very interested, because I don't want to waste Raspberry 3 power and can add MT32 compatibility, for example.

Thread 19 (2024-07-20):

No response from Mac protocol card with Macs

ewe2, 2024-07-20:
I've used the mac protocol card with a Plus and and SE and tested with a Pi 4 B+ and an A+ On all boots, the Pi boots up with Raw Data on all protocols and nothing changes. I've tried resetting on the protocol card, it doesn't change.

Either the protocol card isn't actually talking to the  machine, and the Pi thinks everything's ok, or the Pi system isn't re-engaging the protocol card when it detects the machine on the other end? I don't get any other alternative on the hardware than to change sensitivity or saving the options so what can I do to help debugging this?

edit: i will mention i'm using the cables I bought with the usb4vc just to rule out cable issues.

dekuNukem, 2024-07-20:
hi there ! if it says raw data, then it means the pi hasn’t recognized the protocol card.

was it like this out of the box? there are a few things we can try. which raspberry pi model are you using?

ewe2, 2024-07-20:
It's been like that from the start, yes. I thought I'd dome something wrong with my setup or it was a failure of communication with the mac.

I've used 3 Pi's with this and they all report the same thing, currently I'm trying the P3 B but I've also had a P4 B and a P3 A.

dekuNukem, 2024-07-20:
Is your P-card the ADB only card or Lisa/Mac/ADB card?

ewe2, 2024-07-20:
Its the Lisa/Mac/ADB so it's got the 2 ADB's and the serial port and the
RJ45

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

--

I love deadlines. I love the whooshing noise they make as they go by.
-- Douglas Adams.

dekuNukem, 2024-07-20:
nice! there is a possibility that I actually forgot to flash the firmware into the card, might worth trying do it yourself and see if it comes to life!

download the file here:  https://github.com/dekuNukem/USB4VC/raw/master/firmware/releases/PBFW_LISA_MAC_ADB_PBID3_V0_1_0.dfu?raw=1

then follow the instruction here: https://github.com/dekuNukem/duckyPad/blob/master/firmware_updates_and_version_history.md

* Use the file you just downloaded,
* Leave the P-card plugged into the baseboard
* The DFU button is near the top-left

dekuNukem, 2024-07-20:
oh, and of course use the USB port on the P-card

ewe2, 2024-07-20:
Nothing's working. Doing all this under linux so I'm following dfu-util instructions. Plugged into Pi usb port from hub and while holding down dfu button, attached power and waited until i got green flash from Pi and let go, checked lsusb, there's nothing there, dfu-util can't find a device, I'm not seeing any activity from the card that indicates it's awake.

dekuNukem, 2024-07-20:
I should have been more clear with the instructions, I do apologize.

Try this:

* Pop the SD card out of Raspberry Pi, we are not using the RPi here.
* Leave Protocol card attached to baseboard
* Take a USB cable
* Plug it into the USB port **on the protocol card**
* Hold down DFU button on the P-Card
* Plug the other end into computer
* Release DFU button

something should show up, then follow the guide above

ewe2, 2024-07-20:
Nothing there, it is powering, but dfu-util -l shows nothing, it's not showing up.  I've had the pi plugged in without a card, i've taken it off entirely, there's no difference. The power light is on when I plug in but otherwise nothing. DFU button doesn't seem to have any effect.

dekuNukem, 2024-07-20:
try it on a windows PC and see if anything show up in the device manager, if not, it might be a hardware issue, and I can send you a new one for free!

ewe2, 2024-07-20:
I don't have a working Windows machine at the moment but we don't have to deal with that. Because I also bought the PC protocol card and we can eliminate my tools as an issue, because that protocol card shows up perfectly well, can be seen in lsusb and dfu-util -l and I also notice there's a little light that comes on by the PS/2 outs that did not come on by the ADBs on the Mac protocol board which might be useful information for you.

dekuNukem, 2024-07-20:
ah ok then, looks like a hardware issue!

Let me know your Tindie order number and I can send you a new lisa/mac/ADB card for free!

ewe2, 2024-07-20:
Thanks, sorry I can't give you more information on exactly what's wrong with it.  Tindle order is #473835

dekuNukem, 2024-07-20:
No problem! I'll drop it off on Monday

ewe2, 2024-07-22:
Thanks!!

Closed 2024-08-01.

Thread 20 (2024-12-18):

Create an Amiga/Commodore protocol card

Peckmore, 2024-12-18:
I'd like to ask whether it would be possible to get a protocol card created that could support Amiga/Commodore computers (and I ask this knowing it isn't easy, but I have neither the skills nor equipment to make one myself! 😁)

**Keyboard**
The pinouts for the various Amiga keyboard ports (Amiga 1000, Amiga 2000/3000, Amiga 4000, CDTV, CD32) can be [found here](https://sacc.org/demo/keyboard/a-keyboard.html). Although the pinouts are slightly different, I _think_ the underlying keyboard protocol is the same between them all?

For the Amiga there are plenty of existing PS/2 to Amiga keyboard converters, such as [the Lyra 3](https://wiki.icomp.de/wiki/Lyra_3). The [PS2toAmiga GitHub project](https://github.com/Jartza/PS2toAmiga) is an open source version of such a converter, and also includes links to the [Amiga keyboard protocol](http://amigadev.elowar.com/read/ADCD_2.1/Hardware_Manual_guide/node0172.html).

My guess would be that a 6-pin DIN connector could be located on the protocol card, and then the appropriate cable used to connect to the keyboard port of the various Amiga models?

**Mouse**
For both mice and joysticks, the Amiga uses the standard Atari 9-pin port.

There are [again](https://www.elbox.com/products/cocolino.html) [many](https://trumouse.com/product/amiga-usb-mouse-adapter/) [adapters](https://trumouse.com/product/amiga-ps2-mouse-adapter/) for converting both PS/2 and USB mice to the Amiga 9-pin port. By default they all support 2-button mice, but with [custom drivers](https://wiki.icomp.de/wiki/Micromys_Protocol) I believe many support 3-button mice and scroll wheels.

The [HID2AMI GitHub project](https://github.com/EmberHeavyIndustries/HID2AMI) is an open source converter (at least for the PCB, not sure on the firmware) that converts a USB HID device into an Amiga mouse, with 3-button and scroll wheel support via a free driver. For a protocol card, 2-button support would be a great start, and it could always be updated to support 3-buttons and a scroll wheel via a firmware update?

I think for both mouse and gamepad support, 2 x DE-9 connectors could be located on the protocol card, which could then connect directly into the mice/joystick ports of an Amiga.

**Gamepad**
By default the Amiga supports the standard Atari 9-pin port, as discussed above, which supports 4 directions and 2 buttons. However, the CD32 came with a 6-button pad, and 6-button MegaDrive/Genesis pads can be used on an Amiga with [an adapter](https://github.com/LIV2/Amegapad).

[This page](https://www.mrdictionary.net/PSCD32/diary/2019_08_09.htm) contains a lot of information about how the CD32 supports 6 buttons via the standard 9-pin port:

> The CD32 pad has two modes, determined by the state of the pin 6 JOYMODE pin. This pin is controlled by the Amiga, and is one of the three bidirectional pins the Amiga joyport has.
> • If the JOYMODE pin is set High by the Amiga, the pad is set to a dumb joystick mode. The states of Fire 1 (Red) and Fire 2 (Blue) are reported to the Amiga by grounding the FIRE1OUT and FIRE2OUT pins respectively as if Fire 1 and Fire 2 were simple switches to ground.
> • If the JOYMODE pin is set Low, the pad is set to seven button mode. CLOCKIN is treated as an input signal. On each rising edge of CLOCKIN, a new button state is shifted onto the DATAOUT line in a set sequence. When all seven buttons have been shifted, a final 1 signal is reported, followed by endless 0s.

So typically on an Amiga (or Commodore C64/C128) the pad/protocol card would operate in 2-button mode. But if the Amiga sets pin 6 to low, then the pad/protocol card would switch to 6-button/CD32 mode.

**Commodore C128D**
Everything listed above has been Amiga focused. However, the Commodore C64, C128, and C128D would I believe be able to use the same protocol card for mouse and gamepad support, as they all use the same Atari 9-pin ports.

What I think could make this protocol card even better would be supporting the keyboard port of the C128D. The C128D keyboard protocol can [be found here](https://user-images.githubusercontent.com/79846351/141100072-f6f5877f-9acf-4976-b505-4319829755d5.gif) - it's less of a protocol, and more of the row and column pins determining which key is pressed. The [C128-keyboard GitHub project](https://github.com/ytmytm/C128-keyboard) is an example of a USB HID to C128D keyboard adapter. This is [another open source project](https://github.com/dankreek/c128d-usb-keys) that does the same.

To support this, I think an additional DB-25 connector would need to be located on the protocol card.

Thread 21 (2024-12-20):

XBox Wireless Adapter Support (switch from `xpadneo` to `xone`?)

Peckmore, 2024-12-20:
I'd like to use an Xbox Wireless Adapter with the USB4VC, but currently this isn't supported.

It seems USB4VC uses the [xpadneo](https://github.com/atar-axis/xpadneo) driver to handle Xbox controllers, but this only supports wired or Bluetooth controllers, not the Xbox Wireless Adapter.

Would it be possible to have an option to switch to the [xone](https://github.com/medusalix/xone) driver to enable support for the Xbox Wireless Adapter? 😁

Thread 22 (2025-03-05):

CTRL-ALT-DEL sometimes gets passed to the Pi instead of the host system

mabalmer, 2025-03-05:
I've noticed this behavior specifically when trying to do installations of Win98 via Win98 Quick Install, which uses a Linux kernel as part of its initial bootstrap process. Once the kernel has booted and the menu system for installing the operating system has loaded, CTRL-ALT-DEL is intercepted by the Pi and causes the USB4VC to reboot itself, rather than the host computer.

Details of the system in question:

- Motherboard: MSI MS-4144
   - CPU: AMD 5x86-DX5-133, overclocked to 160MHz
   - Chipset: SiS 85C496/497
   - Keyboard BIOS: AMIKey-2 (presumably a standard 8242/8342 variant)
- Devices:
   - VGA: DataExpert ExpertColor DSV3325DX (S3 ViRGE DX, 4MB)
   - Network: 3Com 3C509B
   - Sound: Pro AudioSpectrum 16
   - IDE0: Dual 8GB compact flash cards
   - IDE1: ZuluIDE attached as primary, no secondary

Keyboard attached to the USB4VC is a Logitech K800 via wireless Unifying adapter.
Mouse attached is a Logitech Triathlon M720 paired to the same Unifying adapter.
Joystick attached is an 8BitDo SF30 Pro Wireless controller, attached via USB cable.

Let me know if additional configuration details are needed.

dekuNukem, 2025-03-05:
Hi there! I thought I disabled the three finger salute in the OS image, not sure how it regressed on yours.

Anyway, feel free to ssh into it and try this:

```
sudo rm /lib/systemd/system/ctrl-alt-del.target
sudo ln -s /dev/null /lib/systemd/system/ctrl-alt-del.target
sudo systemctl daemon-reload
```

Source: https://librpip.frasersdev.net/linux/raspbian/

mabalmer, 2025-03-25:
I think I understand a little more about what's going on here -- I've noticed that sometimes, the USB4VC reboots itself with CTRL-ALT-DEL when the host system is frozen or busy to the point where keyboard inputs are lagging.

The first press of it passes through to the host as expected, and then if the USB4VC receives more of them in succession, it might pass a few more to the system but it will eventually stop and the USB4VC will stop accepting inputs because it's rebooting itself (the little white light that shows that it's processing inputs stops blinking entirely and the green activity light on the side of the Pi starts flashing furiously like it's in the middle of a startup routine).

Not sure what's actually happening here, but if you have more ideas to try to get to the bottom of it, let me know.

megatog615, 2025-05-20:
Perhaps it's SystemD's ctrl-alt-del burst action? By default it is configured in /etc/systemd/system.conf to force reboot the system. If you uncomment CtrlAltDelBurstAction and change it to none it disables this.

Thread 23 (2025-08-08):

Mouse input issues with Logitech G502

DandyTush, 2025-08-08:
I has having issues with my Logitech G502. Mouse input would randomly jump, it was slow, and there would occasionally be unwarranted clicks. When I used a simpler, older USB mouse, I did not have such issues.

This issue: https://github.com/dekuNukem/USB4VC/issues/6 advised adding `usbhid.mousepoll=0` to the end of `/boot/cmdline.txt`.

I found that `usbhid.mousepoll=0` was already there out of the box. When I removed it, my mouse worked perfectly.

It seems that `usbhid.mousepoll=0` may improve latency but may cause compatibility problems with some mice.

I request that the documentation and/or user interface should call this out as a potential fix for some issues.

DandyTush, 2025-08-08:
note that you will also have to disable this code which will restore usbhid.mousepoll=0 when the device restarts:

```
try:
    boot_config = os.popen(f'cat {cmdline_path}').read()
    if "usbhid.mousepoll".lower() not in boot_config.lower():
        print(f"@@@@@@@@@@@@ writing usbhid.mousepoll to {cmdline_path} @@@@@@@@@@@@")
        new_config = boot_config.replace('\r', '').replace('\n', '').strip() + ' usbhid.mousepoll=0\n'
        with open(cmdline_path, 'w') as ffff:
```

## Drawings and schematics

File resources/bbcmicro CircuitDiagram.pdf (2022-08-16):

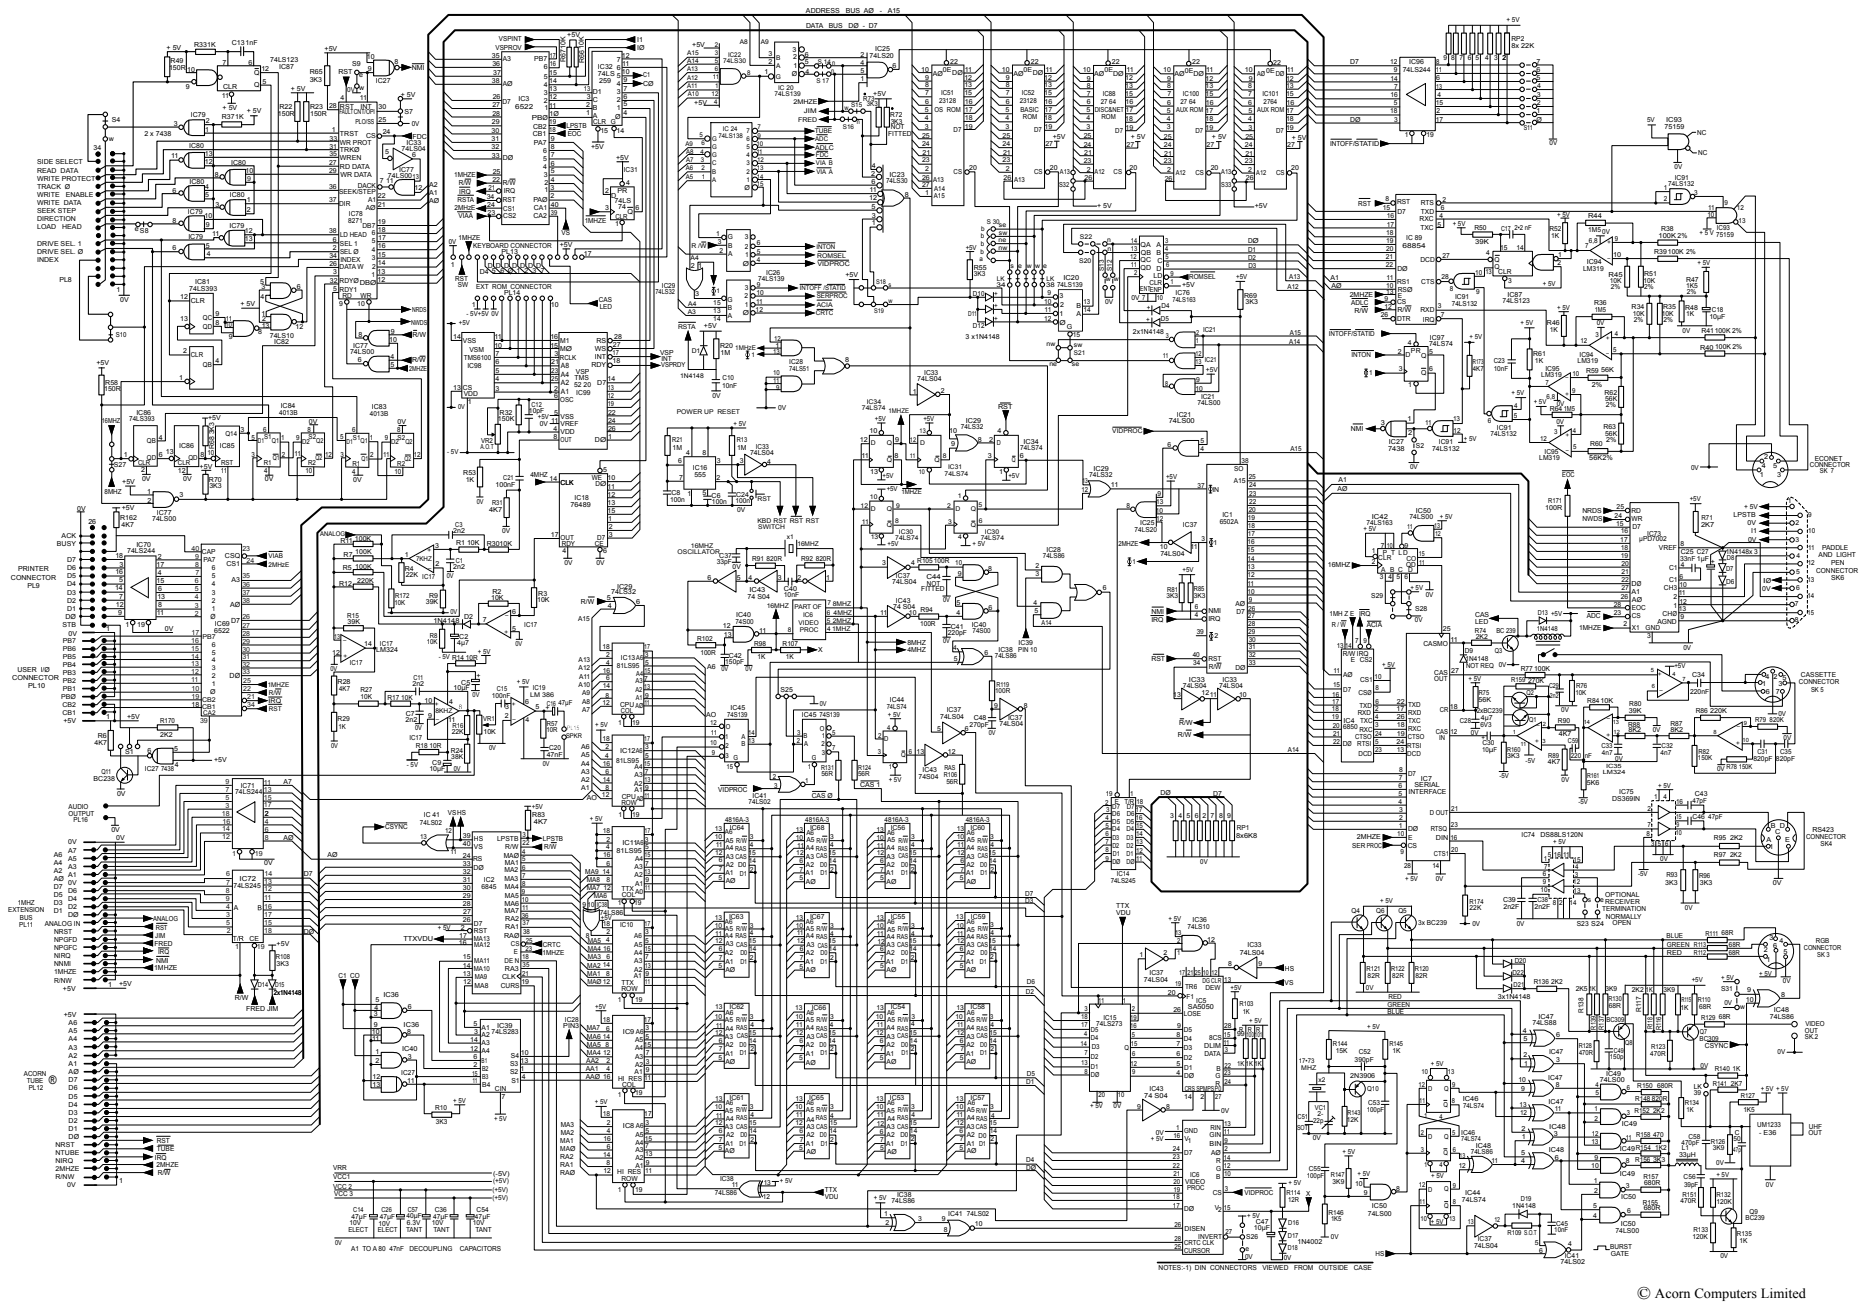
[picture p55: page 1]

35 7 | 9 ADC 10

IC63 A6 A5 R/W A4 RAS A3 CAS A2 D0 A1 D1 AØ | IC67 A6 A5 R/W A4 RAS A3 CAS A2 D0 A1 D1 AØ | IC55 A6 A5 R/W A4 RAS A3 CAS A2 D0 A1 D1 AØ | IC59 A6 A5 R/W A4 RAS A3 CAS A2 D0 A1 D1 AØ

11 | 1 | 26 | RED

NOTES:-1) DIN CONNECTORS VIEWED FROM OUTSIDE CASE

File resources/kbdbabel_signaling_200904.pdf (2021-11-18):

## Amiga 500/1000/2000 Keyboard Protocol

## Amstrad PC1512 Personal Computer Keyboard Protocol

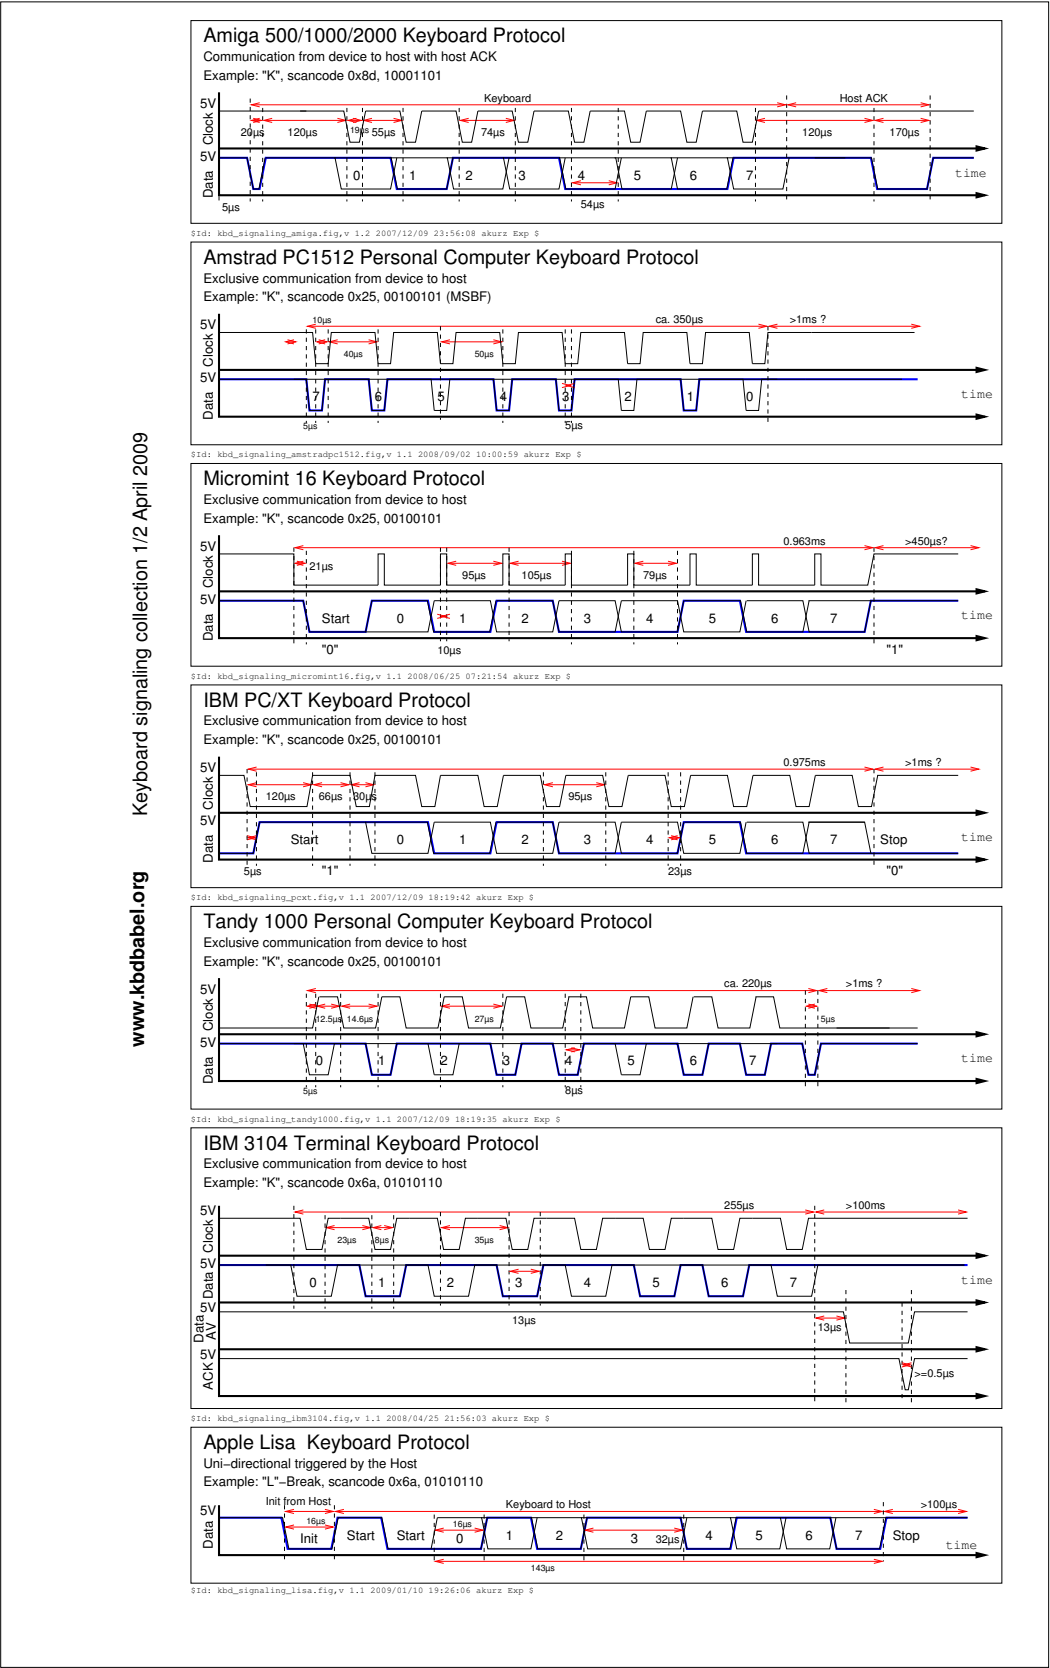
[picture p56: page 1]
5V 5VData Clock; Keyboard; Host ACK; 55µs ¹⁹µs; Start; Stop; >1ms ? 5V 5VData Clock; 5V 5VClock; Data ACK; AV Data; Init from Host; Init; Stop 5; time

Communication from device to host with host ACK
Example: "K", scancode 0x8d, 10001101

$Id: kbd_signaling_amiga.fig,v 1.2 2007/12/09 23:56:08 akurz Exp $

Exclusive communication from device to host
Example: "K", scancode 0x25, 00100101 (MSBF)

www.kbdbabel.org Keyboard signaling collection 1/2 April 2009

$Id: kbd_signaling_amstradpc1512.fig,v 1.1 2008/09/02 10:00:59 akurz Exp $
Micromint 16 Keyboard Protocol
Example: "K", scancode 0x25, 00100101

$Id: kbd_signaling_micromint16.fig,v 1.1 2008/06/25 07:21:54 akurz Exp $
IBM PC/XT Keyboard Protocol

$Id: kbd_signaling_pcxt.fig,v 1.1 2007/12/09 18:19:42 akurz Exp $
Tandy 1000 Personal Computer Keyboard Protocol

$Id: kbd_signaling_tandy1000.fig,v 1.1 2007/12/09 18:19:35 akurz Exp $
IBM 3104 Terminal Keyboard Protocol
Example: "K", scancode 0x6a, 01010110

$Id: kbd_signaling_ibm3104.fig,v 1.1 2008/04/25 21:56:03 akurz Exp $
Apple Lisa Keyboard Protocol
Uni−directional triggered by the Host
Example: "L"−Break, scancode 0x6a, 01010110

Keyboard to Host 5VData

$Id: kbd_signaling_lisa.fig,v 1.1 2009/01/10 19:26:06 akurz Exp $

## Mac 128k/512k/Plus Keyboard Protococol

## AT/PS2 Keyboard Protocol

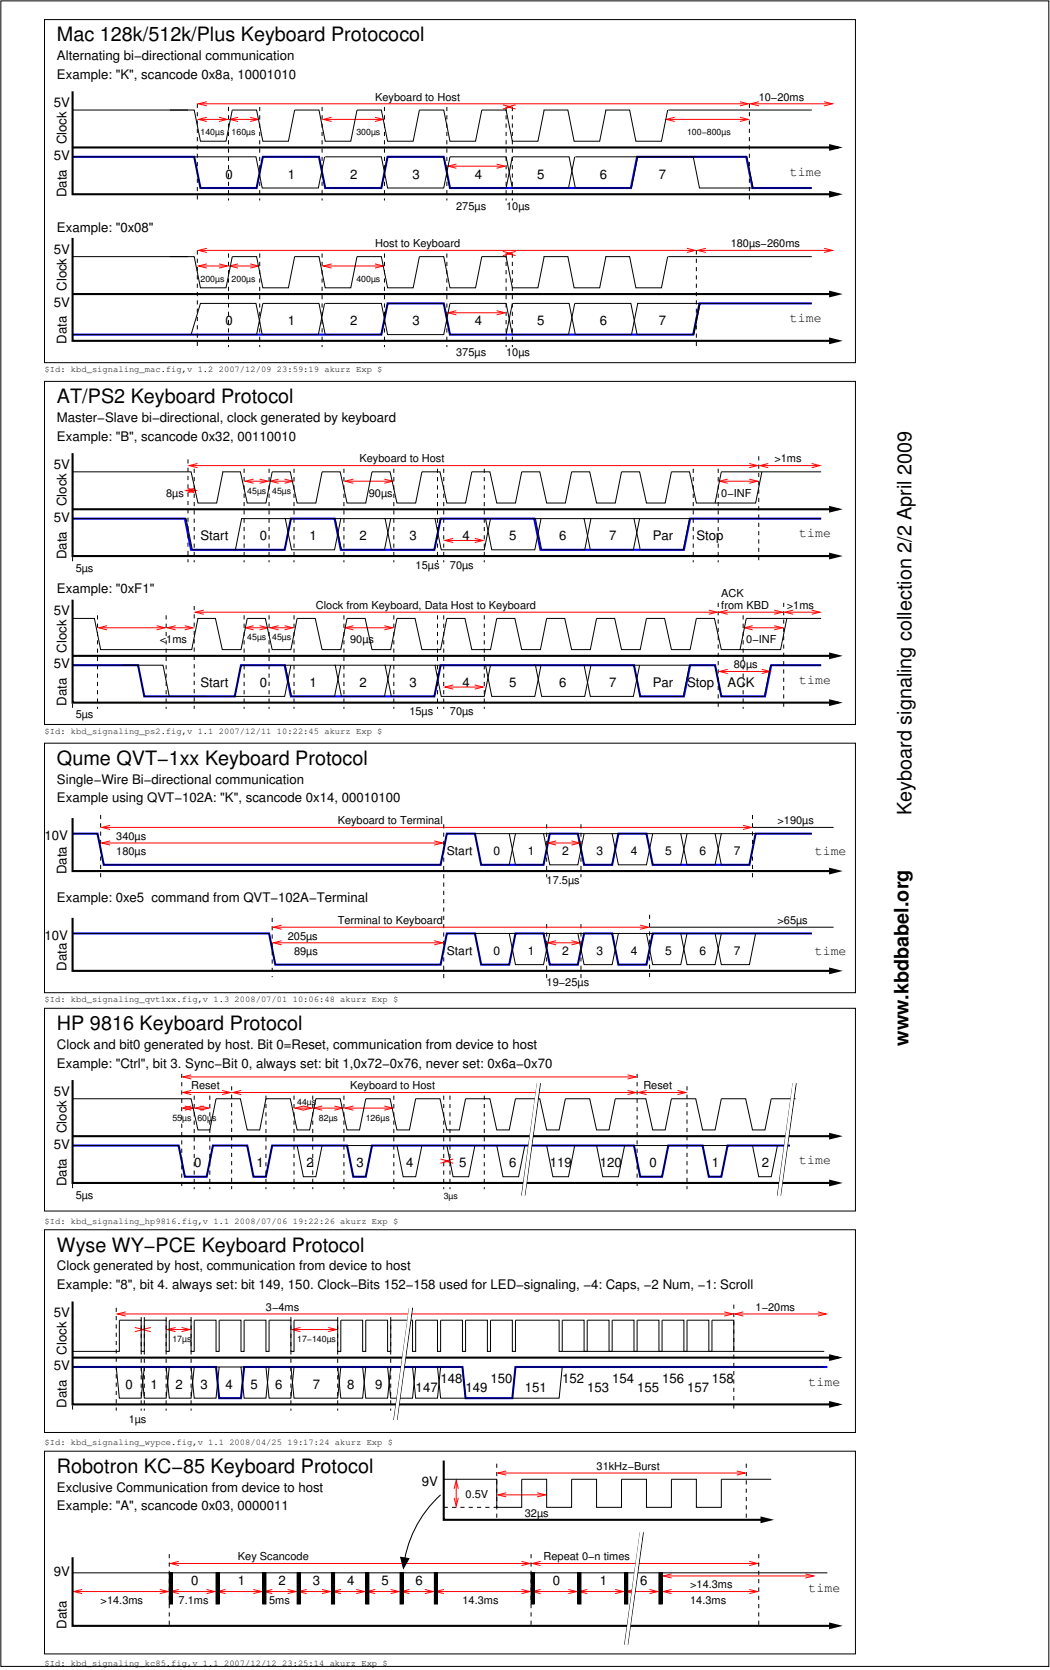
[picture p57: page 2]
5V 5VData Clock; Keyboard to Host; Start; Par Stop; ACK; Par; Stop; ACK from KBD; 0−INF; 10VData; Reset; 31kHz−Burst; Data; Key Scancode; Repeat 0−n times; time; Example: "0x08"; Example: "0xF1"

Alternating bi−directional communication
Example: "K", scancode 0x8a, 10001010

Host to Keyboard

$Id: kbd_signaling_mac.fig,v 1.2 2007/12/09 23:59:19 akurz Exp $

Master−Slave bi−directional, clock generated by keyboard
Example: "B", scancode 0x32, 00110010

www.kbdbabel.org Keyboard signaling collection 2/2 April 2009

Keyboard to Host

Clock from Keyboard, Data Host to Keyboard

$Id: kbd_signaling_ps2.fig,v 1.1 2007/12/11 10:22:45 akurz Exp $
Qume QVT−1xx Keyboard Protocol
Single−Wire Bi−directional communication
Example using QVT−102A: "K", scancode 0x14, 00010100

Keyboard to Terminal

Example: 0xe5 command from QVT−102A−Terminal

Terminal to Keyboard

$Id: kbd_signaling_qvt1xx.fig,v 1.3 2008/07/01 10:06:48 akurz Exp $
HP 9816 Keyboard Protocol
Clock and bit0 generated by host. Bit 0=Reset, communication from device to host
Example: "Ctrl", bit 3. Sync−Bit 0, always set: bit 1,0x72−0x76, never set: 0x6a−0x70

$Id: kbd_signaling_hp9816.fig,v 1.1 2008/07/06 19:22:26 akurz Exp $
Wyse WY−PCE Keyboard Protocol
Clock generated by host, communication from device to host
Example: "8", bit 4. always set: bit 149, 150. Clock−Bits 152−158 used for LED−signaling, −4: Caps, −2 Num, −1: Scroll

$Id: kbd_signaling_wypce.fig,v 1.1 2008/04/25 19:17:24 akurz Exp $
Robotron KC−85 Keyboard Protocol
Exclusive Communication from device to host
Example: "A", scancode 0x03, 0000011

$Id: kbd_signaling_kc85.fig,v 1.1 2007/12/12 23:25:14 akurz Exp $

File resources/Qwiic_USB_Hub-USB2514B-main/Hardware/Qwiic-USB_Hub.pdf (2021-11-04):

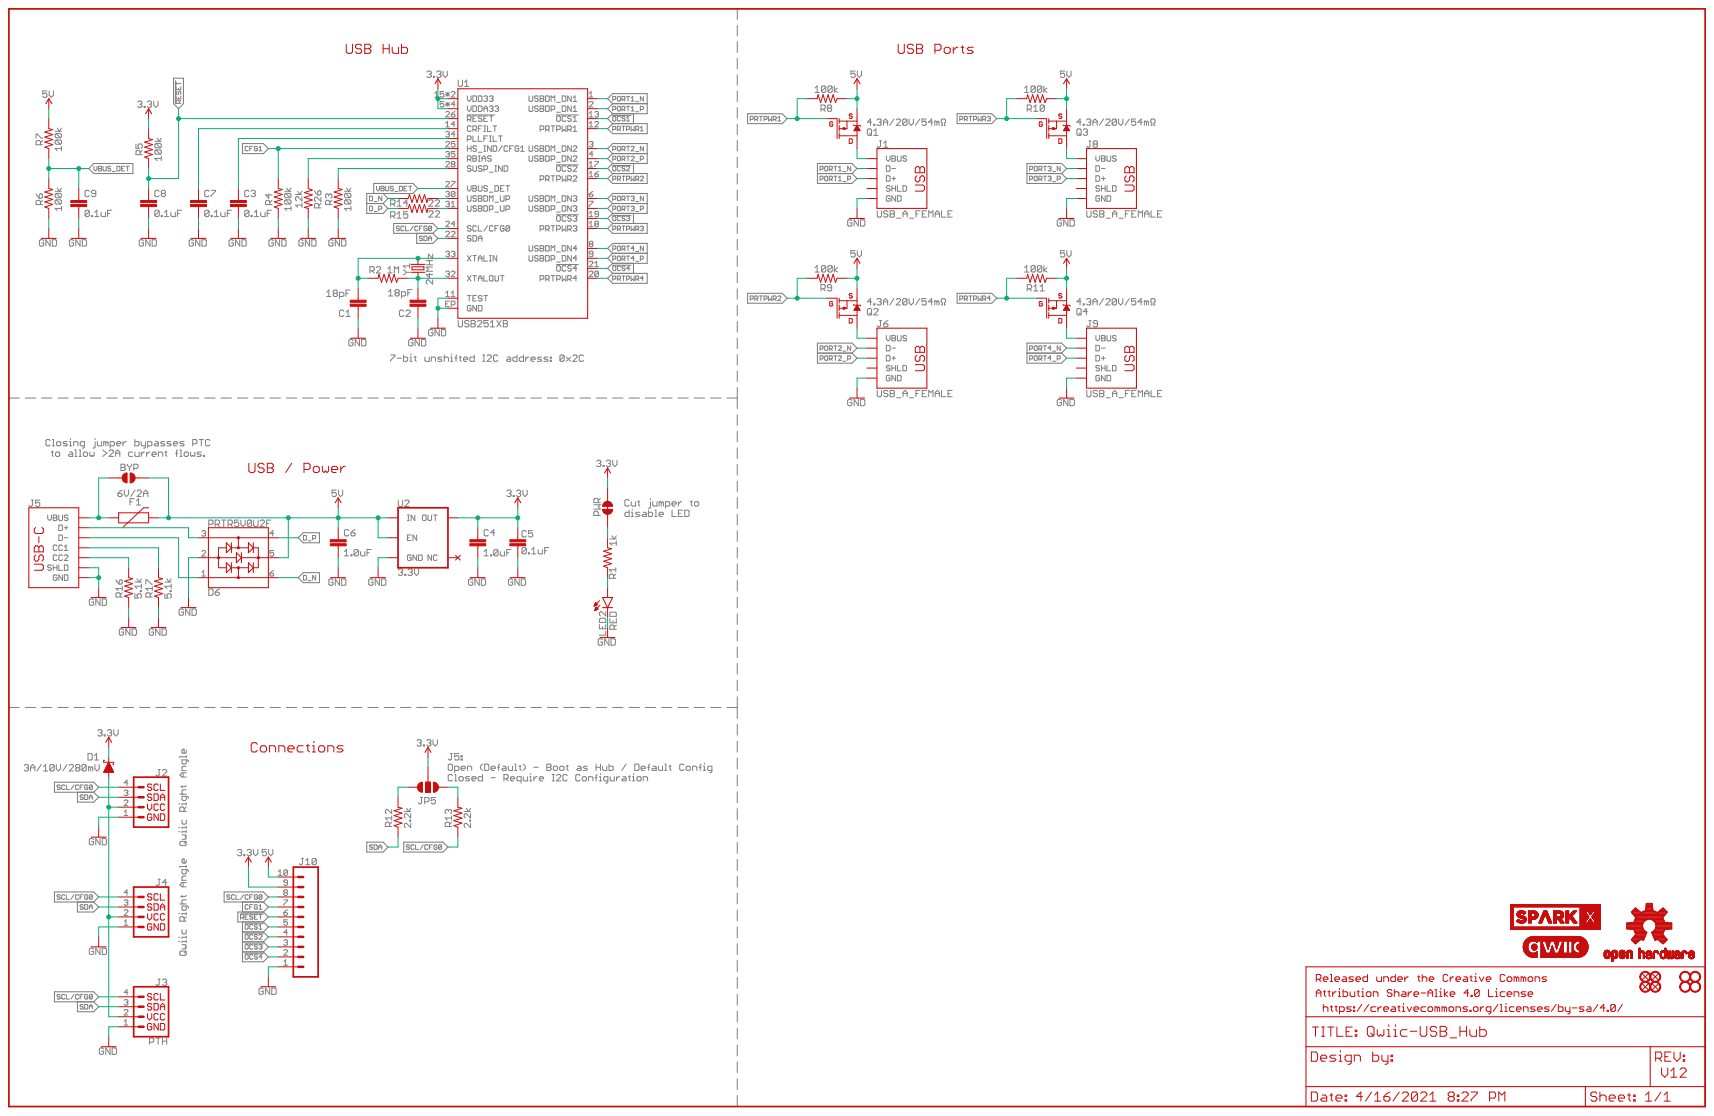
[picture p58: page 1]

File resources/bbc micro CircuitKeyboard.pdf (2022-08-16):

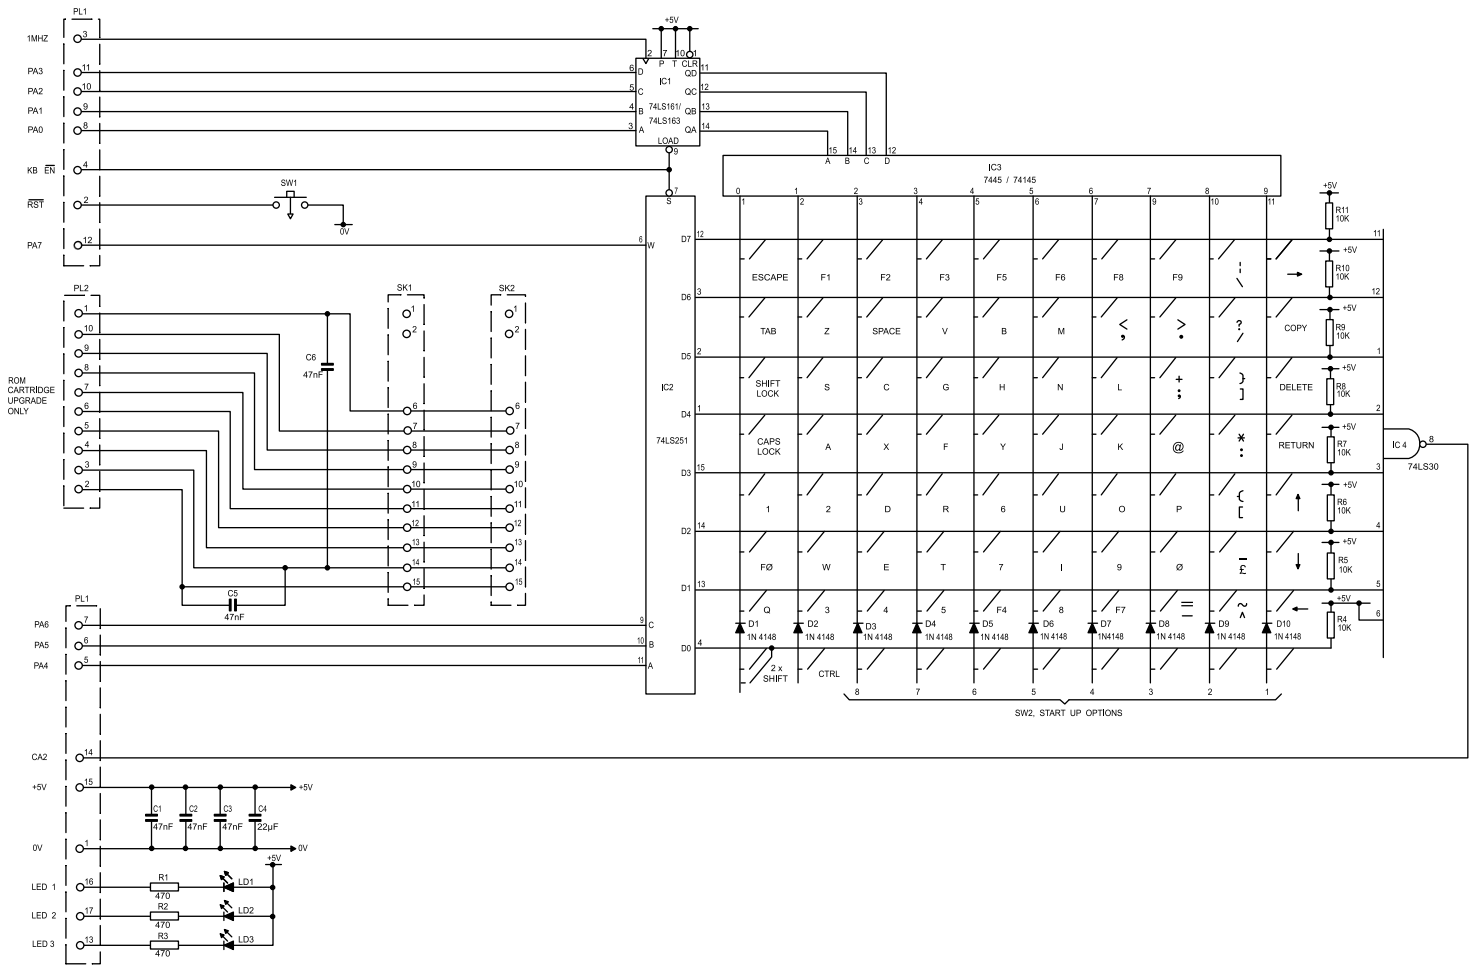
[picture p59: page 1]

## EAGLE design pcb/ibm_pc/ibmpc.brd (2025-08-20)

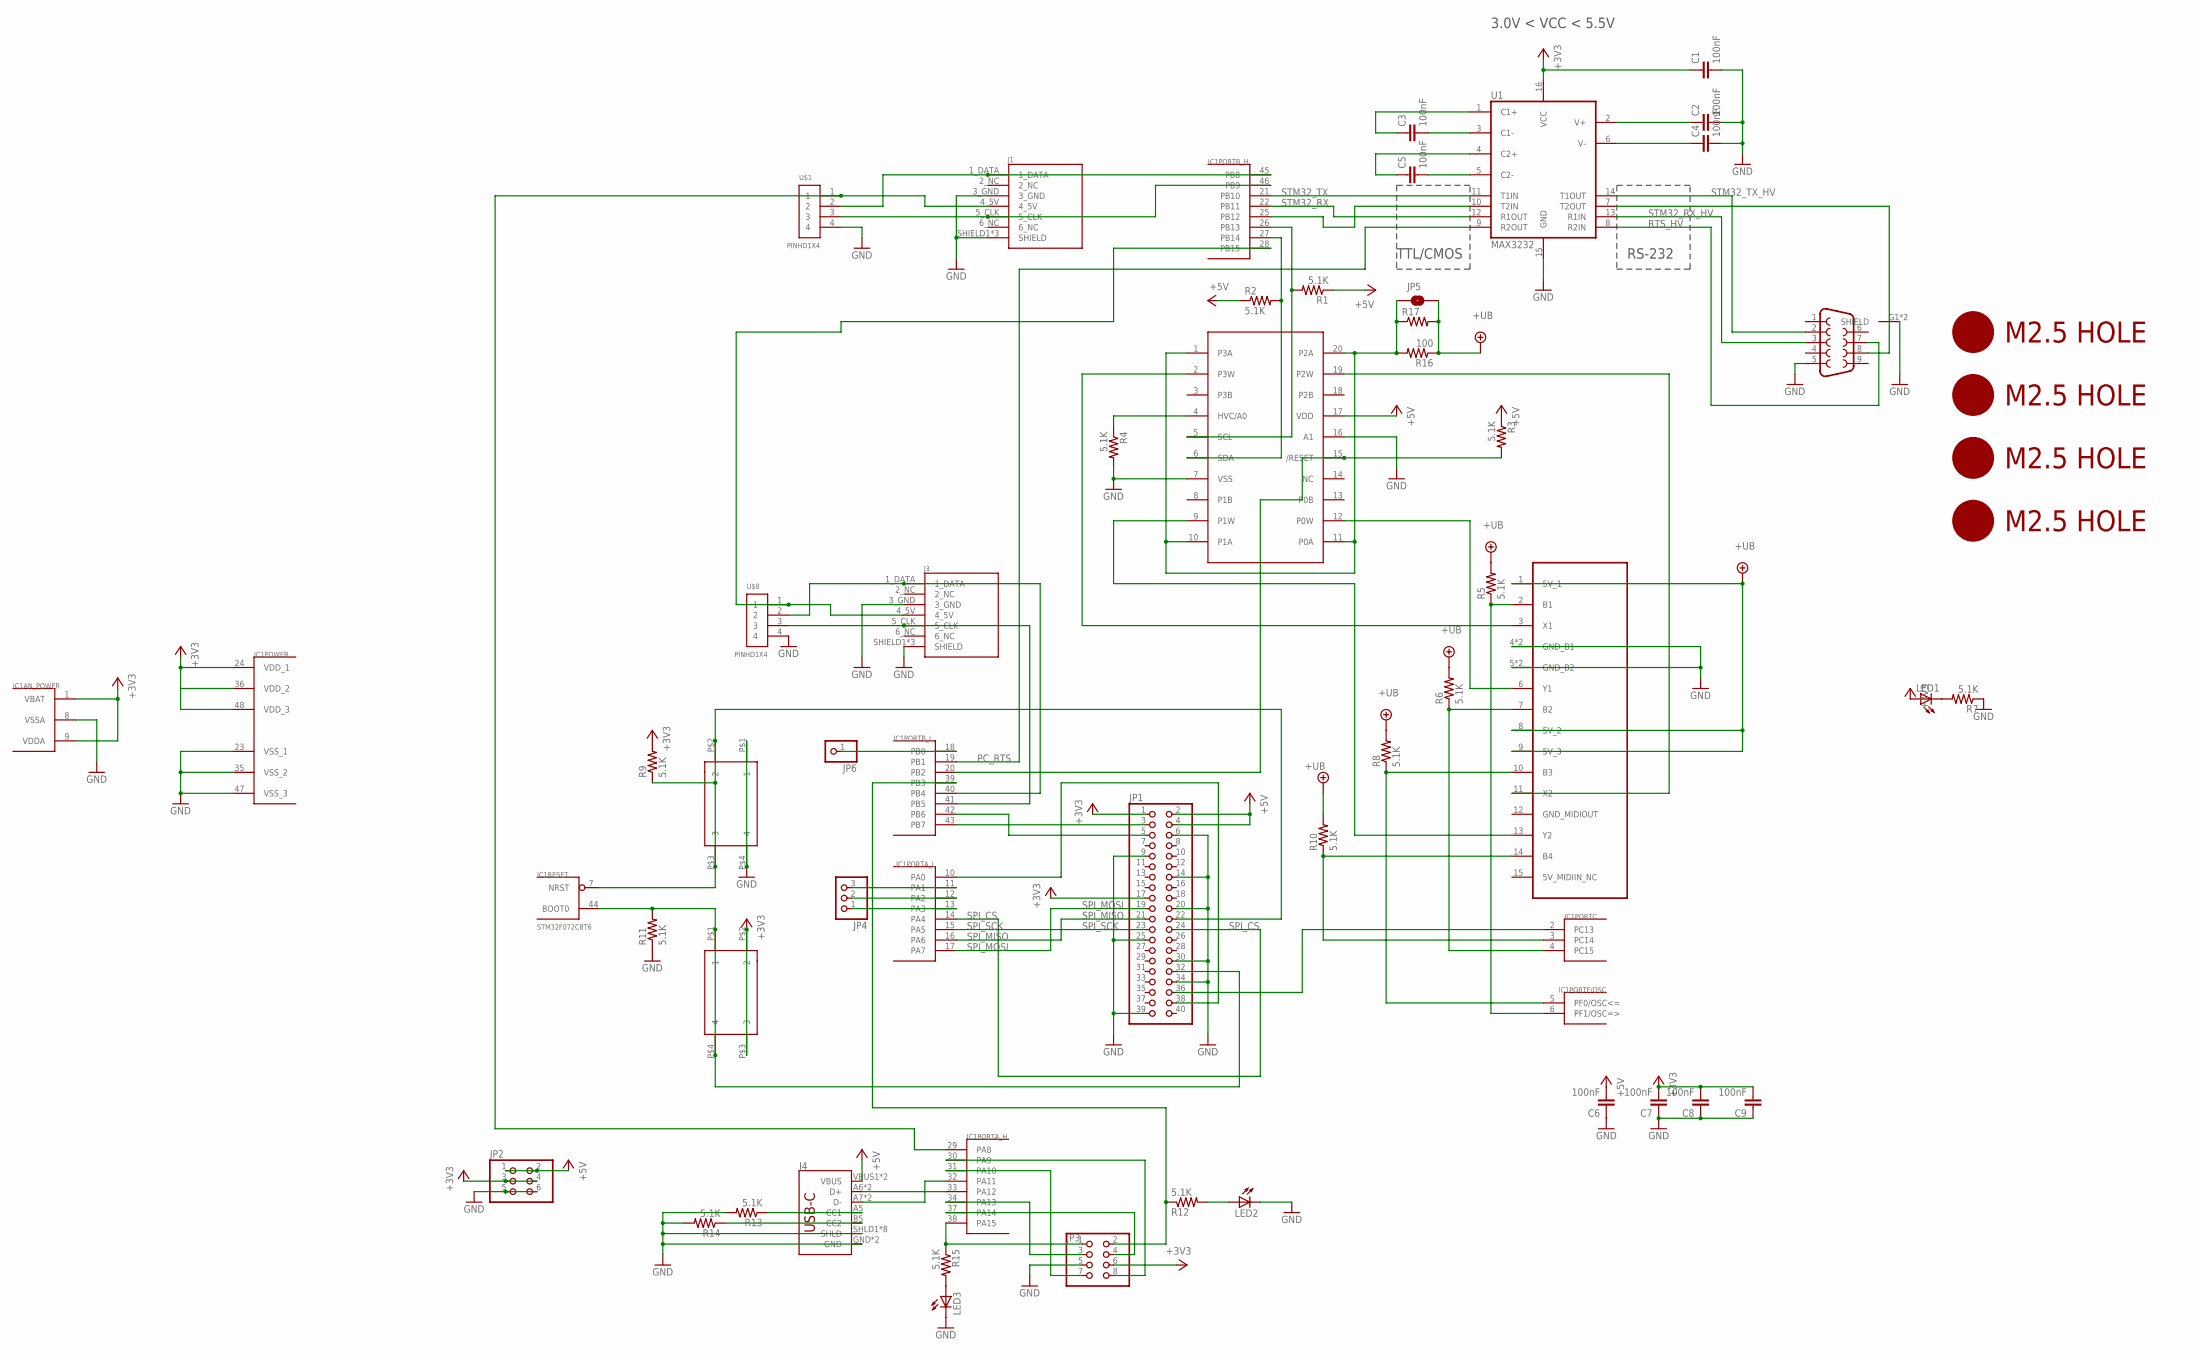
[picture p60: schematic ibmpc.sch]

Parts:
C1, C2, C3, C4, C5, C6, C7, C8, C9: 100nF; 0805@1
IC1: STM32F072C8T6; TQFP48
J1, J3: DIN7
J2: DB9MALE; DB9_MALE
J4: USB_C16PIN; USB-C-16P
JP1: PINHD-2X20-BIG; 2X20-BIG
JP2: PINHD-2X3; 2X03
JP3: PINHD-2X4; 2X04
JP4: PINHD-1X3CB; 1X03-CLEANBIG
JP5: JUMPER-SMT_2_NO_NO-SILK; SMT-JUMPER_2_NO_NO-SILK
JP6: PINHD-1X1CB; 1X01-CLEANBIG
LED1, LED2, LED3: LEDCHIP-LED0805; CHIP-LED0805
R1, R2, R3, R4, R5, R6, R7, R8, R9, R10, R11, R12, R13, R14, R15: 5.1K; 0805
R16: 100; 0805
R17: R-US_0204/7; 0204/7
SW1, SW2: 324_SW; 342_SWICH_FOOT
U1: MAX3232; SO016
U$1, U$8: PINHD1X4; 1X04-CLEANBIG
U$2, U$3, U$6, U$7: M2.5HOLE
U$5: MCP4451; TSSOP20
U$9: GAMEPORT_15P; DA15

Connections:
+3V3: C1.1, C7.2, C8.2, C9.2, IC1.1 (VBAT), IC1.9 (VDDA), IC1.24 (VDD_1), IC1.36 (VDD_2), IC1.48 (VDD_3), JP1.1, JP1.17, JP2.3, JP2.4, JP3.6, LED1.A, R9.2, SW2.P$2 (2), SW2.P$3 (3), U1.16 (VCC)
+5V: C6.2, J4.VBUS1 (VBUS), J4.VBUS2 (VBUS), JP1.2, JP1.4, JP2.1, JP2.2, R1.1, R2.1, R3.1, U$5.17 (VDD)
+UB: JP5.2, R5.2, R6.2, R8.2, R10.2, R16.1, R17.2, U$9.1 (5V_1), U$9.8 (5V_2), U$9.9 (5V_3)
C1+: C3.1, U1.1 (C1+)
C1-: C3.2, U1.3 (C1-)
C2+: C5.1, U1.4 (C2+)
C2-: C5.2, U1.5 (C2-)
GND: C1.2, C2.2, C4.2, C6.1, C7.1, C8.1, C9.1, IC1.8 (VSSA), IC1.23 (VSS_1), IC1.35 (VSS_2), IC1.47 (VSS_3), J1.3_GND, J1.SHIELD1 (SHIELD), J1.SHIELD2 (SHIELD), J1.SHIELD3 (SHIELD), J2.5, J2.G1 (SHIELD), J2.G2 (SHIELD), J3.3_GND, J3.SHIELD1 (SHIELD), J3.SHIELD2 (SHIELD), J3.SHIELD3 (SHIELD), J4.GND, J4.GND2 (GND), J4.SHLD1 (SHLD), J4.SHLD2 (SHLD), J4.SHLD3 (SHLD), J4.SHLD4 (SHLD), J4.SHLD5 (SHLD), J4.SHLD6 (SHLD), J4.SHLD7 (SHLD), J4.SHLD8 (SHLD), JP1.6, JP1.9, JP1.14, JP1.20, JP1.25, JP1.30, JP1.34, JP1.39, JP2.5, JP2.6, JP3.5, LED2.C, LED3.C, R4.2, R7.1, R11.1, R13.2, R14.2, SW1.P$1 (1), SW1.P$4 (4), U1.15 (GND), U$1.4, U$5.7 (VSS), U$5.16 (A1), U$8.4, U$9.4 (GND_B1), U$9.5 (GND_B2), U$9.G1 (GND_B1), U$9.G2 (GND_B2)
unnamed: J4.A5 (CC1), R13.1
unnamed: LED2.A, R12.2
unnamed: IC1.10 (PA0), JP1.38
unnamed: IC1.29 (PA8), J1.4_5V, U$1.1
unnamed: IC1.41 (PB5), J3.5_CLK, U$8.3
unnamed: IC1.39 (PB3), JP3.2, R12.1
unnamed: J4.B5 (CC2), R14.1
unnamed: IC1.33 (PA12), J4.A6 (D+), J4.B6 (D+)
unnamed: IC1.32 (PA11), J4.A7 (D-), J4.B7 (D-)
unnamed: IC1.45 (PB8), J1.1_DATA, U$1.2
unnamed: IC1.46 (PB9), J1.5_CLK, U$1.3
unnamed: IC1.31 (PA10), JP3.7
unnamed: IC1.7 (NRST), JP1.22, R9.1, SW1.P$2 (2), SW1.P$3 (3)
unnamed: IC1.30 (PA9), JP3.8
unnamed: IC1.34 (PA13), JP3.3
unnamed: IC1.37 (PA14), JP3.4
unnamed: JP5.1, R16.2, R17.1, U$5.1 (P3A), U$5.10 (P1A), U$5.11 (P0A), U$5.20 (P2A)
unnamed: IC1.44 (BOOT0), JP1.32, R11.2, SW2.P$1 (1), SW2.P$4 (4)
unnamed: IC1.4 (PC15), R6.1, U$9.7 (B2)
unnamed: IC1.5 (PF0/OSC<=), R8.1, U$9.10 (B3)
unnamed: IC1.3 (PC14), R10.1, U$9.14 (B4)
unnamed: IC1.42 (PB6), JP1.5
unnamed: IC1.43 (PB7), JP1.3
unnamed: IC1.25 (PB12), U1.10 (T2IN)
unnamed: J2.8, U1.7 (T2OUT)
unnamed: IC1.40 (PB4), J3.1_DATA, U$8.2
unnamed: IC1.38 (PA15), JP3.1, R15.1
unnamed: LED3.A, R15.2
unnamed: LED1.C, R7.2
unnamed: IC1.18 (PB0), JP6.1
unnamed: IC1.6 (PF1/OSC=>), R5.1, U$9.2 (B1)
unnamed: R4.1, U$5.4 (HVC/A0)
unnamed: IC1.2 (PC13), JP1.36
unnamed: IC1.11 (PA1), JP4.3
unnamed: IC1.12 (PA2), JP4.2
unnamed: IC1.13 (PA3), JP4.1
unnamed: IC1.28 (PB15), J3.4_5V, U$8.1
unnamed: IC1.20 (PB2), R3.2, U$5.15 (/RESET)
PC_RTS: IC1.19 (PB1), U1.9 (R2OUT)
POT_SCL: IC1.26 (PB13), R1.2, U$5.5 (SCL)
PST_SDA: IC1.27 (PB14), R2.2, U$5.6 (SDA)
RTS_HV: J2.7, U1.8 (R2IN)
SPI_CS: IC1.14 (PA4), JP1.24
SPI_MISO: IC1.16 (PA6), JP1.21
SPI_MOSI: IC1.17 (PA7), JP1.19
SPI_SCK: IC1.15 (PA5), JP1.23
STM32_RX: IC1.22 (PB11), U1.12 (R1OUT)
STM32_RX_HV: J2.3, U1.13 (R1IN)
STM32_TX: IC1.21 (PB10), U1.11 (T1IN)
STM32_TX_HV: J2.2, U1.14 (T1OUT)
V+: C2.1, U1.2 (V+)
V-: C4.1, U1.6 (V-)
X1_W3: U$5.2 (P3W), U$9.3 (X1)
X2_W2: U$5.19 (P2W), U$9.11 (X2)
Y1_W0: U$5.12 (P0W), U$9.6 (Y1)
Y2_W1: U$5.9 (P1W), U$9.13 (Y2)

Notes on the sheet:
RS-232
TTL/CMOS
3.0V < VCC < 5.5V

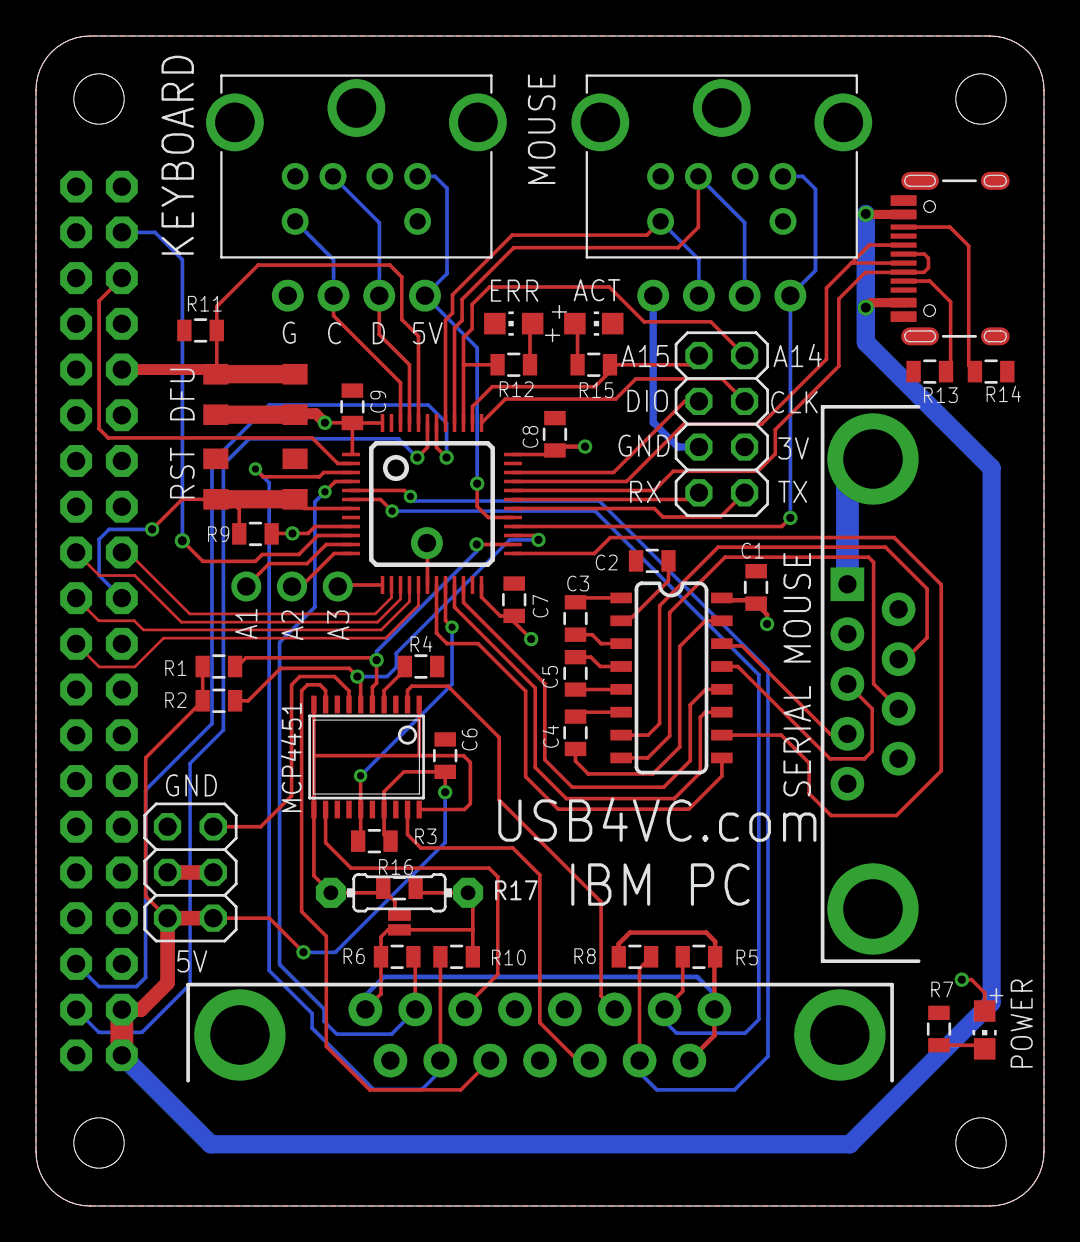
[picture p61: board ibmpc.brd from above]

Board: 2 copper layers, 56.0 x 65.0 mm, 51 parts (1 on the bottom side), 64 nets.

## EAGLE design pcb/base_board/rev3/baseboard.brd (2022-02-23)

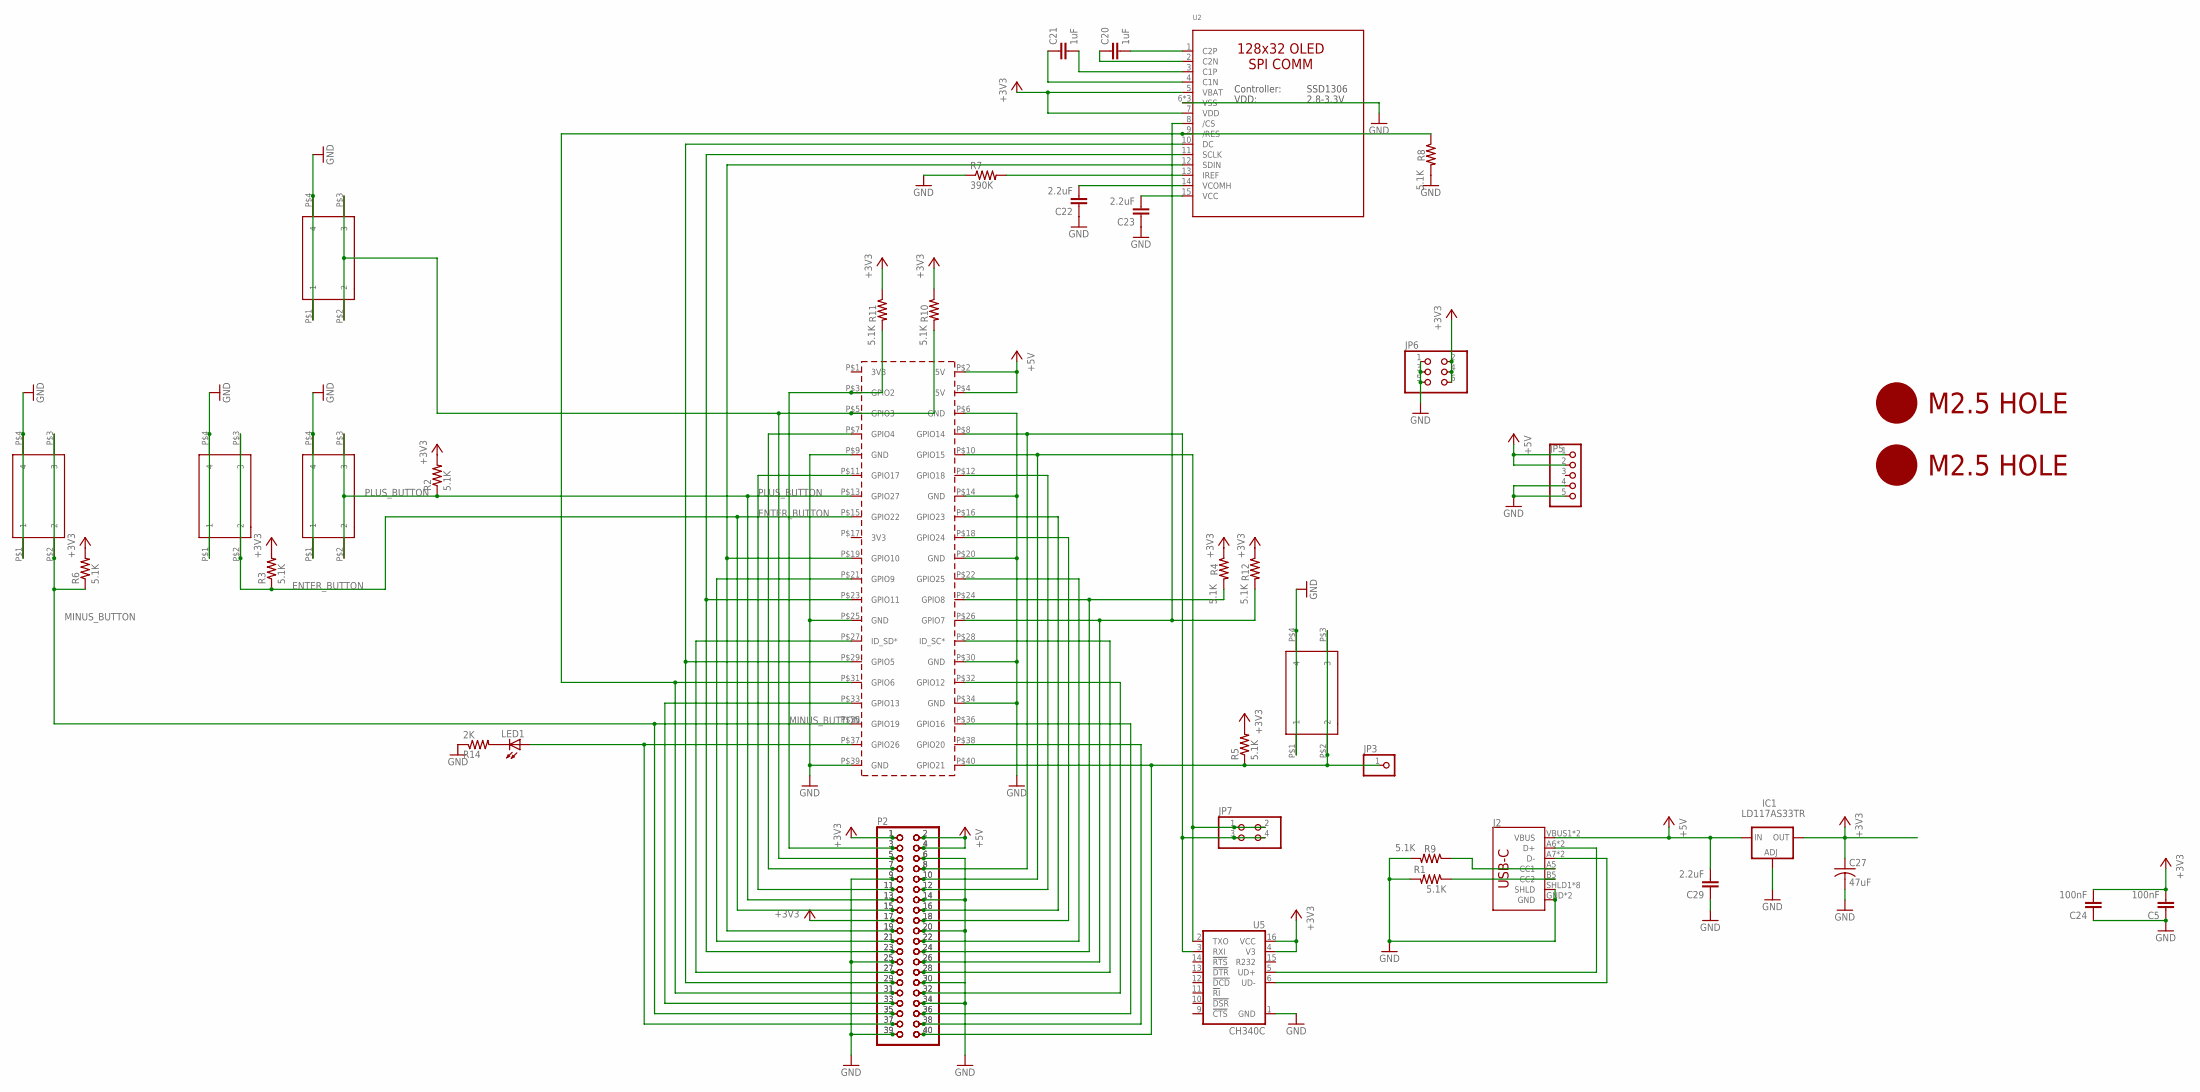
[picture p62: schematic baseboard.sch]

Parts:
C5, C24: 100nF; 0805
C20, C21: 1uF; 0805
C22, C23, C29: 2.2uF; 0805
C27: 47uF; C1210
IC1: LD117AS33TR; SOT223
J2: USB_C16PIN; USB-C-16P
JP3: PINHD-1X1; 1X01
JP5: PINHD-1X5; 1X05
JP6: PINHD-2X3; 2X03
JP7: PINHD-2X2; 2X02
LED1: LEDCHIP-LED0805; CHIP-LED0805
P1: RPI3NO-CONNECTORS; RPI3-NO-CONNECTORS
P2, P3: PINHD-2X20-BIG; 2X20-BIG
R1, R2, R3, R4, R5, R6, R8, R9, R10, R11, R12: 5.1K; 0805
R7: 390K; 0805
R14: 2K; 0805
SW1, SW2, SW3, SW4, SW20: 324_SW; 342_SWICH_FOOT
U2: LUL_DISP_OLED_UG-2864HSWEG01; LUL_UG-2864HSWEG01_1.3_WRAPAROUND
U5: CH340C; SO016
U$2, U$3: M2.5HOLE

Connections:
+3V3: C5.2, C24.2, C27.1, IC1.4 (OUT), JP6.2, JP6.4, JP6.6, P2.1, P2.17, P3.1, P3.17, R2.2, R3.2, R4.1, R5.2, R6.2, R10.1, R11.1, R12.1, U2.5 (VBAT), U2.7 (VDD), U5.4 (V3), U5.16 (VCC)
+5V: C29.2, IC1.3 (IN), J2.VBUS1 (VBUS), J2.VBUS2 (VBUS), JP5.1, JP5.2, P1.P$2 (5V), P1.P$4 (5V), P2.2, P2.4, P3.2, P3.4
ENTER_BUTTON: P1.P$15 (GPIO22), P2.15, P3.15, R3.1, SW20.P$2 (2), SW20.P$3 (3)
GND: C5.1, C22.1, C23.1, C24.1, C27.2, C29.1, IC1.1 (ADJ), J2.GND, J2.GND2 (GND), J2.SHLD1 (SHLD), J2.SHLD2 (SHLD), J2.SHLD3 (SHLD), J2.SHLD4 (SHLD), J2.SHLD5 (SHLD), J2.SHLD6 (SHLD), J2.SHLD7 (SHLD), J2.SHLD8 (SHLD), JP5.4, JP5.5, JP6.1, JP6.3, JP6.5, P1.P$6 (GND), P1.P$9 (GND), P1.P$14 (GND), P1.P$20 (GND), P1.P$25 (GND), P1.P$30 (GND), P1.P$34 (GND), P1.P$39 (GND), P2.6, P2.9, P2.14, P2.20, P2.25, P2.30, P2.34, P2.39, P3.6, P3.9, P3.14, P3.20, P3.25, P3.30, P3.34, P3.39, R1.2, R7.1, R8.2, R9.2, R14.1, SW1.P$1 (1), SW1.P$4 (4), SW2.P$1 (1), SW2.P$4 (4), SW3.P$1 (1), SW3.P$4 (4), SW4.P$1 (1), SW4.P$4 (4), SW20.P$1 (1), SW20.P$4 (4), U2.6 (VSS), U2.16 (VSS), U2.17 (VSS), U5.1 (GND)
MINUS_BUTTON: P1.P$35 (GPIO19), P2.35, P3.35, R6.1, SW4.P$2 (2), SW4.P$3 (3)
unnamed: J2.A6 (D+), J2.B6 (D+), U5.5 (UD+)
unnamed: J2.A5 (CC1), R9.1
unnamed: J2.A7 (D-), J2.B7 (D-), U5.6 (UD-)
unnamed: LED1.A, P1.P$37 (GPIO26), P2.37, P3.37
unnamed: P1.P$3 (GPIO2), P2.3, P3.3, R11.2
unnamed: P1.P$5 (GPIO3), P2.5, P3.5, R10.2, SW2.P$2 (2), SW2.P$3 (3)
unnamed: J2.B5 (CC2), R1.1
unnamed: P1.P$7 (GPIO4), P2.7, P3.7
unnamed: P1.P$11 (GPIO17), P2.11, P3.11
unnamed: LED1.C, R14.2
unnamed: P1.P$19 (GPIO10), P2.19, P3.19, U2.12 (SDIN)
unnamed: P1.P$21 (GPIO9), P2.21, P3.21
unnamed: P1.P$23 (GPIO11), P2.23, P3.23, U2.11 (SCLK)
unnamed: P1.P$27 (ID_SD*), P2.27, P3.27
unnamed: P1.P$29 (GPIO5), P2.29, P3.29, U2.10 (DC)
unnamed: P1.P$33 (GPIO13), P2.33, P3.33
unnamed: P1.P$12 (GPIO18), P2.12, P3.12
unnamed: P1.P$16 (GPIO23), P2.16, P3.16
unnamed: P1.P$18 (GPIO24), P2.18, P3.18
unnamed: P1.P$22 (GPIO25), P2.22, P3.22
unnamed: P1.P$24 (GPIO8), P2.24, P3.24, R4.2
unnamed: P1.P$26 (GPIO7), P2.26, P3.26, R12.2, U2.8 (/CS)
unnamed: P1.P$28 (ID_SC*), P2.28, P3.28
unnamed: P1.P$32 (GPIO12), P2.32, P3.32
unnamed: P1.P$36 (GPIO16), P2.36, P3.36
unnamed: P1.P$38 (GPIO20), P2.38, P3.38
unnamed: JP3.1, P1.P$40 (GPIO21), P2.40, P3.40, R5.1, SW3.P$2 (2), SW3.P$3 (3)
unnamed: C20.2, U2.1 (C2P)
unnamed: C20.1, U2.2 (C2N)
unnamed: C21.2, U2.3 (C1P)
unnamed: C21.1, U2.4 (C1N)
unnamed: R7.2, U2.13 (IREF)
unnamed: C22.2, U2.14 (VCOMH)
unnamed: C23.2, U2.15 (VCC)
unnamed: P1.P$31 (GPIO6), P2.31, P3.31, R8.1, U2.9 (/RES)
PLUS_BUTTON: P1.P$13 (GPIO27), P2.13, P3.13, R2.1, SW1.P$2 (2), SW1.P$3 (3)
RPI_RX: JP7.1, JP7.2, P1.P$10 (GPIO15), P2.10, P3.10, U5.2 (TXO)
RPI_TX: JP7.3, JP7.4, P1.P$8 (GPIO14), P2.8, P3.8, U5.3 (RXI)

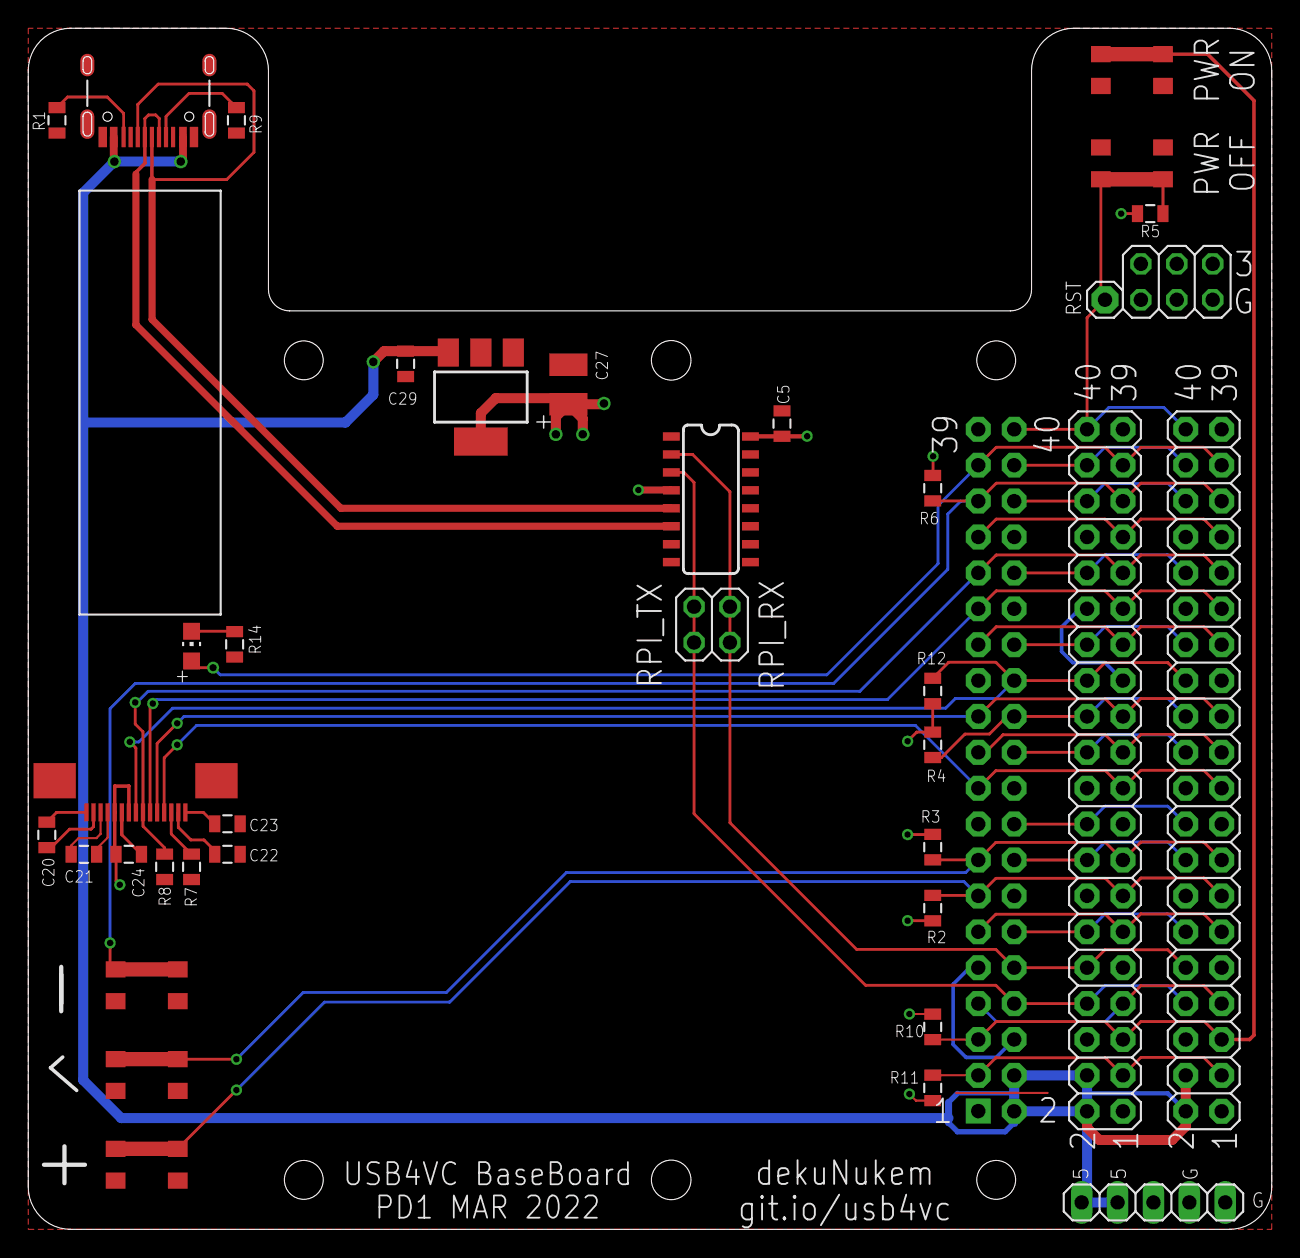
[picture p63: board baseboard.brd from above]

Board: 2 copper layers, 88.0 x 85.0 mm, 40 parts (0 on the bottom side), 43 nets.

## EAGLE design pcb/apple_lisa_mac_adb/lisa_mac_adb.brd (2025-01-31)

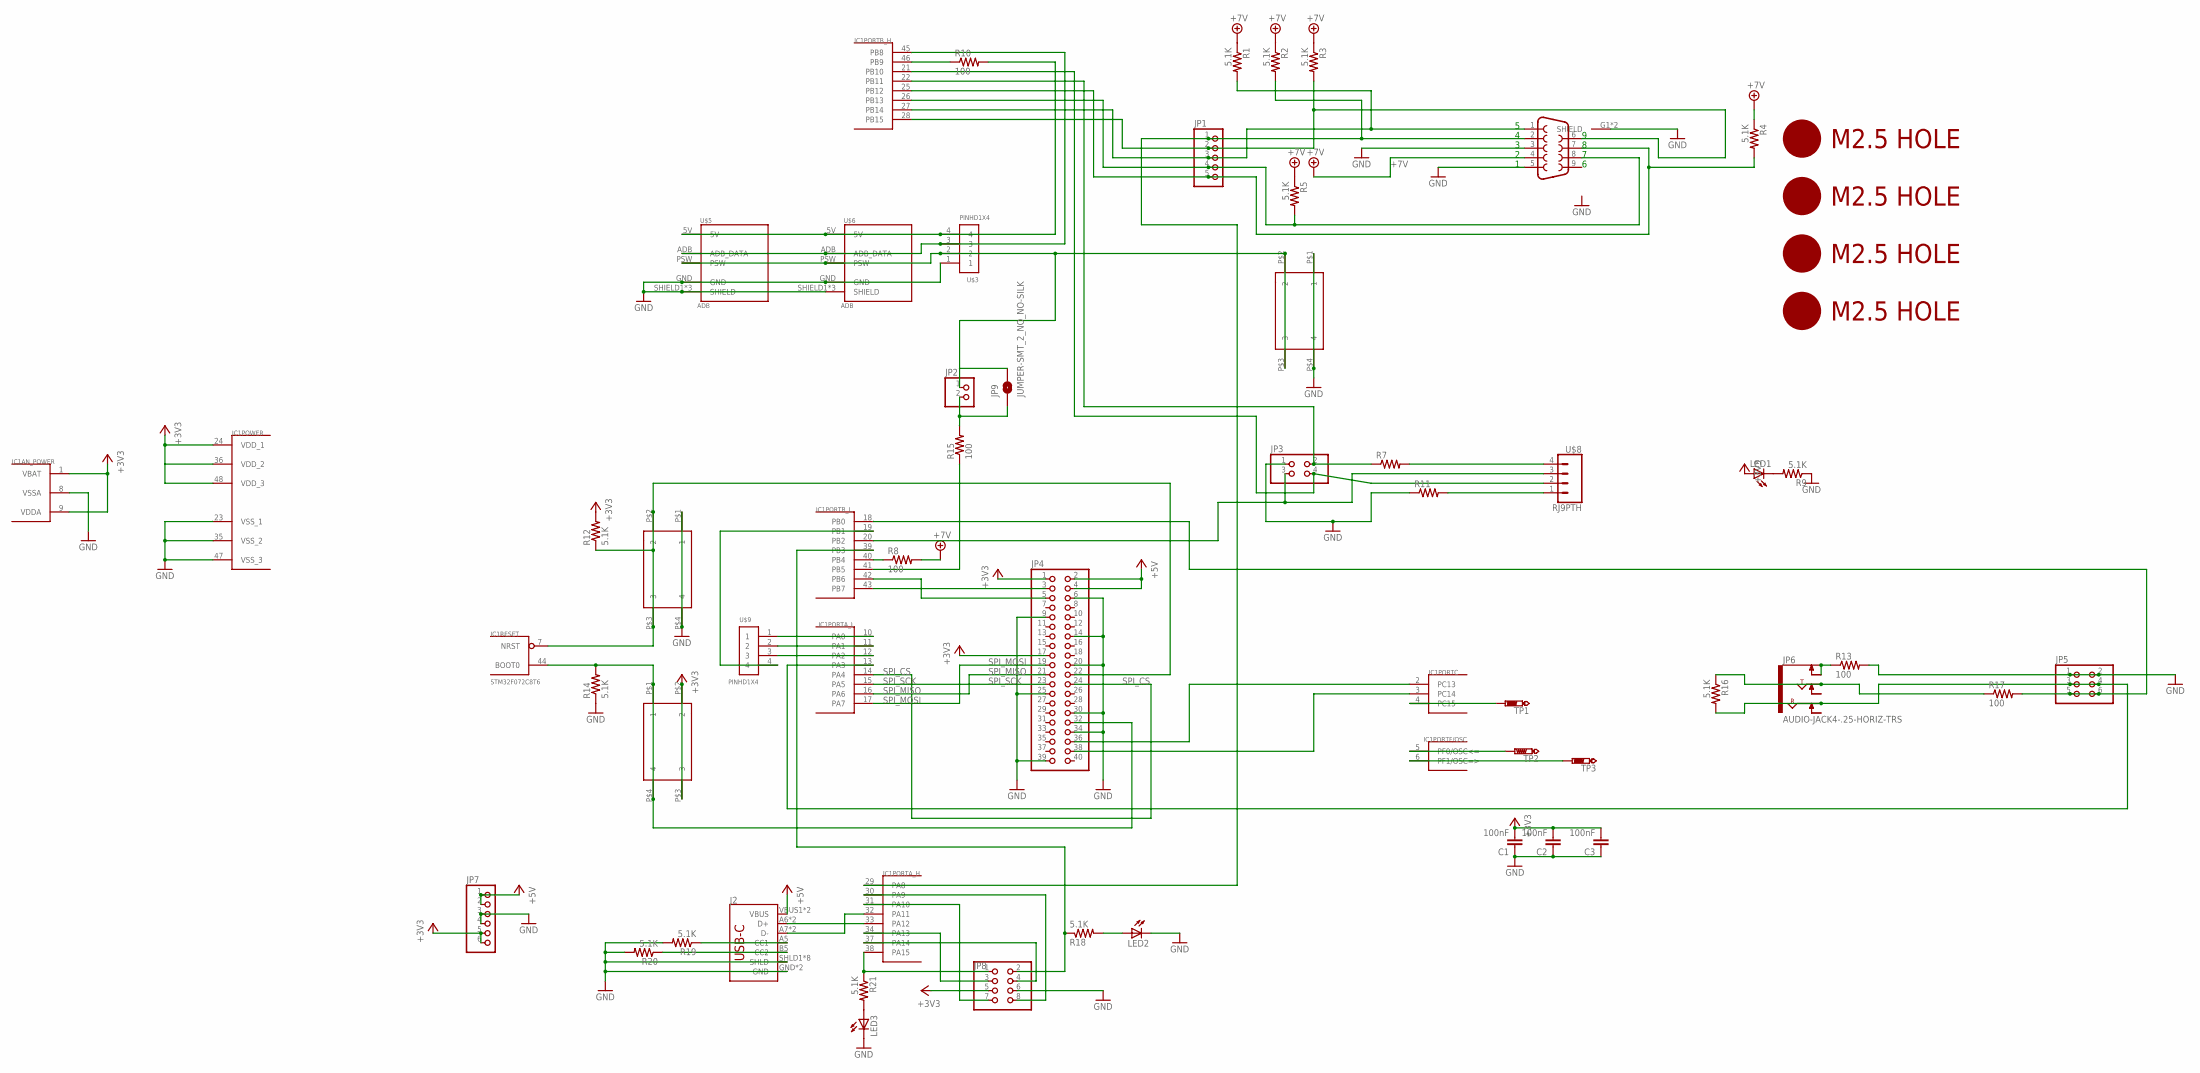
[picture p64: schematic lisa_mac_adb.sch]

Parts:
C1, C2, C3: 100nF; 0805@1
IC1: STM32F072C8T6; TQFP48
J1: DB9FEMALE; DB9
J2: USB_C16PIN; USB-C-16P
JP1: PINHD-1X5; 1X05
JP2: PINHD-1X2; 1X02
JP3: PINHD-2X2; 2X02
JP4: PINHD-2X20-BIG; 2X20-BIG
JP5: PINHD-2X3; 2X03
JP6: AUDIO-JACK4-.25-HORIZ-TRS; AUDIO-JACK-.25-INCH-HORIZ-PTH
JP7: PINHD-1X6CB; 1X06-CLEANBIG
JP8: PINHD-2X4; 2X04
JP9: JUMPER-SMT_2_NO_NO-SILK; SMT-JUMPER_2_NO_NO-SILK
LED1, LED2, LED3: LEDCHIP-LED0805; CHIP-LED0805
R1, R2, R3, R4, R5, R9, R12, R14, R16, R18, R19, R20, R21: 5.1K; 0805
R7, R8, R10, R11, R13, R15, R17: 100; 0805
SW1, SW2, SW3: 324_SW; 342_SWICH_FOOT
TP1, TP2, TP3: PTR1TP14R; TP14R
U$1, U$2, U$4, U$7: M2.5HOLE
U$3, U$9: PINHD1X4; 1X04-CLEANBIG
U$5, U$6: ADB; DIN4
U$8: RJ9PTH; RJ9

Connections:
+3V3: C1.2, C2.2, C3.2, IC1.1 (VBAT), IC1.9 (VDDA), IC1.24 (VDD_1), IC1.36 (VDD_2), IC1.48 (VDD_3), JP4.1, JP4.17, JP7.5, JP7.6, JP8.5, LED1.A, R12.2, SW3.P$2 (2), SW3.P$3 (3)
+5V: J2.VBUS1 (VBUS), J2.VBUS2 (VBUS), JP4.2, JP4.4, JP7.1, JP7.2
+7V: J1.4, R1.1, R2.1, R3.1, R4.1, R5.1, R8.2
GND: C1.1, C2.1, C3.1, IC1.8 (VSSA), IC1.23 (VSS_1), IC1.35 (VSS_2), IC1.47 (VSS_3), J1.3, J1.5, J1.G1 (SHIELD), J1.G2 (SHIELD), J2.GND, J2.GND2 (GND), J2.SHLD1 (SHLD), J2.SHLD2 (SHLD), J2.SHLD3 (SHLD), J2.SHLD4 (SHLD), J2.SHLD5 (SHLD), J2.SHLD6 (SHLD), J2.SHLD7 (SHLD), J2.SHLD8 (SHLD), JP3.1, JP4.6, JP4.9, JP4.14, JP4.20, JP4.25, JP4.30, JP4.34, JP4.39, JP5.1, JP5.2, JP7.3, JP7.4, JP8.6, LED2.C, LED3.C, R9.1, R11.1, R13.2, R14.1, R19.2, R20.2, SW1.P$1 (1), SW1.P$4 (4), SW2.P$1 (1), SW2.P$4 (4), U$3.1, U$5.GND, U$5.SHIELD1 (SHIELD), U$5.SHIELD2 (SHIELD), U$5.SHIELD3 (SHIELD), U$6.GND, U$6.SHIELD1 (SHIELD), U$6.SHIELD2 (SHIELD), U$6.SHIELD3 (SHIELD)
unnamed: J2.A5 (CC1), R19.1
unnamed: LED2.A, R18.2
unnamed: R10.2, U$3.4, U$5.5V, U$6.5V
unnamed: IC1.26 (PB13), J1.8, JP1.4, R5.2
unnamed: R7.2, U$8.4
unnamed: IC1.39 (PB3), JP8.2, R18.1
unnamed: J2.B5 (CC2), R20.1
unnamed: IC1.33 (PA12), J2.A6 (D+), J2.B6 (D+)
unnamed: IC1.32 (PA11), J2.A7 (D-), J2.B7 (D-)
unnamed: IC1.41 (PB5), R15.1
unnamed: IC1.19 (PB1), U$9.4
unnamed: IC1.31 (PA10), JP8.7
unnamed: IC1.7 (NRST), JP4.22, R12.1, SW2.P$2 (2), SW2.P$3 (3)
unnamed: IC1.30 (PA9), JP8.8
unnamed: IC1.34 (PA13), JP8.3
unnamed: IC1.37 (PA14), JP8.4
unnamed: IC1.22 (PB11), JP3.2, R7.1
unnamed: IC1.44 (BOOT0), JP4.32, R14.2, SW3.P$1 (1), SW3.P$4 (4)
unnamed: IC1.21 (PB10), JP3.4, U$8.2
unnamed: IC1.4 (PC15), TP1.TP
unnamed: R11.2, U$8.1
unnamed: IC1.42 (PB6), JP4.5
unnamed: IC1.43 (PB7), JP4.3
unnamed: JP6.SLEEVE (EARTH), JP6.SLEEVE-NORM (EARTH-NORM), R13.1
unnamed: IC1.20 (PB2), JP3.3, U$8.3
unnamed: IC1.27 (PB14), J1.1, JP1.3, R1.2
unnamed: IC1.38 (PA15), JP8.1, R21.1
unnamed: LED3.A, R21.2
unnamed: LED1.C, R9.2
unnamed: IC1.13 (PA3), JP5.3, JP5.4, JP6.RING, R16.2
unnamed: IC1.18 (PB0), JP5.5, JP5.6, R17.2
unnamed: JP6.TIP, R16.1, R17.1
unnamed: IC1.3 (PC14), JP4.38
unnamed: IC1.28 (PB15), J1.6, JP1.2, R3.2
unnamed: IC1.25 (PB12), J1.7, JP1.5, R4.2
unnamed: IC1.29 (PA8), J1.2, JP1.1, R2.2
unnamed: IC1.2 (PC13), JP4.36
unnamed: IC1.10 (PA0), U$9.1
unnamed: IC1.11 (PA1), U$9.2
unnamed: IC1.12 (PA2), U$9.3
unnamed: IC1.5 (PF0/OSC<=), TP2.TP
unnamed: IC1.6 (PF1/OSC=>), TP3.TP
unnamed: IC1.45 (PB8), U$3.3, U$5.ADB (ADB_DATA), U$6.ADB (ADB_DATA)
unnamed: IC1.40 (PB4), R8.1
unnamed: IC1.46 (PB9), R10.1
unnamed: JP2.1, JP9.2, SW1.P$2 (2), SW1.P$3 (3), U$3.2, U$5.PSW, U$6.PSW
unnamed: JP2.2, JP9.1, R15.2
SPI_CS: IC1.14 (PA4), JP4.24
SPI_MISO: IC1.16 (PA6), JP4.21
SPI_MOSI: IC1.17 (PA7), JP4.19
SPI_SCK: IC1.15 (PA5), JP4.23

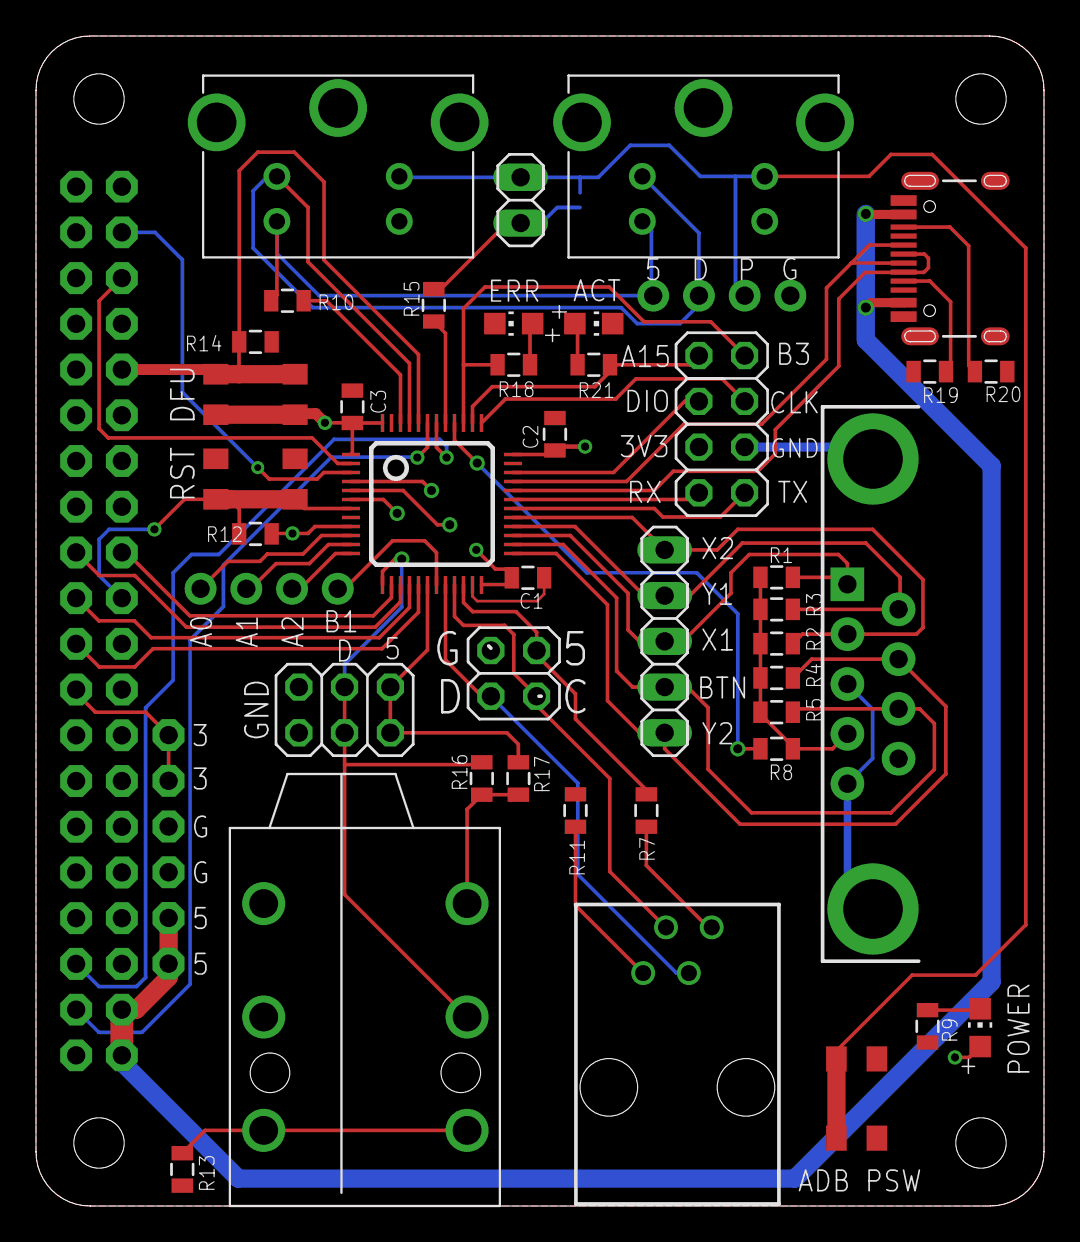
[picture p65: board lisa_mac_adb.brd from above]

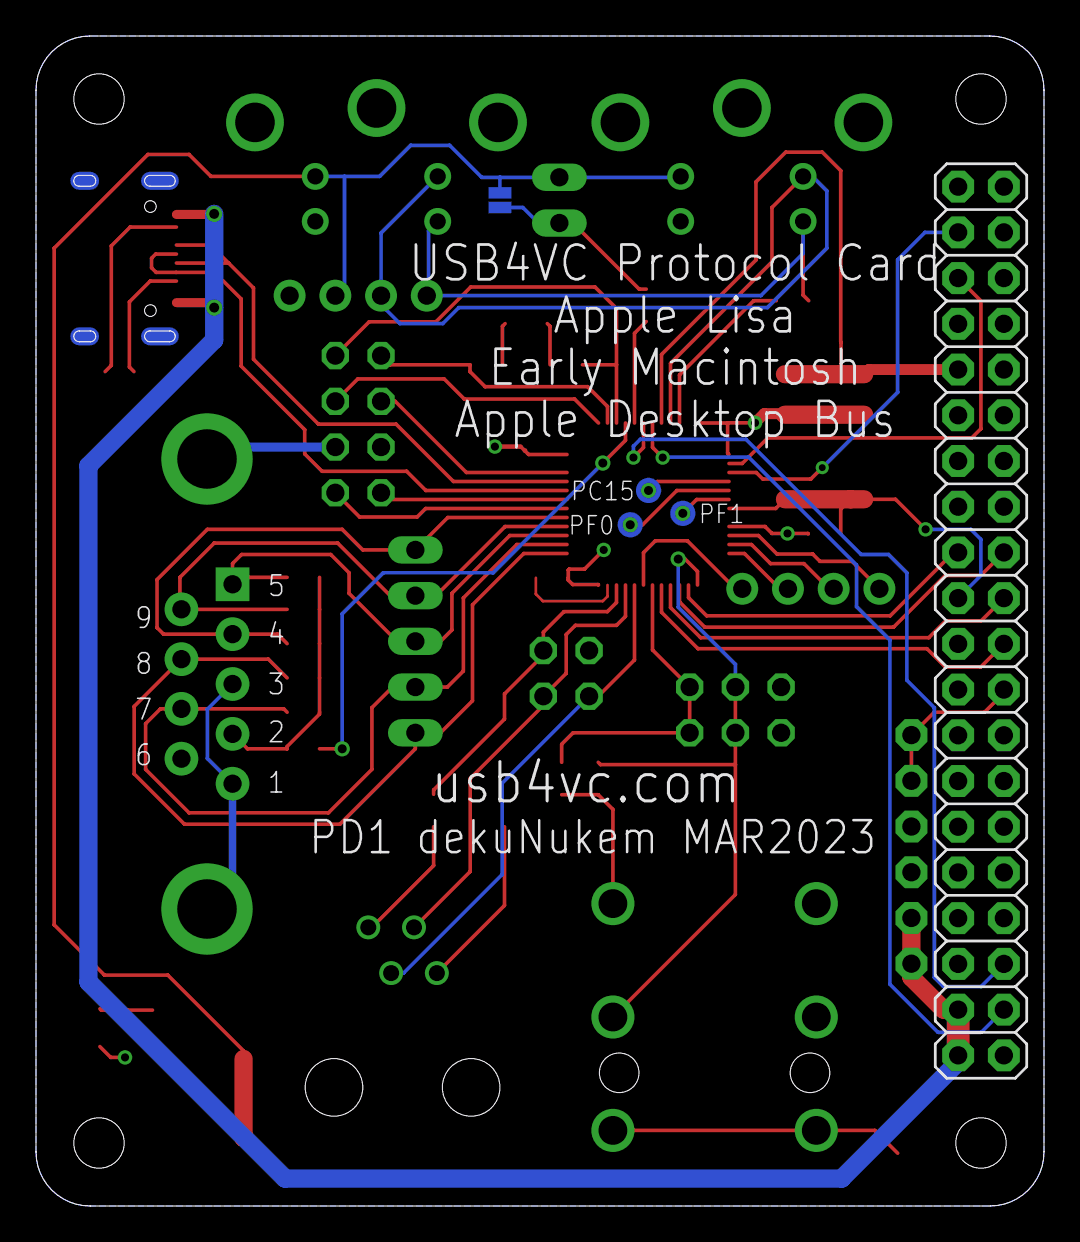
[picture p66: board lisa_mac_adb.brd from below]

Board: 2 copper layers, 56.0 x 65.0 mm, 53 parts (5 on the bottom side), 55 nets.

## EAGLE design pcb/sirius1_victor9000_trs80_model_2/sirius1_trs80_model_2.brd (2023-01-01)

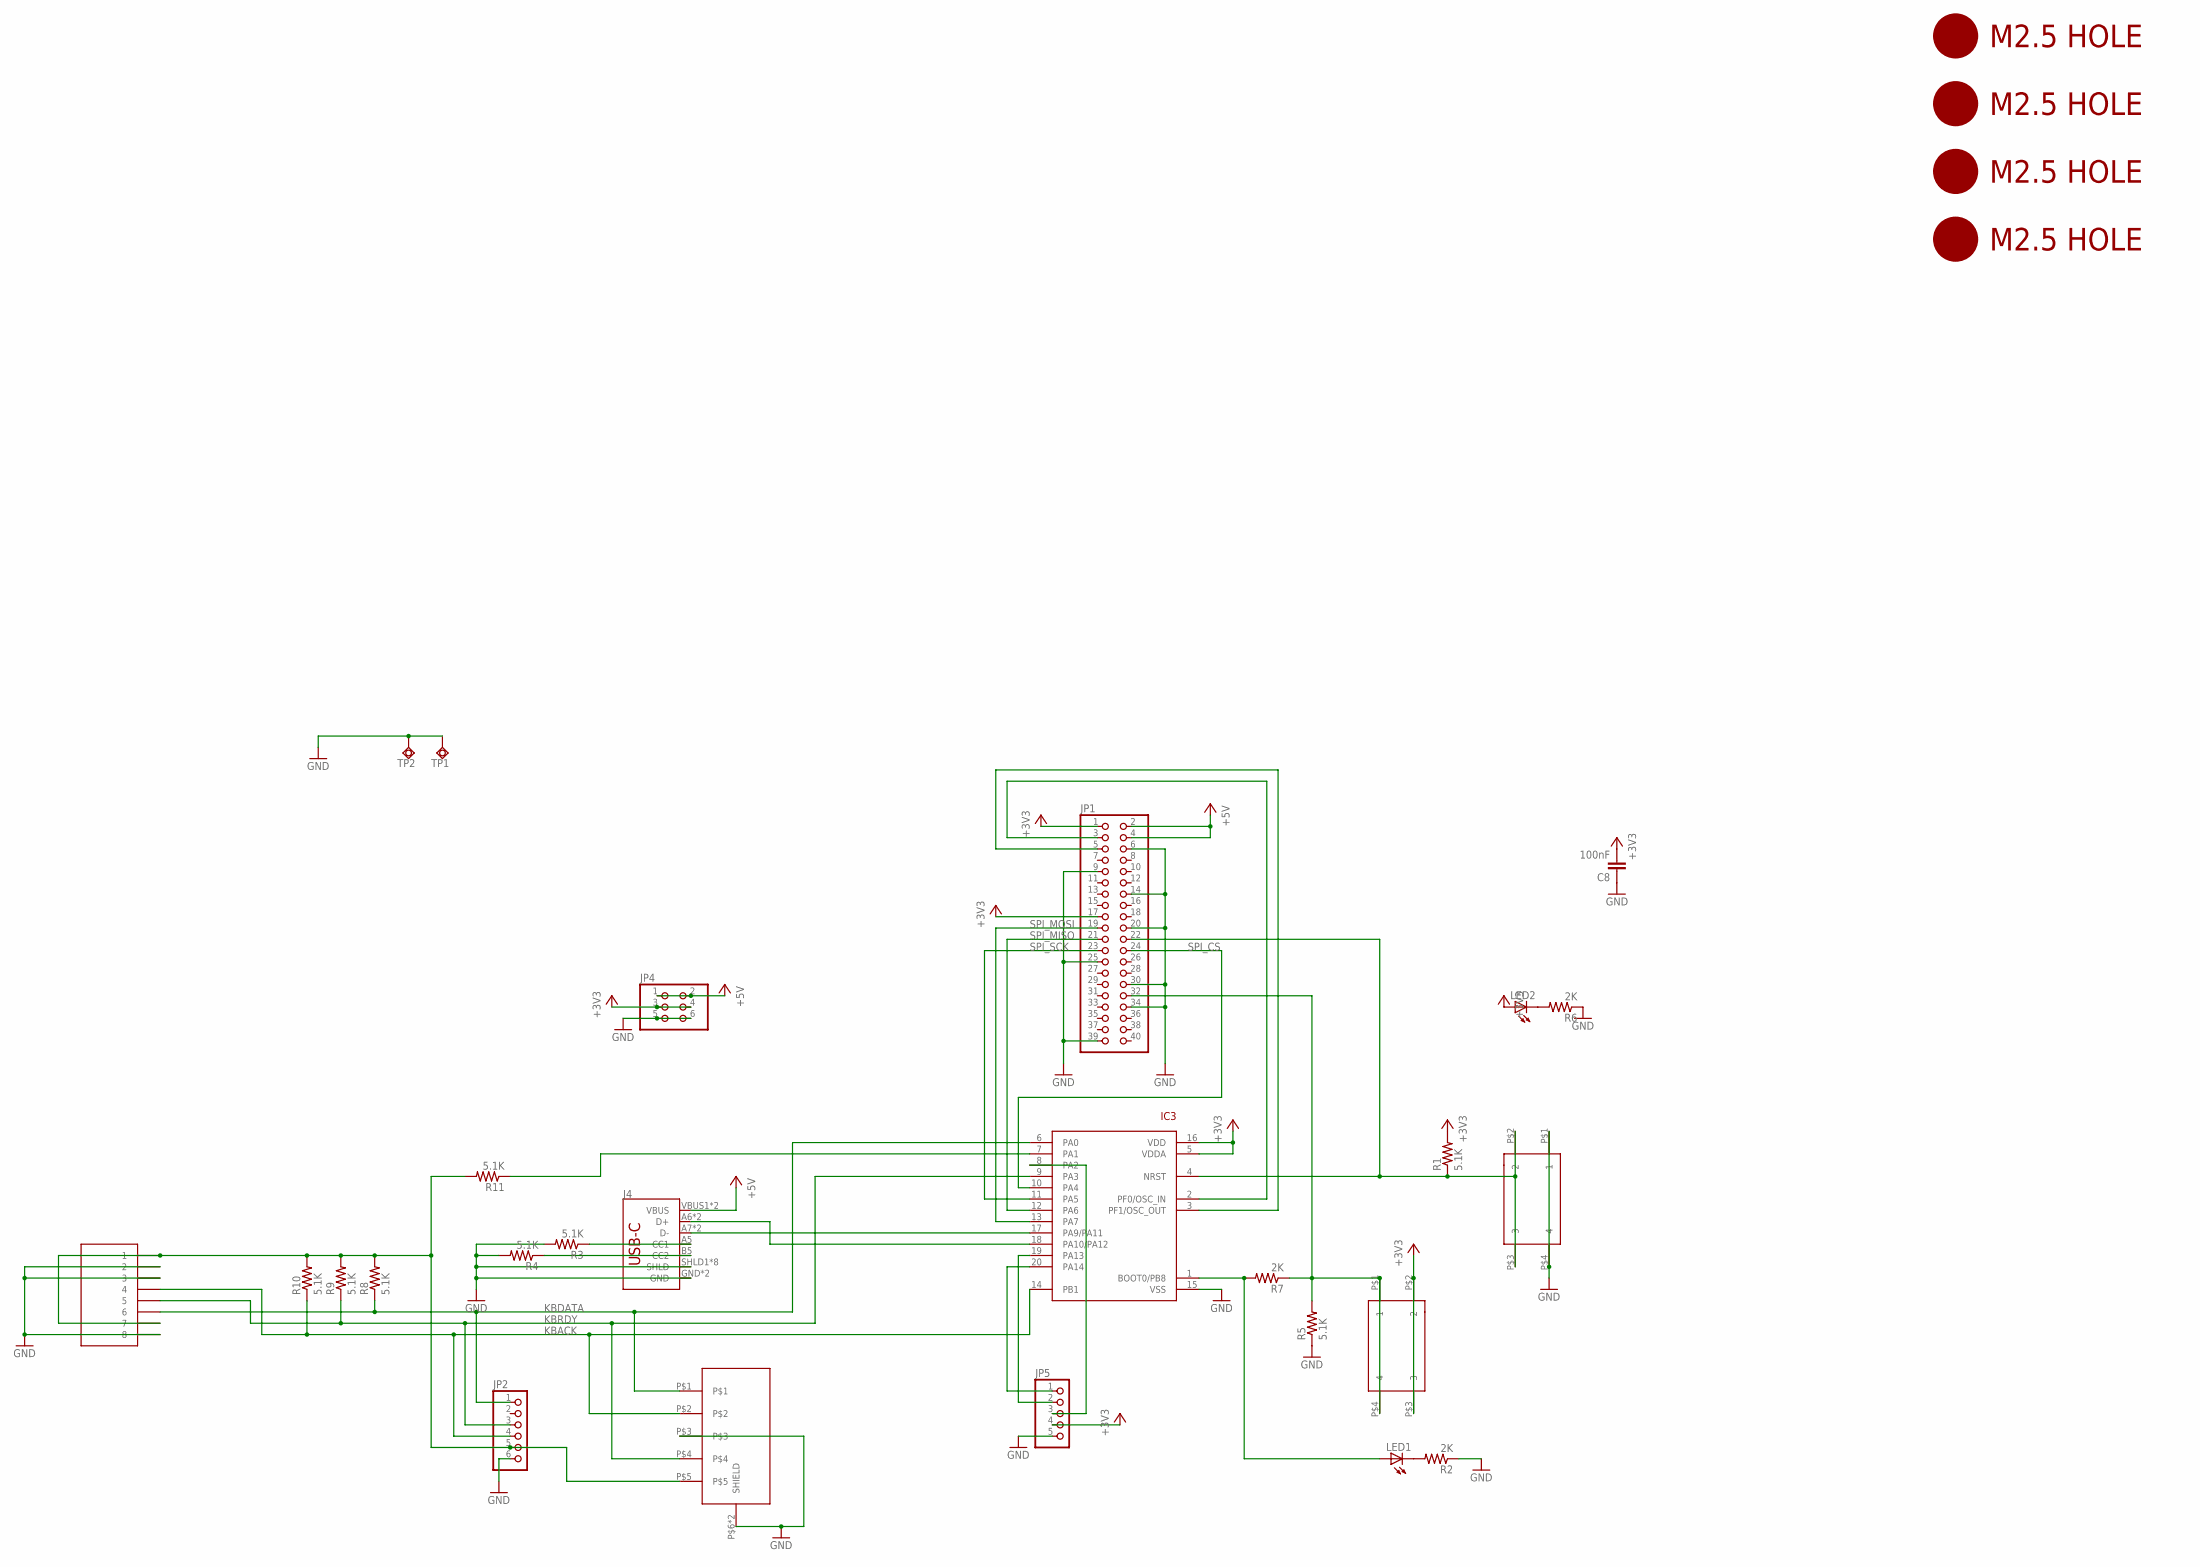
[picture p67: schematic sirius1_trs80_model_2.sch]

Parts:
C8: 100nF; 0805@1
IC3: STM32F042F4; TSSOP20
J4: USB_C16PIN; USB-C-16P
JP1: PINHD-2X20-BIG; 2X20-BIG
JP2: PINHD-1X6; 1X06
JP4: PINHD-2X3; 2X03
JP5: PINHD-1X5; 1X05
LED1, LED2: LEDCHIP-LED0805; CHIP-LED0805
R1, R3, R4, R5, R8, R9, R10, R11: 5.1K; 0805
R2, R6, R7: 2K; 0805
SW1, SW4: 324_SW; 342_SWICH_FOOT
TP1, TP2: TPSQPAD1-17; P1-17
U1: RJ45; RJ45-8
U$1: DIN5
U$2, U$3, U$4, U$5: M2.5HOLE

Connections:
+3V3: C8.2, IC3.5 (VDDA), IC3.16 (VDD), JP1.1, JP1.17, JP4.3, JP4.4, JP5.4, LED2.A, R1.2, SW1.P$2 (2), SW1.P$3 (3)
+5V: J4.VBUS1 (VBUS), J4.VBUS2 (VBUS), JP1.2, JP1.4, JP4.1, JP4.2
GND: C8.1, IC3.15 (VSS), J4.GND, J4.GND2 (GND), J4.SHLD1 (SHLD), J4.SHLD2 (SHLD), J4.SHLD3 (SHLD), J4.SHLD4 (SHLD), J4.SHLD5 (SHLD), J4.SHLD6 (SHLD), J4.SHLD7 (SHLD), J4.SHLD8 (SHLD), JP1.6, JP1.9, JP1.14, JP1.20, JP1.25, JP1.30, JP1.34, JP1.39, JP2.6, JP4.5, JP4.6, JP5.5, R2.1, R3.2, R4.2, R5.1, R6.1, SW4.P$1 (1), SW4.P$4 (4), TP1.TP, TP2.TP, U1.2, U1.3, U1.8, U$1.P$3, U$1.P$6 (SHIELD), U$1.P$7 (SHIELD)
KBACK: IC3.14 (PB1), JP2.4, R10.1, U1.4, U$1.P$2
KBDATA: IC3.6 (PA0), JP2.1, R8.1, U1.6, U$1.P$1
KBRDY: IC3.9 (PA3), JP2.3, R9.1, U1.5, U$1.P$4
unnamed: J4.A5 (CC1), R3.1
unnamed: JP1.32, R5.2, R7.1, SW1.P$1 (1), SW1.P$4 (4)
unnamed: IC3.17 (PA9/PA11), J4.A7 (D-), J4.B7 (D-)
unnamed: IC3.7 (PA1), R11.1
unnamed: IC3.8 (PA2), JP5.3
unnamed: IC3.19 (PA13), JP5.2
unnamed: J4.B5 (CC2), R4.1
unnamed: IC3.20 (PA14), JP5.1
unnamed: IC3.1 (BOOT0/PB8), LED1.A, R7.2
unnamed: IC3.2 (PF0/OSC_IN), JP1.3
unnamed: IC3.3 (PF1/OSC_OUT), JP1.5
unnamed: IC3.4 (NRST), JP1.22, R1.1, SW4.P$2 (2), SW4.P$3 (3)
unnamed: IC3.18 (PA10/PA12), J4.A6 (D+), J4.B6 (D+)
unnamed: LED1.C, R2.2
unnamed: JP2.5, R8.2, R9.2, R10.2, R11.2, U1.1, U1.7, U$1.P$5
unnamed: LED2.C, R6.2
SPI_CS: IC3.10 (PA4), JP1.24
SPI_MISO: IC3.12 (PA6), JP1.21
SPI_MOSI: IC3.13 (PA7), JP1.19
SPI_SCK: IC3.11 (PA5), JP1.23

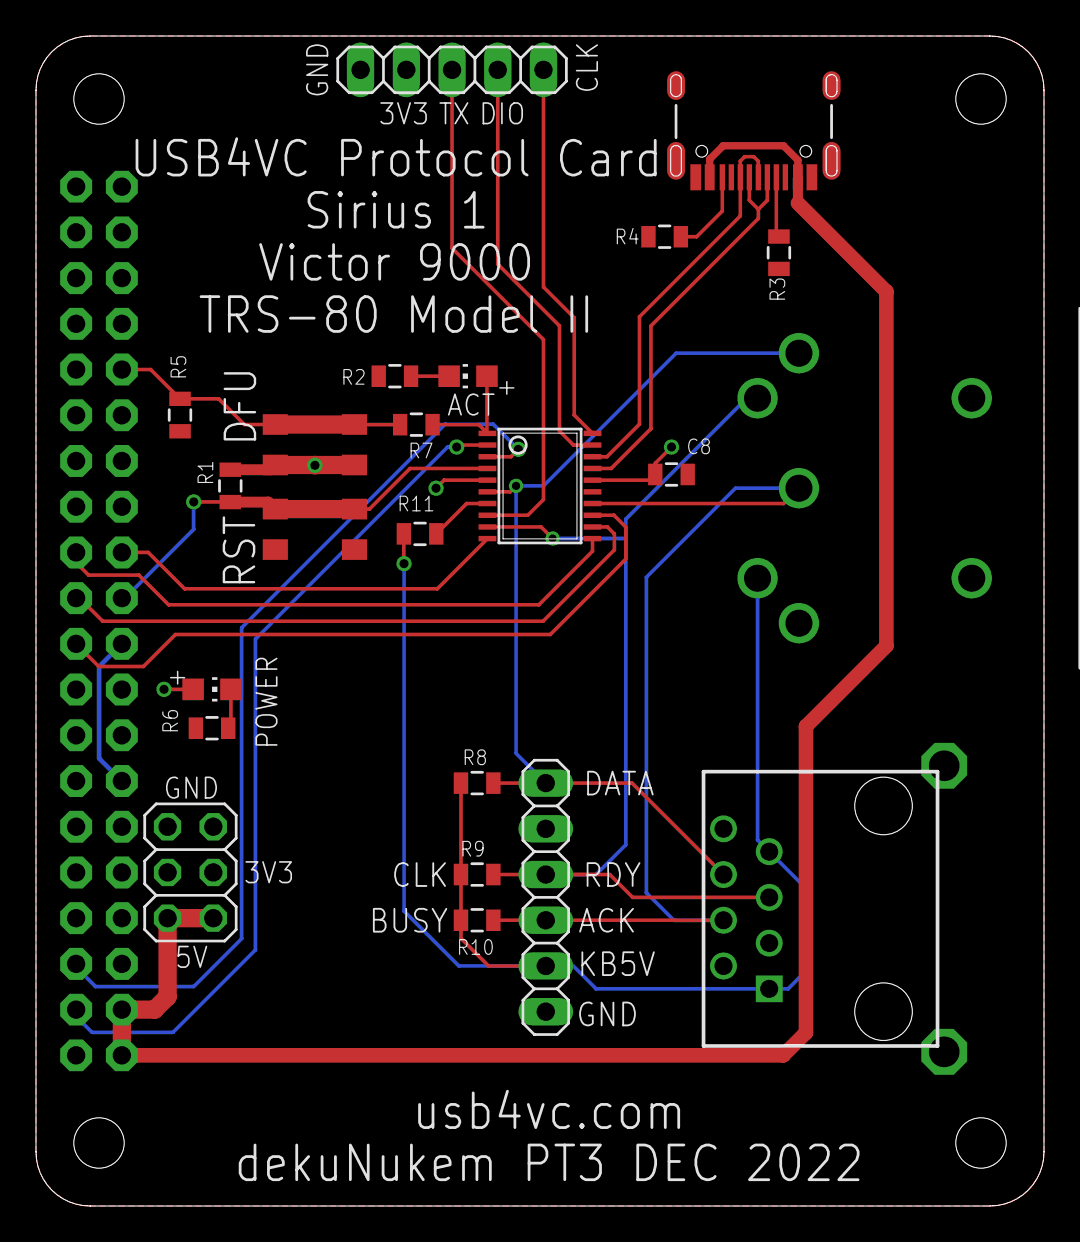
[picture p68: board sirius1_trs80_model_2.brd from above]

Board: 2 copper layers, 56.0 x 65.0 mm, 30 parts (1 on the bottom side), 26 nets.

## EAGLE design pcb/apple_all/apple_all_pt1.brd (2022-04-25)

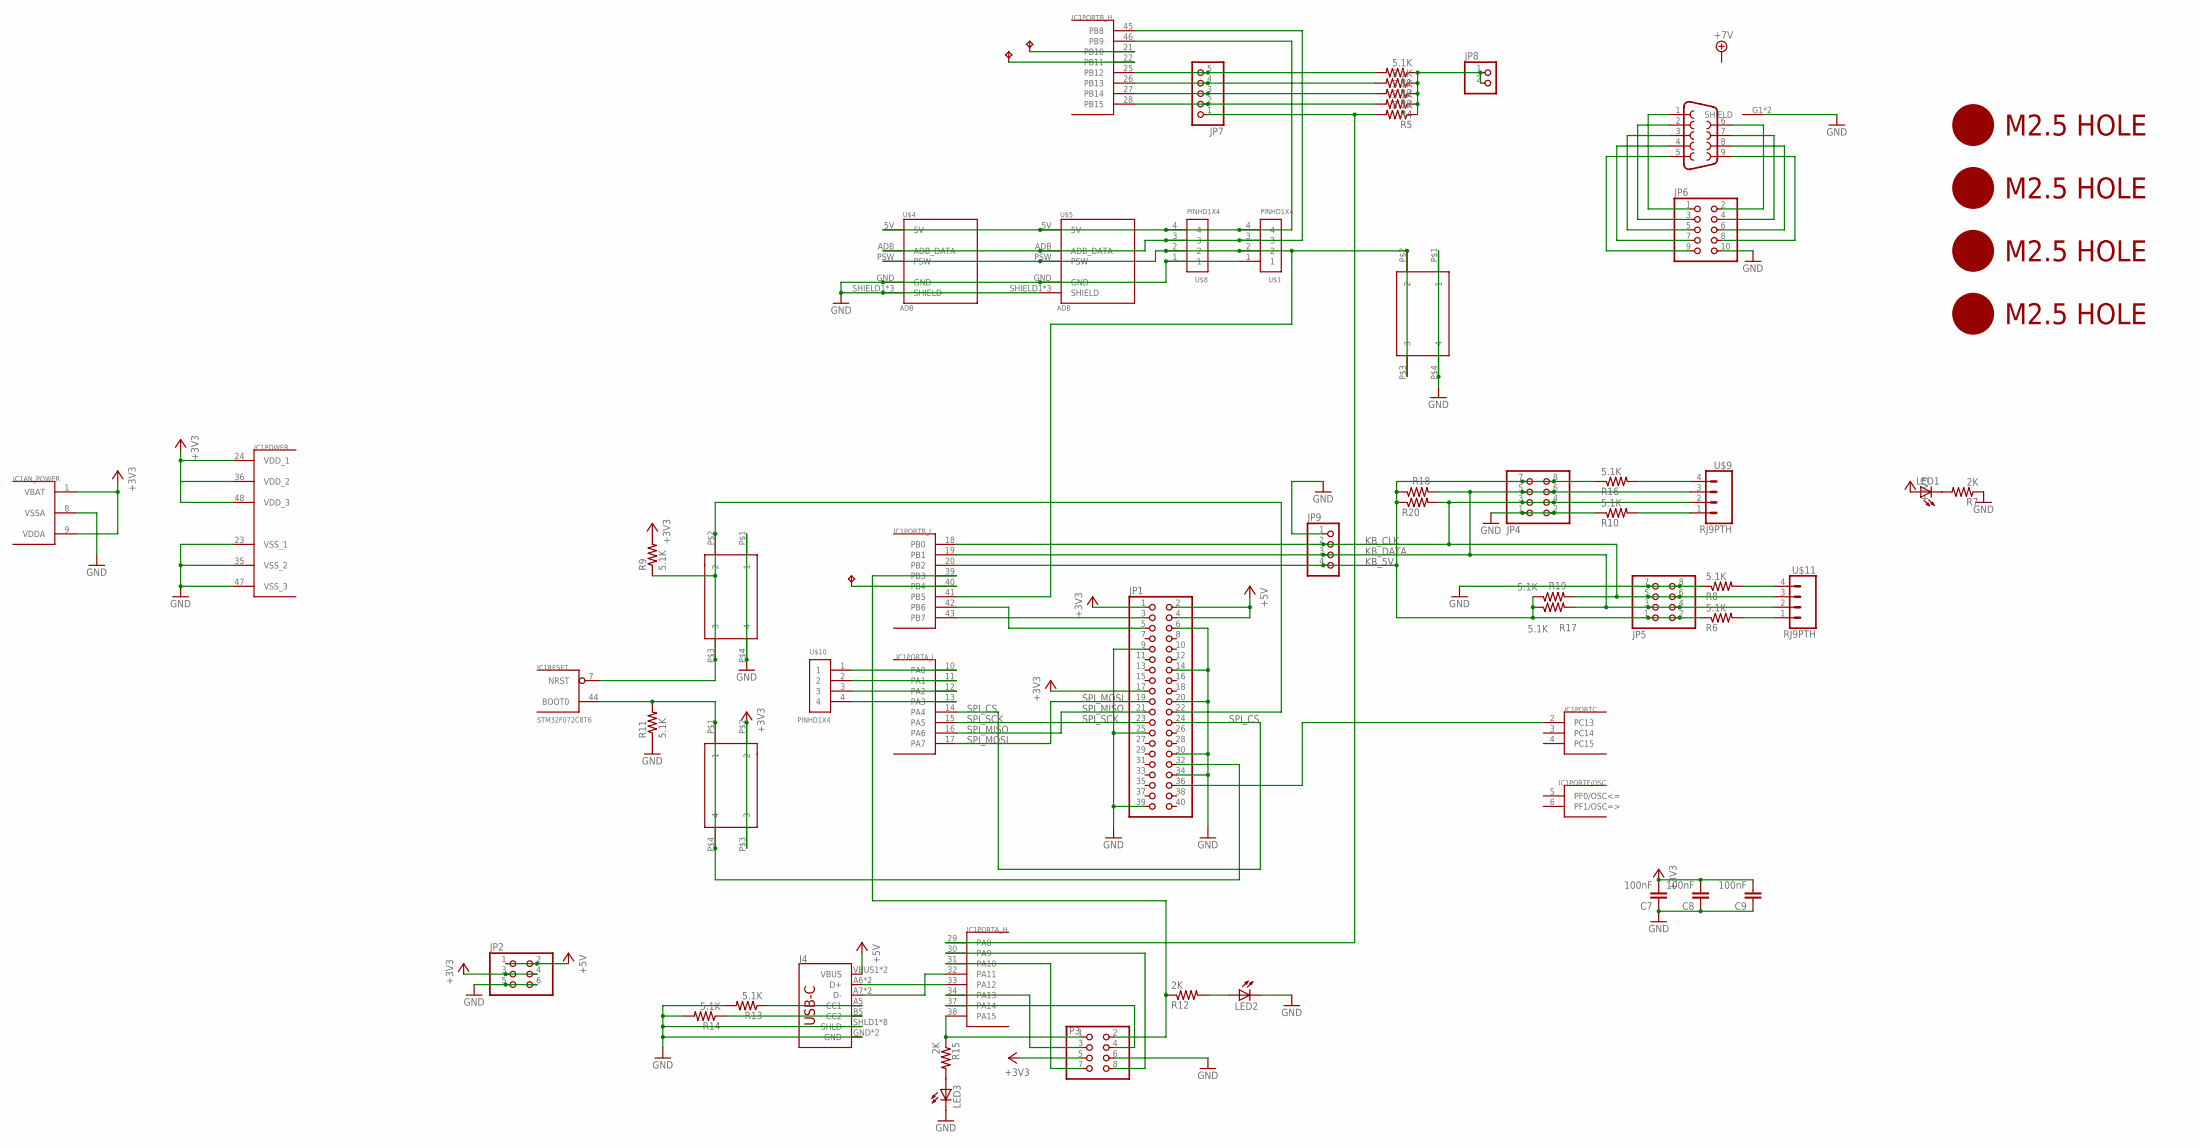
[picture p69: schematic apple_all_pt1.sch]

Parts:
C7, C8, C9: 100nF; 0805@1
IC1: STM32F072C8T6; TQFP48
J2: DB9FEMALE; DB9
J4: USB_C16PIN; USB-C-16P
JP1: PINHD-2X20-BIG; 2X20-BIG
JP2: PINHD-2X3; 2X03
JP3, JP4, JP5: PINHD-2X4; 2X04
JP6: PINHD-2X5; 2X05
JP7: PINHD-1X5; 1X05
JP8: PINHD-1X2; 1X02
JP9: PINHD-1X4; 1X04
LED1, LED2, LED3: LEDCHIP-LED0805; CHIP-LED0805
R1, R2, R3, R4, R5, R6, R8, R9, R10, R11, R13, R14, R16, R17, R18, R19, R20: 5.1K; 0805
R7, R12, R15: 2K; 0805
SW1, SW2, SW3: 324_SW; 342_SWICH_FOOT
TP1, TP2, TP3: TPTP12R; TP12R
U$1, U$8, U$10: PINHD1X4; 1X04-CLEANBIG
U$2, U$3, U$6, U$7: M2.5HOLE
U$4, U$5: ADB; DIN4
U$9, U$11: RJ9PTH; RJ9

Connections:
+3V3: C7.2, C8.2, C9.2, IC1.1 (VBAT), IC1.9 (VDDA), IC1.24 (VDD_1), IC1.36 (VDD_2), IC1.48 (VDD_3), JP1.1, JP1.17, JP2.3, JP2.4, JP3.5, LED1.A, R9.2, SW2.P$2 (2), SW2.P$3 (3)
+5V: J4.VBUS1 (VBUS), J4.VBUS2 (VBUS), JP1.2, JP1.4, JP2.1, JP2.2
GND: C7.1, C8.1, C9.1, IC1.8 (VSSA), IC1.23 (VSS_1), IC1.35 (VSS_2), IC1.47 (VSS_3), J2.G1 (SHIELD), J2.G2 (SHIELD), J4.GND, J4.GND2 (GND), J4.SHLD1 (SHLD), J4.SHLD2 (SHLD), J4.SHLD3 (SHLD), J4.SHLD4 (SHLD), J4.SHLD5 (SHLD), J4.SHLD6 (SHLD), J4.SHLD7 (SHLD), J4.SHLD8 (SHLD), JP1.6, JP1.9, JP1.14, JP1.20, JP1.25, JP1.30, JP1.34, JP1.39, JP2.5, JP2.6, JP3.6, JP4.1, JP4.2, JP5.7, JP5.8, JP6.10, JP9.1, LED2.C, LED3.C, R7.1, R8.1, R10.1, R11.1, R13.2, R14.2, SW1.P$1 (1), SW1.P$4 (4), SW3.P$1 (1), SW3.P$4 (4), U$1.1, U$4.GND, U$4.SHIELD1 (SHIELD), U$4.SHIELD2 (SHIELD), U$4.SHIELD3 (SHIELD), U$5.GND, U$5.SHIELD1 (SHIELD), U$5.SHIELD2 (SHIELD), U$5.SHIELD3 (SHIELD), U$8.1
KB_5V: IC1.20 (PB2), JP4.7, JP4.8, JP5.1, JP5.2, JP9.4, R6.1, R16.1, R17.1, R18.1, R19.1, R20.1
KB_CLK: IC1.18 (PB0), JP4.3, JP4.4, JP5.5, JP5.6, JP9.2, R19.2, R20.2, U$9.2, U$11.3
KB_DATA: IC1.19 (PB1), JP4.5, JP4.6, JP5.3, JP5.4, JP9.3, R17.2, R18.2, U$9.3, U$11.2
unnamed: J4.A5 (CC1), R13.1
unnamed: LED2.A, R12.2
unnamed: IC1.46 (PB9), U$1.4, U$4.5V, U$5.5V, U$8.4
unnamed: IC1.28 (PB15), JP7.2, R4.2
unnamed: R8.2, U$11.4
unnamed: IC1.39 (PB3), JP3.2, R12.1
unnamed: J4.B5 (CC2), R14.1
unnamed: IC1.33 (PA12), J4.A6 (D+), J4.B6 (D+)
unnamed: IC1.32 (PA11), J4.A7 (D-), J4.B7 (D-)
unnamed: IC1.27 (PB14), JP7.3, R3.2
unnamed: IC1.40 (PB4), TP3.TP
unnamed: IC1.31 (PA10), JP3.7
unnamed: IC1.7 (NRST), JP1.22, R9.1, SW1.P$2 (2), SW1.P$3 (3)
unnamed: IC1.30 (PA9), JP3.8
unnamed: IC1.34 (PA13), JP3.3
unnamed: IC1.37 (PA14), JP3.4
unnamed: IC1.21 (PB10), TP1.TP
unnamed: IC1.44 (BOOT0), JP1.32, R11.2, SW2.P$1 (1), SW2.P$4 (4)
unnamed: IC1.22 (PB11), TP2.TP
unnamed: IC1.42 (PB6), JP1.5
unnamed: IC1.43 (PB7), JP1.3
unnamed: J2.1, JP6.1
unnamed: IC1.38 (PA15), JP3.1, R15.1
unnamed: LED3.A, R15.2
unnamed: LED1.C, R7.2
unnamed: J2.2, JP6.3
unnamed: J2.3, JP6.5
unnamed: J2.4, JP6.7
unnamed: J2.5, JP6.9
unnamed: J2.6, JP6.2
unnamed: J2.7, JP6.4
unnamed: J2.8, JP6.6
unnamed: IC1.2 (PC13), JP1.36
unnamed: IC1.10 (PA0), U$10.1
unnamed: IC1.11 (PA1), U$10.2
unnamed: IC1.12 (PA2), U$10.3
unnamed: IC1.13 (PA3), U$10.4
unnamed: J2.9, JP6.8
unnamed: IC1.45 (PB8), U$1.3, U$4.ADB (ADB_DATA), U$5.ADB (ADB_DATA), U$8.3
unnamed: IC1.26 (PB13), JP7.4, R2.2
unnamed: IC1.41 (PB5), SW3.P$2 (2), SW3.P$3 (3), U$1.2, U$4.PSW, U$5.PSW, U$8.2
unnamed: IC1.25 (PB12), JP7.5, R1.2
unnamed: IC1.29 (PA8), JP7.1, R5.2
unnamed: JP8.1, JP8.2, R1.1, R2.1, R3.1, R4.1, R5.1
unnamed: R6.2, U$11.1
unnamed: R16.2, U$9.4
unnamed: R10.2, U$9.1
SPI_CS: IC1.14 (PA4), JP1.24
SPI_MISO: IC1.16 (PA6), JP1.21
SPI_MOSI: IC1.17 (PA7), JP1.19
SPI_SCK: IC1.15 (PA5), JP1.23

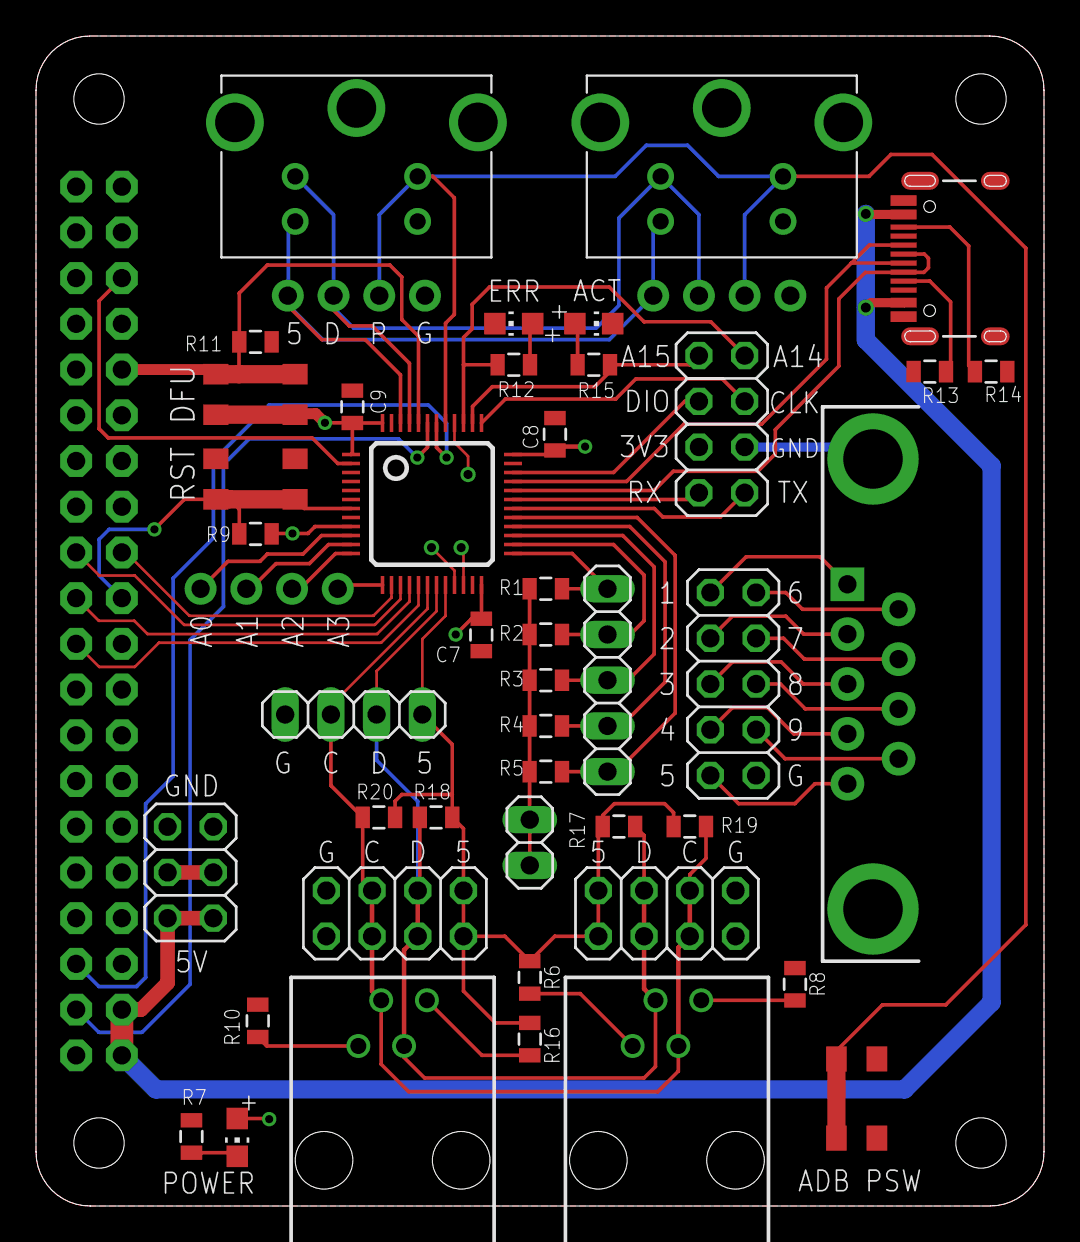
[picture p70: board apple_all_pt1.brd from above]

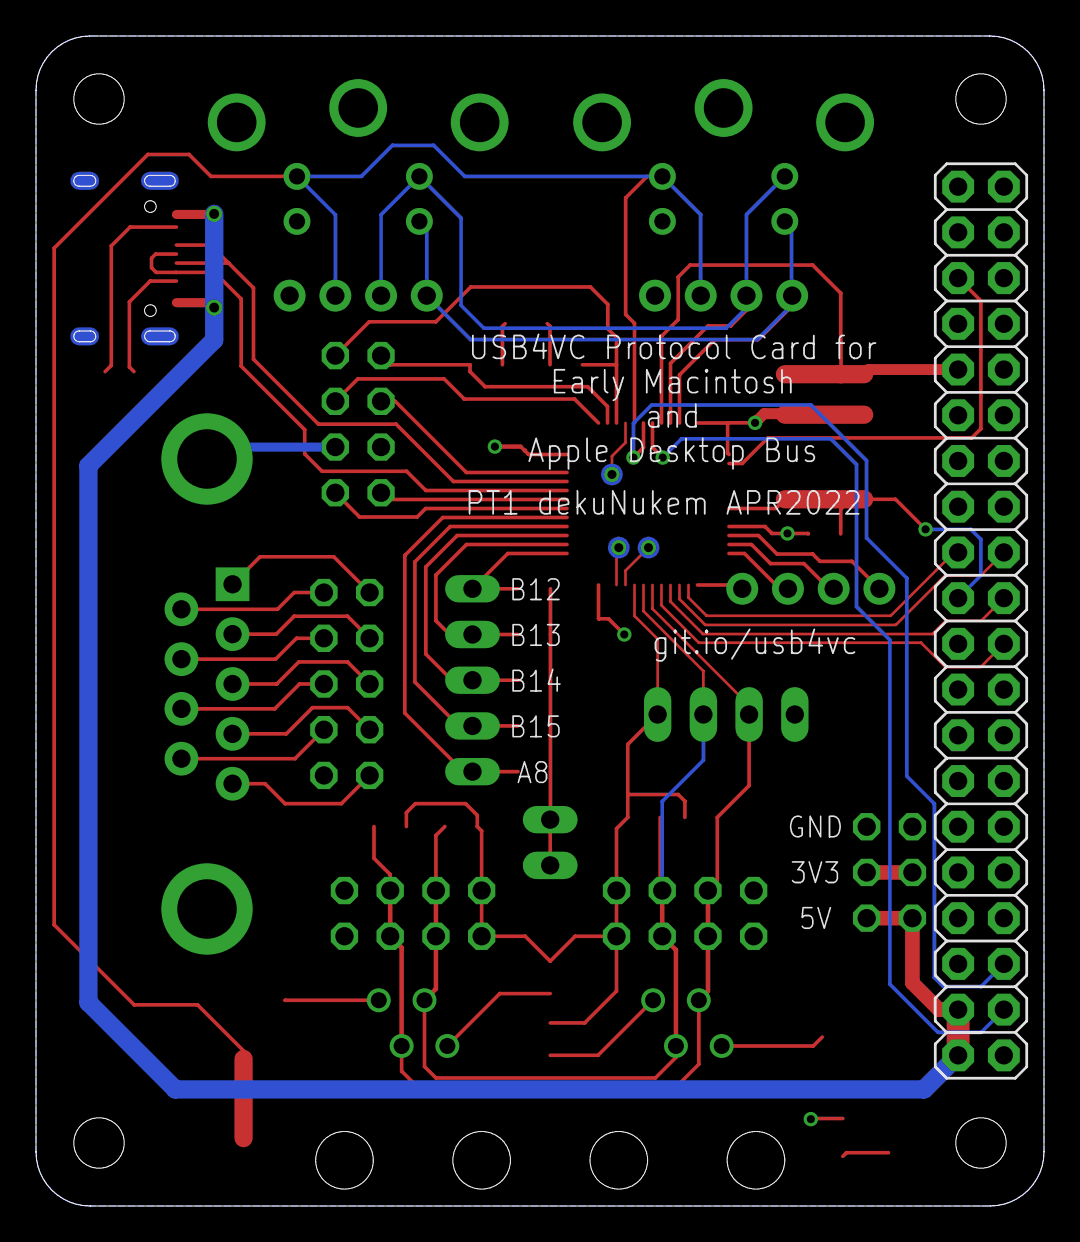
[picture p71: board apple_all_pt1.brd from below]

Board: 2 copper layers, 56.0 x 65.0 mm, 55 parts (4 on the bottom side), 57 nets.

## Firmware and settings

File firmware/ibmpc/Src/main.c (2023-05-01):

/**
  ******************************************************************************
  * @file           : main.c
  * @brief          : Main program body
  ******************************************************************************
  ** This notice applies to any and all portions of this file
  * that are not between comment pairs USER CODE BEGIN and
  * USER CODE END. Other portions of this file, whether
  * inserted by the user or by software development tools
  * are owned by their respective copyright owners.
  *
  * COPYRIGHT(c) 2023 STMicroelectronics
  *
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
  ******************************************************************************
  */
/* Includes ------------------------------------------------------------------*/
#include "main.h"
#include "stm32f0xx_hal.h"

/* USER CODE BEGIN Includes */
#include "delay_us.h"
#include "shared.h"
#include "helpers.h"
#include "ps2kb.h"
#include <string.h>
#include "ps2mouse.h"
#include "mcp4451.h"
#include "xt_kb.h"

/* USER CODE END Includes */

I2C_HandleTypeDef hi2c2;

IWDG_HandleTypeDef hiwdg;

SPI_HandleTypeDef hspi1;

TIM_HandleTypeDef htim2;

UART_HandleTypeDef huart1;
UART_HandleTypeDef huart3;

/* USER CODE BEGIN PV */

/*
0.5.6
2023 04 30
Capped PS/2 mouse rate at 200Hz

0.5.7
2023 05 01
fixed a baud rate bug

*/
const uint8_t board_id = 1;
const uint8_t version_major = 0;
const uint8_t version_minor = 5;
const uint8_t version_patch = 7;
uint8_t hw_revision;

uint8_t spi_transmit_buf[SPI_BUF_SIZE];
uint8_t backup_spi1_recv_buf[SPI_BUF_SIZE];
uint8_t spi_recv_buf[SPI_BUF_SIZE];
kb_buf my_kb_buf;
mouse_buf my_mouse_buf;
gamepad_buf my_gamepad_buf;
uint16_t flash_size;

uint8_t ps2kb_host_cmd, ps2mouse_host_cmd, buffered_code, buffered_value, ps2mouse_bus_status, ps2kb_bus_status;
mouse_event latest_mouse_event;
mouse_event consolidated_mouse_event;
gamepad_event latest_gamepad_event;
ps2_outgoing_buf my_ps2_outbuf;
#define MICROSOFT_SERIAL_MOUSE_BUF_SIZE 3
uint8_t microsoft_serial_mouse_output_buf[MICROSOFT_SERIAL_MOUSE_BUF_SIZE];
#define MOUSESYSTEMS_SERIAL_MOUSE_BUF_SIZE 5
uint8_t mousesystems_serial_mouse_output_buf[MOUSESYSTEMS_SERIAL_MOUSE_BUF_SIZE];

uint8_t serial_mouse_rts_response;
volatile uint8_t rts_active;
uint8_t spi_error_occured;

#define PROTOCOL_STATUS_NOT_AVAILABLE 0
#define PROTOCOL_STATUS_ENABLED 1
#define PROTOCOL_STATUS_DISABLED 2

#define PROTOCOL_LOOKUP_SIZE 16
uint8_t protocol_status_lookup[PROTOCOL_LOOKUP_SIZE];

#define IS_KB_PRESENT() HAL_GPIO_ReadPin(KB_DETECT_GPIO_Port, KB_DETECT_Pin)
#define IS_PS2MOUSE_PRESENT() HAL_GPIO_ReadPin(MOUSE_DETECT_GPIO_Port, MOUSE_DETECT_Pin)

/* USER CODE END PV */

void SystemClock_Config(void);
static void MX_GPIO_Init(void);
static void MX_I2C2_Init(void);
static void MX_SPI1_Init(void);
static void MX_TIM2_Init(void);
static void MX_USART1_UART_Init(void);
static void MX_USART3_UART_Init(void);
static void MX_IWDG_Init(void);

/* USER CODE BEGIN PFP */

/* USER CODE END PFP */

/* USER CODE BEGIN 0 */

void mouse_uart_switch_to_8bit(void)
{
  huart3.Init.WordLength = UART_WORDLENGTH_8B;
  HAL_UART_Init(&huart3);
}

void mouse_uart_switch_to_7bit(void)
{
  huart3.Init.WordLength = UART_WORDLENGTH_7B;
  HAL_UART_Init(&huart3);
}

int fputc(int ch, FILE *f)
{
  HAL_UART_Transmit(&huart1, (unsigned char *)&ch, 1, 100);
  return ch;
}

int16_t byte_to_int16_t(uint8_t lsb, uint8_t msb)
{
  return (int16_t)((msb << 8) | lsb);
}

uint8_t is_protocol_enabled(uint8_t this_protocol)
{
  if(this_protocol >= PROTOCOL_LOOKUP_SIZE)
    return 0;
  return protocol_status_lookup[this_protocol] == PROTOCOL_STATUS_ENABLED;
}

void gameport_init()
{
  // release all buttons, reset digital pot
  HAL_GPIO_WritePin(GAMEPAD_B1_GPIO_Port, GAMEPAD_B1_Pin, GPIO_PIN_SET);
  HAL_GPIO_WritePin(GAMEPAD_B2_GPIO_Port, GAMEPAD_B2_Pin, GPIO_PIN_SET);
  HAL_GPIO_WritePin(GAMEPAD_B3_GPIO_Port, GAMEPAD_B3_Pin, GPIO_PIN_SET);
  HAL_GPIO_WritePin(GAMEPAD_B4_GPIO_Port, GAMEPAD_B4_Pin, GPIO_PIN_SET);
  mcp4451_reset();
}

void handle_protocol_switch(uint8_t spi_byte)
{
  uint8_t index = spi_byte & 0x7f;
  uint8_t onoff = spi_byte & 0x80;

  if(index >= PROTOCOL_LOOKUP_SIZE)
    return;
  // trying to change a protocol that is not available on this board
  if(protocol_status_lookup[index] == PROTOCOL_STATUS_NOT_AVAILABLE)
    return;
  // switching protocol ON
  if(onoff && protocol_status_lookup[index] == PROTOCOL_STATUS_DISABLED)
  {
    switch(index)
    {
      case PROTOCOL_AT_PS2_KB:
        ps2kb_init(PS2KB_CLK_GPIO_Port, PS2KB_CLK_Pin, PS2KB_DATA_GPIO_Port, PS2KB_DATA_Pin);
        break;

      case PROTOCOL_XT_KB:
        xtkb_enable();
        break;

      case PROTOCOL_PS2_MOUSE:
        ps2mouse_init(PS2MOUSE_CLK_GPIO_Port, PS2MOUSE_CLK_Pin, PS2MOUSE_DATA_GPIO_Port, PS2MOUSE_DATA_Pin);
        break;

      case PROTOCOL_MICROSOFT_SERIAL_MOUSE:
        mouse_uart_switch_to_7bit();
        break;

      case PROTOCOL_MOUSESYSTEMS_SERIAL_MOUSE:
        mouse_uart_switch_to_8bit();
        break;

      case PROTOCOL_GENERIC_GAMEPORT_GAMEPAD:
        gameport_init();
        break;
    }
    protocol_status_lookup[index] = PROTOCOL_STATUS_ENABLED;
  }
  // switching protocol OFF
  else if((onoff == 0) && protocol_status_lookup[index] == PROTOCOL_STATUS_ENABLED)
  {
    protocol_status_lookup[index] = PROTOCOL_STATUS_DISABLED;
    switch(index) 
    {
      case PROTOCOL_AT_PS2_KB:
        ps2kb_release_lines();
        ps2kb_reset();
        break;

      case PROTOCOL_XT_KB:
        xtkb_release_lines();
        break;

      case PROTOCOL_PS2_MOUSE:
        ps2mouse_reset();
        ps2mouse_release_lines();
        break;

      case PROTOCOL_MICROSOFT_SERIAL_MOUSE:
        break;

      case PROTOCOL_MOUSESYSTEMS_SERIAL_MOUSE:
        break;

      case PROTOCOL_GENERIC_GAMEPORT_GAMEPAD:
        gameport_init();
        break;
    }
  }
}

/*
  This is called when a new SPI packet is received
  This is part of an ISR, so keep it short!
*/
uint32_t ACT_LED_off_ts;
void HAL_SPI_TxRxCpltCallback(SPI_HandleTypeDef *hspi)
{
  HAL_GPIO_WritePin(ACT_LED_GPIO_Port, ACT_LED_Pin, GPIO_PIN_SET);
  memcpy(backup_spi1_recv_buf, spi_recv_buf, SPI_BUF_SIZE);

  if(backup_spi1_recv_buf[0] != 0xde)
  {
    spi_error_occured = 1;
  }
  else if(backup_spi1_recv_buf[SPI_BUF_INDEX_MSG_TYPE] == SPI_MOSI_MSG_TYPE_KEYBOARD_EVENT)
  {
    kb_buf_add(&my_kb_buf, backup_spi1_recv_buf[4], backup_spi1_recv_buf[6]);
  }
  else if(backup_spi1_recv_buf[SPI_BUF_INDEX_MSG_TYPE] == SPI_MOSI_MSG_TYPE_MOUSE_EVENT)
  {
    latest_mouse_event.movement_x = byte_to_int16_t(backup_spi1_recv_buf[4], backup_spi1_recv_buf[5]);
    latest_mouse_event.movement_y = -1 * byte_to_int16_t(backup_spi1_recv_buf[6], backup_spi1_recv_buf[7]);
    latest_mouse_event.scroll_vertical = -1 * backup_spi1_recv_buf[8];
    latest_mouse_event.scroll_horizontal = backup_spi1_recv_buf[9];
    latest_mouse_event.button_left = backup_spi1_recv_buf[13];
    latest_mouse_event.button_right = backup_spi1_recv_buf[14];
    latest_mouse_event.button_middle = backup_spi1_recv_buf[15];
    latest_mouse_event.button_side = backup_spi1_recv_buf[16];
    latest_mouse_event.button_extra = backup_spi1_recv_buf[17];
    mouse_buf_add(&my_mouse_buf, &latest_mouse_event);
  }
  else if(backup_spi1_recv_buf[SPI_BUF_INDEX_MSG_TYPE] == SPI_MOSI_MSG_TYPE_GAMEPAD_EVENT_MAPPED_IBMPC)
  {
    latest_gamepad_event.button_1 = backup_spi1_recv_buf[4];
    latest_gamepad_event.button_2 = backup_spi1_recv_buf[5];
    latest_gamepad_event.button_3 = backup_spi1_recv_buf[6];
    latest_gamepad_event.button_4 = backup_spi1_recv_buf[7];
    latest_gamepad_event.button_lt = 0;
    latest_gamepad_event.button_rt = 0;
    latest_gamepad_event.button_lt2 = 0;
    latest_gamepad_event.button_rt2 = 0;
    latest_gamepad_event.axis_x = backup_spi1_recv_buf[8];
    latest_gamepad_event.axis_y = backup_spi1_recv_buf[9];
    latest_gamepad_event.axis_rx = backup_spi1_recv_buf[10];
    latest_gamepad_event.axis_ry = backup_spi1_recv_buf[11];
    gamepad_buf_add(&my_gamepad_buf, &latest_gamepad_event);
  }
  else if(backup_spi1_recv_buf[SPI_BUF_INDEX_MSG_TYPE] == SPI_MOSI_MSG_TYPE_REQ_ACK)
  {
    HAL_GPIO_WritePin(SLAVE_REQ_GPIO_Port, SLAVE_REQ_Pin, GPIO_PIN_RESET);
  }
  else if(backup_spi1_recv_buf[SPI_BUF_INDEX_MSG_TYPE] == SPI_MOSI_MSG_TYPE_INFO_REQUEST)
  {
    memset(spi_transmit_buf, 0, SPI_BUF_SIZE);
    spi_transmit_buf[SPI_BUF_INDEX_MAGIC] = SPI_MISO_MAGIC;
    spi_transmit_buf[SPI_BUF_INDEX_SEQNUM] = backup_spi1_recv_buf[SPI_BUF_INDEX_SEQNUM];
    spi_transmit_buf[SPI_BUF_INDEX_MSG_TYPE] = SPI_MISO_MSG_TYPE_INFO_REQUEST;
    spi_transmit_buf[3] = board_id;
    spi_transmit_buf[4] = hw_revision;
    spi_transmit_buf[5] = version_major;
    spi_transmit_buf[6] = version_minor;
    spi_transmit_buf[7] = version_patch;
    uint8_t curr_index = 8;
    for (int i = 0; i < PROTOCOL_LOOKUP_SIZE; i++)
    {
      if(protocol_status_lookup[i] == PROTOCOL_STATUS_NOT_AVAILABLE)
        continue;
      else if(protocol_status_lookup[i] == PROTOCOL_STATUS_DISABLED)
        spi_transmit_buf[curr_index] = i;
      else if(protocol_status_lookup[i] == PROTOCOL_STATUS_ENABLED)
        spi_transmit_buf[curr_index] = i | 0x80;
      curr_index++;
    }
  }
  else if(backup_spi1_recv_buf[SPI_BUF_INDEX_MSG_TYPE] == SPI_MOSI_MSG_TYPE_SET_PROTOCOL)
  {
    for (int i = 3; i < SPI_BUF_SIZE; ++i)
    {
      if(backup_spi1_recv_buf[i] == 0)
        break;
      handle_protocol_switch(backup_spi1_recv_buf[i]);
    }
  }
  HAL_SPI_TransmitReceive_IT(&hspi1, spi_transmit_buf, spi_recv_buf, SPI_BUF_SIZE);
  ACT_LED_off_ts = micros() + 10000;
}

void cap_to_127(int32_t *number)
{
  if(*number > 127)
    *number = 127;
  if(*number < -127)
    *number = -127;
}

void get_consolidated_mouse_event(mouse_buf* mbuf, mouse_event* cme_result)
{
  cme_result->movement_x = 0;
  cme_result->movement_y = 0;
  cme_result->scroll_vertical = 0;
  cme_result->scroll_horizontal = 0;
  cme_result->button_left = 0;
  cme_result->button_right = 0;
  cme_result->button_middle = 0;
  cme_result->button_side = 0;
  cme_result->button_extra = 0;
  while(1)
  {
    mouse_event* this_mouse_event = mouse_buf_peek(mbuf);
    if(this_mouse_event == NULL)
      break;
    cme_result->movement_x += this_mouse_event->movement_x;
    cme_result->movement_y += this_mouse_event->movement_y;
    cme_result->scroll_vertical += this_mouse_event->scroll_vertical;
    cme_result->scroll_horizontal += this_mouse_event->scroll_horizontal;
    cme_result->button_left |= this_mouse_event->button_left;
    cme_result->button_right |= this_mouse_event->button_right;
    cme_result->button_middle |= this_mouse_event->button_middle;
    cme_result->button_side |= this_mouse_event->button_side;
    cme_result->button_extra |= this_mouse_event->button_extra;
    mouse_buf_pop(mbuf);
  }
  cap_to_127(&cme_result->movement_x);
  cap_to_127(&cme_result->movement_y);
}

uint32_t last_mouse_movement;
void ps2mouse_update(void)
{
  ps2mouse_bus_status = ps2mouse_get_bus_status();
  if(ps2mouse_bus_status == PS2_BUS_INHIBIT)
  {
    ps2mouse_release_lines();
    return;
  }
  else if(ps2mouse_bus_status == PS2_BUS_REQ_TO_SEND)
  {
    PCARD_BUSY_HI();
    ps2mouse_read(&ps2mouse_host_cmd, 10);
    ps2mouse_host_req_reply(ps2mouse_host_cmd, &latest_mouse_event);
    PCARD_BUSY_LOW();
    return;
  }

  // 5ms, PS/2 tops out at 200Hz
  if(micros() - last_mouse_movement <= 5000)
    return;

  if(mouse_buf_peek(&my_mouse_buf) == NULL)
    return;

  get_consolidated_mouse_event(&my_mouse_buf, &consolidated_mouse_event);
  // mouse buffer now empty

  if(ps2mouse_get_outgoing_data(&consolidated_mouse_event, &my_ps2_outbuf))
    return; // if return value is not 0, no need to send out packets

  PCARD_BUSY_HI();
  if(ps2mouse_send_update(&my_ps2_outbuf) != PS2_OK)
  {
    uint32_t enter_time = HAL_GetTick();
    while(ps2mouse_get_bus_status() != PS2_BUS_IDLE)
    {
      if(HAL_GetTick() - enter_time > PS2MOUSE_WRITE_DEFAULT_TIMEOUT_MS)
        break;
    }
  }
  last_mouse_movement = micros();
  PCARD_BUSY_LOW();
}

uint8_t ps2kb_update(void)
{
  ps2kb_bus_status = ps2kb_get_bus_status();
  if(ps2kb_bus_status == PS2_BUS_INHIBIT)
  {
    ps2kb_release_lines();
    return 0;
  }
  if(ps2kb_bus_status == PS2_BUS_REQ_TO_SEND)
  {
    PCARD_BUSY_HI();
    uint8_t ps2kb_leds = 0xff;
    ps2kb_read(&ps2kb_host_cmd, 10);
    keyboard_reply(ps2kb_host_cmd, &ps2kb_leds);
    if(ps2kb_leds != 0xff)
    {
      memset(spi_transmit_buf, 0, SPI_BUF_SIZE);
      spi_transmit_buf[SPI_BUF_INDEX_MAGIC] = SPI_MISO_MAGIC;
      spi_transmit_buf[SPI_BUF_INDEX_SEQNUM] = backup_spi1_recv_buf[SPI_BUF_INDEX_SEQNUM];
      spi_transmit_buf[SPI_BUF_INDEX_MSG_TYPE] = SPI_MISO_MSG_TYPE_KB_LED_REQUEST;
      if(ps2kb_leds & 0x1) // scroll lock LED
        spi_transmit_buf[3] = 1;
      if(ps2kb_leds & 0x2)  // num lock LED
        spi_transmit_buf[4] = 1;
      if(ps2kb_leds & 0x4)  // caps lock LED
        spi_transmit_buf[5] = 1;
      HAL_GPIO_WritePin(SLAVE_REQ_GPIO_Port, SLAVE_REQ_Pin, GPIO_PIN_SET);
    }
  }
  else if(ps2kb_bus_status == PS2_BUS_IDLE && (kb_buf_peek(&my_kb_buf, &buffered_code, &buffered_value) == 0))
  {
    PCARD_BUSY_HI();
    if(ps2kb_press_key(buffered_code, buffered_value) == PS2_ERROR_HOST_INHIBIT) // host inhibited line during transmission
      HAL_Delay(1);
    else
      kb_buf_pop(&my_kb_buf);
  }
  return 1;
}

// GPIO external interrupt callback
void HAL_GPIO_EXTI_Callback(uint16_t GPIO_Pin)
{
  if(GPIO_Pin == UART3_RTS_Pin && is_protocol_enabled(PROTOCOL_MICROSOFT_SERIAL_MOUSE))
    rts_active = 1;
}

uint8_t serial_mouse_is_tx_in_progress;
void HAL_UART_TxCpltCallback(UART_HandleTypeDef *huart)
{
  serial_mouse_is_tx_in_progress = 0;
}

// https://everything2.com/title/Mouse+protocol
void microsoft_serial_mouse_update(void)
{
  if(rts_active)
  {
    serial_mouse_rts_response = 0x4d; // 0x4d = 'M'
    HAL_UART_Transmit_IT(&huart3, &serial_mouse_rts_response, 1);
    serial_mouse_is_tx_in_progress = 1;
    rts_active = 0;
  }

  if(mouse_buf_peek(&my_mouse_buf) == NULL)
    return;

  if(serial_mouse_is_tx_in_progress)
    return;

  get_consolidated_mouse_event(&my_mouse_buf, &consolidated_mouse_event);
  // mouse buffer now empty

  memset(microsoft_serial_mouse_output_buf, 0, MICROSOFT_SERIAL_MOUSE_BUF_SIZE);
  microsoft_serial_mouse_output_buf[0] = 0xc0;
  if(consolidated_mouse_event.button_left)
    microsoft_serial_mouse_output_buf[0] |= 0x20;
  if(consolidated_mouse_event.button_right)
    microsoft_serial_mouse_output_buf[0] |= 0x10;

  int16_t serial_x = consolidated_mouse_event.movement_x;
  int16_t serial_y = -1* consolidated_mouse_event.movement_y;

  if(serial_y & 0x80)
    microsoft_serial_mouse_output_buf[0] |= 0x8;
  if(serial_y & 0x40)
    microsoft_serial_mouse_output_buf[0] |= 0x4;
  if(serial_x & 0x80)
    microsoft_serial_mouse_output_buf[0] |= 0x2;
  if(serial_x & 0x40)
    microsoft_serial_mouse_output_buf[0] |= 0x1;

  microsoft_serial_mouse_output_buf[1] = 0x3f & serial_x;
  microsoft_serial_mouse_output_buf[2] = 0x3f & serial_y;
  HAL_UART_Transmit_IT(&huart3, microsoft_serial_mouse_output_buf, MICROSOFT_SERIAL_MOUSE_BUF_SIZE);
  serial_mouse_is_tx_in_progress = 1;
}

void spi_error_dump_reboot(void)
{
  printf("SPI ERROR\n");
  for (int i = 0; i < SPI_BUF_SIZE; ++i)
    printf("%d ", backup_spi1_recv_buf[i]);
  printf("\nrebooting...\n");
  for (int i = 0; i < 100; ++i)
  {
    HAL_GPIO_TogglePin(ERR_LED_GPIO_Port, ERR_LED_Pin);
    HAL_Delay(100);
  }
  NVIC_SystemReset();
}

const char boot_message[] = "USB4VC Protocol Board\nIBM PC Compatible\ndekuNukem 2022";

void protocol_status_lookup_init(void)
{
  memset(protocol_status_lookup, PROTOCOL_STATUS_NOT_AVAILABLE, PROTOCOL_LOOKUP_SIZE);
  protocol_status_lookup[PROTOCOL_AT_PS2_KB] = PROTOCOL_STATUS_ENABLED;
  protocol_status_lookup[PROTOCOL_XT_KB] = PROTOCOL_STATUS_DISABLED;
  protocol_status_lookup[PROTOCOL_PS2_MOUSE] = PROTOCOL_STATUS_ENABLED;
  protocol_status_lookup[PROTOCOL_MICROSOFT_SERIAL_MOUSE] = PROTOCOL_STATUS_DISABLED;
  protocol_status_lookup[PROTOCOL_MOUSESYSTEMS_SERIAL_MOUSE] = PROTOCOL_STATUS_DISABLED;
  protocol_status_lookup[PROTOCOL_GENERIC_GAMEPORT_GAMEPAD] = PROTOCOL_STATUS_ENABLED;
}

void gamepad_update(void)
{
  gamepad_event* this_gamepad_event = gamepad_buf_peek(&my_gamepad_buf);
  if(this_gamepad_event != NULL)
  {
    // printf("%d %d %d %d %d %d %d %d\n---\n", this_gamepad_event->button_1, this_gamepad_event->button_2, this_gamepad_event->button_3, this_gamepad_event->button_4, this_gamepad_event->axis_x, this_gamepad_event->axis_y, this_gamepad_event->axis_rx, this_gamepad_event->axis_ry);
    /*
    X1 = Wiper 3
    Y1 = Wiper 0
    X2 = Wiper 2
    Y2 = Wiper 1
    */
    HAL_GPIO_WritePin(GAMEPAD_B1_GPIO_Port, GAMEPAD_B1_Pin, !(this_gamepad_event->button_1));
    HAL_GPIO_WritePin(GAMEPAD_B2_GPIO_Port, GAMEPAD_B2_Pin, !(this_gamepad_event->button_2));
    HAL_GPIO_WritePin(GAMEPAD_B3_GPIO_Port, GAMEPAD_B3_Pin, !(this_gamepad_event->button_3));
    HAL_GPIO_WritePin(GAMEPAD_B4_GPIO_Port, GAMEPAD_B4_Pin, !(this_gamepad_event->button_4));
    mcp4451_write_wiper(3, 255-this_gamepad_event->axis_x);
    mcp4451_write_wiper(0, 255-this_gamepad_event->axis_y);
    mcp4451_write_wiper(2, 255-this_gamepad_event->axis_rx);
    mcp4451_write_wiper(1, 255-this_gamepad_event->axis_ry);
    gamepad_buf_pop(&my_gamepad_buf);
  }
}

void xtkb_update(void)
{
  xtkb_check_for_softreset();
  if(kb_buf_peek(&my_kb_buf, &buffered_code, &buffered_value) == 0)
  {
    if(xtkb_press_key(buffered_code, buffered_value) == XTKB_ERROR_HOST_INHIBIT)
      HAL_Delay(1);
    else
      kb_buf_pop(&my_kb_buf);
  }
}

/*
!!!!!!!!!!!!!!!!!!!!!! AFTER CODE RE-GENERATION
!!!!!!!!!!!!!!!!!!!!!! CHANGE THE FOLLOWING

huart3.Init.BaudRate = 1200;
if(flash_size != 64)
  huart3.Init.BaudRate = 2032;

huart1.Init.BaudRate = 115200;
if(flash_size != 64)
  huart1.Init.BaudRate = 195134;

huart3.Init.WordLength = UART_WORDLENGTH_7B;

!!!!!!!!!!!!!!!!!!!!!!
*/

void mousesystems_serial_mouse_update(void)
{
  if(mouse_buf_peek(&my_mouse_buf) == NULL)
    return;

  if(serial_mouse_is_tx_in_progress)
    return;

  get_consolidated_mouse_event(&my_mouse_buf, &consolidated_mouse_event);
  // mouse buffer now empty

  memset(mousesystems_serial_mouse_output_buf, 0, MOUSESYSTEMS_SERIAL_MOUSE_BUF_SIZE);
  mousesystems_serial_mouse_output_buf[0] = 0x87;
  if(consolidated_mouse_event.button_left)
    mousesystems_serial_mouse_output_buf[0] &= 0xfb;
  if(consolidated_mouse_event.button_middle)
    mousesystems_serial_mouse_output_buf[0] &= 0xfd;
  if(consolidated_mouse_event.button_right)
    mousesystems_serial_mouse_output_buf[0] &= 0xfe;
  mousesystems_serial_mouse_output_buf[1] = (int8_t)(consolidated_mouse_event.movement_x);
  mousesystems_serial_mouse_output_buf[2] = (int8_t)(consolidated_mouse_event.movement_y);
  mousesystems_serial_mouse_output_buf[3] = 0;
  mousesystems_serial_mouse_output_buf[4] = 0;
  mouse_buf_pop(&my_mouse_buf);
  HAL_UART_Transmit_IT(&huart3, mousesystems_serial_mouse_output_buf, MOUSESYSTEMS_SERIAL_MOUSE_BUF_SIZE);
  serial_mouse_is_tx_in_progress = 1;
}

/* USER CODE END 0 */
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
int main(void)
{
  /* USER CODE BEGIN 1 */
  flash_size = *(uint16_t*)0x1FFFF7CC;
  /* USER CODE END 1 */

  /* MCU Configuration----------------------------------------------------------*/

  /* Reset of all peripherals, Initializes the Flash interface and the Systick. */
  HAL_Init();

  /* Configure the system clock */
  SystemClock_Config();

  /* Initialize all configured peripherals */
  MX_GPIO_Init();
  MX_I2C2_Init();
  MX_SPI1_Init();
  MX_TIM2_Init();
  MX_USART1_UART_Init();
  MX_USART3_UART_Init();
  MX_IWDG_Init();
  /* USER CODE BEGIN 2 */
  HAL_IWDG_Refresh(&hiwdg);
  printf("%s\nrev%d v%d.%d.%d\n", boot_message, hw_revision, version_major, version_minor, version_patch);
  delay_us_init(&htim2);
  protocol_status_lookup_init();

  ps2kb_init(PS2KB_CLK_GPIO_Port, PS2KB_CLK_Pin, PS2KB_DATA_GPIO_Port, PS2KB_DATA_Pin);
  xtkb_init(PS2KB_CLK_GPIO_Port, PS2KB_CLK_Pin, PS2KB_DATA_GPIO_Port, PS2KB_DATA_Pin);
  ps2mouse_init(PS2MOUSE_CLK_GPIO_Port, PS2MOUSE_CLK_Pin, PS2MOUSE_DATA_GPIO_Port, PS2MOUSE_DATA_Pin);
  
  if(is_protocol_enabled(PROTOCOL_XT_KB))
    xtkb_enable();

  kb_buf_init(&my_kb_buf);
  mouse_buf_init(&my_mouse_buf);
  gamepad_buf_init(&my_gamepad_buf);

  mcp4451_reset();

  memset(spi_transmit_buf, 0, SPI_BUF_SIZE);
  HAL_SPI_TransmitReceive_IT(&hspi1, spi_transmit_buf, spi_recv_buf, SPI_BUF_SIZE);
  /* USER CODE END 2 */

  /* Infinite loop */
  /* USER CODE BEGIN WHILE */
  printf("flash_size: %d\n", flash_size);

  if(!mcp4451_is_available())
  {
    printf("Digital pot not responding!\n");
    for (int i = 0; i < 10; ++i)
    {
      HAL_GPIO_TogglePin(ERR_LED_GPIO_Port, ERR_LED_Pin);
      HAL_Delay(50);
    }
    HAL_GPIO_WritePin(ERR_LED_GPIO_Port, ERR_LED_Pin, GPIO_PIN_SET);
  }

  while (1)
  {
    HAL_IWDG_Refresh(&hiwdg);
    if(micros() > ACT_LED_off_ts)
      HAL_GPIO_WritePin(ACT_LED_GPIO_Port, ACT_LED_Pin, GPIO_PIN_RESET);
  /* USER CODE END WHILE */

  /* USER CODE BEGIN 3 */

    // If more than one enabled, PS2 mouse takes priority
    if(is_protocol_enabled(PROTOCOL_PS2_MOUSE) && IS_PS2MOUSE_PRESENT())
      ps2mouse_update();
    else if(is_protocol_enabled(PROTOCOL_MICROSOFT_SERIAL_MOUSE))
      microsoft_serial_mouse_update();
    else if(is_protocol_enabled(PROTOCOL_MOUSESYSTEMS_SERIAL_MOUSE))
      mousesystems_serial_mouse_update();
    // If both enabled, PS2 keyboard takes priority
    if(is_protocol_enabled(PROTOCOL_AT_PS2_KB) && IS_KB_PRESENT())
    {
      if(ps2kb_update())
        PCARD_BUSY_LOW();
    }
    else if(is_protocol_enabled(PROTOCOL_XT_KB) && IS_KB_PRESENT())
      xtkb_update();

    if(is_protocol_enabled(PROTOCOL_GENERIC_GAMEPORT_GAMEPAD))
      gamepad_update();

    if(spi_error_occured)
      spi_error_dump_reboot();
  }
  /* USER CODE END 3 */

}

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


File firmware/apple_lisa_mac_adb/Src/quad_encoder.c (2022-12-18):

#include <stdio.h>
#include <string.h>
#include <stdlib.h>
#include "quad_encoder.h"
#include "shared.h"
#include "helpers.h"

quad_output quad_x;
quad_output quad_y;

TIM_HandleTypeDef* avg_timer;
TIM_HandleTypeDef* arr_timer_x;
TIM_HandleTypeDef* arr_timer_y;

mouse_buf* mouse_buffer;

uint8_t quad_mouse_is_enabled;

#define ARR_LOOKUP_SIZE 64
const uint16_t arr_lookup[ARR_LOOKUP_SIZE] = {12217, 10241, 8829, 7700, 6758, 5958, 5347, 4782, 4311, 3888, 3558, 3276, 3041, 2852, 2711, 2570, 2429, 2335, 2241, 2147, 2052, 1958, 1911, 1817, 1770, 1723, 1629, 1582, 1535, 1488, 1441, 1394, 1347, 1300, 1252, 1205, 1158, 1158, 1111, 1064, 1017, 1017, 970, 923, 923, 876, 876, 829, 829, 782, 782, 735, 735, 688, 688, 641, 641, 641, 594, 594, 594, 547, 547, 547};
const uint8_t grey_code_lookup[4] = {0, 1, 3, 2};

/*
  instead of all at once, we remove data from buffer
  at a regular interval, say 5ms, if empty, then theres no movement
  then every 50ms for example the average movement is calculated
  and that is used to update quad encoder?
*/
void avg_buf_add(quad_output* qo, int16_t value)
{
  qo->avg_buf[qo->avg_buf_index] = value;
  qo->avg_buf_index++;
  if(qo->avg_buf_index >= AVG_BUF_SIZE)
    qo->avg_buf_index = 0;
}

int32_t get_buf_avg(quad_output* qo)
{
  int32_t sum = 0;
  for (int i = 0; i < AVG_BUF_SIZE; ++i)
    sum += qo->avg_buf[i];
  // if (sum > 0 && sum < AVG_BUF_SIZE)
  //   sum = AVG_BUF_SIZE;
  // else if (sum < 0 && abs(sum) < AVG_BUF_SIZE)
  //   sum = AVG_BUF_SIZE * -1;
  return (int32_t)(sum/AVG_BUF_SIZE);
}

/*
each speed has a corresponding duration before the next increment or decrement

make sure to enable autoreload preload to prevent glitches

ARR = Auto Reload Register
value = us
*/

uint16_t calc_arr(int32_t speed_val)
{
  speed_val = abs(speed_val);
  if(speed_val <= 0 || speed_val >= ARR_LOOKUP_SIZE)
    return 500;
  return arr_lookup[speed_val];
}

void quad_write(quad_output *qo)
{
  uint8_t current_code = grey_code_lookup[qo->gray_code_index];
  if(current_code & 0x1)
    HAL_GPIO_WritePin(qo->A_port, qo->A_pin, GPIO_PIN_SET);
  else
    HAL_GPIO_WritePin(qo->A_port, qo->A_pin, GPIO_PIN_RESET);
  if(current_code & 0x2)
    HAL_GPIO_WritePin(qo->B_port, qo->B_pin, GPIO_PIN_SET);
  else
    HAL_GPIO_WritePin(qo->B_port, qo->B_pin, GPIO_PIN_RESET);
}

void quad_reset(quad_output *qo)
{
  qo->gray_code_index = 0;
  qo->avg_buf_index = 0;
  qo->avg_speed = 0;
  memset(qo->avg_buf, 0, AVG_BUF_SIZE);
  quad_write(qo);
}

void quad_init(mouse_buf* mbuf, TIM_HandleTypeDef* avg_tim, TIM_HandleTypeDef* arr_tim_x, TIM_HandleTypeDef* arr_tim_y, GPIO_TypeDef* x1_port, uint16_t x1_pin, GPIO_TypeDef* x2_port, uint16_t x2_pin, GPIO_TypeDef* y1_port, uint16_t y1_pin, GPIO_TypeDef* y2_port, uint16_t y2_pin)
{
  quad_x.A_port = x1_port;
  quad_x.A_pin = x1_pin;
  quad_x.B_port = x2_port;
  quad_x.B_pin = x2_pin;

  quad_y.A_port = y1_port;
  quad_y.A_pin = y1_pin;
  quad_y.B_port = y2_port;
  quad_y.B_pin = y2_pin;

  avg_timer = avg_tim;
  arr_timer_x = arr_tim_x;
  arr_timer_y = arr_tim_y;
  mouse_buffer = mbuf;
  quad_reset(&quad_x);
  quad_reset(&quad_y);
  HAL_TIM_Base_Start_IT(avg_timer);
  HAL_TIM_Base_Start_IT(arr_timer_x);
  HAL_TIM_Base_Start_IT(arr_timer_y);
}

void quad_increment(quad_output *qo)
{
  qo->gray_code_index = (uint8_t)(qo->gray_code_index + 1) % 4;
  quad_write(qo);
}

void quad_decrement(quad_output *qo)
{
  qo->gray_code_index = (uint8_t)(qo->gray_code_index - 1) % 4;
  quad_write(qo);
}

void quad_enable(void)
{
  quad_reset(&quad_x);
  quad_reset(&quad_y);
  quad_mouse_is_enabled = 1;
}

void quad_disable(void)
{
  quad_mouse_is_enabled = 0;
  HAL_GPIO_WritePin(quad_x.A_port, quad_x.A_pin, GPIO_PIN_SET);
  HAL_GPIO_WritePin(quad_x.B_port, quad_x.B_pin, GPIO_PIN_SET);
  HAL_GPIO_WritePin(quad_y.A_port, quad_y.A_pin, GPIO_PIN_SET);
  HAL_GPIO_WritePin(quad_y.B_port, quad_y.B_pin, GPIO_PIN_SET);
  HAL_GPIO_WritePin(GPIOB, GPIO_PIN_13, GPIO_PIN_SET);
}

/*
  this gets called every 10ms, fetches mouse event and put them into a running buffer
  a window average is calculated, used to adjust the timer autoreload register
*/

void HAL_TIM_PeriodElapsedCallback(TIM_HandleTypeDef *htim)
{
  uint8_t cme_count;
  if(quad_mouse_is_enabled == 0)
    return;
  // every 10ms
  if(htim == avg_timer)
  {
    cme_count = get_consolidated_mouse_event(mouse_buffer, &consolidated_mouse_event);
    // mouse buffer now empty

    avg_buf_add(&quad_x, consolidated_mouse_event.movement_x);
    avg_buf_add(&quad_y, consolidated_mouse_event.movement_y);

    quad_x.avg_speed = get_buf_avg(&quad_x);
    quad_y.avg_speed = get_buf_avg(&quad_y);
    arr_timer_x->Instance->ARR = calc_arr(quad_x.avg_speed);
    arr_timer_y->Instance->ARR = calc_arr(quad_y.avg_speed);

    if(cme_count != 0)
    {
      if(consolidated_mouse_event.button_left || consolidated_mouse_event.button_right)
        HAL_GPIO_WritePin(GPIOB, GPIO_PIN_13, GPIO_PIN_RESET);
      else
        HAL_GPIO_WritePin(GPIOB, GPIO_PIN_13, GPIO_PIN_SET);
    }
  }
  // every ARR overflow
  if(htim == arr_timer_x && quad_x.avg_speed != 0)
  {
    if(quad_x.avg_speed > 0)
      quad_increment(&quad_x);
    else
      quad_decrement(&quad_x);
  }
  if(htim == arr_timer_y && quad_y.avg_speed != 0)
  {
    if(quad_y.avg_speed > 0)
      quad_increment(&quad_y);
    else
      quad_decrement(&quad_y);
  }
}

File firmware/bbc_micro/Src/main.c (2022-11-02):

/**
  ******************************************************************************
  * @file           : main.c
  * @brief          : Main program body
  ******************************************************************************
  ** This notice applies to any and all portions of this file
  * that are not between comment pairs USER CODE BEGIN and
  * USER CODE END. Other portions of this file, whether 
  * inserted by the user or by software development tools
  * are owned by their respective copyright owners.
  *
  * COPYRIGHT(c) 2022 STMicroelectronics
  *
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
  ******************************************************************************
  */
/* Includes ------------------------------------------------------------------*/
#include "main.h"
#include "stm32f0xx_hal.h"

/* USER CODE BEGIN Includes */
#include "delay_us.h"
#include "shared.h"
#include "helpers.h"
#include <string.h>

/* USER CODE END Includes */

ADC_HandleTypeDef hadc;

DAC_HandleTypeDef hdac;

SPI_HandleTypeDef hspi1;

TIM_HandleTypeDef htim2;

UART_HandleTypeDef huart1;

/* USER CODE BEGIN PV */
const uint8_t board_id = 4;
const uint8_t version_major = 0;
const uint8_t version_minor = 0;
const uint8_t version_patch = 1;
const char boot_message[] = "USB4VC Protocol Board\nBBC Micro/Master\ndekuNukem 2022";

uint8_t spi_transmit_buf[SPI_BUF_SIZE];
uint8_t backup_spi1_recv_buf[SPI_BUF_SIZE];
uint8_t spi_recv_buf[SPI_BUF_SIZE];
kb_buf my_kb_buf;
mouse_buf my_mouse_buf;
gamepad_buf my_gamepad_buf;
uint8_t spi_error_occured;
uint8_t buffered_code, buffered_value;
gamepad_event latest_gamepad_event;

/* USER CODE END PV */

void SystemClock_Config(void);
static void MX_GPIO_Init(void);
static void MX_SPI1_Init(void);
static void MX_TIM2_Init(void);
static void MX_DAC_Init(void);
static void MX_ADC_Init(void);
static void MX_USART1_UART_Init(void);

/* USER CODE BEGIN PFP */

/* USER CODE END PFP */

/* USER CODE BEGIN 0 */

uint32_t act_led_timestamp;

#define PROTOCOL_STATUS_NOT_AVAILABLE 0
#define PROTOCOL_STATUS_ENABLED 1
#define PROTOCOL_STATUS_DISABLED 2

#define PROTOCOL_LOOKUP_SIZE 16
uint8_t protocol_status_lookup[PROTOCOL_LOOKUP_SIZE];

uint8_t is_protocol_enabled(uint8_t this_protocol)
{
  if(this_protocol >= PROTOCOL_LOOKUP_SIZE)
    return 0;
  return protocol_status_lookup[this_protocol] == PROTOCOL_STATUS_ENABLED;
}

void protocol_status_lookup_init(void)
{
  memset(protocol_status_lookup, PROTOCOL_STATUS_NOT_AVAILABLE, PROTOCOL_LOOKUP_SIZE);
  protocol_status_lookup[PROTOCOL_BBC_MICRO_KB_ISO] = PROTOCOL_STATUS_ENABLED;
  protocol_status_lookup[PROTOCOL_BBC_MICRO_KB_ANSI] = PROTOCOL_STATUS_DISABLED;
  protocol_status_lookup[PROTOCOL_BBC_MICRO_JOYSTICK] = PROTOCOL_STATUS_ENABLED;
}

#define BBC_JOYSTICK_CALIBRATION_VALUE 280

void joystick_reset(void)
{
  HAL_GPIO_WritePin(JS_PB0_GPIO_Port, JS_PB0_Pin, GPIO_PIN_SET);
  HAL_DAC_SetValue(&hdac, DAC_CHANNEL_1, DAC_ALIGN_12B_R, 1130);
  HAL_DAC_SetValue(&hdac, DAC_CHANNEL_2, DAC_ALIGN_12B_R, 1130);
}

void handle_protocol_switch(uint8_t spi_byte)
{
  uint8_t index = spi_byte & 0x7f;
  uint8_t onoff = spi_byte & 0x80;

  if(index >= PROTOCOL_LOOKUP_SIZE)
    return;
  // trying to change a protocol that is not available on this board
  if(protocol_status_lookup[index] == PROTOCOL_STATUS_NOT_AVAILABLE)
    return;
  // switching protocol ON
  if(onoff && protocol_status_lookup[index] == PROTOCOL_STATUS_DISABLED)
  {
    switch(index)
    {
      case PROTOCOL_BBC_MICRO_KB_ANSI:
        protocol_status_lookup[PROTOCOL_BBC_MICRO_KB_ISO] = PROTOCOL_STATUS_DISABLED;
        break;

      case PROTOCOL_BBC_MICRO_KB_ISO:
        protocol_status_lookup[PROTOCOL_BBC_MICRO_KB_ANSI] = PROTOCOL_STATUS_DISABLED;
        break;
    }
    protocol_status_lookup[index] = PROTOCOL_STATUS_ENABLED;
  }
  // switching protocol OFF
  else if((onoff == 0) && protocol_status_lookup[index] == PROTOCOL_STATUS_ENABLED)
  {
    protocol_status_lookup[index] = PROTOCOL_STATUS_DISABLED;
    if(index == PROTOCOL_BBC_MICRO_JOYSTICK)
      joystick_reset();
  }
}
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

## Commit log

2021-10-06 added mockup pcb layout
    [u2x.brd, u2x.sch]
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2021-10-24 changing interrupt priority seemed to have fixed it
    [helpers.h, main.c, ps2kb.c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]
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2021-10-26 spi glitch seemling fixed, switched to IT instead of DMA, added out of sync recovery
    [main.c, scrap.c]
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2021-10-28 f042 send working, host request not working for some reason
    [main.c, scrap.c]
2021-10-30 fixed mouse support on python, collects events and send them out on SYNC
    [ps2mouse.c, temp.py]
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2021-10-31 started working on pcb
    [u2x.brd, u2x.sch]
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2021-11-04 added more resources, worked on PCB, new libraries, placement, USB chip selection, OLED libarary
    [Adafruit OLED 128x32 Mono I2C STEMMA QT rev B.brd, Adafruit OLED 128x32 Mono I2C STEMMA QT rev B.sch, Adafruit OLED 128x32 Mono I2C.brd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]
2021-11-04 added ch340, working on power
    [Serial-Basic-CH340C-and-USBC.brd, Serial-Basic-CH340C-and-USBC.sch, u2x.brd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]
2021-11-04 switched to sparkfuns usbc
    [u2x.brd, u2x.sch]
2021-11-04 connecting power, sd card, and crystal
    [u2x.brd, u2x.sch]
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2021-11-05 main chip traces done
    [u2x.brd]
2021-11-05 hooked up ch340, fine tuned traces
    [u2x.brd, u2x.sch]
2021-11-06 wired up spi oled
    [u2x.brd, u2x.sch]
2021-11-06 added debug headers and pullup on OLED reset
    [u2x.brd, u2x.sch]
2021-11-06 hooked up usb hub chip
    [u2x.brd, u2x.sch]
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2021-11-06 added power LED, adjust usb trace width
    [u2x.brd, u2x.sch]
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2021-11-06 started working on ps2 board
    [ps2.brd, ps2.sch]
2021-11-07 ps2 board done apart from max232
    [ps2.brd, ps2.sch]
2021-11-08 ps2 board prototype done
    [MAX3232_Breakout_v11.brd, MAX3232_Breakout_v11.sch, ps2.brd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]
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2021-11-08 double checked and adjusted resistor and cap values
    [ps2.brd, ps2.sch, u2x.brd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]
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2021-11-11 working on a prototype shield
    [Adafruit proto pi plate.brd, Adafruit proto pi plate.sch, proto.brd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]
2021-11-14 fixed header orientation on ps2 board
    [ps2.brd, ps2.sch]
2021-11-16 trying to fix a read buy
    [main.c, scrap.c]
2021-11-17 started working on collision detection
    [adb.c, scrap.c]
2021-11-17 working on collision detection, address negotiation seems to be working
    [adb.c]
2021-11-24 minor changes to PCB
    [u2x.brd, u2x.sch]
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2021-11-27 working on rpi carrier board
    [rpi.brd, rpi.sch, u2x.brd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]
2021-11-27 rpi carrier board finished
    [rpi.brd, rpi.sch]
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2021-11-27 serial mouse write working
    [ps2.brd, ps2.sch]
2021-11-29 updated baseboard, added power buttons
    [rpi.brd, rpi.sch]
2021-11-29 working on new IBMPC pboard
    [ibmpc.brd, ibmpc.sch]
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2021-11-30 working on IBM PC p board
    [ibmpc.brd, ibmpc.sch]
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2021-12-01 added i2c pullups, cleanup
    [ibmpc.brd, ibmpc.sch, rpi.brd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]
2021-12-01 finished ADB protocol board
    [adb.brd, adb.sch, ibmpc.brd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]
2021-12-01 added dsub stacker board
    [ibmpc.brd, ibmpc.sch, stacker.brd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]
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2021-12-01 did i wire the gameport backwards?
    [stacker.brd]
2021-12-01 finishing touches for new boards
    [adb.brd, ibmpc.brd, ibmpc.sch]
2021-12-02 updated usb breakout board
    [usb_breakout.brd, usb_breakout.sch]
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2021-12-03 cleaned up repo, trying out RPI interrupt
    [baseboard.brd, baseboard.sch]
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2021-12-12 fixed a ps2 timing issue
    [main.c, ps2mouse.c]
2021-12-12 fixed a ps2 timing issue, cleaned up code
    [ps2mouse.c]
2021-12-12 serial mouse working, cleaned up code, fixed a bug
    [main.c, scrap.c]
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2021-12-17 gamepad implemented on ibm board, analoge axes doesnt seem to be working correctly
    [ibmpc.brd, ibmpc.sch]
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2021-12-27 aded top plate and diamensions
    [stacker.brd, stacker.sch, usb_breakout.brd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]
2021-12-27 added standoff information, updated silkscreen for next prototype
    [baseboard.brd]
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2021-12-30 updated pairing function, seems to be working with PIN-less devices now
    [baseboard.brd]
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2022-01-01 added back ADB PT1
    [adb.brd, adb.sch]
2022-01-01 porting ADB code to new board
    [adb.brd, adb.sch]
2022-01-01 fixed flipped ADB connector footprint
    [adb.brd, adb.sch]
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2022-01-02 fixed ADB interrupt timing, mouse working
    [adb.c, main.c, scrap.c]
2022-01-02 keyboard sort of working, need to fix timing
    [adb.c, helpers.h, main.c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]
2022-01-02 fixed adb mouse range issue
    [main.c, scrap.c]
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2022-01-02 still some interrupt timing issue
    [main.c]
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2022-01-03 added kb reg2 read and write, fixed srq glitch
    [adb.c, main.c]
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2022-01-04 implemented capslock key behavior, fixed keyboard register 2 bit plority
    [adb.c, main.c]
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2022-01-06 updated PCB for second prototype run
    [adb.brd, adb.sch, baseboard.brd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]
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2022-01-08 fixed pcard spi interrupt bug
    [helpers.h, main.c, ps2kb.c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]
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2022-01-08 added notes about fixing gpu freq for stable UART baud rate
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2022-01-08 added sleep LED on baseboard
    [baseboard.brd, baseboard.sch]
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2022-02-02 added default deadzone, fixed UI responsiveness issue
    [xt_kb.c]
2022-02-03 fixed serial mouse glitch
    [main.c, scrap.c]
2022-02-05 fixed firmware update bug, fixed ertm disable bug, handle input scan exceptions, added xbox controller driver note
    [usb4vc_main.py]
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2022-02-15 fixed a ps/2 mouse bug for timing out too soon
    [main.c, ps2mouse.c]
2022-02-17 added OG mac keyboard breakout
    [mackb_breakout.brd, mackb_breakout.sch]
2022-02-17 started working on OG macintosh protocol
    [apple_all.brd, apple_all.sch]
2022-02-17 started quad encoder test
    [apple_all.brd, apple_all.sch]
2022-02-23 updated pcb silkscreens for first production run
    [adb.brd, baseboard.brd, ibmpc.brd]
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2022-03-18 fixed switch pro controller button not holding down, added compatibility matrix, updated doc
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2022-03-25 fixed wifi info update
    [usb4vc_main.py]
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2022-04-20 working on testing board
    [apple_all.brd, apple_all.sch]
2022-04-25 forgot what i did
    [apple_all.brd, apple_all.sch]
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2022-05-01 added missing ps/2 keyboard commands, added ps/2 keyboard host inhibit handling
    [main.c, ps2kb.c, scrap.c]
2022-05-02 fixing ps2 mouse inhibit bug
    [helpers.h, main.c, ps2mouse.c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]
2022-05-02 ps2 mouse inhibit bug seems to be fixed, still more to do
    [main.c, ps2mouse.c, scrap.c]
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2022-05-04 fixed a ps2kb scancode set reply bug
    [ps2kb.c]
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2022-05-10 fixed PS5 controller default mapping
    [temp.py]
2022-05-10 fixed more ps5 controller mapping
    [temp.py]
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2022-05-12 fixed ps/2 mouse line idle detection bug
    [main.c, ps2kb.c]
2022-05-19 fixed a bug in IBM PC card where turning off gameport gamepad will cause a crash
    [main.c, mcp4451.c]
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2022-05-21 Fix spamming debug log for PIs w/o bluetooth
    [usb4vc_main.py]
2022-06-23 new firmware, fixed XT keyboard mapping and better serial mouse RTS handlign
    [main.c, xt_kb.c]
2022-06-26 m0100a outbuf write seems to work, need more error handling
    [main.c]
2022-06-30 apple_all p-card prototype #2
    [TRS_Jack_Breakout.brd, TRS_Jack_Breakout.sch, apple_all_pt1.brd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]
2022-07-04 added mac mouse power detect
    [apple_all_pt3.brd, apple_all_pt3.sch]
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2022-07-22 setting up code for new board revision
    [apple_all_pt3.brd]
2022-07-22 testing firmware on new board
    [apple_all_pt3.brd]
2022-08-02 added mouse event consolidation to m0100 mouse, fixed buttons, tested working
    [helpers.h, main.c, quad_encoder.c]
2022-08-04 working on bbc micro
    [bbc_micro.brd, bbc_micro.sch]
2022-08-05 working on bbc micro PCB
    [bbc_micro.brd, bbc_micro.sch]
2022-08-05 almost done with pcb
    [bbc_micro.brd, bbc_micro.sch]
2022-08-05 hooked up digital pot and leds
    [bbc_micro.brd, bbc_micro.sch]
2022-08-06 bbc micro protocol board test board
    [bbc_micro.brd, bbc_micro.sch]
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2022-08-18 keyboard matrix mostly complete but has multiple key scan bug
    [main.c]
2022-08-18 before fixing missing input bug
    [main.c, scrap.c]
2022-08-18 keyboard done, turns out it skips input on real keyboard too
    [main.c, scrap.c]
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2022-09-05 changed to using built-in DAC
    [bbc_micro.brd, bbc_micro.sch]
2022-09-12 improved debug pin speed, removed i2c digital pot
    [bbc_micro.sch]
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2022-09-13 think i found the issue
    [helpers.h, main.c]
2022-09-13 missing input seem fixed
    [main.c]
2022-09-13 bodged a shift fix
    [main.c, scrap.c]
2022-09-13 added reset, still need some work
    [bbc.ioc, main.c]
2022-09-14 fixed unmapped keys parsing
    [main.c]
2022-09-15 fixed floating VDDA
    [bbc_micro.brd, bbc_micro.sch]
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2022-09-17 removed second joystick and added BBC VREF input
    [bbc_micro.brd, bbc_micro.sch]
2022-09-18 fixed a few minor bugs
    [helpers.h, main.c, scrap.c]
2022-09-27 added a pot, clean up
    [bbc_micro.brd, bbc_micro.sch]
2022-11-03 added sirius 1 pcard prototype
    [SparkFun_RJ45 Breakout v11.brd, SparkFun_RJ45 Breakout v11.sch, sirius1.brd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]
2022-11-10 updated sirius 1 pcb
    [sirius1.brd, sirius1.sch]
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2022-12-14 added TRS-80 Model II keyboard connector
    [SparkFun_RJ45 Breakout v11.brd, SparkFun_RJ45 Breakout v11.sch, sirius1.brd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]
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2023-03-03 mostly fixed interrupt conflict
    [helpers.h, main.c]
2023-03-04 m0110 keyboard working, added busy signal and protocol switching
    [apple_all_pt3.brd, apple_all_pt3.sch]
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2023-03-07 added resistors on DET pins, cleaned up silkscreen
    [apple_all_pd1.brd, apple_all_pd1.sch]
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2023-03-07 added BUSY signal to PS2 kb and mouse, temp mouse workaround on rpi
    [main.c, ps2mouse.c]
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2023-05-01 fixed a minor baud rate bug
    [main.c]
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

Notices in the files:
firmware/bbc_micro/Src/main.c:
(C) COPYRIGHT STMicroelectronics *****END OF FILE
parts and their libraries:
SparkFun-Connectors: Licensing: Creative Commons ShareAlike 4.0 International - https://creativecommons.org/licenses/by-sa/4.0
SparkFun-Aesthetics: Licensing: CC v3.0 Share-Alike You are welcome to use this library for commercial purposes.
